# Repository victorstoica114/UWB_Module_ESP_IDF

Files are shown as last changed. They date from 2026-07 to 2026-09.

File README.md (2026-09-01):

# UWB ESP-IDF

ESP-IDF 6.0.2 firmware for the custom UWB Module V1.0 Rev.B, based on an
ESP32-S3-WROOM-1-N16R8. The same application image runs on every module;
persistent identity and runtime configuration select the role and active
workflow on each board.

The current firmware combines DW3000 positioning, PX1105R GNSS/RTK, BNO085
IMU telemetry, BQ25792 charging, MAX77958 USB-C Power Delivery, authenticated
HTTP OTA/configuration, a browser dashboard, and boot-loop/OTA recovery. The
UWB radio runtimes include Native DS-TWR, FlexTDOA, Passive DS-TWR, calibration,
survey, distance-test, and beacon diagnostics.

Current firmware defaults, before an NVS override is loaded:

| Setting | Default |
| --- | --- |
| Runtime | `uwb_ranging` (Native DS-TWR) |
| UWB | enabled |
| BNO085 | disabled; `2 ms` / 500 Hz requested when enabled |
| PX1105R GNSS | disabled |
| BQ25792 monitor | enabled, nominal 1 Hz refresh |
| MAX77958 monitor | enabled, nominal 1 Hz refresh |
| Wi-Fi logs / binary telemetry | enabled |
| Storage | 16 MB flash, dual 4 MB OTA slots, 8 MB octal PSRAM |

Wi-Fi credentials, the OTA token, and optional NTRIP credentials are read from
the Git-ignored `secrets.h`. Copy `secrets.example.h` as the starting template.
Non-secret defaults live in `components/config`; authenticated runtime
overrides are stored in ESP32 NVS.

## Documentation Map

- Hardware, firmware ownership, boot order, and tasks are documented below in
  [Hardware](#hardware) and [Firmware Architecture](#firmware-architecture).
- UWB modes and packet/timing details start at [App Modes](#app-modes) and
  [UWB Ranging Protocol](#uwb-ranging-protocol). Passive DS-TWR and the clean
  FlexTDOA implementation also have dedicated notes in
  [`docs/PASSIVE_DS_TWR.md`](docs/PASSIVE_DS_TWR.md) and
  [`docs/FLEXTDOA_CLEAN_REIMPLEMENTATION.md`](docs/FLEXTDOA_CLEAN_REIMPLEMENTATION.md).
- Operator controls are grouped under [HTTP Control Surface](#http-control-surface),
  [BNO085 IMU](#bno085-imu), [BQ25792 Battery Charger](#bq25792-battery-charger),
  and [MAX77958 USB-C PD Controller](#max77958-usb-c-pd-controller).
- Build, serial flash, OTA, dashboard, and host-test commands are under
  [Local Workflow, Flashing, and VS Code Tasks](#local-workflow-flashing-and-vs-code-tasks).
- Released ESP32 images are on the
  [GitHub Releases page](https://github.com/victorstoica114/UWB_Module_ESP_IDF/releases),
  while the separately versioned GNSS image is indexed in
  [`PX1105R-firmware/README.md`](PX1105R-firmware/README.md).
- Final reports and their retained evidence bundles are indexed in
  [`reports/README.md`](reports/README.md).
- The parametric enclosure sources, print-ready STL files, STEP exports, and
  assembly notes are under
  [`mechanical/uwb-gps-enclosure/`](mechanical/uwb-gps-enclosure/README.md).

## Hardware

This firmware targets the custom UWB Module V1.0 Rev.B hardware.

| Area | Details |
| --- | --- |
| MCU | ESP32-S3-WROOM-1-N16R8 |
| Flash / PSRAM | 16 MB flash, 8 MB PSRAM |
| USB | Native USB CDC on boot |
| UWB | DW3000/DWM3000 radio path |
| IMU | BNO085 over shared I2C |
| GPS | PX1105R/PX1125R-class GPS path |
| USB-C / PD | MAX77958 |
| Charger | BQ25792 |
| Status LED | GPIO42, active-high |

Active pin mapping lives in `components/config/include/board_config.h`.

| Function | GPIO |
| --- | --- |
| Status LED | `42` |
| Shared I2C SDA / SCL | `9` / `10` |
| BNO085 reset / interrupt | `40` / `15` |
| BQ25792 interrupt / QON command / board PG | `4` / `38` / `5` |
| UWB reset / IRQ / CS / wakeup | `8` / `6` / `48` / `7` |
| SPI MOSI / SCK / MISO | `11` / `12` / `13` |
| GPS enable / RX / TX | `47` / `18` / `17` |
| GNSS correction UART TX | `1` |

### DW3000 SPI Clock

The DWM3000 data sheet specifies a maximum SPI clock of `38 MHz` in mode 0
after OTP boot has completed. ESP32-S3 SPI2 is sourced from the `80 MHz` APB
clock and can generate `40 MHz` exactly. This project deliberately selects
that divider after field validation on all five modules. It is a documented
2 MHz overclock, guarded by an explicit compile-time opt-in and a separate
`38 MHz` data-sheet-limit constant so the exception cannot be accidental.

The driver therefore uses two phases:

1. reset, `DEV_ID` probe, soft reset, OTP reads, and radio configuration at
   `4 MHz`;
2. operational RX/TX traffic requested and realized at `40 MHz`, after eight
   consecutive `DEV_ID` read-backs succeed.

If the operational verification fails, the driver automatically restores the
`4 MHz` device configuration so the module remains reachable. `/status`
exposes the effective value as `uwb_spi_clock_hz`; this is the frequency
reported by the ESP-IDF SPI driver, not only the requested value.

Hardware validation on all five modules, updated 2026-08-05:

| Metric | Result |
| --- | ---: |
| Effective SPI clock, every module | `40 MHz` |
| Pure CI-CR validation window | `35 s` |
| Selected slot / four-anchor frame | `4.80 ms / 19.20 ms` |
| Passive observations | `443-450/s` |
| Telemetry drops | `0` |
| Responder-index balance per anchor | typically `37-39 / 37-39 / 37-39` per second |
| Rejected tag observations | typically `0-1/s` |
| Incoherent anchor timestamps in stable windows | `0` |

The radio test exercises TX-buffer writes, delayed-TX programming, timestamp
and status reads, and RX-buffer reads. It is therefore a stronger link check
than probing `DEV_ID` alone.

## Firmware Architecture

`main/app_main.c` only calls `app_manager_start()`. The application manager
initializes identity and runtime configuration, brings up the recovery/control
plane first, and then starts hardware services and exactly one UWB runtime.

| Component | Responsibility |
| --- | --- |
| `app_manager` | Boot sequencing, status LED, recovery cutoff, and active-runtime selection. |
| `config` | Board pins, compile-time defaults, persistent module identity/antenna delay, and NVS runtime configuration. |
| `boot_guard` | ESP-IDF OTA validation plus RTC-memory crash-loop detection and recovery mode. |
| `wifi_service` | STA scan, connection, reconnect, BSSID/channel diagnostics, and network status. |
| `ota_service` | HTTP server, `/status`, OTA, GNSS update staging, and authenticated configuration endpoints. |
| `wireless_log_service` | TCP mirror of ESP-IDF text logs. |
| `wireless_telemetry_service` | Batched `UWT1` binary sensor, geometry, range, and position streams. |
| `resource_monitor_service` | Bounded RAM, PSRAM, flash, temperature, and per-core CPU diagnostics. |
| `i2c_bus_service` | Shared BNO085 realtime/BQ25792/MAX77958 background arbitration and optional SCL measurement. |
| `bno085_service` | Interrupt-driven accelerometer and GyroRV acquisition, timestamp reconstruction, recovery, rings, and telemetry. |
| `charger_service` | BQ25792 monitoring, decoded status/ADC data, controlled writes, and NVS-backed charger policy. |
| `max77958_service` | MAX77958 status, AP commands, optional direct-HS I2C, PDO/PPS control, and NVS-backed PD policy. |
| `gps_service` | PX1105R power/UART control, NMEA/SkyTraq parsing, 8 Hz setup, moving-base transport, and NTRIP. |
| `gnss_firmware_updater` | Fixed PX1105R loader/image update sequence using ESP32 PSRAM staging. |
| `uwb_dw3000` | DW3000 GPIO/SPI/IRQ ownership and all timing-critical UWB runtime loops. |
| `uwb_ranging_service` | Native DS-TWR positioning entry point. |
| `uwb_distance_test_service` | Two-module five-frame diagnostic DS-TWR entry point. |
| `uwb_calibration_service` | Two- and three-module antenna-delay calibration entry point. |
| `uwb_anchor_survey_service` | Anchor-to-anchor survey entry point. |
| `flextdoa_protocol` | FlexTDOA packet codec, collector, and CFO estimator. |
| `flextdoa_algmin` | FlexTDOA frame aggregation and 2D minimization. |
| `flextdoa_solver_service` | Asynchronous embedded FlexTDOA solver and position publication. |
| `passive_ds_solver_service` | Passive DS batching, dynamic geometry, correlated solve, and position publication. |
| `uwb_mobile_geometry` | Converts GNSS anchor positions into a shared local UWB coordinate frame. |
| `uwb_localization_solver` | Generic tested range/range-difference solver library; it is not the owner of a current runtime loop. |

Repository-level supporting material:

| Path | Contents |
| --- | --- |
| `tools/` | Build/OTA helpers, dashboard, listeners, capture, replay, calibration, and analysis tools. |
| `tests/` | Python host tests and standalone C algorithm/protocol tests. |
| `docs/` | Focused protocol and implementation notes. |
| `firmware_images/` | Retained ESP32 release inputs, stored through Git LFS where configured. |
| `PX1105R-firmware/` | Permanent GNSS firmware index and validated ESP32-assisted update artifacts. |
| `reports/` | Final PDFs plus one self-contained evidence bundle for each report. |
| `mechanical/uwb-gps-enclosure/` | Parametric V4 enclosure source, reference geometry, print-ready STL files, STEP exports, and previews. |
| `PCB/V1.REV.B/` | KiCad source, fabrication, BOM, and placement package. |
| `Schematic/` / `datasheets/` | Exported board schematic and local silicon/reference documents. |
| `reference/` | Migration notes and the intentionally retained legacy GPIO header. |

`components/config/include/board_config.h` is the active board pin map.
Old GPIO naming is kept only under `reference/legacy_headers`.
Old legacy project files and cloned third-party repositories are kept local for
inspiration/debugging and are intentionally ignored by Git.

`components/config/include/app_config.h` holds versioned non-secret application
settings: the default runtime mode, persistent identity provisioning, Wi-Fi
diagnostics/reconnect behavior, wireless-log defaults, OTA-adjacent
service defaults, and optional sensor-test parameters. `components/config/include/uwb_config.h`
holds UWB-only settings: role, source ID override, antenna delay, beacon
smoke-test parameters, and runtime defaults. Runtime overrides are stored in
NVS through `/config/runtime`. Keep Wi-Fi credentials and OTA tokens in
`secrets.h`.

Runtime ownership is intentionally narrow:

- `main/app_main.c` only boots the firmware and calls `app_manager_start()`.
- `components/app_manager/app_manager.c` owns what runs on the board and in
  what order.
- Long-lived workflows live in separate services/components, then are selected
  or sequenced by `app_manager`.

The current boot sequence is also explicit. `app_manager` starts the status LED
and boot guard, loads identity/runtime configuration, then brings up Wi-Fi,
wireless logs, binary telemetry, and the HTTP/OTA server. It schedules stable
boot confirmation only after that recovery/control plane is reachable. A normal
boot then starts the resource monitor, optional GNSS, the selected UWB runtime,
BQ25792, MAX77958, and finally the optional BNO085 service. Recovery mode stops
before that second group and holds the DW3000 in reset.

The application task/core split is kept simple so the UWB loop is isolated from
most Wi-Fi and TCP work:

| Task / service | Core | Notes |
| --- | --- | --- |
| `uwb_dw3000` | 1 | Owns DW3000 init, SPI access, RX/TX, ranging, survey, and calibration loops. |
| `status_led` | 1 | Lightweight GPIO blink task. |
| `boot_guard` | unpinned | Confirms stable boots after Wi-Fi/OTA are online and holds recovery state across resets. |
| `wifi_service` | 0 | Owns Wi-Fi STA connect/reconnect management. |
| `ota_service` / `httpd` | 0 | Starts authenticated OTA, `/status`, and runtime-config HTTP handling. |
| `bno085` | 0 | Interrupt-driven BNO085 accelerometer/GyroRV service; owns realtime priority on the shared I2C bus. |
| `bq25792` | 0 | Low-rate charger monitor; uses background I2C access so BNO085 can win bus arbitration. |
| `max77958` | 0 | Low-rate USB-C PD monitor/config service; also uses background I2C access. |
| `gps` | 0 | PX1105R power, UART parsing, and moving-base integration when runtime-enabled. |
| `gps_ntrip` | unpinned | Optional single NTRIP caster connection owned by the configured module. |
| `flex_algmin` | 0 | FlexTDOA solver worker, created only by that runtime. |
| `passive_ds_solver` | 0 | Passive DS solver worker with its large stack allocated from PSRAM. |
| `resource_monitor` | 0 | Low-priority bounded resource sampling. |
| `wireless_log` | unpinned | Drains the log queue and mirrors logs over TCP; FreeRTOS may run it on either core. |
| `wireless_tel` | 1 | Drains high-rate telemetry into batched TCP writes. |
| short-lived reboot tasks | unpinned | Temporary restart helpers after OTA or runtime-config changes that explicitly require a reboot. |

ESP-IDF also creates internal Wi-Fi, TCP/IP, and event-loop tasks. The HTTP
server task is pinned to core 0 so `/status` and runtime config do not share the
UWB core. The timing-critical UWB transmit instants are still programmed into
the DW3000 with delayed TX, so the radio owns the sub-microsecond timing rather
than the FreeRTOS scheduler.

UWB waits are deliberately yielding. RX/TX waits use the DW3000 IRQ line and
FreeRTOS task notifications when IRQ is enabled, with `vTaskDelay` as the
fallback path. Calibration slot alignment uses the dedicated 1 MHz ESP GPTimer
alarm plus a task notification, so the firmware does not busy-loop while waiting
for the guard window or slot end.

## Boot Recovery

The firmware has two recovery layers so a bad OTA or a crash loop should not
make a module disappear from Wi-Fi permanently.

| Layer | What it handles | Mechanism |
| --- | --- | --- |
| ESP-IDF OTA rollback | A new OTA image crashes or resets before it proves it can boot. | `CONFIG_BOOTLOADER_APP_ROLLBACK_ENABLE` marks a fresh OTA image as `pending_verify`. The app calls `esp_ota_mark_app_valid_cancel_rollback()` only after Wi-Fi and OTA HTTP are online for `APP_BOOT_GUARD_STABLE_DELAY_MS`. If a reset happens first, the bootloader rolls back to the previous valid OTA slot. |
| Local recovery mode | A valid app, serial-flashed app, or bad runtime config keeps rebooting. | `components/boot_guard` stores a small state record in RTC no-init memory. After `APP_BOOT_GUARD_FAILURE_THRESHOLD` unstable resets, the next boot starts only identity/runtime config, Wi-Fi, wireless log, telemetry, and OTA. UWB, GPS, charger, USB-C PD, resource monitor, and BNO085 are skipped. |

Normal boot order is intentionally conservative: Wi-Fi, wireless log, telemetry,
and OTA start before UWB or I2C peripherals. Recovery mode uses the same path but
stops before the risky services and holds the DW3000 in reset.

Task watchdog panic is enabled on purpose. A task watchdog, interrupt watchdog,
panic, generic watchdog, or CPU lockup reset is counted as a recovery failure
even if the previous boot had already been marked stable. This catches runtime
configuration lockups that happen minutes or hours after boot instead of only
early boot loops.

`/status` exposes the recovery state:

| Field | Meaning |
| --- | --- |
| `boot_recovery_mode` | `true` when only the minimal recovery services are running. |
| `boot_guard_failure_count` | Consecutive unstable resets counted in RTC memory. |
| `boot_guard_recovery_threshold` | Failure count that latches recovery mode. |
| `boot_guard_ota_state` | Current OTA state, such as `valid` or `pending_verify`. |
| `boot_guard_pending_verify` | The running app still needs to be marked valid. |
| `boot_guard_last_reset_reason_name` | Last reset reason reported by ESP-IDF. |

Recovery can be cleared after uploading a known-good firmware or runtime config:

```sh
curl -X POST -H "X-OTA-Token: <APP_OTA_PASSWORD>" \
  "http://<module-ip>/config/recovery?clear=1&reboot=1"
```

Important: rollback lives in the bootloader. OTA updates replace only the app
partition, so each module needs one full serial flash after enabling rollback.
After that, future OTA images are protected by the rollback flow.

## HTTP Control Surface

The ESP32 exposes one HTTP control plane after Wi-Fi starts. `GET /` and
`GET /status` are intentionally readable without authentication. Every `POST`
endpoint requires the same header used by OTA:

```text
X-OTA-Token: <APP_OTA_PASSWORD>
```

The password comes from the Git-ignored `secrets.h`. Configuration values are
passed as URL query parameters even though the method is `POST`; an empty body
is valid. For example:

```sh
curl -X POST -H "X-OTA-Token: <APP_OTA_PASSWORD>" \
  "http://<module-ip>/config/runtime?bno085=1&bno085_sample_hz=500"
```

| Method and path | Purpose | Persistence / restart behavior |
| --- | --- | --- |
| `GET /` | Short endpoint and usage summary. | Read-only. |
| `GET /status` | JSON snapshot of identity, boot, UWB, GNSS, IMU, charger, PD, resources, logs, and telemetry. | Read-only. |
| `POST /ota` | Upload an ESP-IDF application image to the inactive OTA slot. | Reboots into the new image; NVS is preserved. |
| `POST /gnss/loader` | Stage the validated PX1105R loader artifact in PSRAM. | Volatile staging step. |
| `POST /gnss/firmware` | Stage the validated PX1105R firmware artifact in PSRAM. | Volatile staging step. |
| `POST /gnss/firmware/run` | Run the fixed GNSS loader/update sequence using the staged artifacts. | Reprograms the GNSS receiver, not the ESP32. |
| `POST /config/antenna-delay` | Stage a calibrated DW3000 antenna delay. | Stored in NVS; applied at radio initialization. |
| `POST /config/runtime` | Change runtime, topology, timing, diagnostics, GNSS, UWB, or BNO085 configuration. | Stored in NVS; some fields apply live or by UWB hot switch, others require `reboot=1`. |
| `POST /config/recovery` | Clear the local boot-guard latch and optionally reboot. | Updates boot-guard state. |
| `POST /config/charger` | Refresh or configure the BQ25792. | High-level policy is stored in NVS; raw writes are not. |
| `POST /config/max77958` | Refresh, inspect, or configure MAX77958 USB-C/PD behavior. | Selected high-level policy is stored in NVS; diagnostic operations and raw writes are not. |

Boolean charger/PD parameters accept `1/0`, `true/false`, `on/off`, and
`yes/no`. Runtime booleans accept `1/0`, `true/false`, and `on/off`. Invalid,
out-of-range, incomplete, or unauthenticated requests are rejected; callers
should check both the HTTP status and the JSON response instead of assuming a
write succeeded. The exact BNO085, charger, and PD command tables are in their
respective sections below.

## 3D-Printed Enclosure

The complete modular V4 enclosure is versioned under
[`mechanical/uwb-gps-enclosure/`](mechanical/uwb-gps-enclosure/README.md). It
includes the CadQuery generator, input reference geometry, validation manifest,
assembly STEP model, rendered previews, and eight print-oriented STL parts.

For printing, use the files ending in `_PRINT.stl` from
[`mechanical/uwb-gps-enclosure/exports/`](mechanical/uwb-gps-enclosure/exports/).
The enclosure README documents the required inserts, magnets, screws, print
orientation, and assembly order.

UWB GPS enclosure preview

The binary CAD, mesh, reference-image, and preview assets are stored through
Git LFS. The source was imported from the validated V4 enclosure revision
`7e0be77` of
[`AlexandruPalacean/uwb-gps-enclosure`](https://github.com/AlexandruPalacean/uwb-gps-enclosure).

## PCB Package

The hardware package is versioned with the firmware so the board definition and
software assumptions stay together.

| Path | Purpose |
| --- | --- |
| `PCB/V1.REV.B/Kicad project/` | Editable KiCad project and local symbols/footprints |
| `PCB/V1.REV.B/Gerber/Gerber.zip` | Fabrication archive |
| `PCB/V1.REV.B/BOM/` | BOM exports |
| `PCB/V1.REV.B/PickAndPlace/` | Assembly placement files |
| `Schematic/UWB_V1.0_Rev.B.pdf` | Exported schematic PDF |

PCB preview:

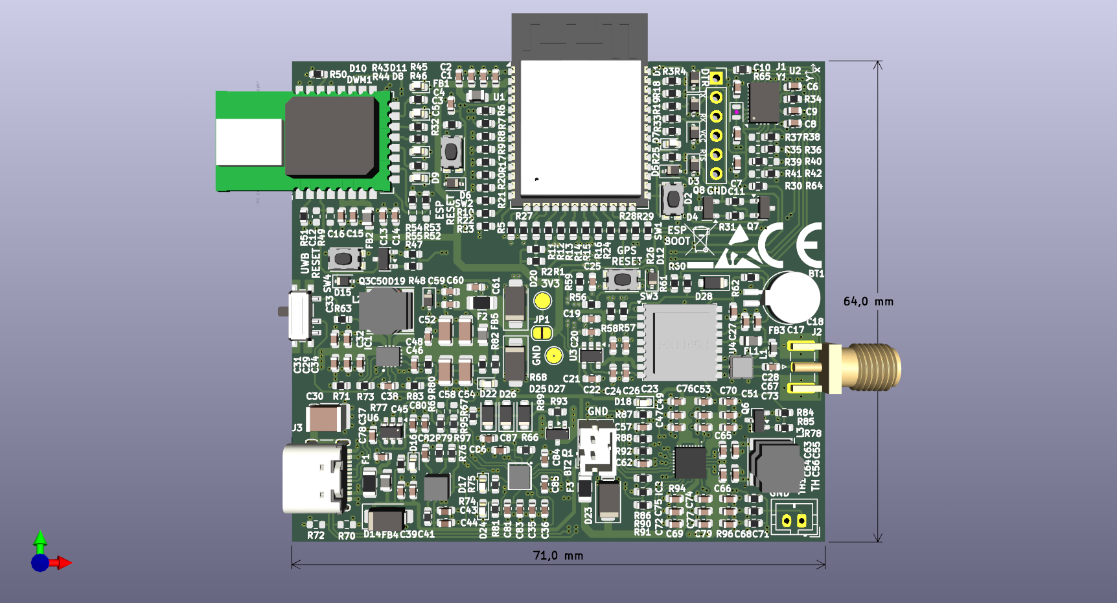
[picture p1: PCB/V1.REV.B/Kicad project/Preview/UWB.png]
UWB PCB Preview


## Released Firmware Images

ESP32 images are published as one GitHub Release per firmware version, ordered
from the oldest retained version to the newest. Each release keeps only the
artifacts needed to install that version; intermediate ESP-IDF build trees are
not release artifacts. The retained source images under `firmware_images/` are
tracked with Git LFS.

The release asset names have distinct purposes:

| Asset | Use |
| --- | --- |
| `uwb_ota.bin` | OTA through `POST /ota` or `tools/ota_upload.py`; preserves NVS. |
| `uwb_full_flash.bin` | Complete serial recovery/provisioning image written at offset `0x0`; may replace NVS and therefore require identity, runtime, and antenna-delay provisioning again. |
| Per-partition `.bin` files, when present | Low-level ESP-IDF/esptool recovery and diagnosis. Use the offsets documented with that release. |

The current retained ESP32 sequence starts at
`firmware-20260804-222730-flextdoa-accuracy` and ends at
`firmware-20260813-190254-native-uwb-only`. Use the
[GitHub Releases page](https://github.com/victorstoica114/UWB_Module_ESP_IDF/releases)
as the canonical download location rather than copying binaries from an old
build directory.

PX1105R firmware is versioned independently so the same GNSS payload is not
duplicated in every ESP32 release. The permanent entry point is
[`PX1105R-firmware/README.md`](PX1105R-firmware/README.md), which links the
dedicated `gps-px1105r-01.07.33` release and records the validated artifacts and
ESP32-assisted update command.

## App Modes

The expected UWB workflow split is:

1. `APP_RUNTIME_MODE_UWB_BEACON_SMOKE`: current random beacon TX/RX smoke test
   in `components/uwb_dw3000`.
2. `APP_RUNTIME_MODE_UWB_ANTENNA_DELAY_CALIBRATION`: antenna delay
   calibration entry point in `components/uwb_calibration_service`.
3. `APP_RUNTIME_MODE_UWB_DISTANCE_TEST`: current two-module DS-TWR ruler check
   entry point in `components/uwb_distance_test_service`.
4. `APP_RUNTIME_MODE_UWB_RANGING`: current 4-anchor plus 1-tag DS-TWR
   ranging runtime in `components/uwb_ranging_service`. The first configured
   anchor coordinates the slots, anchors initiate, and the tag responds/logs
   tag-anchor distances for the dashboard.
5. `APP_RUNTIME_MODE_UWB_ANCHOR_SURVEY`: anchor-to-anchor survey/runtime
   diagnostics in `components/uwb_anchor_survey_service`.
6. `APP_RUNTIME_MODE_UWB_FLEX_TDOA`: experimental FlexTDOA runtime. Anchors
   rotate as short-slot initiators, continuously refresh live anchor geometry,
   and the tag only listens on UWB while sending range-difference observations
   to the dashboard over Wi-Fi logs.
7. `APP_RUNTIME_MODE_UWB_PASSIVE_DS_TWR`: project-specific three-frame
   anchor-to-anchor DS-TWR with receive-only tags. It provides independent
   Fast Star and Robust Rotating schedules; see
   [`docs/PASSIVE_DS_TWR.md`](docs/PASSIVE_DS_TWR.md). The surveyed-square
   calibration data and 1.89 cm offline RMSE result are preserved in
   [`reports/bundles/passive_ds_known_geometry_20260727`](reports/bundles/passive_ds_known_geometry_20260727/README.md).

The beacon smoke mode, distance-test mode, antenna-delay calibration workflows,
anchor survey, multi-anchor ranging, and experimental FlexTDOA runtimes are
implemented for the current lab workflow.

`APP_RUNTIME_MODE` remains the firmware default. The effective runtime mode and
common test parameters can be overridden at runtime through NVS using the
authenticated `/config/runtime` HTTP endpoint.

### Hot Protocol Switching

The Position tab switches directly between Native DS-TWR, FlexTDOA, and Passive
DS-TWR through `/config/runtime?...&hot_switch=1`. A successful hot switch:

- persists the selected mode in NVS;
- lets the active UWB loop leave at a safe protocol boundary;
- stops the active UWB timers and resets the solver state;
- resets and reconfigures only the DW3000; and
- keeps Wi-Fi, HTTP, wireless logs, and binary telemetry running.

The supervisor restores the 4 MHz DW3000 boot SPI rate for the radio reset and
returns to the verified datasheet-compliant operational rate after
initialization. If radio
initialization fails, the firmware falls back to a full ESP32 restart.

Hot switching is deliberately limited to a mode-only transition among these
three positioning runtimes. Changes to module topology, tag/anchor IDs, channel,
radio settings, timing parameters, diagnostics, calibration, or survey modes
still follow the normal reboot path. The `/status` response exposes
`uwb_runtime_switching`, `uwb_runtime_switch_count`, and
`uwb_last_runtime_switch_ms` so the dashboard can distinguish a short radio
transition from an offline module.

The five-module live test on 2026-07-27 produced:

| Transition | HTTP acknowledgement | All modules UWB-ready | First complete live data |
| --- | ---: | ---: | ---: |
| Native DS-TWR -> FlexTDOA | 0.101 s | 0.773 s | 0.784 s |
| FlexTDOA -> Passive DS-TWR | 0.105 s | 0.623 s | 0.932 s |
| Passive DS-TWR -> Native DS-TWR | 0.083 s | 0.764 s | 0.814 s tag ranges; 2.115 s all six anchor pairs |

The measured DW3000 reinitialization time was 449-481 ms. ESP32 boot counters
did not change during any transition.

## UWB Ranging Protocol

The active ranging implementation is based on Double-Sided Two-Way Ranging
(DS-TWR). Position ranging uses exactly the three native UWB frames: `POLL`,
`RESP`, and `FINAL`.

| Frame | Direction | Purpose |
| --- | --- | --- |
| `POLL` | tag -> anchor | 10-byte protocol header that starts one ranging exchange. |
| `RESP` | anchor -> tag | 10-byte protocol header that provides the responder turnaround. |
| `FINAL` | tag -> anchor | 35 bytes: header plus the tag's `POLL TX`, `RESP RX`, and scheduled `FINAL TX` timestamps. |

The anchor combines the timestamps carried in `FINAL` with its own `POLL RX`,
`RESP TX`, and `FINAL RX` hardware timestamps and calculates the distance
locally. It reports the result through Wi-Fi, not through an additional UWB
frame. The separate distance-test and calibration runtimes retain their
five-frame diagnostic exchange for bidirectional verification.

### Runtime Shape

The same firmware image runs on every module. At boot, each board reads its
persistent module ID and runtime config from NVS.

| Module ID | Normal ranging behavior |
| --- | --- |
| `1` | Tag / initiator; ranges each configured anchor in order |
| `2` | Anchor / responder |
| `3` | Anchor / responder |
| `4` | Anchor / responder |
| `5` | Anchor / responder |

`APP_RUNTIME_MODE_UWB_RANGING` is tag-initiated. The tag owns the complete
frame schedule and starts one native DS-TWR exchange in every anchor slot.
There is no coordinator, `RANGING_CMD`, `REPORT`, or `REPORT2`. Each responding
anchor calculates the range after `FINAL` and returns it in a one-shot UWB
`RESULT` packet. The ESP32 tag solves every coherent four-anchor frame and
publishes the range and raw independent-frame position over Wi-Fi. The
dashboard displays that result and the host tools can independently replay it
for RTK comparison; no temporal position filter is applied.

Native DS protocol version 2 protects every packet with CRC-16/CCITT-FALSE.
This application-level CRC also detects payload corruption on the DW3000-to-ESP
SPI path after the radio has already accepted the over-the-air frame check.

The tag schedules anchors sequentially:

```text
round N

tag 1 -> anchor 2
tag 1 -> anchor 3
tag 1 -> anchor 4
tag 1 -> anchor 5

wait ranging_round_gap_ms
round N + 1
...
```

The important timing parameters are exposed by `/status`, can be changed with
`/config/runtime`, and are also available in the dashboard:

| Name | Default / lab value | Meaning |
| --- | ---: | --- |
| `ranging_slot_ms` | `10 ms` | Time budget for one native four-packet exchange. |
| `ranging_round_gap_ms` | `4 ms` | Gap after all anchor slots in one frame. |
| `ranging_rx_slice_ms` | `100 ms` | RX window used by idle anchor responders. |
| `ranging_rx_timeout_ms` | `5 ms` | Maximum wait for the expected `RESP`, `FINAL`, or `RESULT`. |
| `ranging_resp_delay_ms` | `2 ms` | Delayed TX offset from `POLL RX` to `RESP TX`; also used from `FINAL RX` to `RESULT TX`. |
| `ranging_final_delay_ms` | `2 ms` | Delayed TX offset from `RESP RX` to `FINAL TX`. |
| `ranging_auto_rx_delay_uus` | `500 UUS` | DW3000 hardware delay before auto-RX opens after TX. |

These values have their own NVS keys and dashboard profiles. Changing them does
not modify FlexTDOA, distance-test, calibration, or anchor-survey timing. The
tag uses a high-resolution host timer for slot and frame-gap boundaries, so
profiles are not rounded to the 10 ms FreeRTOS tick. Native DS-TWR timing is
copied when its UWB task starts. Timing-only changes can request an in-place
UWB hot switch, which cleanly restarts the radio runtime while Wi-Fi, GPS and
the ESP32 stay online. For four anchors, the default frame is
`4 * 10 + 4 = 44 ms`.

The selected field profile is a 10 ms slot, 4 ms frame gap, 100 ms idle-anchor
RX slice, 5 ms expected-frame timeout, and 2 ms for each delayed transmission.
In a 180-second channel-9 run it completed 15,138 of 15,183 exchanges
(`99.704%`), produced 20.82 raw positions/s, and measured 1.80 cm RMSE and
3.07 cm P95 against stabilized RTK, without position filtering. A 42 ms frame
raised throughput to 21.45 positions/s but reduced completion to 99.357%; a
43 ms frame reached 21.12 positions/s at 99.491%. The 44 ms profile is the
recommended robustness/throughput tradeoff. The 64 ms and 100 ms profiles
remain available as intermediate and conservative fallbacks.

### FlexTDOA Runtime

`APP_RUNTIME_MODE_UWB_FLEX_TDOA` is the active pure CI-CR radio protocol with a
radio-passive tag.
The tag does not call any UWB TX function in this mode. It only receives anchor
frames, records its own RX timestamps, feeds the local AlgMin solver, and sends
compact binary range-difference and position telemetry to the dashboard.

FlexTDOA roles are derived from the configured anchor list. Every module in
that list is an anchor; every participating module outside it is a passive tag
and labels telemetry with its own module ID. This permits multiple passive tags
without adding radio slots. An ID must never appear in both `Anchor IDs` and
`Tag IDs`; the dashboard rejects that configuration. For example, with five
modules, anchors `2,3,4` can be combined with tags `1,5`.

The current firmware is aligned with the FlexTDOA paper at the radio slot level:
one anchor is the initiator in a slot, it broadcasts one request, and `K`
responders answer in ordered response subslots. With four configured anchors,
`K = 3` and a full frame has four initiator slots. The tag remains passive and
derives range-difference observations only from the packets it hears.

With anchors `2,3,4,5`, the changing-initiator/changing-responder schedule is:

```text
round 0
  slot 0: A2 requests, responders A3,A4,A5
  slot 1: A3 requests, responders A4,A5,A2
  slot 2: A4 requests, responders A5,A2,A3
  slot 3: A5 requests, responders A2,A3,A4

round 1
  slot 0: A2 requests, responders A4,A5,A3
  slot 1: A3 requests, responders A5,A2,A4
  slot 2: A4 requests, responders A2,A3,A5
  slot 3: A5 requests, responders A3,A4,A2
```

The responder list rotates from the absolute 32-bit slot ID, `slot_id % K`.
Consequently both the initiator and the first responder change at every slot,
including between adjacent slots in the same frame. This implements the
paper's CI-CR scheme without holding one response order for an entire frame.

The active FlexTDOA frame set is:

| Frame | Direction | Purpose |
| --- | --- | --- |
| `FLEX_TDOA_REQ` | initiator -> broadcast | Paper request. Carries the 32-bit slot ID, responder count/order, zero processing delay, and one previous TWR result from this initiator. |
| `FLEX_TDOA_RESP` | responder -> broadcast | Paper response. Carries the same slot ID, measured reply delay, and one previous TWR result from this responder. Initiator and responder index are reconstructed from CI-CR plus the source ID. |

Both packet types use the common Figure 3 tail: processing time, previous TWR
responder ID, previous TWR distance, and previous measurement slot. The local
transport header already carries message type, source ID, and sequence, while
the destination list remains variable-length. Every anchor cycles through its
own directed TWR cache so a repeatedly refreshed pair cannot starve the other
pairs. The parser temporarily accepts the older local request/response layout
to keep a parallel OTA rollout operational.

There is no separate coordinator command in the active protocol. After two
seconds of radio silence, the first configured anchor bootstraps slot `0`.
Every anchor reconstructs the TDMA phase from valid request packets. Responses
carry the full 32-bit slot ID and can recover a follower that missed the
request; a directly received request remains the authoritative phase reference
for that slot. Each node schedules only its own next initiator slot, and later
requests continually correct local clock drift.

The topology is represented by the same `N/K/M` parameters used in the paper:

| Field | Meaning | Firmware range |
| --- | --- | --- |
| `N` | Ordered anchor ID list. | `3..10` anchors |
| `K` | Number of responders selected for each request. | `1..N-1` |
| `M` | Number of initiator slots in the repeating frame. | `1..10` slots |
| responder mask | Anchors allowed to respond in one slot; CI-CR rotates the selected `K` through this pool. | one `N`-bit mask per slot |

These values are editable under `UWB Settings > FlexTDOA Network`. Applying a
new topology increments a 32-bit configuration generation and stores it in NVS.
During the three-second startup configuration phase, anchors, the tag, and a
node removed from the new topology can all broadcast their versioned config.
Nodes accept only a newer generation, persist it, and restart their local UWB
state. While the network is running, reception of a newer config causes the
same controlled rebuild. This is the distributed propagation and recovery
path; normal slot synchronization still comes from `REQ/RESP`, not from a
separate periodic synchronization packet.

The versioned fixed-geometry transport remains for backward compatibility with
older captures and deployments. The current positioning workflow clears that
legacy state and does not freeze coordinates: live anchor ranges continuously
drive the embedded and dashboard geometry solvers.

#### FlexTDOA Slot Timing

The CI-CR slot keeps the structure of equation (20) from the paper. Its timing
terms are runtime parameters persisted in NVS and propagated over UWB, so each
tested combination is kept as a named frame-length profile in the dashboard:

```text
t_slot = guard + request_subslot + request_process
       + K * response_subslot
       + K * response_process_per_responder
```

For four anchors, `K = 3`, the dashboard exposes the two field-validated
profiles plus the exact equation (20) paper reference:

| Profile | Guard | REQ | Process REQ | 3 x RESP | 3 x Process RESP | Slot | Frame | Frame rate |
| --- | ---: | ---: | ---: | ---: | ---: | ---: | ---: | ---: |
| `32.20 ms Field Fast` | `250 us` | `2000 us` | `250 us` | `2550 us` | `3000 us` | `8.050 ms` | `32.200 ms` | `31.06 Hz` |
| `34.00 ms Field Stable` | `250 us` | `2000 us` | `250 us` | `3000 us` | `3000 us` | `8.500 ms` | `34.000 ms` | `29.41 Hz` |
| `20.20 ms Paper Reference` | `250 us` | `2000 us` | `250 us` | `750 us` | `1800 us` | `5.050 ms` | `20.200 ms` | `49.50 Hz` |

`32.20 ms Field Fast` is the firmware default. A clean 120 s channel-9 run on
all five deployed modules produced `30.02` independent positions/s, `2.924%`
effective slot loss, zero new delayed-TX errors, `2.03 cm` RMSE and `3.58 cm`
P95 against the static RTK reference, with no position filter. The
`34.00 ms Field Stable` profile remains available as the conservative control.
The paper reference is kept exact for protocol comparison, but its `250 us`
response spacing does not provide enough margin for the complete ESP32-S3
field workload.

For the selected field profile, one slot is:

```text
250 + 2000 + 250 + 3*850 + 3*1000 = 8050 us
```

The selected responder transmits using DW3000 delayed TX from the request RX
timestamp. For the selected field profile:

```text
RESP[0] = REQ_RX + 2250 us
RESP[1] = REQ_RX + 3100 us
RESP[2] = REQ_RX + 3950 us

four-anchor frame = 4 * 8050 us = 32.20 ms
frame rate        = 31.06 frames/s theoretical
measured rate     = 30.02 complete positions/s
```

The responder does not read `SYS_TIME` to turn that relative delay into an
absolute radio timestamp. It combines the already-read request RX timestamp
with the relative delay, writes that target to `DX_TIME`, and issues the native
DW3000 `CMD_DTX` fast command. The reply interval
carried in `FLEX_TDOA_RESP` is derived from the same quantized delayed-TX target,
including TX antenna delay, so the tag subtracts the interval that the radio
actually used rather than an ideal host-side delay.

FlexTDOA RX timestamps also avoid a per-frame `SYS_TIME` reference. The DW3000
double-buffer diagnostic set exposes the low 32 bits of `RX_TIME` reliably, and
adjacent FlexTDOA packets are much closer than the approximately `67 ms` wrap
period of those 32 bits. Firmware therefore extends each low word from the
previous RX timestamp by signed continuity. A hardware diagnostic run found
that the nominal fifth timestamp byte in the buffered metadata was occasionally
incoherent (`21` mismatches in about `18,975` comparisons on M1), so trusting
that byte directly would be less robust than continuity.

One `SYS_TIME` read seeds the 40-bit epoch when the first FlexTDOA packet is
received. A new seed is used only as a recovery action after more than `30 ms`
without a received packet, where low-word continuity would become ambiguous.
There is no periodic or per-frame `SYS_TIME` read in the continuous FlexTDOA
path. Full `SYS_TIME` reads remain in generic DS-TWR timestamp reconstruction
and delayed-TX failure diagnostics; they are not part of the normal FlexTDOA
slot.

The request RX timestamp marks the radio timing reference near the beginning of
the received frame. The field profile reserves a `2000 us` request subslot and
a `250 us` request-processing term before the first response. Together they
cover packet airtime, SPI decode, RX double-buffer release, and delayed-TX
arming. `K * response_process` is the paper's
aggregate response-processing budget, not extra spacing between responses.
The configured quiet guard ends the slot before the next request.

For a slot where `A3` is the initiator:

```text
A3 initiator                  A4/A5/A2 responders             passive tag
 t=0.00 ms  REQ ------------------------>|------------------------> RX REQ
 t=2.25 ms  <---------------- RESP[0] A4 |------------------------> RX RESP
 t=3.10 ms  <---------------- RESP[1] A5 |------------------------> RX RESP
 t=3.95 ms  <---------------- RESP[2] A2 |------------------------> RX RESP
 t=8.05 ms  next initiator request ------|------------------------> next slot
```

The ESP task wakes before its own next request and programs delayed TX. This
preparation lead is local only and adds no airtime. A longer `5000 us` lead was
rejected in hardware tests because it stopped reception before the preceding
slot completed. Delayed responses use the processing budget selected by the
active profile; a rejected or late command is reported explicitly instead of
leaking into the next slot.

The passive tag computes the paper TDOA observation:

```text
diff_dtu = (RESP_RX_tag - REQ_RX_tag)
         - responder_reply_dtu_corrected
         - anchor_anchor_tof_dtu
```

`responder_reply_dtu_corrected` uses the instantaneous DW3000
carrier-integrator clock ratio from that response. `anchor_anchor_tof_dtu`
comes from the cached
anchor-anchor distance learned from the Figure 3 piggyback stream. The latest
directed measurement of either orientation is used until the pair has a newer
value.

No median, moving average, or position filter is applied to the passive tag's
FlexTDOA observations in firmware. Firmware only rejects structurally invalid
observations: mismatched `slot_id`/responder index, missing CIA clock data, or
an RX timestamp outside the current slot. Position solving and any future
estimator are deliberately kept outside this radio validation.

#### FlexTDOA Alignment Audit

| Paper requirement | Firmware state |
| --- | --- |
| Passive DL-TDOA tag | Implemented. The tag only receives `FLEX_TDOA_REQ/RESP`. |
| One request and `K` responses per slot | Implemented. The exact paper profile uses `250 us` response spacing; the field default uses the validated `850 us` response spacing with `2000 us` REQ, `250 us` request processing, `1000 us` response processing, and `250 us` guard terms. |
| Request carries responder count/list/order | Implemented in `FLEX_TDOA_REQ`. |
| Every localization packet carries 32-bit slot ID | Implemented in every request and response. This avoids the 256-slot wrap ambiguity of an 8-bit counter. |
| CI-CR schedule | Implemented by rotating initiator and responder order every slot/round. |
| CFO-based reply delay correction | Implemented from buffered `CIA_DIAG_0`, with the Qorvo sign convention and no clock Kalman filter. |
| Anchor self-localization payload | Implemented. Each request and response carries one previous directed SS-TWR+CFO result using the Figure 3 fields. |
| Fully distributed slot synchronization | Implemented from request RX timestamps. A response can recover a node that missed the request, but a directly received request is authoritative for that slot. |
| General `N/K/M` topology | Implemented for `3..10` anchors, configurable responder count, initiator slots, and per-slot responder masks. |
| Configuration propagation | Implemented as versioned UWB frames. Topology is persisted and rebroadcast during startup; the legacy fixed-geometry generation is cleared for live positioning. |
| Local solver | Implemented on the tag ESP32-S3. It continuously reconstructs relative geometry from fresh anchor TWR ranges. Raw TDOA observations feed a damped 2D least-squares AlgMin service on core 0; UWB remains on core 1. |
| Radio setup | The field deployment uses CH9 and the validated PHY2 profile. CH5, 6.8 Mb/s, PRF 64 MHz, preamble 128 remains the paper-reference setup. |
| Firmware-side measurement filters | None. The radio path emits every structurally valid raw anchor range and tag range difference. |

The local solver is the planar specialization needed by the present hardware
layout. The paper evaluates 3D AlgMin and AlgEKF as well. Therefore the radio
protocol and AlgMin objective are aligned, but the current embedded solver is
not a general 3D replacement for every solver variant in the paper.

The paper's node uses an STM32F429ZIT6: Cortex-M4 with FPU at `168 MHz`, `2 MB`
Flash, and `256 KB` SRAM. That MCU has excellent deterministic interrupt
latency, but it is not more powerful overall than this dual-core ESP32-S3 at
`240 MHz` with external PSRAM. The practical difference is workload isolation:
Wi-Fi and HTTP share the ESP32-S3, so the timing-critical UWB path is pinned to
core 1 and the local solver runs on core 0.

The local solver removes the PC/network round trip from the positioning path;
it does not shorten radio airtime. With `M=4`, one solution can be published
after every `32.20 ms` complete field frame. The validated deployment produced
`30.02` independent solutions/s.
The dashboard prefers this `ESP32 AlgMin` result while it is fresh and falls
back to its PC solver only when local position telemetry is unavailable.

#### FlexTDOA Embedded Solver Optimization

The iterative position solve follows the first-order Taylor linearization and
least-squares refinement described in the local
`datasheets/GPS-Compendium_Book_(GPS-X-02007).pdf`, sections 6.2.2-6.2.4.
The previous valid position is the normal warm start; the anchor centroid is
retained as a recovery candidate. The GPS compendium notes that a good initial
estimate normally converges in roughly three to five iterations. On the live
FlexTDOA stream, the embedded solver needed only `2.09` iterations on average,
while retaining the six-iteration ceiling for recovery from a poor initial
estimate.

The ESP32-S3 position hot path now builds one compact set of fresh TDOA
observations per solution and uses hardware-accelerated single-precision math.
It no longer scans the complete observation matrix for every cost evaluation.
The least-squares objective, centroid comparison, Levenberg-style damping,
step bound, line search, convergence threshold, and reported uncertainty are
unchanged. Anchor self-localization remains double precision and is measured
separately.

Static hardware measurements on M1, with four live anchors and the same raw
FlexTDOA stream, gave:

| Metric | Original solver | Optimized solver |
| --- | ---: | ---: |
| Solutions per second | `68.0` | `67.9` |
| Average position solve | `5.88 ms` | `0.89 ms` |
| Average AlgMin iterations | not instrumented | `2.09` |
| Average cost evaluations | not instrumented | `9.66` |
| Solver queue depth, sampled each second | `16.4` average | `5.9` average |
| Solver queue maximum in the test | `94` | `53` |
| Queue drops in the final `90 s` run | present | `0` |
| M1 core 0 load | approximately `67%` | approximately `41.5%` |

The optimized and original 15-second stationary captures remained comparable:
position standard deviation changed from `4.47/3.18 cm` on X/Y to
`4.23/3.18 cm`, and RMS residual changed from `9.65 cm` to `10.16 cm`.
Those differences are within the changing live radio observations and do not
indicate added filtering; every structurally valid raw observation still feeds
the solver. Measured wall-time maxima include preemption by Wi-Fi and other
core-0 work, so they are diagnostic scheduling latency rather than the normal
AlgMin compute time.

#### Live Position Dashboard Throughput

Local position telemetry has a dedicated Server-Sent Events endpoint. The
dashboard records every received position immediately and schedules the newest
one for the next browser animation frame. The heavier status, geometry, and
diagnostic tables remain on the `250 ms` snapshot poll. This separates radio
and solver throughput from browser repaint rate: an `83.33 Hz` position stream
can be received completely on a display that can draw only about `60 fps`.

A two-minute hardware run with all five modules and the `12.00 ms Frame`
profile measured:

| Metric | Result |
| --- | ---: |
| Nominal local solution rate | `83.33/s` |
| Positions received by the SSE server | `9,971` |
| Measured SSE rate | `83.333/s` |
| Unique position event IDs | `9,971` |
| Browser rate, headless 60 Hz display | `83 rx/s`, approximately `55 fps` |
| Median server delivery age | `1.67 ms` |
| Telemetry drops | `0` on all five modules |
| Anchor transmissions | `160,170` |
| Anchor TX errors | `9` (`0.0056%`) |
| M1 telemetry queue high-water mark | `1,024/1,024`, without drops |
| M1 peak core load during the run | core 0 `63.2%`, core 1 `85.2%` |

The exact average output rate proves that the optimized solver and dashboard
can sustain the `83.33 Hz` experiment. Rare delayed-TX rejects, one long
delivery interval, and the full M1 telemetry queue also confirm that this is a
limit test with little scheduling reserve. The `14.80 ms Frame` profile remains
the robust default until the shorter timing receives a longer clean run.

HTTP status polling is performed concurrently for all modules. A single failed
poll marks the last status as degraded but does not immediately hide a live
position; the module becomes offline only after its last successful status has
aged out. High-rate accelerometer samples are fetched and decoded by the
browser only while the `Graphs` tab is visible, while the server continues to
receive and buffer them.

A coexistence check with the `14.80 ms Frame` profile and all five BNO085
sensors at `500 Hz` saturated M1's telemetry queue and added `1,522` drops in
one minute. After disabling the accelerometers without rebooting, the queue
drained and the drop counter remained unchanged for the following `30 s`.
Maximum-rate FlexTDOA measurements should therefore keep BNO085 disabled;
running both at maximum rate remains a separate telemetry coexistence stress
case.

#### FlexTDOA 5.05 ms Baseline Hardware Validation

Before compacting the request and guard budgets, the complete implementation
was exercised on five physical modules: four
anchors and one radio-passive tag. The final image ran for more than three
minutes with all nodes HTTP-online, no watchdog reset, no panic, and no queue
drop. One isolated late slot was reported and the affected anchor recovered
from subsequent radio traffic without restarting the network.

| Metric | Measured | Theoretical / interpretation |
| --- | ---: | --- |
| Slot duration | `5.05 ms` | Equation (20) timing used by this baseline test. |
| Frame duration | `20.20 ms` | Four initiator slots. |
| Anchor results | usually `141-148/s` per anchor | Maximum `148.5/s` from three responses in each own slot. |
| Passive-tag observations | usually `470-525/s` | Maximum `594.1/s`; the remaining loss is in the very tight `250 us` receive train. |
| RX double-buffer release | usually `198-216 us` maximum per one-second summary | Fits inside one response subslot, with limited margin. |
| Local position | one result per complete frame | Approximately `49.5` AlgMin solutions/s. |
| Tag CPU load | about `48%` on core 0 and `48%` on core 1 | Solver on core 0, UWB receive path on core 1. |
| Anchor CPU load | about `5-8%` on core 0 and `23-24%` on core 1 | No local tag-position solve. |

The DW3000 does not support `RXAUTR` together with receive double buffering.
The fast path therefore issues `CMD_RX` immediately after a good frame, before
copying the occupied buffer. It releases that buffer by clearing only its RDB
status and RX-good `SYS_STATUS` events, then issuing `CMD_DB_TOGGLE`. It does
not use global `CMD_CLR_IRQS`, which can erase unrelated TX state. Expected PHY
errors are accumulated into the one-second summary instead of synchronously
formatting UART warnings from the timing-critical UWB task.

Recovery was also tested by rebooting only M4. Its boot counter advanced once,
it restored generation `3` (`N=4`, `K=3`, `M=4`) from NVS, learned the current
TDMA phase from live FlexTDOA traffic, and resumed increasing TX/RX counters.
The other four nodes were not restarted.

#### FlexTDOA 14.80 ms Compact Profile Trial

On 2026-07-22, the compact profile was applied to all five physical modules and
persisted as runtime configuration generation `6`. Every module restored the
same five timing values after the requested reboot:

```text
guard=250 us, REQ=250 us, process REQ=1250 us,
RESP=250 us, process RESP=400 us per responder
```

For `N=4`, `K=3`, and `M=4`, this produces a `3.700 ms` slot, a `14.800 ms`
frame, `67.57` frames/s, and `810.8` scheduled responses/s. A monotonic-counter
window taken after boot stabilization produced:

| Metric | 60 s result |
| --- | ---: |
| Anchor TX count | `16,343-16,352` per module |
| TX errors | `0` on all five modules |
| RX error ratio | `0.13-0.26%` |
| Protocol queue drops | `0` |
| Incoherent anchor observations | `0` |
| Measured REQ processing path maximum | below `460 us` |

This is a successful compact-profile trial, not yet a replacement for the
longer `150 s` validation of the conservative profile. Longer runs and dynamic
tag tests should be added under the same frame-length profile name so timing
results remain directly comparable.

#### FlexTDOA Timing-Limit Search

The profiles below were exercised consecutively on all five physical modules
on 2026-07-22. Each short profile was observed for `30 s`; the restored
`14.80 ms` profile received a separate clean `60 s` steady-state window after
the simultaneous reboot and network resynchronization had settled.

| Frame | Slot | Frame rate | Response rate | Hardware result |
| ---: | ---: | ---: | ---: | --- |
| `14.80 ms` | `3.70 ms` | `67.57 Hz` | `810.8/s` | Recommended: `0` TX errors in the clean `60 s` window. |
| `14.20 ms` | `3.55 ms` | `70.42 Hz` | `845.1/s` | Borderline: `1` delayed-TX reject and resynchronization in `30 s`. |
| `13.60 ms` | `3.40 ms` | `73.53 Hz` | `882.4/s` | Borderline: `1` delayed-TX reject and resynchronization in `30 s`. |
| `12.60 ms` | `3.15 ms` | `79.37 Hz` | `952.4/s` | Failed: `2` delayed-TX rejects and resynchronizations in `30 s`. |
| `12.00 ms` | `3.00 ms` | `83.33 Hz` | `1000.0/s` | Failed: `3` TX failures in `30 s`. |

The instrumentation separates delayed-TX register programming from the full
radio path. Request arming normally peaked at approximately `90-153 us`, while
the observed response hot path remained below approximately `480 us`. Those
averages and ordinary maxima do not define the safe timing margin: the failed
profiles expose rare millisecond-scale task and radio-state stalls.

An ESP timer ISR dispatch experiment reduced some late request scheduling, but
it could wake the same UWB task while that task was waiting for a response TX
event and introduced occasional response-path failures. It was rejected. The
firmware was restored to the original task-dispatched timer and fixed
`1750 us` request preparation lead before the final clean `14.80 ms` run.

#### FlexTDOA Speed Notes

The runtime is limited by worst-case host/radio turnaround rather than the
`6.8 Mbps` UWB PHY. DW3000 SPI requests and runs at the field-validated
`40 MHz` ESP32-S3 divider. This intentionally exceeds the data-sheet limit of
`38 MHz`, as documented in the hardware section above. The hot
path uses polling SPI, compact payload/metadata reads, targeted RX status
clears plus `DB_TOGGLE`, cached `TX_FCTRL`, early request-buffer release, and
DW3000 delayed TX.

```text
validated ESP32-S3 slot, K=3 = 4.80 ms
four-anchor frame            = 19.20 ms
theoretical frame rate       = 52.08/s
theoretical response rate    = 625.00/s
```

The measured REQ-to-`CMD_DTX` software path is normally about `230-250 us`
and stayed below `500 us` in the final run. That is not itself a safe protocol
budget: the DW3000 also needs a valid radio state and enough future lead when
the delayed command is accepted. Hardware tests established the following
margin boundary:

| REQ processing budget | RX release / delayed-TX order | Hardware result |
| ---: | --- | --- |
| `500 us` | release before `CMD_DTX` | Repeated delayed-TX rejects and timeouts. |
| `500 us` | `CMD_DTX` before release | Faster measured host path, but `DB_TOGGLE` could cancel the pending delayed TX and responder counts became unbalanced. Rejected. |
| `600-650 us` | release before `CMD_DTX` | Intermittent failures remained. |
| `750 us` | release before `CMD_DTX` | Rare missed TX/state errors remained during longer runs. |
| `1500 us` | release before `CMD_DTX` | Validated: `150 s` steady operation with no delayed-TX timeout/reject/state error, no missed slot, no response failure, and balanced `52/52/52` responder counts per anchor summary. |

The safe order is therefore fixed: release the processed RX double buffer
before arming delayed TX. A one-time cluster can still appear about `31 s`
after a newly installed image boots, when the boot guard validates the OTA
image and writes flash. The subsequent steady-state radio test was clean; that
flash-write disturbance is separate from the FlexTDOA timing margin.

The following table is a historical optimization record from 2026-07-18. Its
rows precede the final exact-paper timing and used the moved module layout. It
must not be read as the current configuration or as a geometry/accuracy test.

| request process | response subslot | tag valid/s | anchor results/s/module | responder-index balance | result |
| ---: | ---: | ---: | ---: | --- | --- |
| `1000 us` | `250 us` | `407-446` | `128-131` | nearly balanced | About `70-105/s` tag timestamps were outside the slot. |
| `1000 us` | `300 us` | `491-497` | `111-117` | middle index low | Tag improved, but initiators still lost middle-buffer timestamps. |
| `1500 us` | `300 us` | `452-458` | `106-112` | middle index low | More TX margin did not repair the double-buffer boundary. |
| `1500 us` | `350 us` | `443-450` | `113-114` | typically `37-39` per index | Initial selected run before removing synchronous UART work from the radio task. |
| `1500 us` | `350 us` | `451-456`, avg `454.1` | avg `113.8-114.0` | normally `38,38,38` | Final relative-radio path over `41 s`: zero drops, delayed-TX misses, response failures, and TX-interval mismatches. |

The selected historical `1500/350 us` rate was within `0.1%` of its
`454.55/s` theoretical tag rate. Across that `41 s` window, the tag rejected `14` of roughly `18,600`
observations (`0.08%`) and anchors marked `5` of roughly `18,700` results
incoherent (`0.03%`); all telemetry drop counters remained zero. The one-second
diagnostic summaries are submitted directly to the wireless log queue. They do
not pass through synchronous UART formatting in the timing-critical UWB task,
which previously created a delayed-TX miss approximately once per second.

Historical slot-order scenarios:

| Scenario | Directed slot order | Pair reverse separation | Full directed cycle | Read |
| --- | --- | ---: | ---: | --- |
| Previous round-reverse | `2->3, 2->4, 2->5, 3->4, 3->5, 4->5`, then all reversed next round | `6 * slot + gap` | `12 * slot + 2 * gap` | Good for sweeping all pairs, but each paired TDOA observation mixes directions separated by most of a round. |
| DS-TWR adjacent pair round-trip | `2->3, 3->2, 2->4, 4->2, ...` | `1 * slot` | `12 * slot + gap` | Previous practical hybrid: stable anchor geometry, slower tag updates. |
| Paper-style FlexTDOA | one request, `K` responders in subslots | within one frame | `N * slot + gap` | Current FlexTDOA runtime. Faster and matches the paper's CI-CR slot model. |

Legacy hybrid static speed test, 2026-07-16:

The modules were in the temporary charging-room geometry, so this test should be
read as a timing/robustness run, not as an absolute-location accuracy run. The
tag was left static and the dashboard log stream was sampled after each profile
change. This table belongs to the previous DS-TWR-based hybrid, not to the
paper-aligned FlexTDOA runtime above. `obs Hz` counts passive tag observations,
`observed cycle` is inferred from those observations for a 12-directed-slot
four-anchor cycle, `fresh pairs` is the number of paired TDOA observations
available to the solver at the end of the run, and `rev p90` is the 90th
percentile of `abs(Ai->Aj + Aj->Ai)`.

| Profile | slot | command | RESP | FINAL | REPORT | timeout | run | fail | fresh pairs | obs Hz | observed cycle | rev p90 | anchor std med | Read |
| --- | ---: | ---: | ---: | ---: | ---: | ---: | ---: | ---: | ---: | ---: | ---: | ---: | ---: | --- |
| Stable baseline | `100 ms` | `10 ms` | `20 ms` | `20 ms` | `10 ms` | `90 ms` | `30 s` | `0` | `5/6` | `8.06` | `1.49 s` | `96.0 cm` | `0.55 cm` | Robust, but slower and missed one fresh pair in this geometry. |
| Safe Fast preset | `60 ms` | `5 ms` | `15 ms` | `15 ms` | `5 ms` | `35 ms` | `30 s` | `36` | `1/6` | `8.36` | `1.44 s` | `32.2 cm` | `0.46 cm` | Too short; mostly `RESP wait failed`. |
| Balanced preset | `50 ms` | `5 ms` | `10 ms` | `10 ms` | `5 ms` | `25 ms` | `30 s` | `63` | `1/6` | `9.79` | `1.23 s` | `35.2 cm` | `0.83 cm` | Faster observations, but not robust. |
| Aggressive preset | `40 ms` | `3 ms` | `7 ms` | `7 ms` | `3 ms` | `18 ms` | `30 s` | `142` | `2/6` | `10.89` | `1.10 s` | `45.2 cm` | `0.54 cm` | Beyond the current reliable DS-TWR limit. |
| Reduced-delay 90 | `90 ms` | `5 ms` | `15 ms` | `15 ms` | `5 ms` | `80 ms` | `60 s` | `0` | `6/6` | `9.10` | `1.32 s` | `64.9 cm` | `0.68 cm` | Best fast candidate in this run. |
| Reduced-delay 100 | `100 ms` | `5 ms` | `15 ms` | `15 ms` | `5 ms` | `90 ms` | `60 s` | `0` | `6/6` | `8.87` | `1.35 s` | `102.3 cm` | `0.71 cm` | Safest current operational profile; similar speed to 90 ms with more slot margin. |

The main conclusion from that older branch was that full DS-TWR slots were
robust but expensive. That pushed the current branch toward the paper-style
FlexTDOA slot above: one request, ordered response subslots, and a passive tag
that does not need the full `POLL/RESP/FINAL/REPORT/REPORT2` exchange.

#### FlexTDOA Robustness Improvements

Every localization packet carries the full 32-bit slot counter. The counter is
part of the deterministic initiator/responder ordering used by every anchor.
An earlier experiment carried only the low byte; after 256 slots that could
make a recovering follower infer a different response order. Keeping all 32
bits is cheap and removes that long-run ambiguity.

The dashboard consumes tag observations coherently by slot ID instead of mixing
fresh-looking rows from unrelated slots. Anchor ranges also carry the full
32-bit slot ID. The dashboard groups all pair ranges from one complete TDMA
frame and performs one multi-range EKF update, matching the paper's anchor
self-localization procedure.

The anchor EKF uses the paper's published covariance values:

```text
anchor model variance      sigma_Q^2 = 1 cm^2
TWR measurement variance  sigma_R^2 = 10 cm^2
```

The dashboard treats the resulting covariance and the geometric fit as two
different quantities. A small EKF covariance does not prove that the nonlinear
solver selected the correct geometric minimum. The RMS error between the EKF
coordinates and the current complete TWR frame is compared with three
measurement standard deviations:

```text
fit reference = 3 * sqrt(10 cm^2) = 9.49 cm RMS
```

This is a solver diagnostic, not a filter applied to the raw FlexTDOA or TWR
observations. Positioning no longer waits for an operator to freeze geometry.
The EKF keeps updating while the protocol runs. Three newly updated geometry
batches above `25 cm` RMS trigger an automatic geometric reinitialization, so a
physically relocated anchor is acquired instead of being treated as a
permanent residual. `Reset Live Geometry Estimate` remains available for a
manual recovery and also clears any legacy fixed generation from the modules.

For the current planar setup, the paper's coordinate convention is adapted to
2D: the first selected anchor is fixed at `(0,0)`, the second is on the positive
Y axis, and the third has positive X. This removes the unobservable global
translation, rotation, and mirror ambiguity while allowing every relative
anchor coordinate to change continuously. Geometry sessions are kept separate
per radio protocol so protocol-specific range bias is not mixed when the
operator switches solvers. There is no median window or automatic freeze in
this path.

Each new least-squares tag solve is seeded from the previous valid tag position,
as described for AlgMin in the paper. This selects the same physical solution
branch but does not average or smooth tag measurements.

The initiator also refreshes live anchor geometry from the request/response
exchange in the same slot. This is the short TWR measurement described by the
paper as anchor self-localization payload, not the older full DS-TWR
`POLL/RESP/FINAL/REPORT/REPORT2` sequence:

```text
round = RESP_RX_initiator - REQ_TX_initiator
reply = RESP_TX_responder - REQ_RX_responder

tof = (round - reply_corrected) / 2

anchor_distance = c * tof
```

That distance is cached as an unordered anchor pair and emitted to the dashboard
with its 32-bit slot ID. No rolling median is applied. The anchor EKF only
updates when a complete coherent frame contains every selected pair.

Lab stability comparison, 2026-07-15:

This test compares anchor-anchor range stability only, not absolute placement
accuracy. The modules were left in the current room/charging layout, so the
important number is short-term spread, not whether the measured edge length is a
known physical value. The FlexTDOA run used the short `REQ/RESP` anchor
measurement used by the earlier clean FlexTDOA prototype. `sample` is the
unfiltered corrected single-shot value from that short-anchor prototype. The
`median9` rows are historical offline/firmware comparisons only; the current
FlexTDOA runtime no longer applies them. The DS-TWR run used
`APP_RUNTIME_MODE_UWB_ANCHOR_SURVEY`, which performs the full
`POLL/RESP/FINAL/REPORT/REPORT2` exchange. This result explains why the legacy
hybrid geometry looked so stable, while the current FlexTDOA runtime
intentionally keeps the shorter paper-style request/response geometry path and
shows raw behavior.

| Protocol/value | Pair | n | avg cm | median cm | min cm | max cm | std cm | span cm |
| --- | --- | ---: | ---: | ---: | ---: | ---: | ---: | ---: |
| FlexTDOA `sample` raw | 2-3 | 221 | 547.3 | 548.5 | 486.1 | 593.5 | 14.9 | 107.4 |
| FlexTDOA `sample` raw | 2-4 | 236 | 563.9 | 563.9 | 503.4 | 668.7 | 17.1 | 165.3 |
| FlexTDOA `sample` raw | 2-5 | 243 | 862.6 | 864.9 | 747.2 | 957.1 | 18.2 | 209.9 |
| FlexTDOA `sample` raw | 3-4 | 257 | 827.9 | 829.2 | 763.0 | 881.0 | 14.5 | 118.0 |
| FlexTDOA `sample` raw | 3-5 | 274 | 733.4 | 735.7 | 650.0 | 834.5 | 21.1 | 184.5 |
| FlexTDOA `sample` raw | 4-5 | 275 | 552.1 | 552.5 | 477.0 | 664.6 | 21.1 | 187.6 |
| FlexTDOA `median9` | 2-3 | 221 | 548.3 | 548.5 | 546.3 | 552.2 | 0.8 | 5.9 |
| FlexTDOA `median9` | 2-4 | 236 | 566.0 | 566.0 | 562.2 | 568.3 | 0.4 | 6.1 |
| FlexTDOA `median9` | 2-5 | 243 | 865.5 | 865.5 | 853.5 | 873.4 | 1.0 | 19.9 |
| FlexTDOA `median9` | 3-4 | 257 | 829.4 | 829.4 | 827.8 | 832.5 | 0.3 | 4.7 |
| FlexTDOA `median9` | 3-5 | 274 | 732.5 | 732.5 | 713.0 | 745.1 | 2.7 | 32.1 |
| FlexTDOA `median9` | 4-5 | 275 | 551.2 | 551.1 | 528.5 | 559.5 | 2.2 | 31.0 |
| DS-TWR survey raw | 2-3 | 98 | 549.4 | 549.4 | 547.5 | 551.1 | 0.8 | 3.6 |
| DS-TWR survey raw | 2-4 | 98 | 564.2 | 564.2 | 560.3 | 567.1 | 1.5 | 6.8 |
| DS-TWR survey raw | 2-5 | 99 | 867.5 | 867.2 | 862.9 | 872.3 | 2.1 | 9.4 |
| DS-TWR survey raw | 3-4 | 98 | 830.7 | 830.8 | 829.1 | 832.7 | 0.7 | 3.6 |
| DS-TWR survey raw | 3-5 | 99 | 737.1 | 737.3 | 732.8 | 740.1 | 1.5 | 7.3 |
| DS-TWR survey raw | 4-5 | 78 | 551.6 | 551.7 | 548.1 | 554.6 | 1.5 | 6.5 |
| DS-TWR `median9` | 2-3 | 98 | 549.4 | 549.4 | 548.3 | 550.4 | 0.4 | 2.1 |
| DS-TWR `median9` | 2-4 | 98 | 564.2 | 564.1 | 562.3 | 565.8 | 0.7 | 3.5 |
| DS-TWR `median9` | 2-5 | 99 | 867.3 | 867.4 | 864.8 | 868.8 | 0.9 | 4.0 |
| DS-TWR `median9` | 3-4 | 98 | 830.7 | 830.8 | 830.0 | 831.2 | 0.3 | 1.2 |
| DS-TWR `median9` | 3-5 | 99 | 737.3 | 737.4 | 735.3 | 738.7 | 0.5 | 3.4 |
| DS-TWR `median9` | 4-5 | 78 | 551.7 | 551.7 | 550.4 | 552.8 | 0.5 | 2.4 |

The conclusion is useful: the full DS-TWR anchor-anchor exchange is already
stable raw, roughly `0.7-2.1 cm` standard deviation in this run. The short
FlexTDOA anchor measurement is much noisier raw, roughly `14.5-21.1 cm`
standard deviation. The current paper-aligned runtime uses the short FlexTDOA
measurement because it matches the article and is much faster. The full DS-TWR
geometry path remains a documented fallback if the lab later decides to trade
paper purity for extra geometry stability. The uncorrected FlexTDOA `raw` field
was much wider than `sample` in this run, so the per-frame clock-ratio
correction is still required.

#### Legacy Hybrid Experiments

Before the paper-aligned FlexTDOA runtime, the firmware used a DS-TWR-based
hybrid. The tag was still radio-passive, but each anchor pair ran a full DS-TWR
slot and the tag derived two passive range-difference estimates from the frames
it heard. This section is kept as lab history and comparison data; it is not the
current FlexTDOA slot implementation.

The tag hears:

```text
Ai POLL      ---- unicast/broadcast on air ----> tag RX timestamp R_poll
Aj RESP      ---- unicast/broadcast on air ----> tag RX timestamp R_resp
Ai FINAL     ---- unicast/broadcast on air ----> tag RX timestamp R_final
Aj REPORT2   ---- unicast/broadcast on air ----> tag receives anchor timestamps
```

`REPORT2` carries the responder-side timestamps, the initiator timestamps
received earlier in `REPORT`, and the current DS-TWR anchor-anchor distance.
The tag combines those values with its own receive timestamps.

Primary estimate, from `POLL -> RESP`:

```text
reply_aj     = RESP_TX_Aj - POLL_RX_Aj         // Aj clock
tof_ij       = distance(Ai, Aj) / c
rx_delta_tag = R_resp - R_poll                 // tag clock

range_diff_ij_primary = c * (rx_delta_tag - reply_aj_corrected - tof_ij)
                      = distance(tag, Aj) - distance(tag, Ai)
```

Alternate estimate, from `RESP -> FINAL`:

```text
reply_ai      = FINAL_TX_Ai - RESP_RX_Ai        // Ai clock
rx_delta_tag  = R_final - R_resp                // tag clock

range_diff_ij_alt = c * (tof_ij + reply_ai_corrected - rx_delta_tag)
                  = distance(tag, Aj) - distance(tag, Ai)
```

If both estimates were present and agreed within the legacy `0.75 m` guard, the
firmware used a guarded dual-leg average:

```text
blend = 0.5
diff  = primary + blend * (alt - primary)
```

So the normal fused result was the 50/50 average of the `POLL -> RESP` and
`RESP -> FINAL` estimates. If the two estimates disagreed beyond the reject
limit, the firmware fell back to the classic `POLL -> RESP` estimate and marked
the row with `suspect=1`; the dashboard kept it visible while excluding it from
the live least-squares fit when enough other observations were available.

The legacy firmware log line included both estimates:

```text
UWB_FLEX_TDOA obs tag=<tag> initiator=<Ai> responder=<Aj> seq=<seq>
  diff=<m> m raw=<m> m anchor=<m> m primary=<m> m alt=<m> m
  agree=<m> m blend=<0..0.5> fused=<0|1> suspect=<0|1> ...
```

Initial dual-leg passive sanity test, 2026-07-15:

The test below used the same room setup that was active during development. It
does not claim absolute tag accuracy, because the tag position was not measured
with a tape. It only checks whether the passive solver is internally stable when
the tag is left fixed.

| Metric | Result |
| --- | ---: |
| Duration | `75 s` |
| Passive observations | `673` |
| Fused observations | `670 / 673` (`99.6%`) |
| Suspect observations | `3 / 673` (`0.4%`) |
| `primary` vs `alt` agreement, median | `13.0 cm` |
| Paired reverse sum, median | `0.9 cm` |
| Paired reverse sum, std | `3.9 cm` |
| Reconstructed anchor edge std, median | `1.05 cm` |
| Solved tag X std / span | `1.35 cm` / `6.17 cm` |
| Solved tag Y std / span | `0.97 cm` / `5.49 cm` |
| Solver residual RMS, median | `7.59 cm` |

This was a useful improvement over the earlier visibly wandering passive view:
the DS-TWR anchor geometry remains stable, the reverse directed observations are
near antisymmetric, and the extra `RESP -> FINAL` estimate gives a cheap
multipath/consistency check without making the tag transmit. One outlier class
still exists: individual `primary` vs `alt` agreement can spike hard, so the
dashboard keeps `suspect` rows visible and excludes them from the live fit when
there are enough healthy pairs.

Back-to-back classic vs dual-leg comparison, 2026-07-15:

This run was made to compare the old passive FlexTDOA observation against the
dual-leg version as fairly as possible. The same anchor/tag layout was kept, the
same dashboard parser/solver was used, and each firmware ran for `75 s`:

| Metric | Classic FlexTDOA `78967ac` | Dual-leg FlexTDOA `56d0033` | Read |
| --- | ---: | ---: | --- |
| Passive observations | `617` | `670` | Similar throughput |
| Fused observations | n/a | `665 / 670` (`99.3%`) | Dual leg usually has both estimates |
| Suspect observations | n/a | `5 / 670` (`0.7%`) | Few hard disagreements |
| `primary` vs `alt` agreement, median | n/a | `31.2 cm` | Useful as a quality signal |
| Paired reverse sum, median | `-30.75 cm` | `0.8 cm` | Dual-leg removes a strong directional bias |
| Paired reverse sum, std | `11.63 cm` | `3.68 cm` | Dual-leg is much more antisymmetric |
| Anchor edge std, median | `1.03 cm` | `1.18 cm` | Same DS-TWR geometry path; effectively similar |
| Solved tag X std / span | `1.36 cm` / `6.16 cm` | `1.25 cm` / `7.10 cm` | Similar |
| Solved tag Y std / span | `1.03 cm` / `5.31 cm` | `0.99 cm` / `4.94 cm` | Similar |
| Solver residual RMS, median | `5.35 cm` | `6.64 cm` | Classic was lower in this run |

The practical verdict is not "dual-leg is better at every metric". It is more
specific: dual-leg greatly improves pair symmetry (`reverse_sum`) and gives a
new internal consistency check (`agree`, `suspect`) while preserving roughly the
same fixed-tag position stability. The cost in this run was a slightly higher
least-squares residual. For now the dual-leg path is worth keeping because it
exposes bad/multipath-like observations directly instead of letting a
directional bias hide inside the solver.

Guarded dual-leg validation, 2026-07-15:

After the comparison above, the firmware was changed to use a guarded 50/50
dual-leg average when `primary` and `alt` agree within `0.75 m`, and to fall
back to the classic `primary` estimate when they do not. The table below uses
the same `715fee2` log capture and recomputes both variants offline, so the
numbers compare math only, not different room layouts.

| Metric | `primary_classic` from same logs | `guarded_dual_50` `715fee2` | Read |
| --- | ---: | ---: | --- |
| Passive observations | `681` | `681` | Same capture |
| Fused observations | n/a | `678 / 681` (`99.6%`) | Almost all slots had both legs |
| Suspect observations | n/a | `3 / 681` (`0.4%`) | Hard disagreements are rare |
| `primary` vs `alt` agreement, median | n/a | `21.8 cm` | Quality signal remains useful |
| Paired reverse sum, median | `-23.0 cm` | `0.45 cm` | Dual-leg removes the directional bias |
| Paired reverse sum, p90 abs | `35.9 cm` | `9.21 cm` | Worst normal rows are much tighter |
| Solved tag X std / span | `1.72 cm` / `9.98 cm` | `1.60 cm` / `9.57 cm` | Slightly better |
| Solved tag Y std / span | `1.21 cm` / `8.52 cm` | `1.04 cm` / `5.98 cm` | Better |
| Solver residual RMS, median | `14.91 cm` | `7.77 cm` | Roughly half in this geometry |

This was the practical hybrid before the paper-aligned rewrite: full DS-TWR was
kept for anchor-anchor geometry, while the radio-passive tag used both DS-TWR
legs as a consistency check and as a fused range-difference measurement.

The passive tag uses the instantaneous DW3000 carrier-integrator clock ratio
from the received response frame to convert `reply_aj` from the responder clock
domain into the tag clock domain. There is no running clock-ratio filter in the
current FlexTDOA runtime. The log still includes both uncorrected `raw` and
clock-corrected `diff` so the correction can be audited.

The dashboard `Position` tab reconstructs relative anchor geometry through the
paper-style TWR-EKF phase. Raw pair ranges are grouped by TDMA frame and all
available edges update the anchor state simultaneously. Tag positioning starts
automatically once a complete live geometry exists and keeps following physical
anchor movement.

The browser-side geometry estimator has a temporal range gate in front of the
EKF. A one-shot pair jump is rejected and the last accepted edge is held for up
to 15 seconds, so a missed maintenance range or a brief radio outlier cannot
reshape the canvas or hide the live position. A physical relocation is accepted
automatically only after at least three persistent samples on two or more
changed edges that share the same anchor, and only when the proposed complete
geometry passes a 12 cm RMS consistency check. Published coordinates are
slew-limited to 5 cm per update. The geometry panel preserves a cumulative
rejected-spike counter and the last rejected pair/delta, making sub-second
failures inspectable after they disappear from the raw stream. It reports the
raw and accepted distances side by side and uses median-absolute-deviation
robust sigma rather than the outlier-sensitive standard deviation.

Native DS-TWR tag positioning additionally uses a robust 3-of-4 fit. A single
bad tag-anchor range is omitted from the position and circle drawing, recorded
in a persistent session counter, and shown as a skipped range in the
measurement table. FlexTDOA and Passive DS-TWR tag observations remain raw for
protocol analysis; the guard described above applies to their shared
anchor-geometry stage.

Native DS-TWR now inserts one rotating anchor-pair maintenance exchange every
four tag-position frames. With four anchors, all six geometry edges are
refreshed over 24 position frames; this costs about one quarter of one slot per
frame on average. Passive DS-TWR Fast Star keeps its reference for three frames
and rotates the fourth frame through the remaining anchors, so it obtains a
complete geometry without extra slots. Robust Rotating and FlexTDOA already
observe the required anchor pairs in their normal schedules.

The `Position Setup` solver selector is intentionally protocol-level, so field
tests can compare the same geometry and tag path without changing dashboard
code:

| Solver | Firmware runtime | Tag radio behavior | Range value used by dashboard | Best use |
| --- | --- | --- | --- | --- |
| `DS-TWR ranges` | `uwb_ranging` | tag actively responds to each anchor | absolute tag-anchor DS-TWR distance | Baseline comparison with direct ranges. |
| `FlexTDOA` | `uwb_flex_tdoa` | tag only listens | paper-style request/response passive range difference | Current default. Matches the FlexTDOA paper slot model. |
| `Passive DS-TWR` | `uwb_passive_ds_twr` | tag only listens | passive difference from native anchor DS-TWR | Scalable passive tags with native three-packet anchor ranging. |
| `Legacy hybrid logs` | `uwb_flex_tdoa` legacy captures | tag only listens | guarded dual-leg `diff`, fused from `primary` and `alt` when they agree | Historical comparison only. Useful for replaying older captures. |

The passive FlexTDOA path now has two consumers of the same raw measurements.
The dashboard keeps its PC least-squares range-difference fit for inspection,
while the tag ESP32-S3 also runs the planar AlgMin solver locally and publishes
the resulting position through binary telemetry. Both use the latest fresh
directed observations directly. Neither applies reverse-sum gates, residual
outlier pruning, medians, dynamic weights, or Kalman prediction. This exposes
the raw protocol behavior so radio changes can be evaluated without smoothing
hiding the result. `DS-TWR ranges` can use the same measured anchor geometry for
absolute tag-anchor ranges, but the blue distance circles only make sense for
absolute ranges, not TDOA range differences.

Historical solver replay, 2026-07-15:

Earlier dashboard experiments compared static/dynamic median windows and an
Auto-Kalman display mode. Those filters were useful for exploratory walking
tests, but they were removed on 2026-07-17. Current FlexTDOA development uses
raw observations only.

Walking-test note, 2026-07-16:

During a handheld walk with the tag, the fixed-point tail after the walk settled
near `x ~= 3.43 m`, `y ~= 3.11 m`. The last stationary segment had all `6/6`
paired observations fresh, `reverse_sum` usually below `11 cm`, residual RMS
around `4-10 cm`, and a short-window position span around `6.5-7.6 cm`.
During motion, the raw least-squares solution still produced large jumps when
only `3/6` or `4/6` usable observations remained, or when `reverse_sum` climbed
above roughly `1 m`. This supports two follow-up changes: stricter observation
gating before the solver, and adjacent pair round-trip scheduling so paired
directions are observed while the tag is closer to the same physical position.

### Time Units

The DW3000 uses several time units:

| Unit | Meaning |
| --- | --- |
| `ms` | Normal milliseconds used by FreeRTOS and runtime config. |
| `UUS` | UWB microseconds; `1 UUS = 512 / 499.2 MHz = 1.025641 us`. |
| `DTU` | DW3000 device time unit; about `15.650040064 ps`. |

Useful conversions:

| Value | Approximate real time |
| --- | ---: |
| `500 UUS` | `512.82 us`, or `0.513 ms` |
| `20 ms` | `1,277,952,000 DTU` |
| `10 ms` | `638,976,000 DTU` |

`UUS` is used for DW3000 automatic TX-to-RX wait. Native ranging turnaround
delays (for example `5 ms`) are converted to DTU and programmed as delayed TX
timestamps.

### Message Sequence

One ranging attempt between tag `1` and one anchor looks like this:

```text
Tag / initiator, module 1                         Anchor / responder, module N

T1: POLL TX  ------------------------------------>
                                                   T2: POLL RX

                                                   schedule RESP at:
                                                   T3 = T2 + ranging_resp_delay_ms

                                                   T3: RESP TX
     auto RX opens after 500 UUS  <---------------
T4: RESP RX

schedule FINAL at:
T5 = T4 + ranging_final_delay_ms

T5: FINAL TX  ----------------------------------->
                                                   T6: FINAL RX
     FINAL carries T1, T4, T5
                                                   calculate distance
                                                   log UWB_RANGING result
```

The critical `RESP` and `FINAL` instants are owned by the DW3000 radio through
delayed TX. The firmware computes the target timestamp, writes `DX_TIME`, and
issues `DTX` or `DTX_W4R`. That keeps the timing stable even if FreeRTOS has
scheduler jitter.

### Calibration Slot Timing

The three-module antenna-delay calibration uses deterministic slots so only one
ordered pair is expected to talk at a time. For `1,2,3`, one complete round is:

```text
slot 0: 1 -> 2
slot 1: 1 -> 3
slot 2: 2 -> 1
slot 3: 2 -> 3
slot 4: 3 -> 1
slot 5: 3 -> 2
then wait calibration_round_gap_ms
round N + 1
```

The slot length is `calibration_min_interval_ms`. In the lab dashboard this is
normally `100 ms`. The round gap is `calibration_max_interval_ms`; the dashboard
labels it `Round gap ms` and defaults it to `10 ms`.

If the coordinator is also the initiator for the current pair, for example
`1 -> 2`, the slot looks like this:

```text
t = 0 us
M1 coordinator/init     M2 responder          M3 listener
     CAL_SYNC  ------->      receive               receive
     start timer             start timer           start timer
          |                       |                     |
          |<------ guard 500 us ------>|                |

t = 500 us
     POLL  ------------>      RX POLL
                              schedule RESP delayed TX
                              RESP at +20 ms
     <------------- RESP

     schedule FINAL delayed TX
     FINAL at +20 ms
     FINAL ------------>
                              RX FINAL

     wait 10 ms
     REPORT ----------->
                              RX REPORT
                              calculate distance
     <------------ REPORT2
     verify anchor result

t = slot end, normally 100 ms
all modules exit the slot and reset the calibration timer
```

If the initiator is a follower, for example `2 -> 3`, the coordinator assigns
the slot with `CAL_CMD`:

```text
t = 0 us
M1 coordinator          M2 initiator          M3 responder
     CAL_SYNC  ------->      receive               receive
     start timer             start timer           start timer

t = 500 us
     CAL_CMD ---------> M2
     "this slot is 2 -> 3"

M2 waits APP_UWB_CALIBRATION_COMMAND_DELAY_MS
currently 20 ms

     POLL -------------------------------> M3
                                            RESP delayed +20 ms
     <------------------------------- RESP

     FINAL delayed +20 ms ---------------->
     REPORT after 10 ms ------------------>
                                            calculate distance
     <------------------------------ REPORT2

t = slot end, normally 100 ms
all modules exit the slot and reset the calibration timer
```

`CAL_SYNC` is sent before every slot. The coordinator starts a dedicated 1 MHz
ESP GPTimer when the SYNC transmission completes. Followers arm the same timer
before RX and start it from the DW3000 IRQ when the SYNC frame arrives. The
first `cal_guard_us` microseconds of the slot are a guard window. The firmware
default is `APP_UWB_CALIBRATION_SLOT_GUARD_US = 500 us`, and the dashboard can
change it at runtime without OTA.

The guard and slot-end waits are implemented with a GPTimer alarm and task
notification. This preserves microsecond-level slot alignment without spinning
the UWB task in a CPU busy-wait.

This ESP-side timer does not enter the distance formula. It only aligns the
slot windows so the lab workflow is deterministic. Distance is still calculated
from DW3000 hardware timestamps with DTU resolution.

SYNC is intentionally not retried inside the same slot. If a follower misses
SYNC, if the SYNC sequence number jumps, or if the coordinator cannot transmit
SYNC, firmware logs:

```text
UWB CAL slot skipped due to sync fail
```

Dashboard-driven auto calibration treats any sync miss during the collection
window as invalid and blocks antenna-delay writes.

### Timestamp Ownership

The easiest way to reason about DS-TWR is to track who knows each timestamp.
Every timestamp below is a hardware timestamp captured or scheduled by DW3000.

After `POLL`:

| Side | What it knows |
| --- | --- |
| Initiator/tag | `T1`, timestamp when it transmitted `POLL`. |
| Responder/anchor | `T2`, timestamp when it received `POLL`. |

`T1` is in the tag clock domain. `T2` is in the anchor clock domain. The two
absolute values cannot be compared directly.

After `RESP`:

```text
T3 = T2 + dt_resp_delay_ms
```

| Side | What it knows |
| --- | --- |
| Initiator/tag | `T1`, `T4` |
| Responder/anchor | `T2`, `T3` |

The tag can compute:

```text
round_a = T4 - T1
```

The anchor can compute:

```text
reply_b = T3 - T2
```

The tag still cannot calculate a correct distance from only those two values,
because `reply_b` was measured in the anchor clock domain.

After `FINAL`:

```text
T5 = T4 + dt_final_delay_ms
```

| Side | What it knows |
| --- | --- |
| Initiator/tag | `T1`, `T4`, `T5` |
| Responder/anchor | `T2`, `T3`, `T6` |

The tag-side intervals are:

```text
round_a = T4 - T1
reply_a = T5 - T4
```

The anchor-side intervals are:

```text
reply_b = T3 - T2
round_b = T6 - T3
```

At this point all pieces needed for DS-TWR exist, but they are split between
the two modules. Native ranging places `T1`, `T4`, and the precomputed delayed
TX timestamp `T5` directly in `FINAL`. The anchor already owns `T2`, `T3`, and
`T6`, so it can calculate distance immediately after receiving the third
frame. No fourth UWB message is required.

### Distance Formula

The uncorrected DS-TWR calculation uses these intervals:

```text
round_a = T4 - T1   tag sees POLL TX -> RESP RX
reply_a = T5 - T4   tag waits RESP RX -> FINAL TX

reply_b = T3 - T2   anchor waits POLL RX -> RESP TX
round_b = T6 - T3   anchor sees RESP TX -> FINAL RX
```

Then:

```text
tof_dtu = (round_a * round_b - reply_a * reply_b)
          / (round_a + round_b + reply_a + reply_b)

distance_m = tof_dtu * 15.650040064 ps * 299702547 m/s
```

In the ideal model, `tof` is the real one-way flight time. If both sides shared
one perfect clock:

```text
round_a = 2 * tof + reply_b
round_b = 2 * tof + reply_a
```

The DS-TWR expression is chosen so the internal reply delays cancel out:

```text
round_a * round_b - reply_a * reply_b
```

Substitute the ideal expressions:

```text
(2 * tof + reply_b) * (2 * tof + reply_a) - reply_a * reply_b
```

Expand and cancel the `reply_a * reply_b` terms:

```text
4 * tof^2 + 2 * tof * reply_a + 2 * tof * reply_b
```

Factor:

```text
2 * tof * (2 * tof + reply_a + reply_b)
```

The denominator is:

```text
round_a + round_b + reply_a + reply_b
```

Substitute again:

```text
(2 * tof + reply_b) + (2 * tof + reply_a) + reply_a + reply_b
```

which factors to:

```text
2 * (2 * tof + reply_a + reply_b)
```

The full fraction therefore simplifies to `tof`:

```text
2 * tof * (2 * tof + reply_a + reply_b)
----------------------------------------
2       * (2 * tof + reply_a + reply_b)
```

This is why the formula has this shape:

```text
tof = (round_a * round_b - reply_a * reply_b)
      / (round_a + round_b + reply_a + reply_b)
```

A simpler expression such as this is tempting:

```text
tof = (round_a - reply_b) / 2
```

but `round_a` is measured by the tag clock while `reply_b` is measured by the
anchor clock. Those clocks are close, but not identical. The DS-TWR formula
uses both perspectives symmetrically and reduces clock mismatch error. With
`APP_UWB_DISTANCE_TEST_CLOCK_OFFSET_CORRECTION = 1`, the firmware also uses the
DW3000 clock-offset measurement from the received frame before converting time
of flight to meters.

### TX-to-RX and RX-to-TX Timing

The two most common timing questions are:

| Question | Current answer |
| --- | --- |
| How long after TX until RX opens? | `500 UUS`, about `0.513 ms` |
| How long after RX until the next native ranging TX? | `5 ms` for `RESP`, `5 ms` for `FINAL` by default |

The TX-to-RX delay is a DW3000 auto-receive setting. It applies after:

```text
POLL TX  -> tag opens RX for RESP
RESP TX  -> anchor opens RX for FINAL
```

The five-frame distance-test and calibration workflows also open RX after
`REPORT` while waiting for their diagnostic `REPORT2`.

The RX-to-TX delays are delayed-TX timestamps. They apply after:

```text
POLL RX  -> anchor schedules RESP TX at +5 ms
RESP RX  -> tag schedules FINAL TX at +5 ms
```

So the system is not trying to turn around instantly. The radio has about half
a millisecond before RX opens after a TX, and the default native profile leaves
about `5 ms` between receiving one DS-TWR frame and transmitting the next
scheduled frame. Distance-test and calibration retain their independent,
longer timing defaults.

### Antenna Delay

Antenna delay is separate from protocol delays. It is not a sleep, slot, or
turnaround time. It is a calibration value written to the DW3000 RX and TX
antenna-delay registers during radio init.

The firmware reads the active antenna delay from persistent identity NVS. If no
calibrated value exists, it falls back to `APP_UWB_ANTENNA_DELAY_DEFAULT`.

Wrong antenna delay shifts absolute distance even if packet success is perfect.
Use `/status` to inspect the live values:

```text
uwb_active_antenna_delay
uwb_active_antenna_delay_hex
uwb_antenna_delay_from_nvs
```

### Common Log Patterns

| Log pattern | Meaning |
| --- | --- |
| `DS-TWR RESP wait failed` | Initiator sent `POLL` but did not receive matching `RESP` before timeout. |
| `DS-TWR FINAL wait failed` | Responder sent `RESP` but did not receive `FINAL` before timeout. |
| `DS-TWR REPORT wait failed` | Responder received `FINAL` but did not receive the timestamp report. |
| `DS-TWR REPORT2 wait failed` | Responder calculated distance, but initiator did not receive verification report. |
| `UWB distance RX error` | DW3000 reported PHY/RX error instead of a valid frame. |
| `UWB_RANGING result` | Native four-packet exchange completed; the tag received the anchor's one-shot `RESULT` distance. |
| `DS-TWR tag verify` | Initiator recalculated the same exchange and compared against anchor result. |
| `UWB CAL slot skipped due to sync fail` | Calibration slot synchronization failed; dashboard marks the run invalid. |

Useful code entry points:

| Area | File / function |
| --- | --- |
| Runtime mode selection | `components/app_manager/app_manager.c` |
| Runtime config defaults/NVS | `components/config/app_runtime_config.c` |
| Ranging service entry point | `components/uwb_ranging_service/uwb_ranging_service.c` |
| Tag/anchor loops | `components/uwb_dw3000/uwb_dw3000.c` |
| Native ranging initiator | `uwb_ranging_native_initiate_once()` |
| Native ranging responder | `uwb_ranging_native_respond_to_poll()` |
| Five-frame diagnostic initiator | `uwb_distance_initiate_once()` |
| Five-frame diagnostic responder | `uwb_distance_respond_to_poll()` |
| Delayed TX helpers | `uwb_dw3000_send_payload_delayed*()` |
| Antenna-delay calibration | `components/uwb_dw3000/uwb_dw3000_calibration.inc` |

## Identity and Wi-Fi

### Persistent Module Identity

The board identity is stored in NVS, which plays the role of persistent EEPROM
storage on ESP32. Normal firmware reads `module_id` from NVS and builds the
hostname from `APP_IDENTITY_HOSTNAME_PREFIX`, for example `uwb-module-2`. To
change a board identity or UWB role, set these values in
`components/config/include/app_config.h` for one provisioning boot:

```c
#define APP_IDENTITY_PROVISION_ENABLED 1
#define APP_IDENTITY_PROVISION_MODULE_ID 2
#define APP_IDENTITY_PROVISION_UWB_ROLE_ENABLED 1
#define APP_IDENTITY_PROVISION_UWB_ROLE APP_UWB_ROLE_ANCHOR
```

For a mobile tag, use `APP_UWB_ROLE_TAG`; for fixed points, use
`APP_UWB_ROLE_ANCHOR`. After that boot, set the provisioning flags back to `0`
and flash the common firmware again. `/status` exposes `hostname`, `module_id`,
`module_id_from_nvs`, `module_id_provisioned_this_boot`, `uwb_role_name`,
`uwb_role_from_nvs`, and `uwb_role_provisioned_this_boot`.

### Wi-Fi Selection and Reconnect

The Wi-Fi service scans before connecting and logs each matching AP with BSSID,
channel, RSSI, auth mode, and cipher. If a network broadcasts the same SSID
from multiple radios and one behaves better, lock the board to that AP in
`components/config/include/app_config.h`:

```c
#define APP_WIFI_LOCK_BSSID 1
#define APP_WIFI_BSSID "aa:bb:cc:dd:ee:ff"
#define APP_WIFI_LOCK_CHANNEL 6
```

The firmware also keeps reconnecting after disconnects and exposes the last
disconnect reason plus scan/connected AP details in `/status`.

## UWB Bring-up and Calibration

UWB bring-up follows the same first-step pattern used by the Zephyr DW3000
decadriver reference: initialize hardware, reset the chip, then read `DEV_ID`.
The valid IDs currently accepted are `0xDECA0302` and `0xDECA0312`.

After bring-up, the firmware runs a simple same-image UWB smoke test. Each
board sends a `UWBT` beacon at a random interval and spends the rest of the
time in RX. With the same firmware on two boards, wireless logs should show
`UWB TX beacon ...` and `UWB RX beacon ...` lines. The HTTP `/status` response
also exposes `uwb_tx_count`, `uwb_rx_count`, and the last received source/seq.

In `APP_RUNTIME_MODE_UWB_DISTANCE_TEST`, the same firmware assigns roles from
the source ID: source `1` is the initiator and source `2` is the responder by
default. The UWB source ID is derived from the persistent module ID unless
`APP_UWB_SOURCE_ID` is explicitly overridden. The initiator sends `POLL`,
receives `RESP`, schedules `FINAL`, then sends a `REPORT` with its hardware
timestamps. The responder schedules `RESP`, receives `FINAL` and `REPORT`,
calculates DS-TWR distance, and logs lines like
`DS-TWR distance seq=... distance=...`.

`RESP` and `FINAL` use DW3000 delayed TX by default
(`APP_UWB_DISTANCE_TEST_USE_DELAYED_TX`). The delay windows are configured with
`APP_UWB_DISTANCE_TEST_RESP_DELAY_MS` and
`APP_UWB_DISTANCE_TEST_FINAL_DELAY_MS`; the firmware converts them to DW3000
device time units and programs `DX_TIME`, so the critical transmit instant is
owned by the radio instead of the FreeRTOS scheduler.

`APP_RUNTIME_MODE_UWB_ANTENNA_DELAY_CALIBRATION` reuses the same DS-TWR
exchange and supports two workflows selected in `components/config/include/uwb_config.h`:

```c
#define APP_UWB_CALIBRATION_METHOD APP_UWB_CALIBRATION_METHOD_TWO_MODULE
#define APP_UWB_CALIBRATION_KNOWN_DISTANCE_MM 2000
#define APP_UWB_CALIBRATION_REFERENCE_ID 1
#define APP_UWB_CALIBRATION_DUT_ID 2
```

For the two-module method, the reference module initiates and the DUT responds.
Each measurement slot starts with a short UWB `CAL_SYNC` frame from the
reference. The reference starts a dedicated 1 MHz ESP GPTimer when that SYNC
transmission completes; the DUT arms the same timer before RX and starts it from
the DW3000 IRQ when the SYNC frame arrives. Both sides then wait the fixed
`cal_guard_us` guard window before POLL/RESP/FINAL begins. The firmware default
comes from `APP_UWB_CALIBRATION_SLOT_GUARD_US`, currently `500 us`.
The DUT logs sample distance, mean, standard deviation, error against the known
distance, and a first-pass suggested antenna delay. Swap `REFERENCE_ID` and
`DUT_ID` to calibrate the other board.

```c
#define APP_UWB_CALIBRATION_METHOD APP_UWB_CALIBRATION_METHOD_THREE_MODULE
#define APP_UWB_CALIBRATION_THREE_ID_0 1
#define APP_UWB_CALIBRATION_THREE_ID_1 2
#define APP_UWB_CALIBRATION_THREE_ID_2 3
#define APP_UWB_CALIBRATION_THREE_DISTANCE_0_1_MM 2000
#define APP_UWB_CALIBRATION_THREE_DISTANCE_0_2_MM 2000
#define APP_UWB_CALIBRATION_THREE_DISTANCE_1_2_MM 2000
```

For the three-module method, the first ID in the configured set is the
calibration coordinator. It walks a deterministic six-slot schedule:
`id0->id1`, `id0->id2`, `id1->id0`, `id1->id2`, `id2->id0`, and `id2->id1`.
Each slot is `APP_UWB_CALIBRATION_MIN_INTERVAL_MS` long; in the lab this is
`100 ms`, which should fit the complete DS-TWR exchange when
`dt_rx_timeout_ms` is kept short enough for the experiment.
Before every slot, the coordinator broadcasts a short `CAL_SYNC` frame and all
participants restart the dedicated 1 MHz calibration timer. The first
`cal_guard_us` microseconds of the slot are a guard window (`500 us` by
default), then the assigned ordered pair performs DS-TWR. Because SYNC is
repeated before every slot, ESP timer drift can only accumulate inside one
slot. The firmware still attempts the full `POLL`, `RESP`, `FINAL`, `REPORT`,
and `REPORT2` sequence, so the logs show if the exchange does not fit.

The coordinator waits `APP_UWB_CALIBRATION_SYNC_PREPARE_MS` before each SYNC
frame (`20 ms` by default). This is not part of the measured slot; it simply
gives the followers time to finish the previous slot, clear DW3000 state, and
re-arm RX before the next SYNC is transmitted.

SYNC is intentionally not retried inside the same slot. Followers wait long
enough to cover the normal round gap, then use the `CAL_SYNC` sequence number to
detect skipped slots. If a sequence gap is detected, if the long SYNC wait
expires, or if the coordinator/reference cannot transmit SYNC, firmware logs
`UWB CAL slot skipped due to sync fail` and discards that slot. The same log line
includes aggregate sync health counters (`sync_ok`, `sync_timeout`,
`sync_invalid`, `sync_rx_error`, `sync_tx_fail`, `sync_sequence_gap`, and
`slot_skipped`). During dashboard-driven auto calibration, any such sync miss in
the collection window marks the run invalid and blocks antenna-delay writes, even
if enough diagnostic samples are later collected.

After all six directed pairs are measured, the firmware waits
`APP_UWB_CALIBRATION_MAX_INTERVAL_MS` before the next round. The firmware
default is `10 ms`; increase it only if short-gap testing shows sync misses or
radio cleanup problems between rounds. The dashboard labels these as `Slot ms`
and `Round gap ms`.

Calibration timing controls in the dashboard:

| Control | Meaning |
| --- | --- |
| `Summary every` | Log diagnostic calibration statistics every N accepted samples. It does not change the measurement sequence. |
| `Slot ms` | Fixed time budget for one directed pair, for example `M4 -> M2`. |
| `Guard us` | Quiet time at the beginning of each synchronized slot before the assigned pair starts talking. |
| `DS-TWR timeout ms` | Maximum wait for expected ranging frames inside the DS-TWR exchange. For the current short-slot test it is intentionally `100 ms`, the same as the slot width. |
| `Round gap ms` | Delay after all six directed pairs finish, before the next calibration round starts. |
| `RX slice ms` | Short listen window used by passive calibration nodes while they monitor the rest of the slot. Smaller slices wake more often; larger slices reduce loop churn. |

The logs contain directed pair statistics such as `1->2`, `2->1`, `1->3`,
etc. The dashboard keeps these directions separate and solves the antenna-delay
corrections by minimizing the full directed EDM residual, matching the spirit of
Qorvo APS014: collect all `nChips * (nChips - 1)` TWR measurements, compare them
against the measured physical EDM, and choose the delays that minimize the
matrix error. The three distance macros can all be equal for an equilateral
setup or can hold the measured distance of each triangle edge. Use the final
radio configuration and a known distance such as 2-5 m; 20 cm is useful for
smoke testing, not for calibration.

The dashboard uses a median center for calibration samples. The default
collection count is `39` samples per directed pair, so the center sample is
unambiguous after sorting. Mean, standard deviation, min, and max are still
reported as diagnostics, but antenna-delay corrections are based on medians to
make an occasional outlier less likely to move the result.
The dashboard uses exactly that many samples per directed pair for the solve:
once a direction reaches the requested count, later samples for that direction
are ignored so all six directed edges have equal weight.

For `39` samples over all six directed pairs, use at least a `240 s` dashboard
auto-calibration timeout. A `180 s` timeout is close enough to the real run time
that a clean calibration can finish one or two directed samples short.

When dashboard auto calibration finishes, it stops UWB on the calibration
participants by writing `uwb=0` and rebooting them. Antenna-delay writes made by
the same job are staged in NVS first, so this final reboot also applies the new
delay while leaving the DW3000 held in reset. If setup fails before collection
starts, the dashboard sends the same UWB stop command to all configured modules
so a partial calibration start cannot leave a transmitter running.
The dashboard Cancel Calibration button is an emergency stop: it marks the
running job as cancelled when one exists and always sends `uwb=0` plus reboot to
all configured modules.
The Settings tab keeps the last auto-calibration result in a table next to the
calibration controls, including summary, antenna-delay writes, pair errors,
directed samples, fit residuals, and UWB stop/cleanup status.

Lab calibration note, 2026-07-11:

- Modules `1`, `2`, and `3` were placed in printed alignment fixtures as a
  2.00 m equilateral triangle.
- Starting delays were `M1=0x3fd6`, `M2=0x4019`, `M3=0x3fdc`.
- The first pass showed symmetric pair errors of about `1-2=-0.05 dtu`,
  `1-3=+44.65 dtu`, and `2-3=-23.90 dtu`.
- Solving the three pair equations produced corrections of `M1=+34 dtu`,
  `M2=-34 dtu`, and `M3=+10 dtu`.
- The delays stored in NVS are now `M1=0x3ff8`, `M2=0x3ff7`,
  `M3=0x3fe6`.
- Verification after reboot measured `1-2=2.001 m`, `1-3=1.996 m`, and
  `2-3=2.000 m`, with per-link standard deviation around `1.0-1.4 cm`.

For additional modules, keep two already calibrated modules fixed as references
and place the uncalibrated module in the third fixture position. Run the
three-module calibration with all three sides set to the measured triangle
edges, but apply only the correction for the new module. If `K1` and `K2` are
known-good references and `U` is the new module, the dashboard fits the
new-module correction from all directed errors that include `U`, while using the
reference-only directions as a guard. Intuitively this is close to:

```text
err_K1_U = center(err_dtu K1->U, err_dtu U->K1)
err_K2_U = center(err_dtu K2->U, err_dtu U->K2)
correction_U = round(center(err_K1_U, err_K2_U))
new_delay_U = old_delay_U + correction_U
```

The reference-reference pair should remain close to zero. If it does not, check
the physical placement or RF stability before writing a new delay.

The local dashboard can automate this workflow from `Settings` ->
`Antenna Delay Calibration` with `Auto Calibrate + Apply`. The button:

1. writes the runtime calibration setup and reboots the selected modules,
2. collects the requested number of `UWB CAL sample` log entries for each
   required directed pair,
3. takes the median distance for each directed pair, computes the directed EDM
   fit and least-squares antenna-delay corrections, including residuals that
   show how well one delay per module explains the measurements, and
4. writes the corrected antenna delay values to NVS for the selected target
   modules.

For a new module, keep two calibrated references in the fixtures, select only
the new module in `Targets`, and use the three-module set that includes both
references. For example, select `module 4` and run `1,2,4` to adjust only M4.
The dashboard configures all three calibration participants automatically and
holds excluded live UWB modules in reset while the calibration runs.
`Min apply DTU` prevents rewriting NVS for tiny noise-level corrections; the lab
default is `2`.
`Reference guard cm` protects the calibrated references: when a reference-only
edge, such as M1-M2 while calibrating M4, exceeds this error threshold, the
dashboard refuses NVS writes even when `Auto apply` is enabled. The lab default
is `2.00 cm`.

`APP_RUNTIME_MODE_UWB_RANGING` is the current absolute-range 1-tag/4-anchor
runtime. `APP_RUNTIME_MODE_UWB_FLEX_TDOA` is the experimental radio-passive
tag runtime that uses FlexTDOA request/response slots and solves from
range-difference observations in the dashboard. The same firmware image runs on
all modules; the runtime config selects tag ID and anchor IDs, the first anchor
ID acts as slot coordinator, and persistent NVS identity keeps each module's
hostname, module ID, UWB role, and calibrated antenna delay.

If `APP_UWB_DW_LEDS_ENABLED` is set, the DW3000 configures GPIO0 as RXOKLED,
GPIO1 as SFDLED, GPIO2 as RXLED, and GPIO3 as TXLED once during radio init.
The chip then drives these LED indications in hardware, so the firmware does
not add SPI traffic for LED toggling. Each function can be disabled separately
with `APP_UWB_DW_RXOK_LED_ENABLED`, `APP_UWB_DW_SFD_LED_ENABLED`,
`APP_UWB_DW_RX_LED_ENABLED`, or `APP_UWB_DW_TX_LED_ENABLED`.

The configured antenna delay is applied to both DW3000 RX and TX antenna delay
registers during radio init.

## BNO085 IMU

The BNO085 is a live runtime service, not only a factory test. It uses address
`0x4A` at `400 kHz` on the shared I2C bus, GPIO40 for reset, and the active-low
level interrupt on GPIO15. Firmware enables calibrated acceleration report
`0x01` at the selected interval and GyroRV report `0x2A` at a fixed 50 Hz.
The compile-time defaults in `components/config/include/app_config.h` are:

```c
#define APP_BNO085_ACCEL_TEST_ENABLED 0
#define APP_BNO085_I2C_ADDRESS 0x4A
#define APP_BNO085_I2C_CLOCK_HZ 400000
#define APP_BNO085_ACCEL_INTERVAL_MS 2
#define APP_BNO085_LOG_INTERVAL_MS 1000
#define APP_BNO085_INT_WAIT_TIMEOUT_MS 250
```

`APP_BNO085_ACCEL_TEST_ENABLED` supplies the default runtime-enabled state and
remains `0`, so normal images boot with the IMU held in reset. It can be enabled
live and persisted through the authenticated runtime endpoint. When enabled,
the task runs on core 0, resets the sensor, initializes SHTP/SH2, then drains
pending packets from the GPIO interrupt. The GPIO is deliberately configured as
active-level, not edge-only: on I2C the BNO08X deasserts `H_INTN` when its I2C
address is recognized, so the ISR masks the GPIO interrupt and the task rearms
it after draining the packet. The timeout is a missed-interrupt fallback.

The service has bounded startup retries, soft/hard recovery, and a stall reset
when reports stop for five seconds. Samples are kept in bounded local rings
(using PSRAM where configured) before they are exported; `/status` exposes
report, packet, IRQ, timeout, read/parse error, ring-overwrite, telemetry,
recovery, and current-value counters.

### BNO085 Runtime Commands

All BNO085 controls use `POST /config/runtime` and require `X-OTA-Token`.
Changes are saved in NVS and applied immediately by starting, stopping, or
reconfiguring the service; no ESP32 reboot is required.

| Parameter | Accepted value | Effect |
| --- | --- | --- |
| `bno085` | Runtime boolean | Enables or disables the service. `bno085_accel` is an alias. |
| `bno085_sample_hz` | Integer `1..500` Hz | Converts the requested frequency to the nearest whole-millisecond interval, clamped to at least `2 ms`. This is the dashboard control. |
| `bno085_sample_ms` | Integer `2..60000` ms | Sets the accelerometer interval directly. Alias for the interval field. |
| `bno085_accel_interval_ms` | Integer `2..60000` ms | Sets the accelerometer interval directly. |
| `bno085_log_interval_ms` | Integer `2..60000` ms | Sets the human-readable summary-log interval; it does not change the binary sample rate. |

Send only one of the three sample-rate forms in a request. If both
`bno085_sample_hz` and `bno085_sample_ms` are present, handler order makes the
millisecond value win, which is valid but unnecessarily ambiguous.

```sh
# Enable the validated maximum-rate profile.
curl -X POST -H "X-OTA-Token: <APP_OTA_PASSWORD>" \
  "http://<module-ip>/config/runtime?bno085=1&bno085_sample_hz=500"

# Reduce acceleration to 100 Hz while keeping 1 Hz summary logs.
curl -X POST -H "X-OTA-Token: <APP_OTA_PASSWORD>" \
  "http://<module-ip>/config/runtime?bno085=1&bno085_sample_ms=10&bno085_log_interval_ms=1000"

# Stop the service and hold the sensor in reset.
curl -X POST -H "X-OTA-Token: <APP_OTA_PASSWORD>" \
  "http://<module-ip>/config/runtime?bno085=0"
```

Runtime enable/disable is applied live through `/config/runtime` and the
dashboard Settings tab. If BNO085 is disabled, firmware does not keep an
accelerometer task polling a variable; it holds GPIO40 reset active. When BNO085
is enabled, the runtime endpoint starts the task directly. While the task is
running, GPIO15 interrupts, rate changes, and stop requests all wake it with
FreeRTOS task notifications (`INT`, `CONFIG`, `STOP`).

The dashboard Graphs tab plots accelerometer samples as soon as their wireless
telemetry arrives. Its `Timebase` control only changes the visible time window,
oscilloscope-style. `Samples/s` is the actual BNO085/report export rate; the
dashboard applies it as `bno085_sample_hz`, which updates the runtime
accelerometer interval. The running
BNO085 task picks up rate changes live by sending a new `Set Feature` command,
so no reboot is needed. The BNO08X datasheet lists
`Accelerometer` at a maximum configurable rate of 500 Hz, although I2C bandwidth
and wireless throughput still need to be considered in practice.
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

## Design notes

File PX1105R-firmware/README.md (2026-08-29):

# PX1105R GNSS firmware

This directory is the permanent index for PX1105R firmware used by the UWB
modules. GNSS firmware is released separately from ESP32/UWB firmware so that
the same receiver image is not duplicated in every UWB release.

## Recommended release

- Version: `01.07.33`
- Release: [PX1105R GNSS firmware 01.07.33](https://github.com/victorstoica114/UWB_Module_ESP_IDF/releases/tag/gps-px1105r-01.07.33)
- Release asset: `px1105r-firmware-01.07.33.zip`

The release archive contains the original PX1105R images, the validated loader
and packed image used by the ESP32-assisted update path, documentation, and
`SHA256SUMS`.

## ESP32-assisted update

The ESP32 firmware must include `components/gnss_firmware_updater`. From the
repository root, run:

```bash
python tools/gnss_firmware_update.py <ESP32-IP>
```

Only the ESP32 address changes. For the validated artifacts, expected receiver
version, and detailed update procedure, see [validated/README.md](validated/README.md).

## Release policy

- Each PX1105R firmware version receives its own `gps-px1105r-*` release.
- UWB firmware releases link to this index instead of duplicating GPS assets.
- When a newer GPS version is validated, update the recommended release above
  and retain older GPS releases for recovery and traceability.

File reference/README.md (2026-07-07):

# Reference Material

This folder is for legacy files and migration notes that are useful to keep,
but are not part of the active ESP-IDF build.

Active firmware code should live in `main/` or `components/`.

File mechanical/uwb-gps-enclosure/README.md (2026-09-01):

# Carcasă modulară UWB DWM3000 + GPS — prototip V4

V4 păstrează geometria radio/GPS validată în V3 și montează mufa USB-C mamă și
întrerupătorul DPDT într-o nișă retrasă, integrată în laterala carcasei.

Proiectul este construit parametric în CadQuery în jurul modelelor reale:

- `reference_models/modul_radio/UWB.step`;
- `reference_models/antena_gps/YN-91A_refined_v04_assembly.step`;
- `reference_models/acumulator.jpg`.

Fișierele gata de print sunt în `exports`. Pentru imprimare se recomandă
fișierele cu sufixul `_PRINT.stl`; fișierele STEP păstrează geometria CAD.

## Modificările V4

- comenzile nu mai sunt sub carcasă;
- baza cu țintă este un singur disc uniform Ø122 × 5 mm, fără pilotul central
  suprapus;
- o bază alternativă pentru trepied păstrează diametrul de 122 mm și pozițiile
  celor patru magneți, este îngroșată uniform la 8 mm, are chamfer 1 mm pe
  ambele muchii exterioare și filet real 3/8"-16 UNC;
- ținta are patru decupaje străpunse într-o fereastră Ø38 mm, separate de o
  cruce de calibrare de 1 mm pentru poziționare precisă;
- cele patru perechi de magneți au fost mutate de pe raza 19 mm pe raza 44 mm
  și rotite cu 45° pentru stabilitate și degajarea prinderilor interioare;
- USB-C și întrerupătorul sunt stivuite vertical într-o nișă laterală;
- panoul comenzilor este retras cu 12 mm față de marginea nișei;
- în exterior rămâne o proeminență de 3 mm în centru și maximum 7,5 mm la
  marginile ramei;
- plafonul nișei este arcuit pentru imprimare progresivă, fără o consolă
  orizontală mare;
- rama pornește de pe patul de printare și are drenaj inferior;
- mufa USB-C este ghidată și oprită din interiorul corpului;
- toate prinderile care foloseau șuruburi autofiletante au fost convertite la
  M3 cu inserții termice;
- cele două tălpi M3 laterale sunt retrase spre spate și au blocuri de sprijin
  până la podea, flanșe late și nervuri triunghiulare înalte, în stilul
  modificării manuale furnizate;
- o a treia talpă M3, cu două nervuri, leagă centrul peretelui posterior al
  tăvii de un al treilea bosaj din podeaua corpului;
- pragul interior al gulerului și suportul circular al tăvii GPS au tranziții
  autoportante la 45°, pentru a evita suportul continuu pe circumferință;
- suportul GPS are patru brațe și patru distanțiere coaxiale cu găurile reale
  măsurate din STEP: rază 42,5 mm și găuri Ø2,6 mm; fiecare distanțier primește
  o inserție termică M2,5;
- trei degajări radiale rotunjite, cu joc de 0,8 mm, permit suportului GPS să
  coboare drept printre bosajele inserțiilor capacului;
- în jurul celor trei degajări, lobi Ø28 mm reproduc exact ranforsările din
  modelul manual al lui Alex și măresc secțiunea de material a zonelor înguste.

Corpurile rigide ale USB-C și întrerupătorului sunt în interiorul cilindrului.
Numai fețele de acces sunt vizibile în nișă, iar maneta modelată rămâne cu 3 mm
în spatele marginii exterioare.

## Reperul UWB și orientarea componentelor

- placa este verticală, cu DWM3000 sus și mufa SMA jos;
- ESP32 nu este folosit ca reper de poziționare;
- centrul blocului ceramic al antenei DWM3000 este pe X=0, Y=0 față de țintă;
- marginea inferioară a PCB-ului este la 40 mm de podeaua interioară;
- între partea superioară a ansamblului radio și placa „floare” a antenei GPS
  sunt 50 mm;
- antena GPS este orizontală și întoarsă cu fața cerută în sus;
- acumulatorul de 48,5 × 25 × 73 mm este vertical, în spatele plăcii, între
  Z=6,5 și Z=79,5 mm;
- zona mufei SMA are o degajare de 18 × 50 mm, verificată cu un volum de gardă
  Ø15 mm.

## Piese printabile

1. `01_baza_tinta_PRINT.stl` — disc magnetic monolitic Ø122 × 5 mm, cu țintă
   decupată pentru vizualizarea podelei.
2. `02_corp_inferior_PRINT.stl` — corpul cilindric, nișa laterală arcuită,
   ghidajul USB-C, drenajul și locașurile pentru inserții.
3. `03_sasiu_pcb_acumulator_PRINT.stl` — suportul PCB și tava acumulatorului.
4. `04_retainer_acumulator_PRINT.stl` — retainerul acumulatorului.
5. `05_guler_superior_PRINT.stl` — gulerul superior și suportul tăvii GPS.
6. `06_suport_antena_gps_PRINT.stl` — tava antenei GPS cu patru locașuri pentru
   inserții M2,5, patru brațe, distanțiere de 5,07 mm și trei degajări
   ranforsate.
7. `07_capac_palarie_PRINT.stl` — capacul de ploaie.
8. `08_baza_trepied_PRINT.stl` — disc magnetic alternativ Ø122 × 8 mm, cu filet
   elicoidal real 3/8"-16 UNC și locaș pentru flanșă.

Ansamblul complet este:
`exports/UWB_carcasa_modulara_ansamblu_verificare.step`.

## Elemente de asamblare

- 8 magneți disc Ø10 × 2 mm;
- încă 4 magneți disc Ø10 × 2 mm dacă ambele baze interschimbabile sunt
  echipate simultan;
- un șurub sau o inserție metalică pentru trepied cu filet 3/8"-16 UNC,
  lungime de maximum 7 mm și flanșă Ø9,5 × 1,2 mm;
- 9 inserții termice filetate M3, măsurate Ø3,0 mm pe corp, Ø4,0 mm peste
  striații și 5,0 mm lungime;
- 4 inserții termice filetate M2,5, măsurate Ø3,0 mm pe corp, Ø3,5 mm peste
  striații și 5,0 mm lungime;
- 3 șuruburi M3 × 8 mm pentru șasiu;
- 3 șuruburi M3 × 8 mm pentru gulerul superior;
- 3 șuruburi M3 × 8 mm pentru capac;
- 4 șuruburi M2,5 × 6–8 mm pentru antena GPS;
- bandă dublu-adezivă de aproximativ 1 mm pentru placa radio;
- bandă dublu-adezivă pentru baza cu țintă;
- adeziv pentru magneți compatibil cu materialul printat.

Parametrii impliciți pentru prinderi sunt:

- gaură de trecere M3: Ø3,4 mm;
- locaș inserție M3: Ø3,7 × 5,8 mm;
- intrare de centrare M3: Ø4,1 × 0,8 mm;
- locaș inserție M2,5: Ø3,2 × 5,3 mm;
- intrare de centrare M2,5: Ø3,6 × 0,6 mm;
- canal pentru vârful șurubului M2,5: Ø2,8 mm;
- bosaj standard: Ø9 mm;
- locaș cap șurub: Ø6,5 mm.

Pentru baza de trepied, piesa filetată se montează dinspre fața opusă
magneților. Flanșa intră într-un locaș Ø9,8 × 1,35 mm și rămâne la nivelul
feței discului. Filetul din plastic este modelat elicoidal 3/8"-16 UNC, cu pas
1,5875 mm, unghi de 60°, diametru major de degajare Ø9,78 mm și diametru minor
Ø8,08 mm. Lungimea filetată utilă este de 5,80 mm, aproximativ 3,65 spire.
Inserția de 7 mm se oprește cu 1 mm înaintea feței cu magneții.

Dimensiunile inserțiilor diferă între producători. Valorile curente sunt
adaptate măsurătorilor lui Alex; înaintea unui nou lot de inserții se recomandă
o probă și ajustarea parametrilor `m3_insert_*` și `m25_insert_*`.

Găurile antenei GPS sunt Ø2,6 mm în modelul furnizat. M3 nu poate trece prin ele
fără găurirea antenei, de aceea această singură prindere folosește M2,5.
Inserțiile M2,5 se montează de sus în cele patru distanțiere, iar sub fiecare
locaș rămâne un canal Ø2,8 mm pentru vârful șurubului. Centrele suportului coincid
cu centrele STEP cu abatere calculată 0,000 mm.

## Poziția inserțiilor termice

- 3 inserții verticale în bosajele din podeaua corpului, pentru șasiu;
- 3 inserții radiale în corp, pentru guler;
- 3 inserții radiale în guler, pentru capac;
- 4 inserții verticale M2,5 în distanțierele suportului GPS.

Inserțiile trebuie montate înainte de introducerea electronicii. Pentru cele
radiale se recomandă folosirea unui vârf de letcon dedicat, menținut coaxial cu
locașul.

## Ordinea recomandată de montaj

1. Printează o probă pentru magnet, inserție, USB-C și axul întrerupătorului.
2. Montează cele 9 inserții M3 și cele 4 inserții M2,5.
3. Introdu USB-C din interior în ghidajul nișei și fixează întrerupătorul prin
   panoul retras.
4. Lipește placa pe șasiu cu bandă de 1 mm, cu DWM3000 sus și SMA jos.
5. Montează acumulatorul și retainerul, apoi fixează șasiul cu trei M3 × 8 mm.
6. Conectează cablurile, păstrând o rază mare de curbură pentru coaxialul GPS.
7. Coboară suportul GPS drept prin guler, cu cele trei degajări aliniate la
   bosajele capacului, până când se așază pe pragul circular.
8. Fixează antena GPS prin cele patru găuri coaxiale cu șuruburi M2,5.
9. Montează gulerul și capacul cu câte trei șuruburi M3 × 8 mm.
10. Pentru montarea pe trepied, înșurubează piesa 3/8"-16 UNC în baza
    `08_baza_trepied`, dinspre fața opusă magneților, până când flanșa este la
    nivel.
11. Lipește baza cu țintă pe podea sau montează baza pe trepied și cuplează
    magnetic ansamblul.

## Recomandări de printare

- ASA pentru utilizare la exterior; PETG este o alternativă bună;
- duză 0,4 mm, strat 0,20 mm;
- minimum 3 pereți și 4 straturi sus/jos;
- infill 20–30% în zonele cu inserții;
- corpul și gulerul se imprimă vertical;
- nișa arcuită și rama care pornește de la bază reduc necesarul de suport;
- capacul și retainerul sunt deja întoarse în fișierele `_PRINT.stl`;
- gulerul superior se așază cu manșonul lat pe pat; cele două praguri interioare
  au racordări la 45° și păstrează diametrele funcționale;
- șasiul poate necesita brim și suport local.
- baza de trepied se imprimă cu fața locașului flanșei pe pat și locașurile
  magneților în sus; pentru zona centrală se recomandă minimum 5 pereți și
  40% infill;
- filetul 3/8"-16 se imprimă mai curat la strat de 0,16–0,20 mm și viteză mică
  pe pereții interiori; dacă este prea strâns, mărește parametrul
  `tripod_thread_major_d` în pași de 0,10 mm.

## Verificări incluse

`exports/verification.txt` și `exports/manifest.json` confirmă:

- toate cele 8 piese au câte un singur solid BREP valid;
- lipsa interferențelor între PCB, acumulator, GPS și carcasă;
- lipsa interferențelor USB-C/întrerupător cu corpul;
- axa antenei DWM3000 este centrată pe țintă;
- distanțele de 40 mm și 50 mm sunt păstrate;
- antena GPS rămâne rotită cu 180°;
- cele patru găuri GPS sunt pe raza 42,5 mm, cu eroare maximă de centrare
  0,000 mm;
- distanțierele GPS se opresc la 0,10 mm sub placa antenei;
- sunt prevăzute 9 inserții termice M3 și 4 inserții termice M2,5;
- șasiul are trei puncte de prindere: două urechi laterale retrase și
  ranforsate până la podea, plus o ureche posterioară cu două nervuri;
- cele două praguri circulare descendente ale gulerului au tranziții
  autoportante la 45°, cu diametrele de centrare neschimbate;
- suportul GPS rămâne un singur solid, iar coborârea sa axială prin guler,
  verificată din 0,5 în 0,5 mm, are intersecție maximă 0,000 mm³;
- geometria ranforsărilor suportului GPS coincide boolean cu STEP-ul modificat
  manual: diferență 0,000 mm³ în ambele sensuri;
- panoul este retras 12 mm, iar proeminența exterioară maximă este 7,5 mm.
- baza este un disc uniform cu un singur solid, ținta este străpunsă, iar
  buzunarele magneților sunt pe raza 44 mm cu minimum 11,875 mm material până
  la marginea exterioară.
- baza de trepied este un disc uniform Ø122 × 8 mm, folosește aceleași patru
  poziții pentru magneți și păstrează inserția de 7 mm complet între fețe;
- ambele muchii exterioare ale bazei de trepied au chamfer 1 × 1 mm;
- flanșa are 0,30 mm joc diametral și 0,15 mm joc pe adâncime;
- filetul 3/8"-16 este elicoidal, are pas 1,5875 mm, 5,80 mm lungime utilă și
  0,255 mm joc diametral la diametrul major nominal.

## Previzualizări

- `previews/01_ansamblu_exterior.png`;
- `previews/02_ansamblu_transparent.png`;
- `previews/03_piese_explodate.png`;
- `previews/04_aliniere_axa_uwb.png`;
- `previews/05_detaliu_sma_acumulator_coborat.png`;
- `previews/06_baza_tinta_diametru_complet.png`;
- `previews/07_nisa_laterala_comenzi.png`;
- `previews/08_aliniere_gauri_antena_gps.png`;
- `previews/09_talpi_sasiu_ranforsate.png`;
- `previews/10_talpa_dreapta_sasiu_ranforsata.png`;
- `previews/11_baza_tinta_decupata_vedere_sus.png`;
- `previews/12_prinderi_sasiu_trei_puncte.png`;
- `previews/13_racordari_interioare_fdm_45deg.png`;
- `previews/14_trecere_suport_gps_printre_bosaje.png`;
- `previews/15_ranforsari_decupaje_suport_gps.png`;
- `previews/16_baza_trepied_filet_3_8.png`;
- `previews/17_baza_trepied_fata_magneti.png`;
- `previews/18_filet_trepied_sectionat.png`.

Carcasa folosește suprapuneri și protecții geometrice împotriva ploii, dar nu
este etanșă la imersie și nu are un grad IP certificat.

## Regenerare

```powershell
python -m venv .venv
.\.venv\Scripts\python.exe -m pip install -r requirements.txt
.\.venv\Scripts\python.exe .\generate_enclosure.py
.\.venv\Scripts\python.exe .\render_previews.py
```

Toate cotele importante sunt centralizate în clasa `P` din
`generate_enclosure.py`.

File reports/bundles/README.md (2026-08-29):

# Report bundles

Each directory here corresponds one-to-one with a final PDF in `../`. A bundle
contains the remaining sources, derived analysis, retained figures and RAW
evidence for that report. The final PDF is not duplicated inside the bundle.

| Bundle | Final PDF |
|---|---|
| `ds_twr_speed_limit_20260726` | [`../ds_twr_speed_limit_20260726.pdf`](../ds_twr_speed_limit_20260726.pdf) |
| `imu_fusion_ablation_20260811` | [`../imu_fusion_ablation_20260811.pdf`](../imu_fusion_ablation_20260811.pdf) |
| `imu_fusion_validation_20260811` | [`../imu_fusion_validation_20260811.pdf`](../imu_fusion_validation_20260811.pdf) |
| `native_ds_round_boundary_20260731` | [`../native_ds_round_boundary_20260731.pdf`](../native_ds_round_boundary_20260731.pdf) |
| `native_ds_speed_revalidation_20260731` | [`../native_ds_speed_revalidation_20260731.pdf`](../native_ds_speed_revalidation_20260731.pdf) |
| `passive_ds_known_geometry_20260727` | [`../passive_ds_known_geometry_20260727.pdf`](../passive_ds_known_geometry_20260727.pdf) |
| `passive_ds_pipeline_20260728` | [`../passive_ds_pipeline_20260728.pdf`](../passive_ds_pipeline_20260728.pdf) |
| `passive_ds_speed_limit_20260727` | [`../passive_ds_speed_limit_20260727.pdf`](../passive_ds_speed_limit_20260727.pdf) |
| `uwb_dynamic_static_comparison_20260806` | [`../uwb_dynamic_static_comparison_20260806.pdf`](../uwb_dynamic_static_comparison_20260806.pdf) |
| `uwb_dynamic_static_comparison_20260812` | [`../uwb_dynamic_static_comparison_20260812.pdf`](../uwb_dynamic_static_comparison_20260812.pdf) |
| `uwb_dynamic_static_comparison_20260813` | [`../uwb_dynamic_static_comparison_20260813.pdf`](../uwb_dynamic_static_comparison_20260813.pdf) |
| `uwb_gps_rtk_comparison_20260803` | [`../uwb_gps_rtk_comparison_20260803.pdf`](../uwb_gps_rtk_comparison_20260803.pdf) |
| `uwb_protocol_comparison_20260726` | [`../uwb_protocol_comparison_20260726.pdf`](../uwb_protocol_comparison_20260726.pdf) |

`RAW_SHA256SUMS` verifies every retained file below the bundle `raw/`
directories.

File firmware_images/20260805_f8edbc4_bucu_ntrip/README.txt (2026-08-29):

UWB ESP32-S3 firmware image

Source commit: f8edbc419398b75f9ff4a0e5a12b0a2230a21153
Source state:  f8edbc4
ESP-IDF:       v6.0.2
Built at:      2026-08-05T08:03:21+03:00

This image contains the validated BUCU00ROU0 NTRIP transport fix, including
incremental HTTP chunk decoding. The compiled binaries contain device and NTRIP
configuration and must be treated as sensitive. This directory is ignored by
Git.

Clean full restore over USB:
  python -m esptool --chip esp32s3 write-flash 0x0 uwb_full_flash.bin

Normal network update:
  python tools/ota_upload.py --firmware uwb_ota.bin --target-list tools/ota_targets.local.txt --parallel 5

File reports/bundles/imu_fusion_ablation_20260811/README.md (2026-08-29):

# `imu_fusion_ablation_20260811` bundle

Final report: [`../../imu_fusion_ablation_20260811.pdf`](../../imu_fusion_ablation_20260811.pdf)

- `source/`: report sources, notes and helper scripts;
- `analysis/`: generated metrics and manifests;
- `figures/`: retained PNG/SVG figures;
- `raw/`: retained captures and metadata.

RAW integrity is covered by [`../RAW_SHA256SUMS`](../RAW_SHA256SUMS).

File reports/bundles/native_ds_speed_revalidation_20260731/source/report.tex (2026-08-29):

\documentclass[11pt,a4paper]{article}

\usepackage[T1]{fontenc}
\usepackage[utf8]{inputenc}
\usepackage[english]{babel}
\usepackage{lmodern}
\usepackage{microtype}
\usepackage[a4paper,margin=20mm,headheight=15pt]{geometry}
\usepackage{graphicx}
\usepackage{booktabs}
\usepackage{tabularx}
\usepackage{longtable}
\usepackage{array}
\usepackage{xcolor}
\usepackage{amsmath}
\usepackage{caption}
\usepackage{float}
\usepackage{enumitem}
\usepackage{fancyhdr}
\usepackage[hidelinks]{hyperref}
\usepackage{xurl}

\graphicspath{{figures/}}
\definecolor{controlblue}{HTML}{2563EB}
\definecolor{acceptedgreen}{HTML}{16A34A}
\definecolor{rejectedred}{HTML}{DC2626}
\definecolor{amber}{HTML}{D97706}
\definecolor{slate}{HTML}{334155}
\definecolor{lightgray}{HTML}{F1F5F9}

\newcommand{\dstwr}{DS-TWR}
\newcommand{\code}[1]{\texttt{\detokenize{#1}}}
\newcolumntype{Y}{>{\raggedright\arraybackslash}X}

\pagestyle{fancy}
\fancyhf{}
\lhead{\small Native DS-TWR speed-limit revalidation}
\rhead{\small July 31, 2026}
\cfoot{\thepage}

\hypersetup{
  pdftitle={Native DS-TWR speed-limit revalidation},
  pdfauthor={UWB ESP-IDF technical report},
  pdfsubject={Fresh static precision, raw-range integrity, and speed-boundary study},
  pdfkeywords={UWB, DS-TWR, DW3000, ESP32-S3, ranging, precision, integrity}
}

\begin{document}
\pagenumbering{gobble}

\begin{titlepage}
  \centering
  \vspace*{15mm}
  {\Huge\bfseries Native \dstwr{} speed-limit revalidation\par}
  \vspace{4mm}
  {\Large Fresh throughput, precision, and raw-range integrity study\par}
  \vspace{15mm}

  \begin{tabular}{rl}
    Test date: & July 31, 2026, EEST\\
    Platform: & 5 ESP32-S3 + DW3000 modules, Raspberry Pi 5\\
    Branch: & \texttt{experiment/passive-ds-twr-pipeline}\\
    Dashboard source: & \texttt{8244a3432f68}\\
    Active firmware identity: & \texttt{54a586c-dirty}\\
    Configuration: & M1 tag; M2, M3, M4, M5 anchors\\
    Radio: & UWB channel 5\\
    Environment: & unchanged static indoor setup\\
  \end{tabular}

  \vfill
  \colorbox{lightgray}{%
    \begin{minipage}{0.88\textwidth}
      \vspace{3mm}
      \textbf{Key result.}
      The \textbf{60 ms} profile is the fastest setting that completed the
      decisive 180 s validation with \textbf{zero impossible raw ranges}.
      It delivered \textbf{11.63 coherent independent frames/s} and
      \textbf{61.96 rolling display updates/s}, with
      \textbf{1.38 cm precision RMS} and \textbf{2.39 cm CEP95}.
      Relative to the fresh 410 ms control, this is a
      \textbf{6.75$\times$ coherent-frame speedup} for only
      \textbf{+1.6\% RMS} and \textbf{+3.9\% CEP95}.
      The otherwise excellent-looking 59 ms profile was rejected because it
      produced a physically impossible $-5.301$ m raw range.
      \vspace{3mm}
    \end{minipage}}
  \vfill
  {\large Reproducible updated field report\par}
  \vspace{5mm}
\end{titlepage}

\pagenumbering{roman}
\tableofcontents
\clearpage
\pagenumbering{arabic}

\section{Executive summary}

This report revalidates the native three-message \dstwr{} speed limit after
restoring the low-noise ranging behavior and capturing a new slow control on
the same physical setup. The exchange remains strictly
\texttt{POLL--RESP--FINAL}. No temporal filter, moving average, position
smoothing, or additional radio message is used in the offline comparison.

The study contains 17 capture blocks, 1,860.8 s of data, and 156,935 raw
tag-to-anchor ranges. It first repeats the dashboard profiles from 410 ms down
to 13 ms, then narrows the transition using 49, 57, 58, 59, 60, 61, and
64 ms candidates. Decisive profiles use 180 s blocks; short 60 s screens are
used only to reject obviously unsafe settings or select the next candidate.

\begin{table}[H]
  \centering
  \caption{Main fresh results. Precision is measured around each unfiltered
  coherent-position series' own mean.}
  \small
  \begin{tabular}{lrrrrrr}
    \toprule
    Profile & Coherent & Rolling & Delivery & RMS & CEP95 & Raw anomalies\\
    \midrule
    410 ms control & 1.72 Hz & 9.16 Hz & 94.11\% & 1.36 cm & 2.30 cm & 0\\
    64 ms reserve & 10.92 Hz & 58.14 Hz & 94.03\% & 1.38 cm & 2.41 cm & 0\\
    \textcolor{acceptedgreen}{\textbf{60 ms recommended}}
      & \textbf{11.63 Hz} & \textbf{61.96 Hz} & \textbf{93.97\%}
      & \textbf{1.38 cm} & \textbf{2.39 cm} & \textbf{0}\\
    \textcolor{rejectedred}{59 ms rejected}
      & 11.82 Hz & 62.78 Hz & 93.75\% & 1.31 cm & 2.20 cm & 1\\
    \textcolor{rejectedred}{58 ms rejected}
      & 12.00 Hz & 63.48 Hz & 93.32\% & 1.35 cm & 2.30 cm & 2\\
    \bottomrule
  \end{tabular}
\end{table}

\paragraph{Decision.}
Use 60 ms as the fastest currently validated precision profile. Use 64 ms
when an additional millisecond of reserve per anchor slot is preferred.
Retain 410 ms only as a slow control. Treat every profile below 60 ms as an
experimental stress test: their central position distributions can remain
tight while rare timestamp failures generate impossible raw distances.

\section{Why the recommendation changed}

The July 26 report recommended 17 ms and treated 13 ms as the measured
maximum. That report faithfully described the complete-position and timing
statistics available in its original capture. The present result does not
erase that historical data; it changes the operating recommendation for the
current firmware and validation criterion.

Three differences matter:

\begin{enumerate}[leftmargin=8mm]
  \item the low-noise native \dstwr{} implementation was recovered and a fresh
  410 ms control was captured on the unchanged current setup;
  \item the current dashboard maintains live anchor geometry and distinguishes
  rolling estimates from strict coherent four-anchor frames;
  \item most importantly, every raw range is now audited before solver or
  frame-assembly rejection. Negative ranges and deviations greater than
  10 cm from the per-anchor median are counted even when they do not visibly
  disturb the position trail.
\end{enumerate}

The new audit found impossible raw measurements at 33, 29, 25, 21, 17, and
13 ms. Their coherent RMS and CEP95 still look comparable to the control.
Position precision alone is therefore insufficient to qualify the radio
timing. The updated recommendation requires both tight central precision and
clean raw timestamp integrity.

\section{System and protocol}

\subsection{Native three-frame DS-TWR}

For each anchor, the tag sends \texttt{POLL}, the anchor returns
\texttt{RESP}, and the tag sends \texttt{FINAL}. The anchor combines its
hardware receive/transmit timestamps with the tag timestamps embedded in the
final message and estimates propagation time as

\begin{equation}
  \widehat{T}_{\mathrm{prop}} =
  \frac{R_aR_b-D_aD_b}{R_a+D_a+R_b+D_b},
\end{equation}

where $R_a,R_b$ are round-trip intervals and $D_a,D_b$ are reply delays.
Antenna-delay calibration and the instantaneous carrier-integrator correction
remain enabled. They correct physical timestamp behavior and are not temporal
position filters.

\subsection{Frame and geometry scheduler}

The tag visits anchors A2, A3, A4, and A5 sequentially. The base tag-ranging
frame is

\begin{equation}
  T_{\mathrm{base}} = 4T_{\mathrm{slot}} + T_{\mathrm{gap}}.
\end{equation}

The current implementation also inserts one rotating anchor-to-anchor
geometry-maintenance slot every four base frames. With a 1 ms command delay,
the average scheduler period is approximately

\begin{equation}
  T_{\mathrm{avg}} =
  T_{\mathrm{base}} +
  \frac{T_{\mathrm{slot}}+1\ \mathrm{ms}}{4}.
\end{equation}

This maintenance exchange keeps the displayed physical geometry live and is
included in measured throughput. It is one reason the measured strict
coherent-frame rate is lower than $1/T_{\mathrm{base}}$.

\subsection{Coherent frames and rolling updates}

A coherent independent position uses four ranges assigned to one complete
anchor round. A rolling position is recomputed whenever a new range arrives,
using the latest still-fresh ranges from the other anchors. Rolling updates
provide low display latency, but adjacent estimates share measurements and
must not be interpreted as statistically independent frames.

At 60 ms, the dashboard can produce 61.96 rolling updates/s while the strict
offline assembler identifies 11.63 complete independent frames/s. Both rates
are reported so display responsiveness is not confused with independent
measurement throughput.

\section{Experimental method}

\subsection{Geometry and unchanged setup}

All captures use the same cached measured geometry:

\begin{center}
\begin{tabular}{lrr}
  \toprule
  Anchor & $x$ [m] & $y$ [m]\\
  \midrule
  A2 & 0.000 & 0.000\\
  A3 & 0.000 & 3.067\\
  A4 & 2.971 & $-0.071$\\
  A5 & 3.196 & 2.974\\
  \bottomrule
\end{tabular}
\end{center}

The stored tag reference is the anchor centroid,
$(1.54175,1.49250)$ m. Because this coordinate is derived from cached
geometry rather than an independent survey of the tag location, the report
uses dispersion around each capture mean as its primary precision metric.
Absolute bias fields are retained in \path{summary.json} but are not presented
as independently verified absolute accuracy.

Active antenna delays remained M1=16363, M2=16368, M3=16362, M4=16371, and
M5=16371. No module was physically moved during the sweep. Runtime profile
changes were applied to all five modules in parallel, followed by reboot and
warm-up.

\subsection{Fresh control and boundary search}

The sequence was:

\begin{enumerate}[leftmargin=8mm]
  \item capture a new 180 s 410 ms precision control;
  \item validate the existing 64, 33, and 29 ms profiles for 180 s and screen
  25, 21, 17, and the true 13 ms profile for 60 s;
  \item test intermediate 49, 57, 58, 60, and 61 ms candidates for 60 s;
  \item perform decisive 180 s validations at 58, 59, and 60 ms.
\end{enumerate}

The short 58 ms screen was clean, but its 180 s validation produced two
impossible ranges. Likewise, the 29 ms screen was clean and its long
validation failed. These two cases demonstrate why short visual screening
cannot establish reliability.

\subsection{Acceptance criteria}

A candidate is accepted only if:

\begin{itemize}[leftmargin=7mm]
  \item the decisive 180 s block contains no negative raw distance;
  \item no raw distance differs by more than 10 cm from that anchor's capture
  median;
  \item coherent RMS and CEP95 remain within 20\% of the 410 ms control;
  \item all five modules remain online with stable sequence delivery.
\end{itemize}

The 10 cm threshold is an integrity alarm, not the claimed localization
accuracy. Every rejected boundary event was several metres beyond that limit.
No range is made acceptable merely because a later solver ignores it.

\subsection{Metrics}

The offline reconstruction uses unweighted all-anchor linear trilateration and
no temporal filtering. Precision RMS is

\begin{equation}
  \mathrm{RMS}_{\mathrm{precision}} =
  \sqrt{\frac{1}{N}\sum_{i=1}^{N}
  \left\lVert \mathbf{p}_i-\overline{\mathbf{p}}\right\rVert^2}.
\end{equation}

CEP50 and CEP95 are the corresponding 50th and 95th percentiles of radial
deviation from the capture mean. Sequence delivery is the fraction of observed
16-bit range sequences within the capture span. Raw integrity is calculated
directly from every \texttt{UWB\_RANGING result} record.

\section{Results}

\subsection{Update rate and scheduler yield}

\begin{figure}[H]
  \centering
  
  \caption{Measured coherent and rolling update rates, plus the yield of each
  stream relative to its ideal average scheduler rate. An asterisk marks a
  profile that failed raw-integrity validation. Colors retain the metric
  meanings shown in the legend.}
\end{figure}

The 60 ms profile yields a 6.75$\times$ coherent-frame speedup and a
6.77$\times$ rolling-update speedup over the 410 ms control. Sequence delivery
changes by only $-0.14$ percentage points. The lower timing profiles raise
apparent update rate, but raw integrity fails. In the lower panel, coherent
yield is the observed independent-frame rate divided by the ideal
geometry-adjusted frame rate. Rolling yield uses four ideal display updates
per complete tag-ranging frame. The difference quantifies how shared
fresh-range updates remain responsive even when strict four-range frames are
incomplete.

\subsection{Central precision}

\begin{figure}[H]
  \centering
  
  \caption{Unfiltered coherent-position dispersion. The rejected profiles
  are marked with an asterisk but still have deceptively good RMS and CEP95.
  Colors retain the RMS/CEP95 meanings shown in the legend.}
\end{figure}

The 60 ms coherent RMS is 1.3766 cm, compared with 1.3555 cm at 410 ms:
+0.0211 cm or +1.56\%. CEP95 changes from 2.2987 to 2.3892 cm:
+0.0905 cm or +3.94\%. These are small differences relative to ordinary
between-capture variation.

\begin{figure}[H]
  \centering
  
  \caption{Empirical CDF of radial coherent-position deviation from each
  capture mean. The accepted 410, 64, and 60 ms distributions nearly overlap.}
\end{figure}

The CDF confirms that the recommended 60 ms setting preserves the complete
shape of the static precision distribution rather than only its RMS summary.

\subsection{Raw-range integrity}

\begin{figure}[H]
  \centering
  
  \caption{Impossible measurements per 10,000 raw ranges, counted before any
  frame or solver rejection.}
\end{figure}

The accepted 410, 64, and 60 ms captures contain no raw anomaly. Every
existing dashboard profile below 60 ms produces at least one impossible
measurement in its fresh capture. At 17 ms, 13 negative ranges and 15 total
spikes appear in 11,467 observations; at 13 ms, the counts rise to 20 and 22
in 14,303 observations.

\begin{figure}[H]
  \centering
  
  \caption{All A2 raw deviations during the decisive 58, 59, and 60 ms
  validations. The symlog axis preserves centimetre-scale noise and
  metre-scale failures in the same figure.}
\end{figure}

The boundary result is unusually sharp. The 58 ms profile produced two
negative A2 ranges, the 59 ms profile produced one, and the otherwise
identical 60 ms profile produced none. All three use 14 ms anchor slots,
8 ms RX timeout, and 2+2 ms response/final delays. Only the frame gap changes:
2, 3, and 4 ms respectively.

\subsection{Accepted per-anchor stability}

\begin{figure}[H]
  \centering
  
  \caption{Raw range standard deviation for the three accepted profiles.}
\end{figure}

The accepted profiles retain approximately 1--2 cm raw standard deviation per
anchor. The 60 ms values are 1.19 cm (A2), 1.12 cm (A3), 1.23 cm (A4), and
1.79 cm (A5). There is no broad noise inflation as the frame period falls
from 410 to 60 ms.

\section{Interpretation and recommendation}

\subsection{Observed limiting mechanism}

The data do not show a gradual accuracy-versus-speed tradeoff near the
boundary. Central RMS is actually slightly lower at 59 ms than at 60 ms.
Instead, rare metre-scale failures appear while the ordinary range population
remains centimetre-stable.

Because 58, 59, and 60 ms use the same 14 ms slot and exchange delays, while
only the inter-frame gap changes, the evidence strongly implicates insufficient
recovery margin between rounds. Every decisive boundary failure is emitted by
A2, the first anchor in the configured list. This pattern is consistent with a
round-boundary timestamp or radio-state race, but the present field data do
not prove the exact firmware instruction or DW3000 state responsible.

The correct engineering response is therefore to retain a clean timing margin,
not to add a position filter that hides the symptom. Instrumenting the
round transition and validating an explicit timestamp sanity check remain
useful future firmware tasks.

\subsection{Recommended profiles}

\paragraph{Default: 60 ms precision-speed limit.}
Use 14 ms slots, 4 ms frame gap, 8 ms RX timeout, 2 ms response delay, 2 ms
final delay, 100 ms anchor RX slice, and 500 UUS auto-RX delay. This is the
fastest profile with a clean 180 s raw audit.

\paragraph{Reserve: 64 ms.}
Use 15 ms slots and the same 4/8/2/2 ms gap/timeout/response/final values.
It loses about 6\% coherent throughput relative to 60 ms but also passed its
180 s capture with zero raw anomalies.

\paragraph{Control: 410 ms.}
Use 100 ms slots, 10 ms gap, 90 ms timeout, and 20+20 ms delayed
transmissions only when reproducing the slow precision baseline. It is no
longer justified as the normal operating profile.

\paragraph{Experimental profiles below 60 ms.}
They remain available in the dashboard for controlled investigation, but are
now marked rejected or experimental. Their high rolling-update numbers must
not be presented as validated reliable positioning throughput.

\section{Limits of inference and next tests}

This is a strict static revalidation at one favorable point, not a complete
localization qualification. The 60 ms decision applies to the tested modules,
firmware state, channel, anchor order, geometry, and host load. It does not yet
establish:

\begin{itemize}[leftmargin=7mm]
  \item multi-hour probability of a rare boundary failure;
  \item performance while the tag translates or rotates;
  \item behavior near or outside the anchor perimeter;
  \item NLOS, human blockage, or severe multipath performance;
  \item sensitivity to Wi-Fi/dashboard load, temperature, or supply voltage;
  \item behavior with a different first anchor or additional modules.
\end{itemize}

The next validation should run 60 and 64 ms for at least one hour, alternate
their order, and repeat with A2 moved away from the first slot. A controlled
dynamic trajectory should then compare coherent latency and precision. If
sub-60 ms operation remains important, add per-stage round-transition
timestamps and an explicit hardware-timestamp validity guard before changing
the estimator or adding filters.

\clearpage
\appendix

\section{Complete profile table}

\begin{longtable}{rrrrrrrrr}
  \caption{Fresh aggregate results. Durations are 180 s unless marked
  60 s screen.}\\
  \toprule
  Frame & Duration & Coherent & Rolling & Delivery & RMS & CEP95 & Neg. & Spikes\\
  \midrule
  \endfirsthead
  \toprule
  Frame & Duration & Coherent & Rolling & Delivery & RMS & CEP95 & Neg. & Spikes\\
  \midrule
  \endhead
  410 & 180 s & 1.72 & 9.16 & 94.11\% & 1.36 & 2.30 & 0 & 0\\
  64 & 180 s & 10.92 & 58.14 & 94.03\% & 1.38 & 2.41 & 0 & 0\\
  60 & 180 s & 11.63 & 61.96 & 93.97\% & 1.38 & 2.39 & 0 & 0\\
  59 & 180 s & 11.82 & 62.78 & 93.75\% & 1.31 & 2.20 & 1 & 1\\
  58 & 180 s & 12.00 & 63.48 & 93.32\% & 1.35 & 2.30 & 2 & 2\\
  57 & 60 s & 12.21 & 64.37 & 93.02\% & 1.38 & 2.42 & 1 & 1\\
  49 & 60 s & 17.61 & 74.26 & 92.46\% & 1.30 & 2.25 & 1 & 1\\
  33 & 180 s & 20.42 & 107.21 & 90.61\% & 1.33 & 2.33 & 7 & 9\\
  29 & 180 s & 23.37 & 119.09 & 88.92\% & 1.43 & 2.46 & 13 & 19\\
  25 & 60 s & 27.09 & 137.28 & 89.28\% & 1.43 & 2.47 & 2 & 2\\
  21 & 60 s & 33.34 & 157.85 & 87.90\% & 1.43 & 2.53 & 4 & 4\\
  17 & 60 s & 39.77 & 191.04 & 87.14\% & 1.34 & 2.35 & 13 & 15\\
  13 & 60 s & 44.99 & 238.12 & 85.30\% & 1.38 & 2.36 & 20 & 22\\
  \bottomrule
\end{longtable}

Coherent and rolling columns are updates/s. RMS and CEP95 are centimetres.
Spikes count all raw distances more than 10 cm from the corresponding
per-anchor median and include the negative observations.

\section{Timing profiles}

\begin{table}[H]
  \centering
  \small
  \begin{tabular}{rrrrrr}
    \toprule
    Frame & Slot & Gap & RX timeout & RESP delay & FINAL delay\\
    \midrule
    410 & 100 & 10 & 90 & 20 & 20\\
    64 & 15 & 4 & 8 & 2 & 2\\
    60 & 14 & 4 & 8 & 2 & 2\\
    59 & 14 & 3 & 8 & 2 & 2\\
    58 & 14 & 2 & 8 & 2 & 2\\
    57 & 14 & 1 & 8 & 2 & 2\\
    49 & 12 & 1 & 8 & 2 & 2\\
    33 & 8 & 1 & 5 & 2 & 2\\
    29 & 7 & 1 & 5 & 2 & 2\\
    25 & 6 & 1 & 5 & 2 & 2\\
    21 & 5 & 1 & 5 & 2 & 2\\
    17 & 4 & 1 & 4 & 1 & 1\\
    13 & 3 & 1 & 3 & 1 & 1\\
    \bottomrule
  \end{tabular}
  \caption{Runtime values in milliseconds. RX slice is 100 ms and automatic
  RX delay is 500 UUS for every row.}
\end{table}

\section{Files and reproduction}

\small
\begin{tabularx}{\textwidth}{p{62mm}Y}
  \toprule
  File/directory & Contents\\
  \midrule
  \path{README.md} & fresh 410 ms control identity and precision reference\\
  \path{PROFILE_REVALIDATION.md} & concise findings and boundary decision\\
  \path{profile_comparison.csv} & machine-readable aggregate table\\
  \path{candidate_*ms_validation/data/*.jsonl} & retained RAW event streams
  for the decisive 58/59/60 ms boundary\\
  \path{*/data/*.metadata.json} & full initial/final module status and runtime
  configuration\\
  \path{*/positions.csv} & unfiltered coherent and rolling reconstructions\\
  \path{*/summary.json} & complete per-capture metrics\\
  \path{*/raw_quality.json} & per-anchor raw integrity audit\\
  \path{*/SHA256SUMS} & historical hashes for the original capture files\\
  \path{figures/} & report plots in vector PDF and PNG\\
  \bottomrule
\end{tabularx}

\paragraph{Reproduction}
The repository uses an aggressive retention policy: the current figure
generator can rebuild the published plots from the three retained boundary
event streams and the derived per-profile artifacts. Re-auditing every
profile from its original RAW stream is no longer possible.
\begin{verbatim}
cd /home/pi/Documents/UWB
python3 tools/uwb_native_ds_speed_revalidation_report.py
cd reports/native_ds_speed_revalidation_20260731
latexmk -pdf -interaction=nonstopmode -halt-on-error report.tex
\end{verbatim}

\begin{thebibliography}{9}

\bibitem{qorvo-api}
Qorvo, \emph{DW3xxx Device Driver API Guide}, double-sided two-way-ranging
examples, 2025.
\url{https://forum.qorvo.com/uploads/short-url/xD3TlXKvkujjdUaJWXv2b4E7GQN.pdf}.

\bibitem{aps013}
Decawave, \emph{APS013: DW1000 and Two-Way Ranging}, rev. 2.3,
Poll--Response--Final and the asymmetric DS-TWR formula.
\url{https://forum.qorvo.com/uploads/short-url/x34DrF7EW5fQP9wY3aNESqPKz8z.pdf}.

\bibitem{firmware}
Local repository \emph{UWB Module ESP-IDF}, branch
\texttt{experiment/passive-ds-twr-pipeline}, dashboard source
\texttt{8244a3432f68caf23d604e475cbe718698c4ab2f}, active module firmware
identity \texttt{54a586c-dirty}, field state from July 31, 2026.

\end{thebibliography}

\end{document}

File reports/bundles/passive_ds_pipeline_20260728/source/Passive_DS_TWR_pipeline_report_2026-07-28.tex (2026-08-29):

\documentclass[11pt,a4paper]{article}
\usepackage[margin=21mm]{geometry}
\usepackage[T1]{fontenc}
\usepackage{lmodern}
\usepackage{microtype}
\usepackage{booktabs}
\usepackage{graphicx}
\usepackage{hyperref}
\usepackage{xcolor}
\usepackage{placeins}
\usepackage{enumitem}
\hypersetup{
  colorlinks=true,
  linkcolor=blue,
  urlcolor=blue,
  pdftitle={Passive DS-TWR Deadline Pipeline and Rolling Solver Field Validation}
}
\graphicspath{{figures/}}

\title{Passive DS-TWR Deadline Pipeline\\and Rolling Solver Field Validation}
\author{UWB Module ESP-IDF field test}
\date{28 July 2026}

\begin{document}
\maketitle

\begin{abstract}
This report validates the non-blocking DW3000 deadline pipeline and the
low-latency rolling position solver added to the custom receive-only Passive
DS-TWR protocol. In a static surveyed geometry, deadline scheduling increased
independent position throughput from approximately 63 to 84 updates/s without
an observed accuracy regression. Rolling solving preserved the independent
frame rate while increasing total display updates to 169/s. The deadline
pipeline also reduced combined RESP/FINAL timeout counts by approximately
73\% and removed the large anchor-range bursts present in the legacy
millisecond/blocking scheduler during this test.
\end{abstract}

\section{Objective}

The previous Passive DS-TWR speed-limit study identified the radio transaction
and millisecond receive-loop scheduling path as the principal bottleneck. It
recommended four changes:
\begin{enumerate}[itemsep=2pt,topsep=3pt]
\item instrument POLL TX, delayed RESP TX, FINAL TX/RX, CIA readout, and RX
re-arm;
\item replace millisecond receive-loop scheduling with DW3000 delayed-TX and
deadline-driven state transitions;
\item retain Robust Rotating at 1.0/1.0 ms as the accuracy control;
\item evaluate rolling solves as a distinct low-latency display mode while
reporting independent frames/s separately.
\end{enumerate}

Firmware \texttt{7226cca} implements those changes. The purpose of this field
test is to determine whether they improve speed without sacrificing static
accuracy or destabilising the radio schedule.

\section{Experimental method}

Five modules were flashed once in one simultaneous OTA operation. Four anchors
formed the known \(3\,\mathrm{m}\times3\,\mathrm{m}\) reference square:
A2 \(=(0,0)\), A3 \(=(0,3)\), A4 \(=(3,0)\), and A5 \(=(3,3)\) m. Tag 1
was stationary at the surveyed centre, \((1.5,1.5)\) m. Dynamic anchor
self-localisation remained active, matching the intended operational system
rather than forcing fixed dashboard coordinates.

Every test used Robust Rotating with 1.0 ms RESP and 1.0 ms FINAL timing.
Four 60 s blocks, each preceded by a 10 s warm-up, formed an A--B--C--A
sequence:
\begin{description}
\item[A1] Legacy receive loop, one solve per complete frame;
\item[B] deadline pipeline, one solve per complete frame;
\item[C] deadline pipeline, rolling solves capped at 100 Hz;
\item[A2] return to the Legacy control.
\end{description}

Positions were captured from the dashboard's lossless event stream. Raw solver
and constant-velocity EKF outputs were retained separately. Accuracy for the
rolling block is calculated only from its complete independent-frame
solutions; correlated intermediate rolling results are not counted as
additional independent accuracy samples.

\section{Throughput}

\begin{table}[htbp]
\centering
\small
\begin{tabular}{lrrrr}
\toprule
Mode & independent & rolling & total solver & independent\\
 & frames/s & updates/s & updates/s & samples\\
\midrule
Legacy + Frame A1 & 62.54 & -- & 62.54 & 3,753\\
Deadline + Frame & 84.12 & -- & 84.12 & 5,053\\
Deadline + Rolling & 84.38 & 84.76 & 169.14 & 5,066\\
Legacy + Frame A2 & 63.24 & -- & 63.24 & 3,799\\
\bottomrule
\end{tabular}
\caption{Measured position throughput over each 60 s capture.}
\end{table}

\begin{figure}[htbp]
\centering

\caption{Independent frame rate and additional correlated rolling updates.
The rolling solver approximately doubles display refresh while leaving radio
frame throughput unchanged.}
\end{figure}

Deadline scheduling increased independent frame throughput by 34.5\% over A1.
The A2 return control reproduced the Legacy rate, which supports attributing
the gain to the new scheduling pipeline rather than a transient change in
network or dashboard performance. Enabling the rolling solver changed the
independent rate from 84.12 to 84.38 frames/s; consequently, there is no
measured evidence that the added solver work slows the ranging path.

\FloatBarrier
\section{Static position accuracy}

\begin{table}[htbp]
\centering
\small
\begin{tabular}{lrrrrrr}
\toprule
Mode & \multicolumn{2}{c}{EKF error [cm]} &
\multicolumn{2}{c}{raw error [cm]} &
\multicolumn{2}{c}{EKF bias [cm]}\\
\cmidrule(lr){2-3}\cmidrule(lr){4-5}\cmidrule(lr){6-7}
 & RMSE & P95 & RMSE & P95 & \(x\) & \(y\)\\
\midrule
Legacy + Frame A1 & 3.59 & 5.51 & 3.87 & 6.17 & +0.30 & -3.12\\
Deadline + Frame & 3.23 & 5.09 & 3.59 & 5.92 & +1.04 & -2.47\\
Deadline + Rolling & 3.01 & 4.72 & 3.28 & 5.32 & -0.05 & -2.43\\
Legacy + Frame A2 & 5.12 & 7.29 & 5.35 & 8.04 & +1.62 & -4.50\\
\bottomrule
\end{tabular}
\caption{Position errors relative to the surveyed centre. Deadline + Rolling
uses only independent-frame solutions in this accuracy table.}
\end{table}

\begin{figure}[htbp]
\centering

\caption{Filtered and raw accuracy. The raw results confirm that the accepted
deadline result is not solely an EKF artefact.}
\end{figure}

\begin{figure}[htbp]
\centering

\caption{Empirical CDF of filtered 2-D position error.}
\end{figure}

\begin{figure}[htbp]
\centering

\caption{Filtered position clouds relative to the surveyed centre.}
\end{figure}

\FloatBarrier
\subsection{Confidence-band acceptance}

A moving-block bootstrap with 3,000 iterations was used to retain temporal
correlation. The acceptance rule requires both the candidate point RMSE and
P95 to remain no greater than the upper 95\% confidence bound of the
same-geometry control.

\begin{table}[htbp]
\centering
\small
\begin{tabular}{lrrrrl}
\toprule
Comparison & metric & control & control upper & candidate & result\\
 & & [cm] & 95\% bound [cm] & [cm] &\\
\midrule
Deadline Frame vs Legacy A1 & RMSE & 3.59 & 3.71 & 3.23 & accepted\\
 & P95 & 5.51 & 5.76 & 5.09 & accepted\\
Rolling frames vs Deadline Frame & RMSE & 3.23 & 3.36 & 3.01 & accepted\\
 & P95 & 5.09 & 5.30 & 4.72 & accepted\\
\bottomrule
\end{tabular}
\caption{Predefined accuracy gates.}
\end{table}

Both candidate configurations pass. These data demonstrate no observed
accuracy regression; they do not yet prove that deadline scheduling improves
accuracy in all conditions. The captures were sequential and the live geometry
estimator continued to evolve.

\section{Radio-pipeline diagnostics}

\begin{table}[htbp]
\centering
\small
\begin{tabular}{lrrrrrrr}
\toprule
Mode & complete & RESP TO & FINAL TO & collision & overrun &
invalid & re-arm fail\\
\midrule
Legacy + Frame A1 & 23,791 & 1,914 & 619 & 0 & 0 & 0 & 0\\
Deadline + Frame & 32,128 & 408 & 277 & 672 & 39 & 0 & 0\\
Deadline + Rolling & 32,585 & 305 & 275 & 620 & 41 & 0 & 0\\
\bottomrule
\end{tabular}
\caption{Counters accumulated across all modules during each 60 s interval.
TO denotes timeout.}
\end{table}

\begin{figure}[htbp]
\centering

\caption{Completed exchanges and timeout counts.}
\end{figure}

Compared with Legacy A1, Deadline + Frame completed approximately 35\% more
exchanges and reduced combined RESP/FINAL timeout counts from 2,533 to 685,
a reduction of approximately 73\%. No invalid frame or RX re-arm failure was
reported. CIA readout averaged approximately 25--42 \(\mu\)s across modules,
while RX re-arm averaged 38--46 \(\mu\)s.

The deadline schedule exposes state collisions and rare schedule overruns that
were not explicit counters in the Legacy path. They remain useful optimisation
targets, but did not prevent the measured throughput gain. Timer alarm counts
are normal deadline wake-ups and are not failure events.

\FloatBarrier
\section{Anchor-geometry stability}

\begin{figure}[htbp]
\centering

\caption{Standard deviation of raw anchor-pair DS-TWR ranges.}
\end{figure}

Deadline + Frame kept every anchor-pair standard deviation at or below
1.78 cm. Both Legacy captures contained intermittent bursts. In A2, standard
deviation reached 9.27 cm on A2--A3, 11.81 cm on A2--A5, and 7.62 cm on
A4--A5. These bursts explain the degraded A2 position cloud and match the
short-lived geometry deformations previously observed in the dashboard.

Mean anchor-pair biases of several centimetres remain. They are a separate
antenna/pair-calibration issue and should not be attributed to deadline
scheduling. The present experiment evaluates relative scheduling behaviour,
not a new absolute calibration.

\FloatBarrier
\section{Conclusions}

\begin{enumerate}[itemsep=2pt,topsep=3pt]
\item The DW3000 deadline pipeline reaches approximately
\textbf{84 independent positions/s}, essentially the previously observed
FlexTDOA target rate, while keeping the native 1.0/1.0 ms radio timing.
\item Both filtered and raw accuracy gates pass. No accuracy concession was
required to obtain the throughput gain.
\item Rolling solving delivers approximately \textbf{169 display updates/s}
without reducing independent frame throughput. Its additional results are
correlated and must continue to be reported separately.
\item Deadline scheduling materially reduces timeout counts and anchor-range
bursts. This should also improve the stability of live anchor self-localisation.
\item Remaining work should focus on the recorded state collisions, rare
schedule overruns, and static pair/antenna bias calibration. A longer
randomised or interleaved field campaign is required before claiming a general
accuracy improvement.
\end{enumerate}

\medskip
\noindent\textbf{Operational state and reproducibility.}
All modules were left online in Deadline + Rolling at 100 Hz with Robust
Rotating 1.0/1.0 ms; the dashboard remained active. The report directory
retains the four event streams and metadata consumed by the generator, plus
bootstrap outputs and metrics. Raw dashboard log streams were removed under
the 2026-08-29 aggressive retention policy.

\end{document}

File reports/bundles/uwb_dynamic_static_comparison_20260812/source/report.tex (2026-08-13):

\documentclass[10pt,a4paper]{article}
\usepackage{lmodern}
\usepackage[margin=19mm]{geometry}
\usepackage{booktabs}
\usepackage{graphicx}
\usepackage[table]{xcolor}
\usepackage[hidelinks]{hyperref}
\usepackage{parskip}
\usepackage{array}
\graphicspath{{figures/}}
\definecolor{warning}{HTML}{FFF3CD}
\definecolor{info}{HTML}{E0F2FE}
\hypersetup{pdftitle={Dynamic and static comparison of three UWB protocols},pdfauthor={UWB ESP-IDF technical report}}
\begin{document}
\begin{titlepage}
\centering
\vspace*{18mm}
{\Huge\bfseries Dynamic and static UWB comparison\par}
\vspace{4mm}
{\Large FlexTDOA, Native DS-TWR and Passive DS-TWR\par}
\vspace{14mm}
{\large Final field campaign of August 12, 2026\par}
\vspace{12mm}
\begin{tabular}{rl}
Platform: & 5 ESP32-S3 + DW3000 modules, Raspberry Pi collector\\
Topology: & M1 tag; M2, M3, M4 and M5 anchors\\
Radio: & UWB channel 9; configured 40 MHz SPI\\
Firmware branch: & \texttt{localization-raw-calibration}\\
UWB evidence: & six complete August 12 JSONL captures; raw and position-only EKF\\
RTK evidence: & GPS-only reference captures from August 6\\
\end{tabular}
\vfill
\colorbox{info}{\parbox{0.88\textwidth}{\vspace{2mm}
\textbf{Main result.} All three protocols produced complete raw dynamic and
static datasets. Independent dynamic rates are approximately 25.0 Hz Flex,
25.4 Hz Native and 22.6 Hz Passive. Raw static RMS is 2.3--2.4 cm. The
position-only adaptive EKF materially reduces static jitter and dynamic
sample-to-sample spikes, while raw UWB remains the permanent audit stream.\vspace{2mm}}}
\vfill
{\large Reproducible technical report\par}
\end{titlepage}
\pagenumbering{roman}
\tableofcontents
\clearpage
\pagenumbering{arabic}

\section{Executive summary}
\colorbox{warning}{\parbox{0.96\textwidth}{\textbf{Evidence boundary.}
Stream rates, uptime gaps, sample counts, fusion acceptance and reset counts are
direct August 12 diagnostics. GPS RTK quality and precision use only the August
6 reference captures. The two sessions are not time-paired, so this report does
not calculate or claim August 12 absolute UWB--RTK position error.}}

Passive DS overlapping raw windows remain visible in the telemetry rate, while
all comparative precision and trajectory metrics use independent frames.
Interleaved records marked \texttt{imu\_fused=true} are excluded from raw UWB
metrics. Outliers are retained.

The dynamic independent rates were \textbf{25.01 positions/s} for FlexTDOA, \textbf{25.35 positions/s} for Native DS-TWR, and \textbf{22.63 positions/s} for Passive DS-TWR. Passive DS emitted 70.11 dashboard events/s, but those include overlapping windows.

The static raw local RMS values were \textbf{2.41 cm} (FlexTDOA), \textbf{2.45 cm} (Native DS-TWR) and \textbf{2.26 cm} (Passive DS-TWR). These are precision around each capture median, not absolute accuracy.

The UWB and RTK evidence populations are intentionally separated: no August 6
UWB positions enter the protocol results, and no August 12 GPS samples enter
the RTK section. The new filter uses positions only: this campaign intentionally
does not claim acceleration-derived position improvement.

\section{Scope and questions}
The campaign asks how many independent positions each protocol delivers, where
stream gaps occur, how stable the unfiltered stationary position is, and whether
the position-only adaptive EKF reduces visible jitter without hiding raw UWB.

The RTK reference was acquired in a separate session. It establishes receiver
fix availability and short-term precision, but it cannot be paired sample by
sample with the August 12 UWB walks or used as an absolute-error ground truth.

\section{System and protocol background}
\subsection{FlexTDOA}
The tag is UWB receive-only. Anchor transmissions form directed time-difference
observations and the tag solves from a recent coherent observation set. Radio
airtime is largely independent of the number of passive tags.

\subsection{Native DS-TWR}
The active tag exchanges poll, response and final messages with every anchor,
obtains four absolute ranges and solves a coherent frame. Airtime grows with
active tag count, but frame semantics are direct.

\subsection{Passive DS-TWR}
The tag listens to anchor-to-anchor DS-TWR exchanges. Rolling windows may
produce several publications from shared measurements, so dashboard events and
independent frames are intentionally reported separately.

\section{Test configuration and captured evidence}
The three operator-marked dynamic walks lasted 85--114 s and the stationary
blocks approximately 30 s. The selector uses the final continuous-capture
segments and the final short static capture for each protocol.
\begin{center}\scriptsize\resizebox{\textwidth}{!}{%
\begin{tabular}{lrrrrrrrr}\toprule
\textbf{Protocol} & \textbf{Mode} & \textbf{Capture ID} & \textbf{duration s} & \textbf{events} & \textbf{independent} & \textbf{indep Hz} & \textbf{coverage pct} & \textbf{complete} \\
\midrule
FlexTDOA & dynamic & flextdoa\_final\_dynamic\_20260812 & 84.6 & 2117 & 2117 & 25.01 & 99.7 & yes \\
Native DS-TWR & dynamic & native\_ds\_final\_dynamic\_20260812 & 113.5 & 2876 & 2876 & 25.35 & 98.7 & yes \\
Passive DS-TWR & dynamic & passive\_ds\_final\_dynamic\_20260812 & 106.5 & 7463 & 2409 & 22.63 & 100.0 & yes \\
FlexTDOA & static & flextdoa\_static\_final\_01 & 30.3 & 798 & 798 & 26.30 & 98.8 & yes \\
Native DS-TWR & static & native\_ds\_static\_final\_02\_rtk\_fixed & 30.1 & 780 & 780 & 25.89 & 99.6 & yes \\
Passive DS-TWR & static & passive\_ds\_static\_final\_01 & 31.2 & 1906 & 607 & 19.45 & 96.2 & yes \\
\bottomrule\end{tabular}}\end{center}
Every selected block has a terminal \texttt{capture\_end}. All raw data are
archived losslessly and identified by SHA-256.

\section{Methodology}
\subsection{Population and continuity}
No error-based trimming or temporal smoothing is applied. Rates use full
capture wall time. Gaps are positive differences between unique ESP32 uptime
values; P50/P95/P99, maximum and counts above 100 ms are retained together.

\subsection{Static precision}
Radial displacement is computed around each block's component-wise position
median. CEP50, RMS, P95, P99, maximum, 2DRMS and first-to-last-decile drift use
all independent samples. They describe repeatability, not offset from truth.

\subsection{RTK reference}
Only quality-4 fixes from the August 6 reference captures enter the RTK section.
WGS84 is converted through ECEF to one local ENU frame for that session. No
cross-session timestamp association or UWB--RTK rigid fit is performed.

\section{Dynamic results}
\subsection{Raw trajectories}
The walks are separate physical trials, not synchronized repeats. The panels
therefore show continuity and gross geometry rather than point-by-point route
agreement.

\begin{figure}[htbp]
\centering

\caption{August 12 raw independent UWB trajectories in each local frame. Green markers are anchors; no August 6 UWB positions are used.}
\end{figure}
\subsection{Update rate and gaps}
\begin{center}\scriptsize\resizebox{\textwidth}{!}{%
\begin{tabular}{lrrrrrrrr}\toprule
\textbf{Protocol} & \textbf{duration s} & \textbf{events} & \textbf{independent} & \textbf{event Hz} & \textbf{indep Hz} & \textbf{gap P95 ms} & \textbf{gap max ms} & \textbf{step P95 m/s} \\
\midrule
FlexTDOA & 84.6 & 2117 & 2117 & 25.01 & 25.01 & 70 & 830 & 6.04 \\
Native DS-TWR & 113.5 & 2876 & 2876 & 25.35 & 25.35 & 50 & 130 & 7.15 \\
Passive DS-TWR & 106.5 & 7463 & 2409 & 70.11 & 22.63 & 30 & 250 & 4.66 \\
\bottomrule\end{tabular}}\end{center}
\begin{figure}[htbp]
\centering

\caption{Independent position rate in the selected dynamic and static blocks. Passive DS all-event publications are not substituted for independent frames.}
\end{figure}

\begin{figure}[htbp]
\centering

\caption{P95 positive gap between unique position uptimes. Maximum gaps and counts remain in the tables.}
\end{figure}

Native DS-TWR delivered the highest independent rate (25.35 Hz) and the best
worst-case continuity (130 ms). FlexTDOA was close in rate (25.01 Hz), but its
maximum gap was 830 ms. Passive DS delivered 22.63 independent Hz despite
overlapping dashboard publications, with a 250 ms maximum gap. Step speed is a
sample-to-sample trajectory diagnostic, not measured walking speed.

\subsection{Complete continuity audit}
\begin{center}\scriptsize\resizebox{\textwidth}{!}{%
\begin{tabular}{lrrrrrrrr}\toprule
\textbf{Protocol} & \textbf{Mode} & \textbf{event Hz} & \textbf{indep Hz} & \textbf{P50 ms} & \textbf{P95} & \textbf{P99} & \textbf{max} & \textbf{>100 ms} \\
\midrule
FlexTDOA & dynamic & 25.01 & 25.01 & 30 & 70 & 130 & 830 & 28 \\
Native DS-TWR & dynamic & 25.35 & 25.35 & 40 & 50 & 70 & 130 & 2 \\
Passive DS-TWR & dynamic & 70.11 & 22.63 & 10 & 30 & 80 & 250 & 28 \\
FlexTDOA & static & 26.30 & 26.30 & 30 & 70 & 100 & 120 & 7 \\
Native DS-TWR & static & 25.89 & 25.89 & 40 & 50 & 60 & 80 & 0 \\
Passive DS-TWR & static & 61.06 & 19.45 & 10 & 40 & 72 & 130 & 6 \\
\bottomrule\end{tabular}}\end{center}

\section{Position-only adaptive EKF}
The dashboard EKF uses only the raw UWB position stream. IMU acceleration is
disabled, raw measurements remain archived separately, and each EKF result in
this report comes from the same position event as its raw counterpart.
Sample-to-sample step-speed P95 is a jitter/continuity diagnostic; it is not
physical walking speed. Static RMS is repeatability about each stream's own
median. No cross-session RTK error is attached to the filter results.
\begin{center}\scriptsize\resizebox{\textwidth}{!}{%
\begin{tabular}{lrrrrrr}\toprule
\textbf{Protocol} & \textbf{Mode} & \textbf{coverage pct} & \textbf{raw step P95} & \textbf{EKF step P95} & \textbf{raw static RMS cm} & \textbf{EKF static RMS cm} \\
\midrule
FlexTDOA & dynamic & 100.0 & 6.04 & 4.31 & n/a & n/a \\
Native DS-TWR & dynamic & 100.0 & 7.15 & 3.44 & n/a & n/a \\
Passive DS-TWR & dynamic & 100.0 & 4.66 & 4.50 & n/a & n/a \\
FlexTDOA & static & 100.0 & 1.97 & 0.36 & 2.41 & 1.07 \\
Native DS-TWR & static & 100.0 & 1.61 & 0.23 & 2.45 & 0.89 \\
Passive DS-TWR & static & 100.0 & 1.62 & 0.00 & 2.26 & 0.00 \\
\bottomrule\end{tabular}}\end{center}
\begin{figure}[htbp]
\centering

\caption{Raw independent dynamic trajectory (blue) and the position-only adaptive EKF (green). The EKF reduces high-frequency corners without replacing archived raw data.}
\end{figure}

\begin{figure}[htbp]
\centering

\caption{Static raw and EKF clouds, each centered on its own median and plotted at one common scale. Passive DS may collapse to a held point while stationary by design.}
\end{figure}

\section{Static results}
\subsection{Raw local precision}
\begin{center}\scriptsize\resizebox{\textwidth}{!}{%
\begin{tabular}{lrrrrrrrr}\toprule
\textbf{Protocol} & \textbf{N} & \textbf{CEP50 cm} & \textbf{RMS cm} & \textbf{P95 cm} & \textbf{P99 cm} & \textbf{max cm} & \textbf{2DRMS cm} & \textbf{drift cm} \\
\midrule
FlexTDOA & 798 & 1.91 & 2.41 & 4.30 & 5.73 & 7.38 & 4.81 & 0.82 \\
Native DS-TWR & 780 & 1.72 & 2.45 & 3.95 & 8.81 & 12.30 & 4.84 & 0.67 \\
Passive DS-TWR & 607 & 1.88 & 2.26 & 3.94 & 4.93 & 5.52 & 4.53 & 0.38 \\
\bottomrule\end{tabular}}\end{center}
\begin{figure}[htbp]
\centering

\caption{Static precision around each block's own median. All independent raw samples are included.}
\end{figure}

\begin{figure}[htbp]
\centering

\caption{Static raw position clouds centered on their own medians and drawn at one common scale. The cross is the median.}
\end{figure}

All raw static RMS values lie in a narrow 2.26--2.45 cm range. Passive DS is
best on RMS, while Native and Passive share the best P95 near 3.94 cm. All
outliers are retained. One stationary point cannot characterize GDOP or
spatial bias across the anchor polygon.

\section{GPS RTK reference from August 6}
This section contains GPS data only. It characterizes RTK availability and
short-term scatter for the unchanged receiver path; it does not reuse the old
UWB trajectories and it is not synchronized with the August 12 walks.
\begin{center}\scriptsize\resizebox{\textwidth}{!}{%
\begin{tabular}{lrrrrrrrrr}\toprule
\textbf{Protocol} & \textbf{Mode} & \textbf{tag total} & \textbf{tag fixed} & \textbf{tag fixed pct} & \textbf{all modules fixed pct} & \textbf{fix-age P95 ms} & \textbf{fixed anchors} & \textbf{tag cloud RMS cm} & \textbf{tag cloud P95 cm} \\
\midrule
FlexTDOA & dynamic & 24 & 24 & 100.0 & 93.0 & 96 & 4 & 284.65 & 482.34 \\
Native DS-TWR & dynamic & 30 & 28 & 93.3 & 55.9 & 96 & 3 & 334.51 & 487.56 \\
Passive DS-TWR & dynamic & 26 & 25 & 96.2 & 72.2 & 106 & 4 & 367.91 & 625.14 \\
FlexTDOA & static & 119 & 119 & 100.0 & 91.4 & 100 & 4 & 0.52 & 0.85 \\
Native DS-TWR & static & 119 & 119 & 100.0 & 86.3 & 100 & 4 & 0.74 & 1.15 \\
Passive DS-TWR & static & 119 & 102 & 85.7 & 93.0 & 130 & 4 & 1.40 & 2.02 \\
\bottomrule\end{tabular}}\end{center}
\begin{figure}[htbp]
\centering

\caption{August 6 GPS RTK Fixed tag solutions only. Top: each reference block centered on its own median. Bottom: the same fixes in the August 6 common ENU frame.}
\end{figure}

The trajectory panels below are GPS-only and remain in the August 6 ENU frame.
They are shown as a qualitative RTK reference, not overlaid on the August 12
UWB paths.

\begin{figure}[htbp]
\centering

\caption{August 6 GPS RTK Fixed dynamic reference trajectories. No UWB positions from that session are plotted.}
\end{figure}

\section{Accelerometer scope}
Acceleration-assisted positioning was disabled for this final campaign because
the preceding experiment did not improve raw UWB accuracy. The adaptive EKF
assessed above is position-only. Orientation/IMU telemetry is outside the
protocol ranking, and raw UWB remains the permanent audit stream.

\section{Protocol interpretation and selection}
\subsection{FlexTDOA}
Near-25 Hz independent dynamic rate with a receive-only scalable tag. Static
raw RMS was 2.41 cm. The 830 ms maximum gap is the principal caveat.

\subsection{Native DS-TWR}
Clearest coherent-frame semantics, highest measured independent rate and best
maximum gap. Static raw RMS was 2.45 cm. It remains the preferred deterministic
baseline for a small number of active tags.

\subsection{Passive DS-TWR}
Successfully follows motion without tag transmissions. Independent-frame
accounting yields 22.63 Hz despite overlapping publications; static raw RMS was
the best at 2.26 cm and the maximum dynamic gap was 250 ms.

\begin{center}\small
\begin{tabular}{p{0.20\textwidth}p{0.23\textwidth}p{0.23\textwidth}p{0.23\textwidth}}
\toprule
Criterion & FlexTDOA & Native DS-TWR & Passive DS-TWR\\
\midrule
Tag radio role & receive-only & active exchanges & receive-only\\
Dynamic independent rate & 25.01 Hz & best: 25.35 Hz & 22.63 Hz\\
Dynamic worst gap & 830 ms & best: 130 ms & 250 ms\\
Static raw precision & 2.41 cm RMS & 2.45 cm RMS & best: 2.26 cm RMS\\
Scaling with tag count & strongest & airtime grows & strong\\
Recommendation & primary scalable mode & coherent baseline & passive scalable alternative\\
\bottomrule
\end{tabular}
\end{center}

\section{Limitations}
\begin{itemize}
\item RTK is a separate August 6 reference session, not synchronized August 12 truth.
\item Cross-session UWB--RTK RMSE/P95 is intentionally not computed.
\item GNSS and UWB antenna phase centers have unknown lever arms.
\item Dynamic routes are not repeated surveyed paths; static/dynamic blocks are single trials.
\item One static point does not cover edge geometry, NLOS, orientation or spatial bias.
\item Collector rate is end-to-end telemetry, not direct DW3000 PHY throughput.
\end{itemize}

\section{Recommended next tests}
\begin{enumerate}
\item Repeat every protocol on one marked route with identical orientation and synchronized markers.
\item Interleave static blocks at the center, edges and outside the polygon.
\item Repeat the final UWB campaign with one simultaneous continuous RTK session.
\item Add hardware-correlated timestamps for latency claims.
\item Keep acceleration disabled until body-to-map yaw is independently validated.
\item Capture focused FlexTDOA diagnostics around gaps above 250 ms.
\end{enumerate}

\section{Preliminary findings}
\begin{itemize}
\item FlexTDOA remains a strong receive-only scalable mode, with one long-gap caveat.
\item Native DS-TWR is the best coherent-frame rate and continuity baseline.
\item Passive DS-TWR is a viable receive-only alternative when independent frames are counted correctly.
\item The cross-session RTK reference cannot support an August 12 absolute-accuracy ranking; local UWB precision is ranked.
\item The position-only EKF improves display stability; acceleration-assisted accuracy is not claimed.
\end{itemize}

\section{Reproduction and audit files}
The directory contains \texttt{analysis\_summary.json}, capture/replay/alignment
CSV files, SVG/PDF plots and this TeX source. The machine-readable summary
records whether optional lossless RAW archive generation was enabled; when it
is skipped, immutable source JSONL paths remain recorded for reproduction.

\begin{verbatim}
python tools/uwb_dynamic_static_report.py `
  --input-dir reports/uwb_final_report_input_20260812 `
  --output-dir reports/uwb_dynamic_static_comparison_20260812 `
  --rtk-reference-report-dir reports/uwb_dynamic_static_comparison_20260806
\end{verbatim}

No raw capture is modified during report generation.
\end{document}

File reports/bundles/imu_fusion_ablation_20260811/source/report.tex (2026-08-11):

\documentclass[10pt,a4paper]{article}
\usepackage{lmodern}
\usepackage[margin=18mm]{geometry}
\usepackage{booktabs}
\usepackage{graphicx}
\usepackage[table]{xcolor}
\usepackage[hidelinks]{hyperref}
\usepackage{parskip}
\usepackage{array}
\usepackage{enumitem}
\graphicspath{{figures/}}
\definecolor{warning}{HTML}{FFF3CD}
\definecolor{info}{HTML}{E0F2FE}
\definecolor{good}{HTML}{DCFCE7}
\definecolor{bad}{HTML}{FEE2E2}
\hypersetup{
  pdftitle={Dynamic and static UWB/IMU validation -- 11 August 2026},
  pdfauthor={UWB ESP-IDF technical report}
}
\setlist{nosep}
\begin{document}

\begin{titlepage}
\centering
\vspace*{16mm}
{\Huge\bfseries Dynamic and static UWB/IMU validation\par}
\vspace{4mm}
{\Large FlexTDOA, Native DS-TWR and Passive DS-TWR\par}
\vspace{11mm}
{\large Field campaign and controlled replay ablation -- 11 August 2026\par}
\vspace{12mm}
\begin{tabular}{rl}
Platform: & 5 ESP32-S3 + DW3000 modules; Raspberry Pi collector\\
Topology: & M1 tag; M2, M3, M4 and M5 anchors\\
Radio: & UWB channel 9; configured 40 MHz SPI\\
Firmware: & deployed \texttt{bb23b07-dirty}; analysis branch \texttt{imu-fusion-smoothing}\\
Sensor path: & BNO085 acquisition near 500 Hz; GPTimer timestamps\\
Evidence: & 3 dynamic + 3 static protocol captures; replay and ablation artifacts\\
\end{tabular}
\vfill
\colorbox{warning}{\parbox{0.89\textwidth}{\vspace{2mm}
\textbf{Main result.} Raw UWB remains the authoritative positioning stream.
The current fusion output can suppress isolated extremes, but controlled
replays show that the measurable improvement comes from the common position
smoother, not from accelerometer integration. The accelerometer contribution
is therefore \textbf{not accepted} for production accuracy claims.
\vspace{2mm}}}
\vfill
{\large Reproducible technical report\par}
\end{titlepage}

\pagenumbering{roman}
\tableofcontents
\clearpage
\pagenumbering{arabic}

\section{Executive summary}

This report is the complete counterpart of the 6 August protocol report. It
uses the same six-cell matrix (three protocols in dynamic and static modes),
the same independent-frame policy, the same local static precision metrics,
and the same RTK registration audit. It additionally contains the controlled
IMU ablation that is necessary to distinguish inertial information from
ordinary trajectory smoothing.

\colorbox{info}{\parbox{0.96\textwidth}{\textbf{Evidence boundary.}
Counts, rates, positive gaps and local static clouds are direct diagnostics.
Dynamic UWB--RTK errors are useful in-system comparisons, but the UWB packet
does not yet carry the radio measurement timestamp. Static absolute ranking is
invalid for the original three 30 s captures because their RTK centers differ
by 2.03 m and two anchor registrations are poor. No outlier was removed.}}

The principal results are:
\begin{itemize}
\item Static raw local RMS is \textbf{2.13 cm} for FlexTDOA,
      \textbf{2.02 cm} for Native DS-TWR and \textbf{1.78 cm} for Passive
      DS-TWR. These values measure repeatability around each capture median.
\item Dynamic independent rates are \textbf{12.90}, \textbf{20.86} and
      \textbf{13.33 positions/s}, respectively. Flex and Passive contain
      multi-second maximum gaps; Native contains a 1.02 s maximum gap.
\item On the controlled Native replay, raw RMSE is 17.911 cm. Disabling
      acceleration gives 16.323 cm; the current acceleration path gives
      16.326 cm. The difference is \textbf{+0.0031 cm}: acceleration provides
      no measurable improvement.
\item Passive gives an even stronger null result: disabled, current and
      relaxed acceleration configurations all produce 14.867 cm RMSE and
      29.389 cm P95 to the displayed precision.
\item A new Passive stationary control with the full 500 Hz telemetry path
      yields \textbf{2.710 cm raw RMSE versus RTK} and \textbf{1.711 cm local
      raw RMS}. The radio/solver path has therefore not suffered a general
      stationary regression from enabling high-rate IMU acquisition.
\end{itemize}

\section{Questions and acceptance criteria}

The campaign evaluates four separate questions:
\begin{enumerate}
\item Does each protocol continue to deliver raw positions at a useful rate?
\item What is the unfiltered stationary repeatability of each protocol?
\item Does the current fused output improve dynamic RMSE and P95 without
      increasing overshoot or hiding raw data?
\item Is any observed improvement caused by acceleration, rather than by the
      position smoother shared by all replay variants?
\end{enumerate}

The causal acceptance criterion is intentionally strict: acceleration must
beat an otherwise identical replay with acceleration disabled on both RMSE and
P95, without a worse maximum or new dead zones. A raw-versus-fused comparison
alone cannot prove an IMU gain because the fused branch also includes endpoint
smoothing, constant-velocity propagation, reacquisition logic and ZUPT.

\section{System and protocol background}

\subsection{FlexTDOA}
The tag is UWB receive-only. Anchors exchange scheduled transmissions and the
tag solves from a coherent set of time-difference observations. Airtime scales
well with passive tag count. The current capture includes both independent
frames and repeated/publication events; only independent frames enter fair
rate and trajectory metrics.

\subsection{Native DS-TWR}
The active tag ranges to every anchor and solves one coherent four-range frame.
It offers the clearest measurement semantics but consumes tag airtime. A frame
can be incomplete when one or more anchor exchanges miss their deadline.

\subsection{Passive DS-TWR}
The tag listens to anchor-to-anchor DS-TWR exchanges. Rolling windows can
publish multiple positions from shared measurements. Therefore all-event rate
and independent-frame rate are reported separately.

\subsection{IMU path under test}
BNO085 samples carry 64-bit GPTimer time into replay. Orientation association,
reordering and interpolation are available, and raw UWB remains permanently
separate. The filter can use constant-velocity propagation, position endpoint
smoothing, stationary bias estimation, ZUPT and yaw-conditioned horizontal
acceleration. That mixture is the reason for the controlled ablation.

\section{Captured evidence}

The selected dynamic walks lasted 177--243 s; the static blocks lasted about
30 s. The Passive dynamic JSONL lacks its final \texttt{capture\_end} record,
but its 177 s data span and replay are readable. It is included and explicitly
marked incomplete rather than silently discarded.

\begin{center}\scriptsize\resizebox{\textwidth}{!}{%
\begin{tabular}{lllrrrrrl}\toprule
\textbf{Protocol} & \textbf{Mode} & \textbf{capture ID} & \textbf{duration s} &
\textbf{events} & \textbf{independent} & \textbf{indep Hz} & \textbf{coverage \%} & \textbf{container}\\
\midrule
FlexTDOA & dynamic & flextdoa\_dynamic\_final\_01 & 240.5 & 4023 & 3101 & 12.90 & 99.4 & complete\\
Native DS-TWR & dynamic & native\_ds\_dynamic\_quality\_gate\_02 & 243.0 & 5069 & 5069 & 20.86 & 99.7 & complete\\
Passive DS-TWR & dynamic & passive\_ds\_dynamic\_final\_01 & 176.9 & 7033 & 2358 & 13.33 & 100.0 & missing capture\_end\\
FlexTDOA & static & flextdoa\_static\_final & 30.3 & 929 & 929 & 30.67 & 99.4 & complete\\
Native DS-TWR & static & native\_ds\_static\_final & 30.5 & 686 & 686 & 22.47 & 99.4 & complete\\
Passive DS-TWR & static & passive\_ds\_static\_final & 31.1 & 2295 & 772 & 24.80 & 99.1 & complete\\
\bottomrule\end{tabular}}
\end{center}

\section{Methodology}

\subsection{Population and continuity}
Interleaved records marked as fused are excluded from raw UWB metrics. Passive
and Flex publications are reduced to independent frames where the protocol
marks them. Rates use the full capture wall duration. Positive gaps are
differences between unique ESP32 uptime values; P50, P95, P99, maximum and
counts above 100 ms are retained.

\subsection{Static precision}
Raw radial displacement is calculated about the component-wise median of each
capture. CEP50, RMS, P95, P99, maximum, 2DRMS and first-to-last-decile drift
retain every independent sample. These metrics describe local repeatability,
not absolute accuracy.

\subsection{RTK association and frame registration}
Only quality-4 RTK Fixed fixes enter comparisons. WGS84 is converted to ENU. A
proper 2-D rigid rotation and translation (no scale) is fitted from anchor
geometry, never from the tag trajectory. UWB and RTK samples are associated in
software within 100 ms.

The measurement-time estimate currently subtracts reported GNSS fix age from
collector receive time. A separate audit found this estimate about 108--112 ms
late relative to GNSS UTC; correcting it explains roughly 5--6 cm of dynamic
RMSE for Flex and Native, but not the complete 15--18 cm error. The radio
measurement timestamp must be transmitted end-to-end before sub-decimetre
dynamic claims are treated as final.

\subsection{Controlled IMU ablation}
Raw, acceleration-disabled, current-gate and relaxed-gate configurations are
replayed on the same captured population. The disabled replay preserves the
same position smoother and constant-velocity machinery. Consequently,
\emph{current minus disabled} isolates the acceleration contribution much more
cleanly than \emph{fused minus raw}.

\section{Dynamic raw results}

\subsection{Trajectories}
The walks are separate physical trials rather than synchronized repetitions.
The panels are therefore used for continuity, jumps and gross geometry, not
point-by-point route ranking.

\begin{figure}[p]
\centering

\caption{Raw independent dynamic trajectories in each local UWB frame. Green
markers are anchors. Outliers are retained.}
\end{figure}

\subsection{Update rate and gaps}

\begin{center}\scriptsize\resizebox{\textwidth}{!}{%
\begin{tabular}{lrrrrrrrr}\toprule
\textbf{Protocol} & \textbf{event Hz} & \textbf{indep Hz} & \textbf{P50 ms} &
\textbf{P95 ms} & \textbf{P99 ms} & \textbf{max ms} & \textbf{$>$100 ms} & \textbf{step P95 m/s}\\
\midrule
FlexTDOA & 16.73 & 12.90 & 30 & 160 & 280 & 2550 & 380 & 14.75\\
Native DS-TWR & 20.86 & 20.86 & 40 & 70 & 130 & 1020 & 71 & 5.22\\
Passive DS-TWR & 39.75 & 13.33 & 10 & 120 & 240 & 2680 & 385 & 4.29\\
\bottomrule\end{tabular}}
\end{center}

\begin{figure}[htbp]
\centering

\caption{Independent position rate. Passive all-event publication rate is not
substituted for independent frames.}
\end{figure}

\begin{figure}[htbp]
\centering

\caption{Positive-gap P95 for dynamic and static raw streams. Maximum gaps are
listed in the tables.}
\end{figure}

Native has the strongest dynamic cadence in this campaign. Flex and Passive
both contain multi-second interruptions. The very large Flex step-speed P95 is
a direct symptom of abrupt raw position variation, not measured walking speed.

\subsection{Native radio-loss diagnostic}
Across the Native capture, start/end counter deltas give 4254 complete and
1208 incomplete candidate frames: \textbf{22.12\% incomplete}. There were 658
slot overruns. All 485 PHY errors were reported as recovered, but the same
interval also contained 964 response timeouts, 517 result timeouts, 377 frame
sync losses, 90 PHR errors and 18 FCS errors.

\begin{center}\scriptsize
\begin{tabular}{lrrrrr}\toprule
\textbf{Anchor} & \textbf{attempts} & \textbf{completed ranges} &
\textbf{completion \%} & \textbf{response timeout} & \textbf{result timeout}\\
\midrule
A2 & 5462 & 5028 & 92.06 & 302 & 131\\
A3 & 5461 & 5042 & 92.33 & 289 & 130\\
A4 & 5461 & 5219 & 95.57 & 120 & 122\\
A5 & 5461 & 5074 & 92.91 & 253 & 134\\
\bottomrule\end{tabular}
\end{center}

Loss is not confined to one anchor, although A4 is visibly better. The data do
not support blaming geometry alone. Scheduling and RX recovery remain credible
contributors.

\section{Static raw results}

\subsection{Local precision}

\begin{center}\scriptsize\resizebox{\textwidth}{!}{%
\begin{tabular}{lrrrrrrrr}\toprule
\textbf{Protocol} & \textbf{N} & \textbf{CEP50 cm} & \textbf{RMS cm} &
\textbf{P95 cm} & \textbf{P99 cm} & \textbf{max cm} & \textbf{2DRMS cm} & \textbf{drift cm}\\
\midrule
FlexTDOA & 929 & 1.68 & 2.13 & 3.85 & 4.89 & 5.95 & 4.27 & 0.21\\
Native DS-TWR & 686 & 1.40 & 2.02 & 3.76 & 5.99 & 10.06 & 4.02 & 0.16\\
Passive DS-TWR & 772 & 1.50 & 1.78 & 3.11 & 3.72 & 6.44 & 3.57 & 0.45\\
\bottomrule\end{tabular}}
\end{center}

\begin{figure}[htbp]
\centering

\caption{Static raw precision around each capture median. All independent
samples are included.}
\end{figure}

\begin{figure}[p]
\centering

\caption{Static raw position clouds centered on each capture median and drawn
at one common scale. The cross is the median.}
\end{figure}

\begin{figure}[p]
\centering

\caption{Static GPS RTK Fixed tag solutions. Top: each cloud centered on its
own median at a shared centimetre scale. Bottom: the same fixes in a common ENU
frame, exposing the cross-capture reference displacement.}
\end{figure}

All three protocols remain close to the requested 2 cm local RMS target at the
tested central point. This does not establish 2 cm absolute accuracy across the
polygon or under NLOS.

\subsection{Static RTK consistency gate}
The maximum separation between the three stationary RTK centers is 2.032 m,
versus a 0.250 m consistency gate. Flex has no usable anchor transform in its
static block. Native and Passive anchor-fit RMS values are 1.073 m and 0.741 m,
respectively. Therefore the approximately 3.0 m Native and 1.9 m Passive
absolute offsets produced by these blocks are registration artifacts and
\textbf{must not be used to rank protocols}.

\subsection{Current stationary regression control}
A new 30 s Passive capture made after the high-rate IMU changes has valid RTK
registration and provides the relevant regression check.

\begin{center}\small
\begin{tabular}{lr}\toprule
\textbf{Metric} & \textbf{result}\\
\midrule
Independent raw positions & 832\\
Raw UWB RMSE versus RTK & 2.710 cm\\
Raw UWB P95 versus RTK & 4.080 cm\\
Raw UWB maximum versus RTK & 4.993 cm\\
Raw local-cloud RMS & 1.711 cm\\
Raw local-cloud P95 & 2.915 cm\\
Fused RMSE versus RTK & 2.568 cm\\
Anchor rigid-fit RMS & 0.422 cm\\
RTK rate & 8.08 Hz\\
Tag IMU rate used by replay & 458.9 Hz\\
\bottomrule\end{tabular}
\end{center}

This is close to the prior calibrated stationary baseline of 2.55 cm absolute
RMSE. High-rate sensor acquisition and telemetry have not generally degraded
stationary raw UWB accuracy.

\section{Dynamic UWB--RTK audit}

\begin{center}\scriptsize\resizebox{\textwidth}{!}{%
\begin{tabular}{lrrrrrrrr}\toprule
\textbf{Protocol} & \textbf{pairs} & \textbf{pair coverage \%} &
\textbf{time P95 ms} & \textbf{raw RMSE cm} & \textbf{raw P95 cm} &
\textbf{raw max cm} & \textbf{anchor fit P95 cm} & \textbf{debiased RMSE cm}\\
\midrule
FlexTDOA & 1100 & 62.6 & 65.6 & 18.28 & 30.57 & 80.19 & 1.41 & 17.16\\
Native DS-TWR & 1892 & 98.2 & 28.0 & 18.68 & 28.36 & 278.00 & 2.25 & 14.77\\
Passive DS-TWR & 1154 & 83.3 & 83.4 & 16.75 & 34.66 & 67.91 & 1.50 & 16.82\\
\bottomrule\end{tabular}}
\end{center}

These values use direct capture-time association and anchor-based rigid
registration. Replay tables later use their own identical-timestamp population;
small differences in sample selection are expected and are retained rather
than forced to agree.

\begin{figure}[htbp]
\centering

\caption{Dynamic raw UWB--RTK disagreement CDF after anchor registration. RTK
is an in-system reference, not surveyed truth.}
\end{figure}

\begin{figure}[htbp]
\centering

\caption{Anchor-registration residual beside paired tag disagreement. Dynamic
anchor fits are centimetric; timing remains the larger limitation.}
\end{figure}

\section{Fusion replay and causal ablation}

\subsection{Raw versus selected fused replay}
The table below uses the per-tag comparison population and the selected replay
for each protocol. It describes the complete fused algorithm, not acceleration
alone.

\begin{center}\scriptsize\resizebox{\textwidth}{!}{%
\begin{tabular}{lrrrrrrrrl}\toprule
\textbf{Protocol} & \textbf{pairs} & \textbf{raw RMSE cm} & \textbf{fused RMSE cm} &
\textbf{raw P95 cm} & \textbf{fused P95 cm} & \textbf{raw max cm} &
\textbf{fused max cm} & \textbf{gap count delta} & \textbf{gate}\\
\midrule
FlexTDOA & 1044 & 17.262 & 16.883 & 28.062 & 28.263 & 78.42 & 65.12 & -190 & reject\\
Native DS-TWR & 1860 & 17.911 & 16.326 & 26.822 & 25.395 & 260.87 & 103.49 & -57 & nominal pass\\
Passive DS-TWR & 1067 & 14.953 & 15.029 & 29.440 & 29.818 & 67.78 & 67.41 & -355 & reject\\
\bottomrule\end{tabular}}
\end{center}

Flex reduces RMSE and maximum but increases P95 by 2.0 mm. Passive slightly
worsens both RMSE and P95. Native appears to pass a raw-versus-fused gate, but
that result is not causal evidence for the accelerometer.

\subsection{Controlled acceleration ablation}

\begin{center}\scriptsize\resizebox{\textwidth}{!}{%
\begin{tabular}{llrrrrr}\toprule
\textbf{Protocol} & \textbf{configuration} & \textbf{accel used / valid} &
\textbf{RMSE cm} & \textbf{P95 cm} & \textbf{max cm} & \textbf{generic replay pass}\\
\midrule
Native DS-TWR & raw UWB & -- & 17.910850 & 26.821895 & 260.873390 & --\\
Native DS-TWR & acceleration disabled & 4 / 108563 & 16.323327 & 25.395069 & 105.326516 & yes\\
Native DS-TWR & current gates & 20449 / 108563 & 16.326430 & 25.395069 & 103.493998 & yes\\
Native DS-TWR & relaxed gates & 97763 / 108563 & 16.310498 & 25.649909 & 94.720490 & yes\\
\midrule
Passive DS-TWR & raw UWB & -- & 14.952546 & 29.439575 & 67.783143 & --\\
Passive DS-TWR & acceleration disabled & 0 / 78893 & 14.867235 & 29.388807 & 66.904426 & yes\\
Passive DS-TWR & current gates & 0 / 78893 & 14.867235 & 29.388807 & 66.904426 & yes\\
Passive DS-TWR & relaxed gates & 26903 / 78893 & 14.867235 & 29.388807 & 66.904426 & yes\\
\bottomrule\end{tabular}}
\end{center}

\begin{figure}[htbp]
\centering

\caption{Dynamic RMSE under controlled replay ablation. The large raw-to-
disabled change belongs to the common smoother; current acceleration is
indistinguishable from disabled.}
\end{figure}

\begin{figure}[htbp]
\centering

\caption{Dynamic P95 under the same ablation. Relaxing Native acceleration
gates slightly worsens P95.}
\end{figure}

For Native, current minus disabled is +0.003103 cm RMSE and exactly 0.000 cm
P95 to the shown precision. Relaxed acceleration changes RMSE by only
-0.012829 cm while worsening P95 by 0.254840 cm. Passive is numerically
identical even after 26903 samples are allowed to propagate. The current
vector-acceleration path therefore fails the causal acceptance criterion.

\subsection{Why acceleration was often unavailable}

\begin{center}\small
\begin{tabular}{lrl}\toprule
\textbf{Protocol} & \textbf{propagated / valid} & \textbf{dominant exclusive gates}\\
\midrule
Native DS-TWR & 20449 / 108563 = 18.84\% & yaw stale 69.30\%; yaw absent 9.28\%\\
FlexTDOA & 0 / 98805 & yaw absent 39.20\%; yaw stale 34.87\%; bias missing 25.93\%\\
Passive DS-TWR & 0 / 78893 & yaw stale 56.92\%; yaw absent 25.53\%; bias missing 17.55\%\\
\bottomrule\end{tabular}
\end{center}

\begin{figure}[htbp]
\centering

\caption{Current-gate acceleration propagation coverage. Zero does not mean
that IMU transport failed; it means vector acceleration was blocked.}
\end{figure}

Flex has an additional replay epoch defect: an IMU timer backstep is translated
into an artificial $2^{32}$ ms span and triggers a reset. Its zero-propagation
figure cannot be attributed only to the normal gates. The current orientation
mapping also assumes body +X follows travel, which is false for arbitrary
handheld rotation and for the simulated throw.

\section{Root-cause findings beyond the filter}

\subsection{Missing radio measurement timestamp}
The current position wire format contains a 32-bit \texttt{uptime\_ms} assigned
when telemetry is submitted, not the radio measurement time. Dashboard and
replay therefore fall back to receive time. The required correction is a
versioned position stream carrying a 64-bit
\texttt{measurement\_monotonic\_us}, derived from the midpoint of the radio RX
host timestamps and preserved through the dashboard archive.

\subsection{Scheduling risks on the UWB core}
The UWB task runs on core 1 at priority 20 and installs the global GPIO ISR
service. BNO085 starts later on core 0, but its 500 Hz handler can consequently
execute on core 1 and perform a GPTimer read plus a critical section. Telemetry
also runs on core 1; its dequeue path scans up to 1024 PSRAM ring entries under
a critical section. Task priority cannot preempt code while interrupts are
masked. Both paths can increase missed radio deadlines and should be A/B tested
after restoring an O(1) FIFO or separate priority queues.

\subsection{What the IMU can safely do now}
Until a physical body-to-UWB mount calibration and a stable yaw source exist,
the safe uses are stationary detection, bias observation, ZUPT, motion-state
classification and adaptive process noise. Vector acceleration should remain
in a shadow predictor and must not replace raw UWB positions.

\section{Protocol assessment}

\begin{center}\small\resizebox{\textwidth}{!}{%
\begin{tabular}{p{0.18\textwidth}p{0.25\textwidth}p{0.25\textwidth}p{0.25\textwidth}}\toprule
\textbf{Criterion} & \textbf{FlexTDOA} & \textbf{Native DS-TWR} & \textbf{Passive DS-TWR}\\
\midrule
Tag radio role & receive-only; scalable & active exchange with each anchor & receive-only\\
Dynamic independent rate & 12.90 Hz & best: 20.86 Hz & 13.33 Hz after overlap removal\\
Dynamic worst gap & 2.55 s & best: 1.02 s & 2.68 s\\
Static local RMS & 2.13 cm & 2.02 cm & best: 1.78 cm\\
Current fused replay & rejected: P95 worsens 2 mm & generic pass, but not an IMU gain & rejected on per-tag RMSE/P95\\
Operational role & primary scalable mode after timestamp fix & coherent diagnostic baseline & useful passive mode; continuity still matters\\
\bottomrule\end{tabular}}
\end{center}

No protocol rewrite is justified by these data. The largest immediate gains are
expected from correct measurement timing, reduced UWB-core interference and
radio-loss diagnostics, not from more aggressive inertial integration.

\section{Limitations}
\begin{itemize}
\item The three dynamic routes are separate walks, not one synchronized path.
\item RTK is an in-system comparison reference and uses software association.
\item GNSS and UWB antenna lever arms are not surveyed.
\item The original static blocks fail the common-reference consistency gate;
      only local precision is comparable across them.
\item One stationary point does not cover GDOP, polygon edges, NLOS or tag
      orientation.
\item The Passive dynamic container lacks \texttt{capture\_end}; its data are
      included but its completeness status is not promoted.
\item The causal ablation is available for Native and Passive. Flex requires a
      replay after the timer-epoch defect is corrected.
\end{itemize}

\section{Recommended next validation sequence}
\begin{enumerate}
\item Add and validate the 64-bit radio measurement timestamp end-to-end.
\item Replace telemetry's O(1024) critical-section scan with O(1) queues and
      A/B test IMU off, acquisition-only and full streaming.
\item Keep yaw-free IMU assistance limited to stationary detection, ZUPT and
      adaptive process noise.
\item Calibrate the physical IMU-to-UWB rotation before using vector
      acceleration; do not infer body +X from arbitrary walking direction.
\item Repeat one marked dynamic route for all protocols and collect at most
      30 s static at the same point without restarting the RTK reference.
\item Accept fusion only when current beats acceleration-disabled on held-out
      RMSE and P95, with no larger maximum or dead-zone count.
\item After timing is trustworthy, investigate channel-9 antenna delay and
      per-link tag--anchor biases to approach the absolute $\pm$2 cm target.
\end{enumerate}

\section{Final conclusion}

The campaign is a useful negative result. High-rate IMU transport works and
stationary raw UWB remains centimetric, but the accelerometer has not improved
dynamic positioning. The visually calmer fused trace is primarily a smoother.
Calling the 17.91 to 16.33 cm Native change an accelerometer improvement would
be incorrect: the acceleration-disabled replay already reaches 16.323 cm.

Raw UWB remains the production and audit reference. Fusion stays optional and
experimental until measurement timing, orientation calibration and causal
held-out tests demonstrate a real improvement.

\section{Reproduction and audit artifacts}

The report directory contains:
\begin{itemize}
\item \texttt{analysis\_summary.json}, \texttt{capture\_metrics.csv},
      \texttt{replay\_metrics.csv}, \texttt{rtk\_pairs.csv} and alignment CSVs;
\item \texttt{ablation\_metrics.csv} and the script that generates the
      additional ablation figures;
\item eleven SVG/PDF figures, this TeX source and the compiled PDF;
\item source paths to the immutable JSONL captures. Raw archives were not
      duplicated into this directory.
\end{itemize}

The six matrix captures are in
\texttt{reports/imu\_fusion\_final\_validation\_20260811} and
\texttt{reports/imu\_fusion\_static\_20260811}. The current Passive regression
control is
\texttt{passive\_ds\_static\_raw\_regression\_01.passive\_ds.jsonl}.

\begin{verbatim}
python tools/uwb_dynamic_static_report.py ... --include-incomplete
python reports/imu_fusion_ablation_20260811/generate_additional_figures.py
pdflatex -interaction=nonstopmode report.tex
\end{verbatim}

No raw capture is modified during report generation.

\end{document}

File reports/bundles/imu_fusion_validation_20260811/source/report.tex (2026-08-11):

\documentclass[10pt,a4paper]{article}
\usepackage{lmodern}
\usepackage[margin=19mm]{geometry}
\usepackage{booktabs}
\usepackage{graphicx}
\usepackage[table]{xcolor}
\usepackage[hidelinks]{hyperref}
\usepackage{parskip}
\usepackage{array}
\graphicspath{{figures/}}
\definecolor{warning}{HTML}{FFF3CD}
\definecolor{info}{HTML}{E0F2FE}
\hypersetup{pdftitle={Dynamic and static comparison of three UWB protocols},pdfauthor={UWB ESP-IDF technical report}}
\begin{document}
\begin{titlepage}
\centering
\vspace*{18mm}
{\Huge\bfseries Dynamic and static UWB comparison\par}
\vspace{4mm}
{\Large FlexTDOA, Native DS-TWR and Passive DS-TWR\par}
\vspace{14mm}
{\large Field campaign of August 6, 2026\par}
\vspace{12mm}
\begin{tabular}{rl}
Platform: & 5 ESP32-S3 + DW3000 modules, Raspberry Pi collector\\
Topology: & M1 tag; M2, M3, M4 and M5 anchors\\
Radio: & UWB channel 9; configured 40 MHz SPI\\
Firmware branch: & \texttt{imu-500hz-fusion}\\
Evidence: & six complete immutable JSONL captures plus replay summaries\\
\end{tabular}
\vfill
\colorbox{info}{\parbox{0.88\textwidth}{\vspace{2mm}
\textbf{Main result.} All three protocols produced usable unfiltered dynamic
trajectories. FlexTDOA delivered the highest independent dynamic rate and the
best static local precision. Native DS-TWR had the shortest worst-case dynamic
gap. Passive DS-TWR remained usable, but its overlapping publications must be
reduced to independent frames for a fair rate comparison.\vspace{2mm}}}
\vfill
{\large Reproducible technical report\par}
\end{titlepage}
\pagenumbering{roman}
\tableofcontents
\clearpage
\pagenumbering{arabic}

\section{Executive summary}
\colorbox{warning}{\parbox{0.96\textwidth}{\textbf{Evidence boundary.}
Stream rates, uptime gaps, sample counts, fusion acceptance and reset counts are
direct diagnostics. Absolute UWB--RTK disagreement is only indicative: RTK was
not an independent survey, clocks are associated in software, antenna lever
arms are unknown, and the UWB frame is registered through RTK anchor geometry.}}

Passive DS overlapping raw windows remain visible in the telemetry rate, while
all comparative precision and trajectory metrics use independent frames.
Interleaved records marked \texttt{imu\_fused=true} are excluded from raw UWB
metrics. Outliers are retained.

The dynamic independent rates were \textbf{27.62 positions/s} for FlexTDOA, \textbf{22.38 positions/s} for Native DS-TWR, and \textbf{23.84 positions/s} for Passive DS-TWR. Passive DS emitted 71.33 dashboard events/s, but those include overlapping windows.

The static raw local RMS values were \textbf{2.13 cm} (FlexTDOA), \textbf{2.02 cm} (Native DS-TWR) and \textbf{1.78 cm} (Passive DS-TWR). These are precision around each capture median, not absolute accuracy.

The stationary tag RTK centers differed by 1.583 m between blocks, invalidating
an absolute cross-protocol static ranking. IMU transport was healthy at roughly
119--127 telemetry samples/s, but all six replays reported zero yaw-alignment
updates. This campaign therefore does not demonstrate acceleration-derived
position improvement.

\section{Scope and questions}
The campaign asks how many independent positions each protocol delivers, where
stream gaps occur, how stable the unfiltered stationary position is, and whether
the first IMU-assisted replay improves the result without hiding raw UWB.

The July 26 report used known static geometry and could make a direct accuracy
statement. Here the anchors and tag are tied to mobile RTK-derived geometry and
software time association, so the evidence boundary is deliberately stricter.

\section{System and protocol background}
\subsection{FlexTDOA}
The tag is UWB receive-only. Anchor transmissions form directed time-difference
observations and the tag solves from a recent coherent observation set. Radio
airtime is largely independent of the number of passive tags.

\subsection{Native DS-TWR}
The active tag exchanges poll, response and final messages with every anchor,
obtains four absolute ranges and solves a coherent frame. Airtime grows with
active tag count, but frame semantics are direct.

\subsection{Passive DS-TWR}
The tag listens to anchor-to-anchor DS-TWR exchanges. Rolling windows may
produce several publications from shared measurements, so dashboard events and
independent frames are intentionally reported separately.

\section{Test configuration and captured evidence}
The dynamic walks lasted 91--96 s and the stationary blocks approximately 180 s.
The selector uses the final walk and the RTK-fixed Raspberry static capture for
each protocol.
\begin{center}\scriptsize\resizebox{\textwidth}{!}{%
\begin{tabular}{lrrrrrrrr}\toprule
\textbf{Protocol} & \textbf{Mode} & \textbf{Capture ID} & \textbf{duration s} & \textbf{events} & \textbf{independent} & \textbf{indep Hz} & \textbf{coverage pct} & \textbf{complete} \\
\midrule
FlexTDOA & dynamic & flextdoa\_walk\_imu\_clean & 150.2 & 4149 & 4149 & 27.62 & 99.9 & yes \\
Native DS-TWR & dynamic & native\_ds\_walk\_imu\_clean\_take2 & 150.1 & 3359 & 3359 & 22.38 & 99.9 & yes \\
Passive DS-TWR & dynamic & passive\_ds\_walk\_imu\_clean & 150.0 & 10702 & 3576 & 23.84 & 99.9 & yes \\
FlexTDOA & static & flextdoa\_static\_final & 30.3 & 929 & 929 & 30.67 & 99.4 & yes \\
Native DS-TWR & static & native\_ds\_static\_final & 30.5 & 686 & 686 & 22.47 & 99.4 & yes \\
Passive DS-TWR & static & passive\_ds\_static\_final & 31.1 & 2295 & 772 & 24.80 & 99.1 & yes \\
\bottomrule\end{tabular}}\end{center}
Every selected block has a terminal \texttt{capture\_end}. All raw data are
archived losslessly and identified by SHA-256.

\section{Methodology}
\subsection{Population and continuity}
No error-based trimming or temporal smoothing is applied. Rates use full
capture wall time. Gaps are positive differences between unique ESP32 uptime
values; P50/P95/P99, maximum and counts above 100 ms are retained together.

\subsection{Static precision}
Radial displacement is computed around each block's component-wise position
median. CEP50, RMS, P95, P99, maximum, 2DRMS and first-to-last-decile drift use
all independent samples. They describe repeatability, not offset from truth.

\subsection{RTK audit}
Only quality-4 fixes enter the audit. WGS84 is converted through ECEF to a common
ENU frame. A proper 2-D rotation and translation is fitted from at least three
anchor centers; scale is fixed. Tag matches must be within 100 ms. Anchor-fit
residual and association timing accompany every tag error.

\section{Dynamic results}
\subsection{Raw trajectories}
The walks are separate physical trials, not synchronized repeats. The panels
therefore show continuity and gross geometry rather than point-by-point route
agreement.

\begin{figure}[htbp]
\centering

\caption{Raw independent dynamic trajectories in each local UWB frame. Green markers are anchors. Different panels represent different walks.}
\end{figure}
\subsection{Update rate and gaps}
\begin{center}\scriptsize\resizebox{\textwidth}{!}{%
\begin{tabular}{lrrrrrrrr}\toprule
\textbf{Protocol} & \textbf{duration s} & \textbf{events} & \textbf{independent} & \textbf{event Hz} & \textbf{indep Hz} & \textbf{gap P95 ms} & \textbf{gap max ms} & \textbf{step P95 m/s} \\
\midrule
FlexTDOA & 150.2 & 4149 & 4149 & 27.62 & 27.62 & 70 & 2030 & 5.08 \\
Native DS-TWR & 150.1 & 3359 & 3359 & 22.38 & 22.38 & 60 & 410 & 5.20 \\
Passive DS-TWR & 150.0 & 10702 & 3576 & 71.33 & 23.84 & 30 & 610 & 4.60 \\
\bottomrule\end{tabular}}\end{center}
\begin{figure}[htbp]
\centering

\caption{Independent position rate in the selected dynamic and static blocks. Passive DS all-event publications are not substituted for independent frames.}
\end{figure}
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

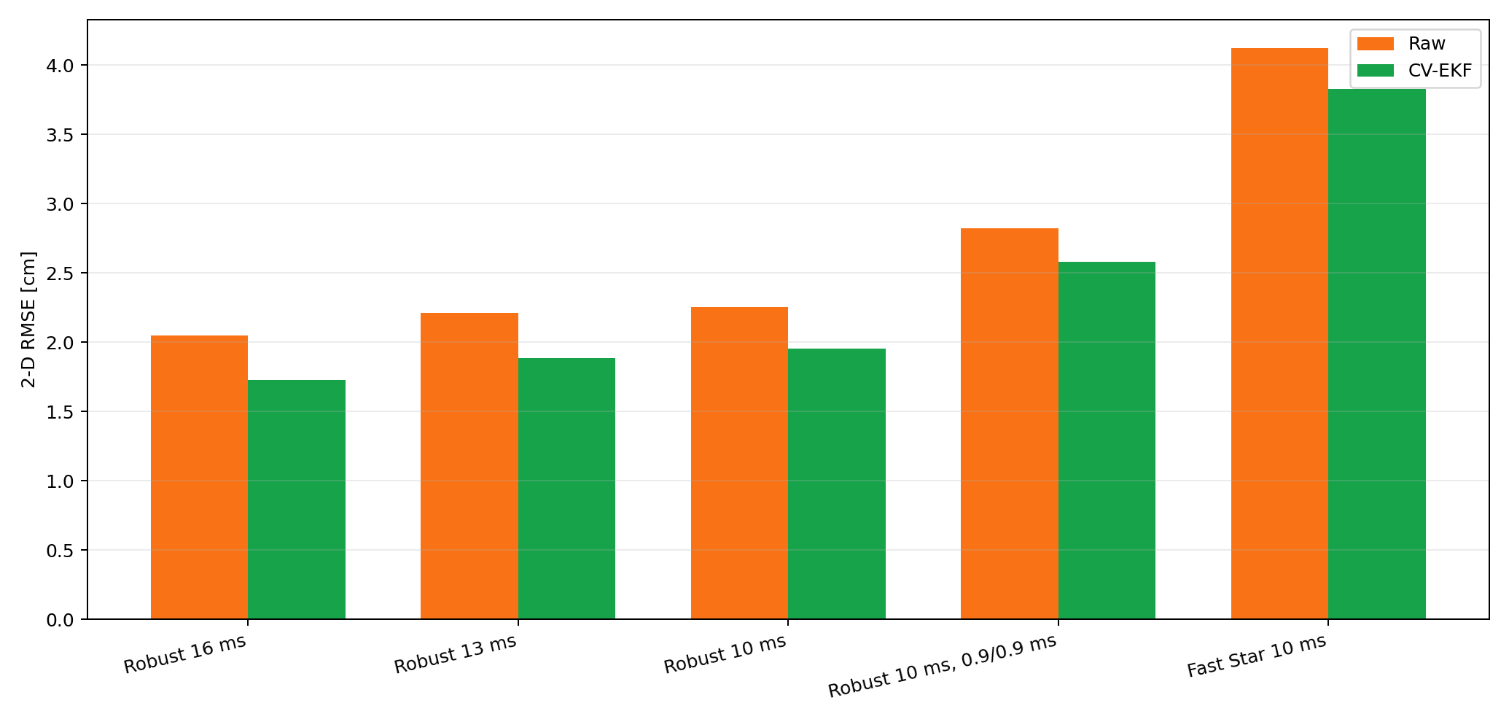
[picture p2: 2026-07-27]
reports/bundles/passive_ds_speed_limit_20260727/figures/raw_vs_filtered_rmse.png

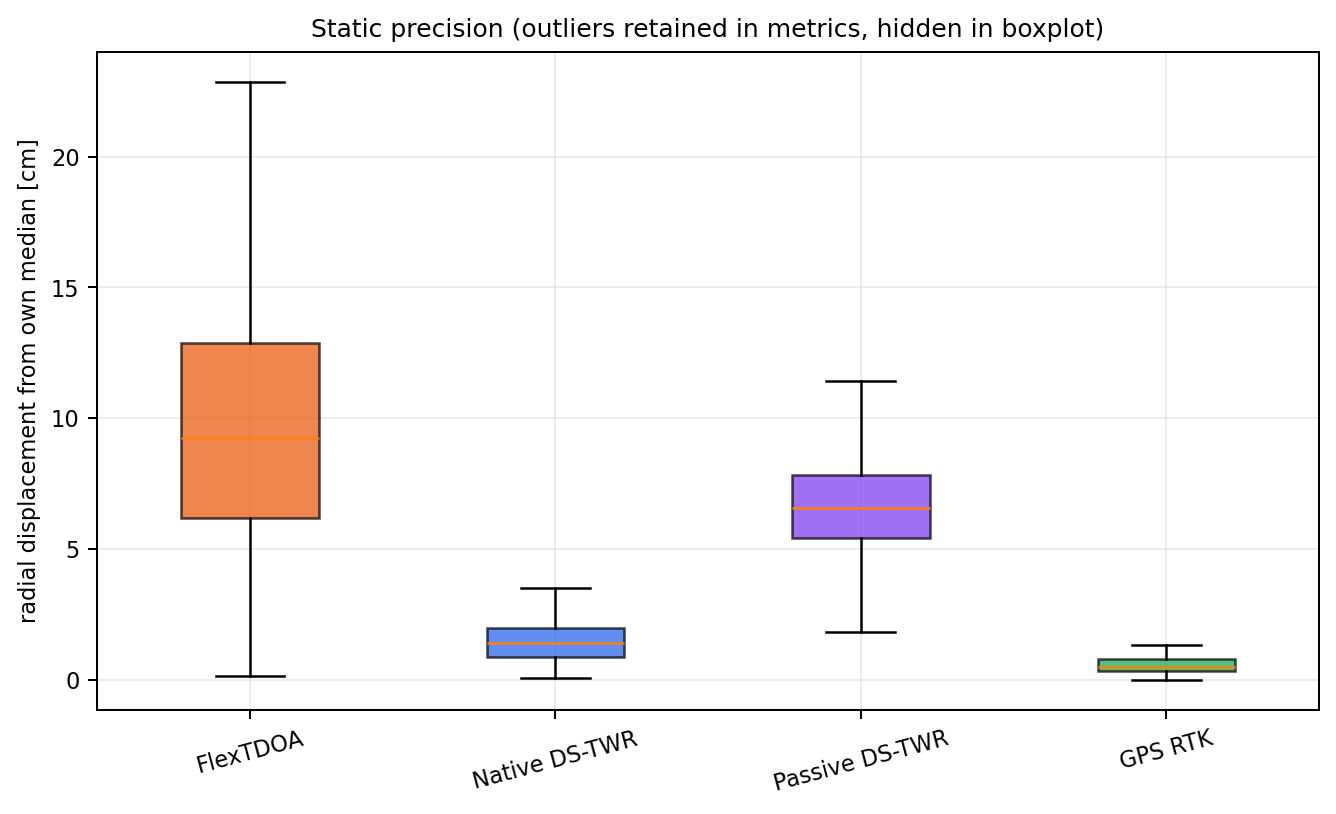
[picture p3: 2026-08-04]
reports/bundles/uwb_gps_rtk_comparison_20260803/figures/04_precision_boxplot.png

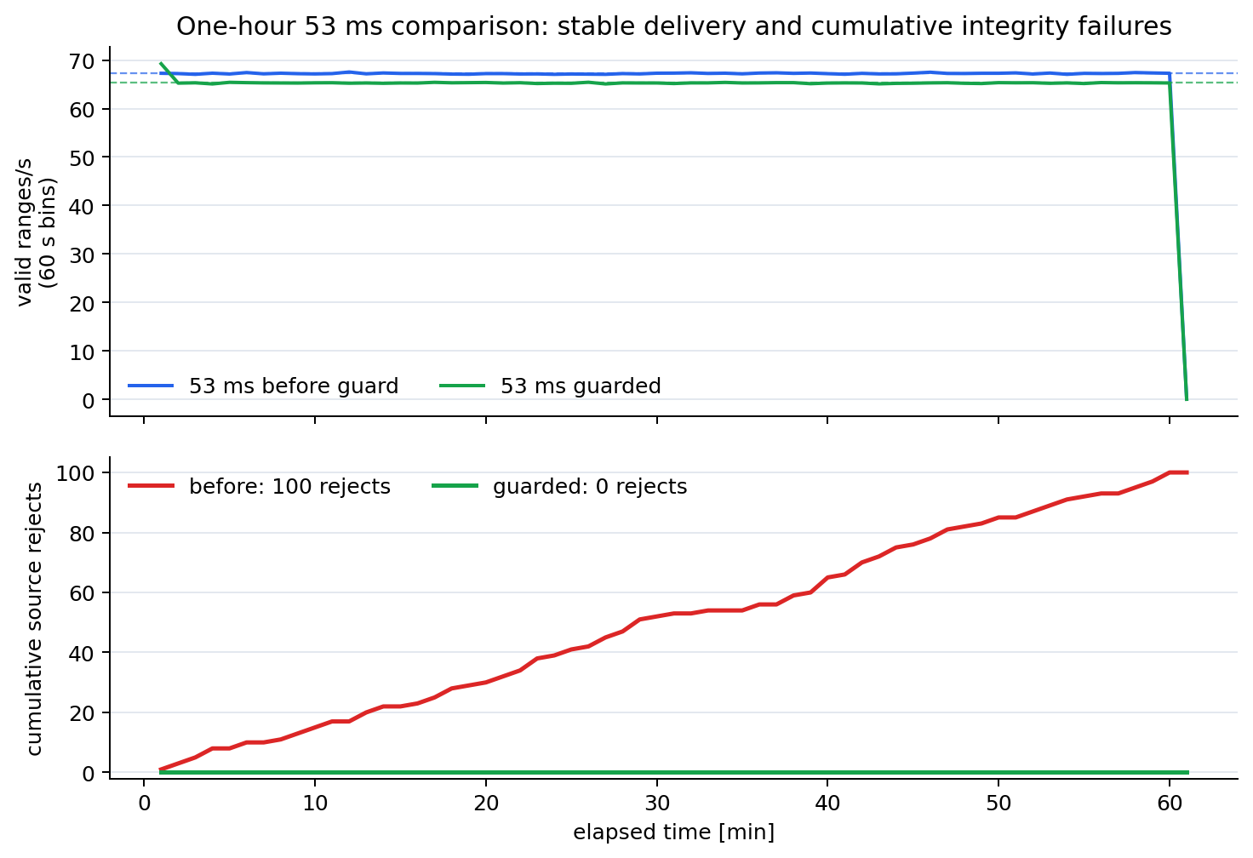
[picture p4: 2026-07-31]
reports/bundles/native_ds_round_boundary_20260731/figures/04_before_after_timeline.png

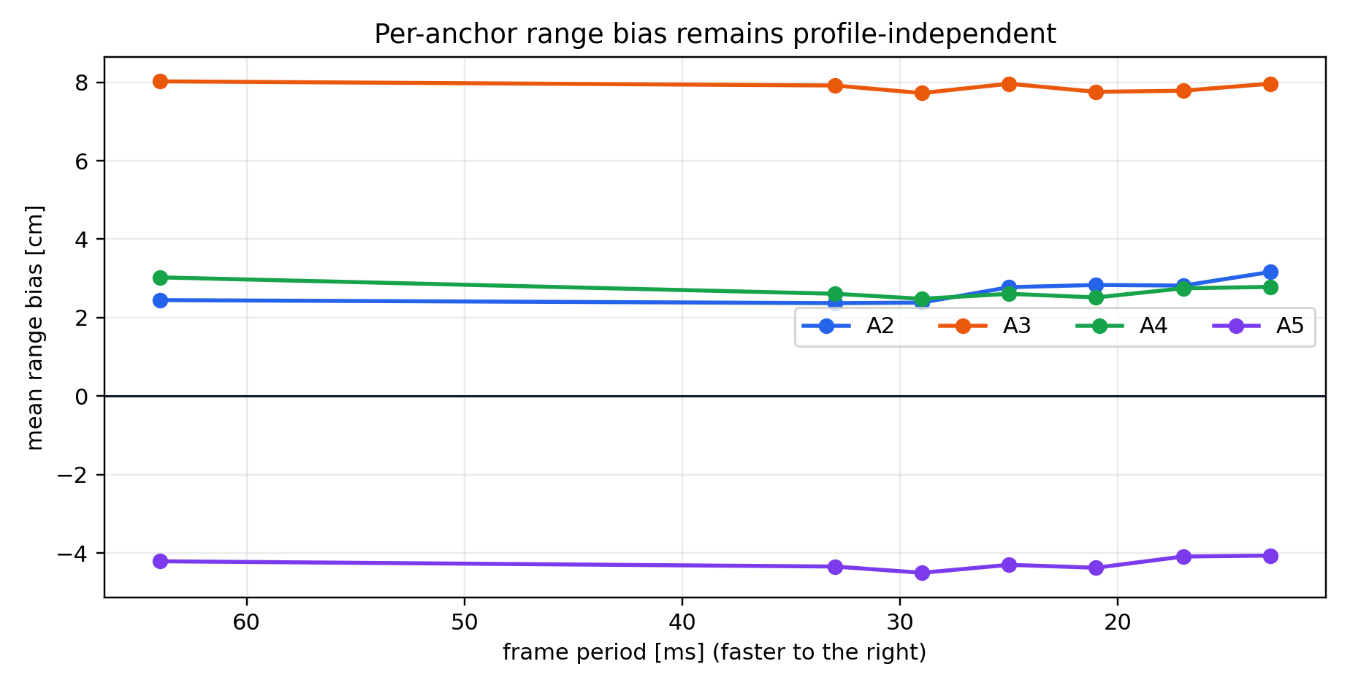
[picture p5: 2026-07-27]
reports/bundles/ds_twr_speed_limit_20260726/figures/05_anchor_bias.png

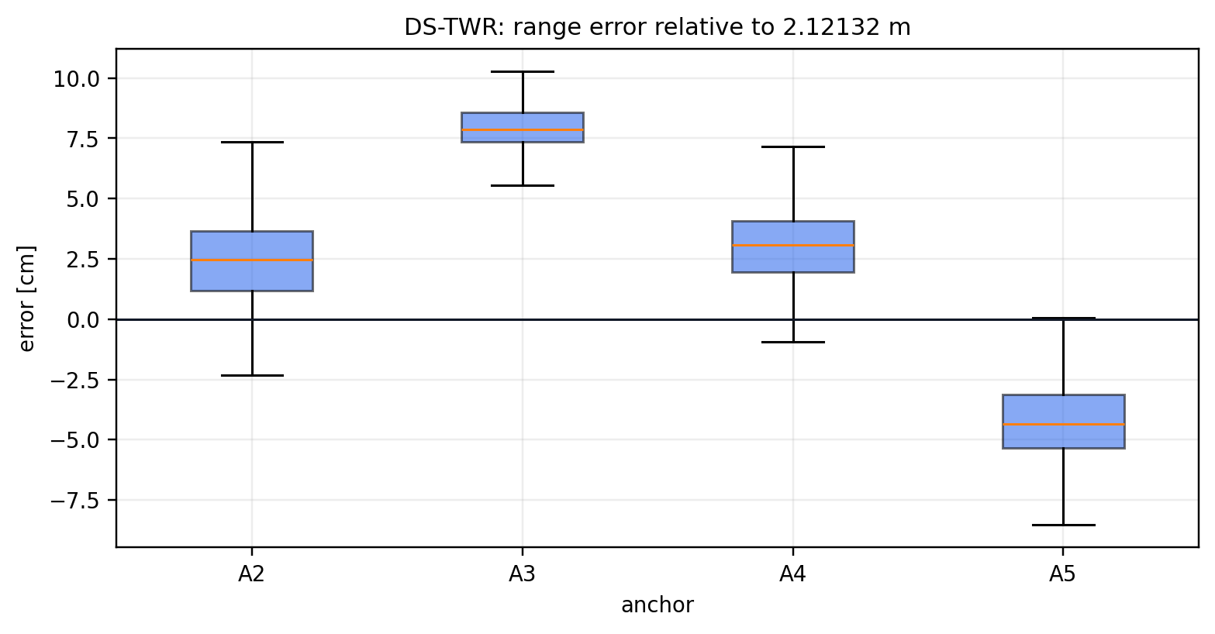
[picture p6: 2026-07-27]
reports/bundles/uwb_protocol_comparison_20260726/figures/02_ds_range_error.png

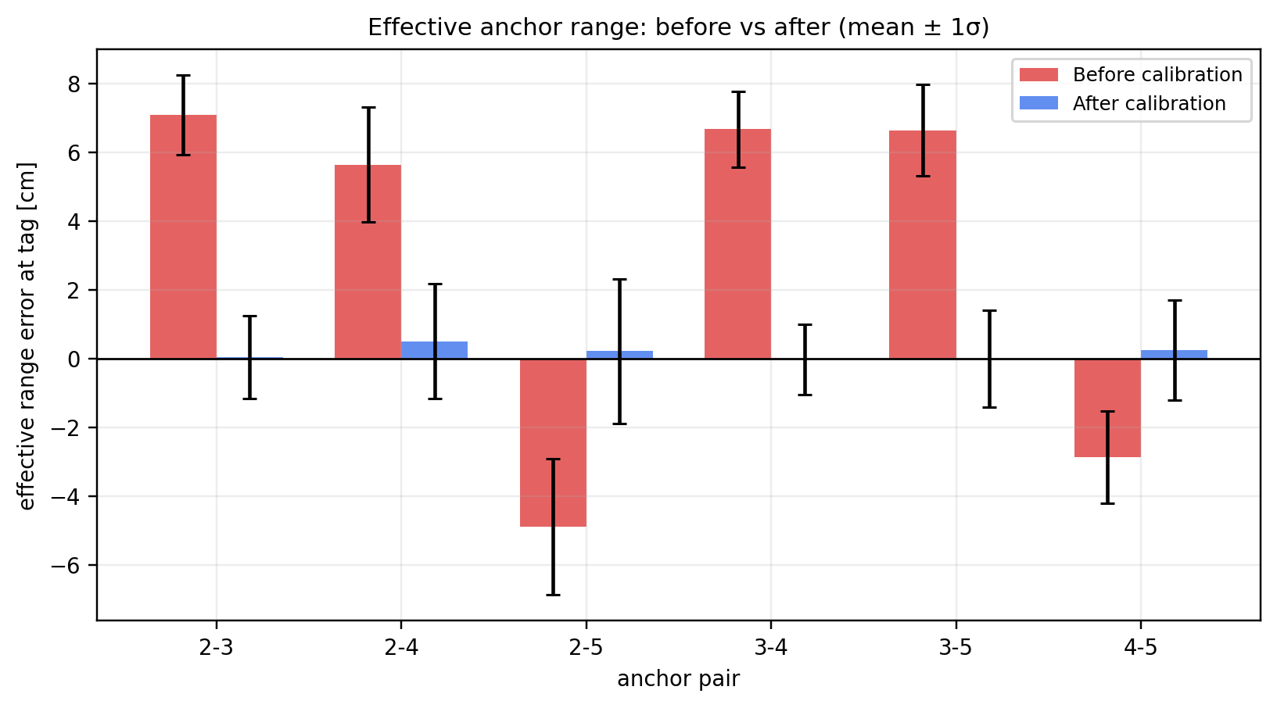
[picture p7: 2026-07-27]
reports/bundles/passive_ds_known_geometry_20260727/figures/anchor_pair_range_bias.png

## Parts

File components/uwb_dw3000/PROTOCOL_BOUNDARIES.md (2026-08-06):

# UWB protocol boundaries

The firmware exposes three independent positioning protocols over one DW3000
radio driver.  The split is deliberately based on **state ownership**, because
stale cross-frame state was the source of protocol-switch regressions.

## Shared radio layer

`uwb_dw3000.c` owns only hardware-facing resources that cannot exist three
times on one transceiver: SPI/register access, IRQ/RX buffering, timestamps,
delayed TX primitives, timers and the runtime-mode router.  Its FlexTDOA and
Passive DS-TWR schedule adapters may call their own runtime facade, but may not
call a solver implementation directly.

`uwb_anchor_range_cache.c` implements generic cache mechanics.  It contains no
global cache.  A cache instance is always supplied by one protocol runtime.

`uwb_mobile_geometry` owns the protocol-neutral GNSS wire sample and rigid
RTK-to-UWB projection used by FlexTDOA and Native DS-TWR. It has no radio,
solver, task or global runtime state. Passive DS-TWR retains its equivalent
protocol-private implementation so its validated packet and solver boundary
does not change.

## FlexTDOA

- `uwb_flex_tdoa_runtime.c`: Flex-only cache and solver lifecycle.
- `flextdoa_solver_service`: Flex observation/geometry solver task.
- The radio adapter submits only Flex observations through the runtime facade.

## Native DS-TWR

- `uwb_native_ds_twr.c`: complete POLL/RESP/FINAL state machine.
- `uwb_native_ds_runtime.c`: Native position solver and telemetry bridge.
- `uwb_native_ds_position_solver.c`: Native geometry and position math.

Native DS-TWR receives only generic radio callbacks from `uwb_dw3000.c`; it has
no dependency on either receive-only protocol.

## Passive DS-TWR

- `uwb_passive_ds_protocol.c`: PDS3 packet codec, rotating star plan, timing
  helpers and full anchor DS-TWR equation.
- `uwb_passive_ds_observation.c`: three-packet passive DS range-difference
  equation using POLL/RESPONSE/FINAL and delayed responder exchange timing.
- `uwb_passive_ds_runtime.c`: Passive-only anchor diagnostic cache, counters
  and raw solver lifecycle.
- `passive_ds_solver_service`: raw AlgMin solver bootstrapped from surveyed RTK
  ENU geometry and evaluated with packet-time anchor GNSS coordinates. It
  supports either one coherent radio star or a three-star spatial window;
  neither mode performs temporal filtering or prediction.

The driver cannot obtain a mutable pointer to Passive runtime state.  It uses
explicit submit, record and snapshot operations instead.

## Switching invariant

Entering a protocol resets only that protocol's runtime.  FlexTDOA never reads
or resets the Passive cache; Passive DS-TWR never falls back to Flex ranges;
Native DS-TWR constructs a fresh stack runtime for every entry.  Shared radio
hardware is stopped/reconfigured by the router, independently of solver state.

The architectural guard is a dependency of the UWB component and therefore
runs automatically during every firmware build. It can also be run directly:

```sh
python3 tools/check_uwb_protocol_boundaries.py
idf.py build
```

The guard fails if the common driver calls a protocol solver directly, if one
runtime references another, if private state accessors reappear, or if an
isolated source file drops out of the ESP-IDF build.

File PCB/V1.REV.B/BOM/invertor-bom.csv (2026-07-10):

# | Comment | Designator | Footprint | JLCPCB Part #(optional)
1 | Battery_Cell | BT1 | Battery:BatteryHolder_Seiko_MS621F
2 | BAT | BT2 | Connector_JST:JST_PH_B2B-PH-K_1x02_P2.00mm_Vertical | C131337
3 | 47pF | C28 | Capacitor_SMD:C_0603_1608Metric | C23345
4 | 10.nF | C30 | Capacitor_SMD:C_1812_4532Metric | C3287694
5 | 1uF | C1,C2,C5,C13,C14,C22,C25,C37,C60,C61,C81,C83,C84,C85,C86,C87 | Capacitor_SMD:C_0603_1608Metric | C15849
6 | 22pF | C10,C11 | Capacitor_SMD:C_0603_1608Metric | C1653
7 | 10uF | C19,C26,C29,C31,C32,C33,C39,C41,C43,C44,C45,C47,C48,C49,C57,C67,C68,C70,C71,C72,C73,C74,C75,C76,C77,C79,C80 | Capacitor_SMD:C_0603_1608Metric | C19702
8 | 100nF | C3,C4,C7,C8,C9,C15,C16,C17,C18,C23,C27,C34,C35,C36,C38,C46,C51,C53,C59,C63,C64,C65,C66,C69,C78,C82 | Capacitor_SMD:C_0603_1608Metric | C14663
9 | 22uF | C50,C52,C54,C58 | Capacitor_SMD:C_1206_3216Metric | C12891
10 | 47nF | C55,C56 | Capacitor_SMD:C_0603_1608Metric | C1622
11 | 10nF | C6,C12,C20,C21,C24,C62 | Capacitor_SMD:C_0603_1608Metric | C57112
12 | SMAJ20CA | D14 | Diode_SMD:D_SMA | C134970
13 | 3v9 | D20 | Diode_SMD:D_SMA
14 | 10v | D27 | Diode_SMD:D_SOD-123F | C2922775
15 | SP4020 | D1,D2,D3,D4,D5,D6,D12,D15,D19 | Diode_SMD:D_SOD-323 | C126842
16 | SMAJ5.0CA | D21,D23 | Diode_SMD:D_SMA | C83324
17 | PMEG10020 | D25,D26,D28 | Diode_SMD:D_SOD-123F | C22452
18 | LED_GREEN | D7,D8,D10,D11,D16,D17,D18,D22 | LED_SMD:LED_0603_1608Metric | C22371297
19 | LED_RED | D9,D24 | LED_SMD:LED_0603_1608Metric | C965799
20 | DWM3000 | DWM1 | RF_Module:DWM1000 | C5299931
21 | 1A | F2 | Fuse:Fuse_1206_3216Metric | C2838907
22 | 2A | F1,F3 | Fuse:Fuse_1206_3216Metric | C18211642
23 | FerriteBead | FB1,FB2,FB3,FB4,FB5 | Inductor_SMD:L_0805_2012Metric | C3716677
24 | B39162B3520U410 | FL1 | B39162B3520U410:B39162B3520U410 | C2650959
25 | TPS630701RNMT | IC1 | TPS630702RNMT:TPS630702RNMT | C181473
26 | BQ25792RQMR | IC2 | BQ25792RQMR:BQ25792RQMR | C2862876
27 | MAX77958EWV | IC3 | BGA30C50P6X5_307X262X69
28 | MPM3612GLQ-P | IC4 | MPM3612GLQ33P
29 | FT232 | J1 | Connector_PinSocket_2.54mm:PinSocket_1x06_P2.54mm_Vertical | C8690
30 | GPS antenna | J2 | Connector_Coaxial:SMA_Samtec_SMA-J-P-H-ST-EM1_EdgeMount | C5199907
31 | USB_C_Receptacle_USB2.0_14P | J3 | Connector_USB:USB_C_Receptacle_GCT_USB4105-xx-A_16P_TopMnt_Horizontal | C5184243
32 | 27nH | L1 | Inductor_SMD:L_0603_1608Metric | C98072
33 | 1.5uH | L2 | Inductor_SMD:L_Taiyo-Yuden_NR-60xx | C3221450
34 | 1uH | L3 | Inductor_SMD:L_Taiyo-Yuden_NR-60xx | C1331878
35 | DMG2307L | Q1 | Package_TO_SOT_SMD:SOT-23 | C102620
36 | BSS138 | Q3,Q6,Q7,Q8 | Package_TO_SOT_SMD:SOT-23 | C5224261
37 | 390 | R62 | Resistor_SMD:R_0603_1608Metric | C23151
38 | 365k | R76 | Resistor_SMD:R_0603_1608Metric | C23031
39 | 50k | R79 | Resistor_SMD:R_0603_1608Metric | C304067
40 | 470k | R82 | Resistor_SMD:R_0603_1608Metric | C23178
41 | 150k | R83 | Resistor_SMD:R_0603_1608Metric | C22807
42 | 133k | R88 | Resistor_SMD:R_0603_1608Metric | C22870
43 | 51k | R90 | Resistor_SMD:R_0603_1608Metric | C18672
44 | 10k | R1,R2,R5,R26,R27,R30,R31,R32,R34,R35,R36,R37,R38,R39,R40,R41,R42,R49,R52,R53,R54,R55,R59,R60,R63,R73,R86,R89,R96,TH1 | Connector_JST:JST_PH_B2B-PH-K_1x02_P2.00mm_Vertical,Resistor_SMD:R_0603_1608Metric | C25804
45 | 0 | R22,R23,R67,R69,R95,R97 | Resistor_SMD:R_0603_1608Metric | C21189
46 | 100 | R3,R4,R6,R7,R8,R9,R10,R11,R12,R13,R14,R15,R16,R17,R18,R19,R20,R21,R24,R25,R28,R29,R64,R65,R91 | Resistor_SMD:R_0603_1608Metric | C22775
47 | 680 | R33,R43,R44,R45,R46 | Resistor_SMD:R_0603_1608Metric | C23228
48 | 100k | R47,R50,R51,R66,R71,R74,R80,R84 | Resistor_SMD:R_0603_1608Metric | C25803
49 | 330 | R48,R85 | Resistor_SMD:R_0603_1608Metric | C23138
50 | 1k | R56,R57,R58,R61,R68,R75,R81,R87,R93 | Resistor_SMD:R_0603_1608Metric | C21190
51 | 5.1k | R70,R72,R77,R78 | Resistor_SMD:R_0603_1608Metric | C23186
52 | 30.1k | R92,R94 | Resistor_SMD:R_0603_1608Metric | C23000
53 | ESP32 BOOT | SW1 | Button_Switch_SMD:SW_Push_1P1T_NO_CK_KMR2 | C99271
54 | ESP32 RESET | SW2 | Button_Switch_SMD:SW_Push_1P1T_NO_CK_KMR2 | C99271
55 | GPS RESET | SW3 | Button_Switch_SMD:SW_Push_1P1T_NO_CK_KMR2 | C99271
56 | on/off | SW4 | Button_Switch_SMD:SW_SPDT_PCM12 | C18197923
57 | DWM RESET | SW5 | Button_Switch_SMD:SW_Push_1P1T_NO_CK_KMR2 | C99271
58 | 3v3 | TP3 | TestPoint:TestPoint_Pad_D2.0mm
59 | GND | TP4 | TestPoint:TestPoint_Pad_D2.0mm
60 | ESP32-S3-WROOM-1 | U1 | RF_Module:ESP32-S3-WROOM-1 | C2913202
61 | BNO085 | U2 | Package_LGA:LGA-28_5.2x3.8mm_P0.5mm | C5189642
62 | LDS3985M33R | U3 | Package_TO_SOT_SMD:SOT-23-5 | C2970345
63 | PX1125R | U4 | PX1125R:PX1105R | C9900164713
64 | TPD2S017 | U6 | Package_TO_SOT_SMD:SOT-23-6 | C880115
65 | 32.768KHz | Y1 | Crystal:Crystal_SMD_2012-2Pin_2.0x1.2mm | C276423

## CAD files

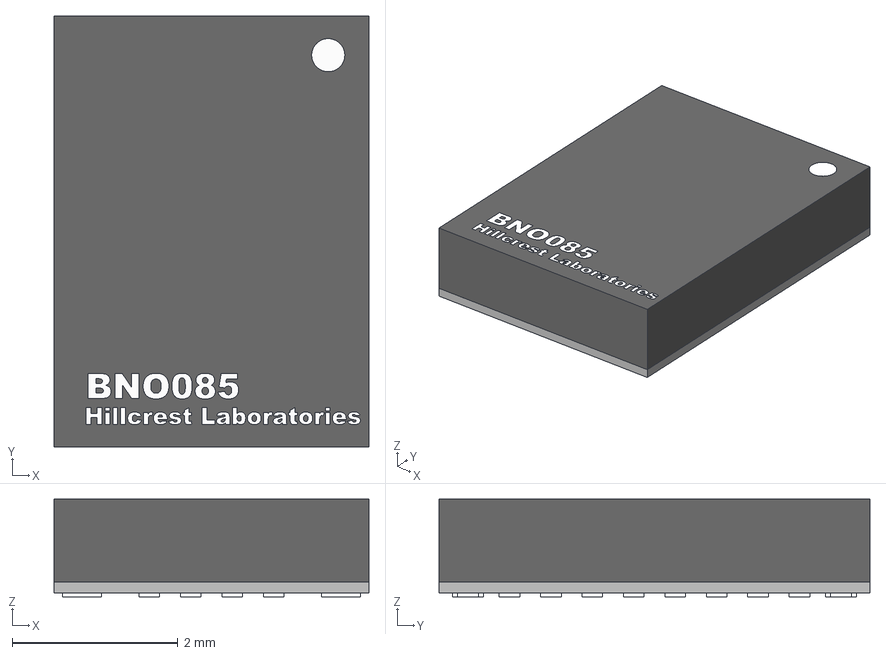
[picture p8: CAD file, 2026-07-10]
PCB/V1.REV.B/Kicad project/Librarys/BNO085/Hillcrest_Laboratories,_Inc._-_BNO085.step
3.80 x 5.20 x 1.18 mm
pads
txt

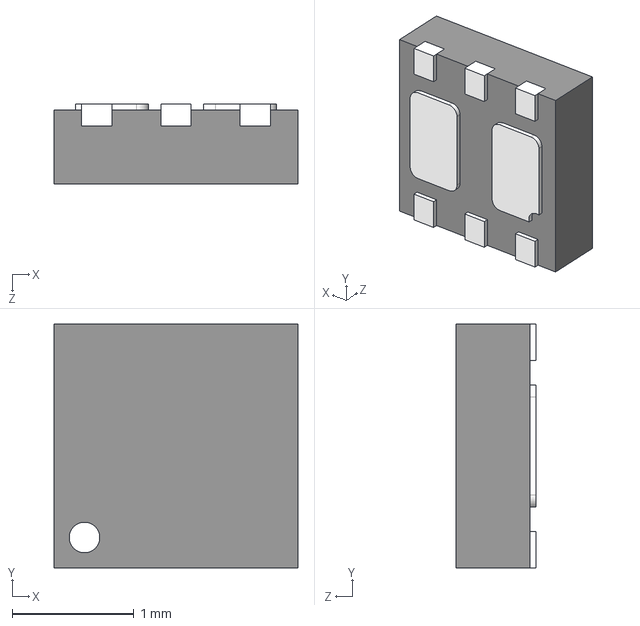
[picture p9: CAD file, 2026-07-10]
PCB/V1.REV.B/Kicad project/Librarys/DMP1046UFDB-7/DMP1046UFDB-7.stp
2.00 x 2.00 x 0.655 mm

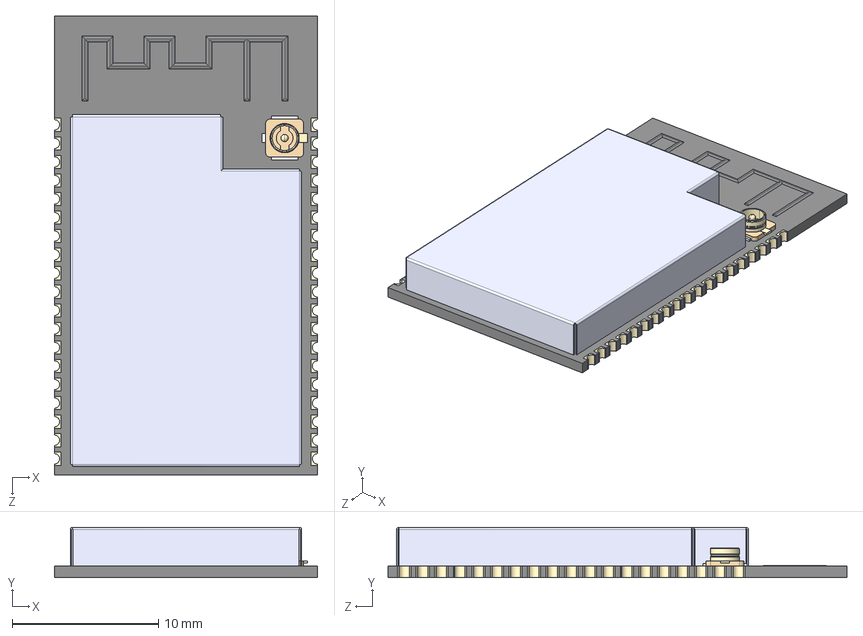
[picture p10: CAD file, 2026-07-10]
PCB/V1.REV.B/Kicad project/Librarys/ESP32-WROVER-E-N4R8/ESP32-WROVER-E-N4R8.step
18.0 x 3.45 x 31.4 mm
ESP32-WROVER-E-N4R8 board
UFL connector

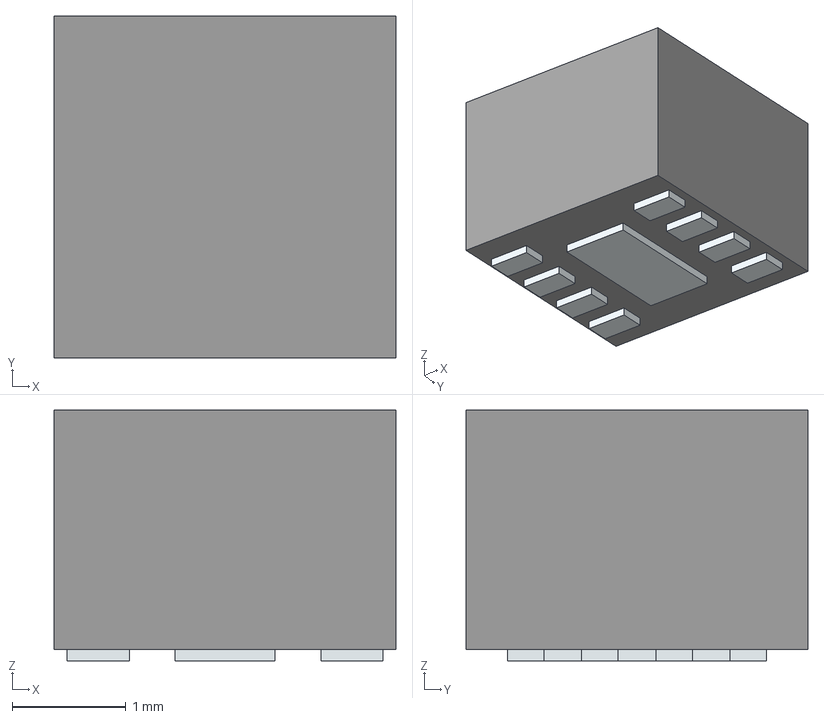
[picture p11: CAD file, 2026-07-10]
PCB/V1.REV.B/Kicad project/Librarys/MPM3612GLQ-33-P/MPM3612GLQ-33-P.stp
3.00 x 3.00 x 2.20 mm
Pins

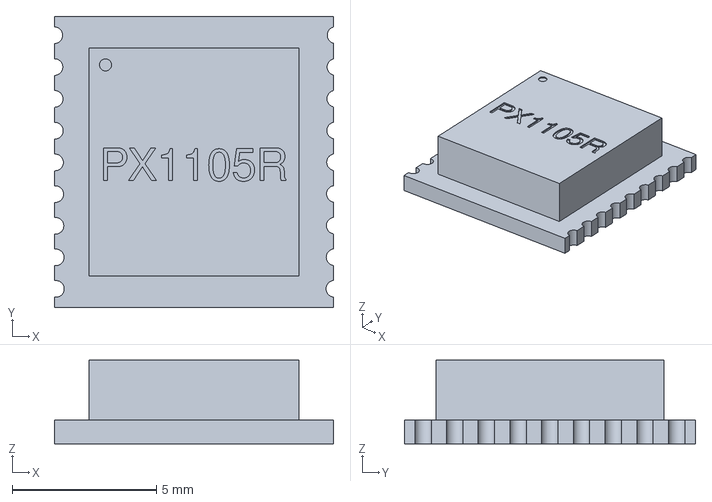
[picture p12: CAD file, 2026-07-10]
PCB/V1.REV.B/Kicad project/Librarys/PX1125R/PX1105R_v2.step
9.70 x 10.1 x 2.90 mm

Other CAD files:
mechanical/uwb-gps-enclosure/reference_models/antena_gps/YN-91A_refined_v04_assembly.step
mechanical/uwb-gps-enclosure/exports/07_capac_palarie_PRINT.stl
mechanical/uwb-gps-enclosure/previews/REF_garda_mufa_SMA_D15.stl
mechanical/uwb-gps-enclosure/reference_models/modul_radio/UWB.step
mechanical/uwb-gps-enclosure/exports/06_suport_antena_gps.step
mechanical/uwb-gps-enclosure/previews/REF_placa_UWB.stl
mechanical/uwb-gps-enclosure/exports/03_sasiu_pcb_acumulator_PRINT.stl
mechanical/uwb-gps-enclosure/previews/REF_acumulator.stl
mechanical/uwb-gps-enclosure/exports/02_corp_inferior.step
mechanical/uwb-gps-enclosure/previews/REF_guler_sectionat_FDM.stl
mechanical/uwb-gps-enclosure/exports/01_baza_tinta_PRINT.stl
mechanical/uwb-gps-enclosure/previews/REF_bosaje_capac.stl
mechanical/uwb-gps-enclosure/exports/08_baza_trepied.step
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

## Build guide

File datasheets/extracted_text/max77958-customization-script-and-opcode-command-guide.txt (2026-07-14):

MAX77958
Customization Script and OPCode Command
Guide
Rev 5; 7/2024

Abstract
The MAX77958 Customization Script and OPCode Command Guide explains how system
designers can use the MAX77958 and describes the control registers that can be configured by
OPCode commands.

Analog Devices, Inc.                                                           Page 1 of 47

Table of Contents
Standard Firmware ....................................................................................................................... 5
Customization Script ..................................................................................................................... 6
   Customization Commands ........................................................................................................ 7
   Event List................................................................................................................................... 9
   Customization Script Download Flowchart .............................................................................. 16
   Customization Update Flowchart for MTP ............................................................................... 17
   OPCode 0x60 - Action MTP Update Flowchart ....................................................................... 18
OPCode Commands ................................................................................................................... 19
   Simplified Block Diagram of the OPCode Command Process ................................................ 19
   OPCode Command Format ..................................................................................................... 19
OPCode Example ....................................................................................................................... 22
OPCode Register Information ..................................................................................................... 23
   0x01: BC CTRL1 Config Read ................................................................................................ 23
   0x02: BC CTRL1 Config Write ................................................................................................ 23
   0x03: BC CTRL2 Config Read ................................................................................................ 23
   0x04: BC CTRL2 Config Write ................................................................................................ 24
   0x05: Control1 Read ............................................................................................................... 24
   0x06: Control1 Write ................................................................................................................ 25
   0x0B: CC Control1 Read ......................................................................................................... 25
   0x0C: CC Control1 Write ......................................................................................................... 26
   0x11: CC Control4 Read ......................................................................................................... 26
   0x12: CC Control4 Write ......................................................................................................... 27
   0x23: GPIO Control Read ....................................................................................................... 27
   0x24: GPIO Control Write ........................................................................................................ 28
   0x27: GPIO0 GPIO1 ADC Read ............................................................................................. 28
   0x2F: Get Sink Cap ................................................................................................................. 29
   0x30: Current Src Cap ............................................................................................................. 30
   0x31: Get Source Cap ............................................................................................................. 30
   0x32: Src Cap Request ........................................................................................................... 31
   0x33: Set Src Cap ................................................................................................................... 31

Analog Devices, Inc.                                                                                                          Page 2 of 47

   0x34: Send Get Request ......................................................................................................... 32
   0x35: Read the Response for Get Request ............................................................................ 33
   0x36: Send Get Response ...................................................................................................... 33
   0x37: Send Swap Request ...................................................................................................... 34
   0x38: Send Swap Response ................................................................................................... 35
   0x3A: APDO SrcCap Request ................................................................................................. 35
   0x3C: Set PPS ........................................................................................................................ 37
   0x3E: SNK PDO Request ........................................................................................................ 38
   0x3F: SNK PDO Set ................................................................................................................ 39
   0x4A: Get PD Message ........................................................................................................... 40
   0x55: Customer Configuration Read ....................................................................................... 40
   0x56: Customer Configuration Write ....................................................................................... 43
   0x64: Set GPIO7 and GPIO8 as Interrupt ............................................................................... 44

   0x85: Master I2C Control Read ............................................................................................... 44

   0x86: Master I2C Control Write ............................................................................................... 45
Firmware Update ........................................................................................................................ 46
   Firmware Update through AP .................................................................................................. 46
   Firmware Update Flowchart .................................................................................................... 46

Analog Devices, Inc.                                                                                                     Page 3 of 47

Revision History
REVISION     REVISION                                                  PAGES
                                           DESCRIPTION
NUMBER        DATE                                                    CHANGED

    0          6/2020   Initial release                                   —

                        Add OPCode.
                                                                         P.31
    1          3/2021      • 0x34: Send Get Request
                                                                         P.43
                           • 0x64: Set GPIO7 and GPIO8 As Interrupt

                        Add OPCode.                                      P.22
    2         12/2022
                           • 0x03/0x04: BC CTRL2 Read/Write              P.23

                        Add Customization Commands
                           • i2c_write8_masked
                                                                         P.8
                           • i2c_read8
                                                                         P.11
                           • DET_SDP/ DET_CDP/ DET_DCP
    3          4/2023                                                    P.12
                           • IRQ_EXT7_INITIALIZE
                                                                         P.13
                           • SNK_RDY / SRC_RDY
                                                                         P.17
                        Add MTP Customization update flow chart

                        Modify OPCode 0x85’s format                      P.43
    4          2/2024
                        Add Action MTP update flow chart                 P.18

                        Fixed typo for 0x04 OPCode                       P.24
    5          7/2024
                        Removed overlapped OPCode Info (0x56)            P.43

Analog Devices, Inc.                                                  Page 4 of 47

Standard Firmware
The standard firmware controls all USB Type-C and power delivery related functions. This part of
the firmware is expected to be familiar to for all system designers as it follows the USB Type-C
and PD 3.0 specification.
Another portion of the MTP is reserved for the customization scripts; system designers can
program this area to make the MAX77958 satisfy the system definition.
If the standard firmware is updated, the customization script will be automatically removed. When
updating the standard firmware and customization script, standard firmware needs to be updated
first.
The MAX77958 can be customized to operate with specific applications using customization
scripts and OPCode commands.
Customization scripts are recommended for autonomous systems without an application
processor and OPCode commands are recommended for systems with an application processor.

Detailed descriptions of each method are illustrated in the following sections.

Analog Devices, Inc.                                                                Page 5 of 47

Customization Script
The customization script is the core of the configurability of the MAX77958 when used in the
autonomous configuration. It allows the user to configure either a GPIO state or perform an I2C
action when an event is detected on the USB Type-C interface. The customization script is written
in the graphical user interface (GUI). The software translates the customization script to
hexadecimal format and writes it to the IC configuration area. The configuration by GUI must be
stored in the MTP area of the IC to start operating as per the customization commands.

Figure 1 shows the simple implementation of the customization script. Developers can define the
functions and the sequences for each Event ID listed on the Event Item List using the MAX77958
GUI. The GUI provides users not only the interface to create the customized code but also the
functionality to detect syntax errors in the script usage.

            User Programming

 Customization Script                              Convert to bin file (Used to download to EV kit.via GUI)

                                                    Convert to hex file (used to download to target via AP)

Figure 1. User Programming of Customization Script

Analog Devices, Inc.                                                                        Page 6 of 47

Customization Commands
Table 1 lists the syntax operation of customization commands recognized by the GUI.

Table 1. Commands for Peripheral Device
     TYPE                  COMMAND                                 DESCRIPTION
 Comment         ;                              Any character after “;” is ignored
 Directives      .event [ID] or .event [name]   The directive is to indicate the start point of action.
                                                See the Event Item List regarding the
                                                number/name of Event.

                                                ID: Event ID, name: Name of Event List
                 .end                           The directive is to indicate the end point of action.
                                                One Event should be started ".event_[ ]" and
                                                ended ".end".
                 .dev_map [name] [id]           Mapping device name to device id. available to use
                                                name or id in the script.

                                                name: the name mapped to the id.
                                                id: I2C slave address declared in Custom Config
                                                (0x56 OPCode)
                 .label [name]                  The directive is to indicate the destination of
                                                goto_if_equal(….), goto_if_greater, goto_if_less
                                                command and goto(...) command.

Analog Devices, Inc.                                                                     Page 7 of 47

Table 2 lists the commands recognized by the GUI for customizing the behavior of the IC.

Table 2. Commands for Operation
     TYPE                  COMMAND                                       DESCRIPTION
 I2C             i2c_write8(dev_id,      address,      Function to write 8-bit hex data
 Command         data)
                 i2c_write8_masked(dev_id,             Function to write 8-bit hex data with mask
                 address, data, mask)
                 i2c_read8(dev_id,       address,      Function to read 8-bit hex data
                 mask)
 GPIO            gpio_write(gpio no, state)            Function to write values to a specific GPIO
 Command
 Register        reg_write(register_name, data,        Function to write values to a specific internal
 Command         mask)                                 register
                 reg_read(register_name, mask)         Function to read values from a specific internal
                                                       register
 Common          delay_ms(time)                        Time delay during (time) ms.
                                                       Time = 1~5 (min: 1, max: 5)
                                                       The delay may cause a timeout issue with PD
                                                       communication, so use this API with care.
 Flow  Control   goto(label_name)                      Jump statement used to go to to a specific label,
 Command                                               cannot be used to jump to another event.
                 goto_if_equal_r(var_read,   data_b,   Jump statement used to go to a specific label if the
                 label_name)                           read value var_read and data_b are equal, cannot
                                                       be used to jump to another event.
                 goto_if_greater_r(var_read, data_b,   Jump statement used to go to a specific label if the
                 label_name)                           read value var_read is greater than or equal to
                                                       data_b cannot be used to jump to another event.
                 goto_if_less_r(var_read,    data_b,   Jump statement used to go to a specific label if the
                 label_name)                           read value var_read is less than or equal to data_b,
                                                       cannot be used to jump to another event.

Analog Devices, Inc.                                                                         Page 8 of 47

Event List
The events related to changes on the physical pins on the USB Type-C connector, MAX77958
pins, or registers as well as requirements according to PD messages are summarized in Table 3.

Table 3. Event List
                                                                                     SAMPLE
 ID          NAME          TRIGGERED BY               TYPICAL USE               CUSTOMIZATION
                                                                                   COMMANDS
                                                                               .dev_map chg 0
                                                1. Hard Reset: When
                                                                               .event
                         Hard_reset PD          MAX77958 is under the
                                                                               REQ_TURN_ON_V
                         message in SOURCE      SOURCE Mode and is
                                                                               BUS
      REQ_TURN_ON        Mode or PR_Swap        required to turn on VBUS
  0                                                                               i2c_write8(chg,
      _VBUS              PD message when        2. PR_Swap: MAX77958 is
                                                                               0x16, 0x8A); I2C
                         VBUS is lower than     requested to become the
                                                                               Mode         Enable,
                         vSafe0V                new SOURCE and is
                                                                               TURN ON VBUS
                                                required to turn on VBUS
                                                                               .end
                         Hard_reset PD          1. Hard Reset: When            .dev_map chg 0
                         message in SOURCE      MAX77958 is under the          .event
                         Mode or PR_Swap        SOURCE Mode and is             REQ_TURN_OFF_
                         PD message when        required to turn off VBUS      VBUS
      REQ_TURN
  1                      VBUS is higher than    2. PR_Swap or USB port            i2c_write8(chg,
      _OFF_VBUS
                         vSafe5V, USB port is   disconnect or enter contract   0x16, 0x82); I2C
                         disconnected, or       as SINK: MAX77958 is the       Mode         Enable,
                         enters contract as     old SOURCE and is required     TURN OFF VBUS
                         SINK                   to turn off VBUS               .end
                                                                               .dev_map chg 0
                                                                               .event
                                                                               DET_ATTACHED_
                         Entering the                                          SNK
      DET_ATTACHED       Attached.SNK state,    SINK Mode: System can pull        i2c_write8(chg,
  4
      _SNK               Rp is detected on      current from VBUS              0x16, 0x85) ); I2C
                         one of the CCx                                        Mode         Enable,
                                                                               Charger on, DCDC
                                                                               on
                                                                               .end
                                                                               .dev_map chg 0
                                                                               .event
                                                                               DET_ATTACHED_
                         Entering the
                                                SOURCE Mode: External          SRC
      DET_ATTACHED       Attached.SRC state,
  5                                             device requests power from        i2c_write8(chg,
      _SRC               Rd is detected on
                                                VBUS                           0x16, 0x8A); I2C
                         one of the CCx
                                                                               Mode Enable, OTG
                                                                               on
                                                                               .end
                                                                               .event
                         Entering the           DRP.Mode (UnAttached           DET_UNATTACHE
      DET_UNATTACH
  6                      unattached DRP         state) MAX77958 is waiting     D_DRP
      ED_DRP
                         mode, CCx is open      for an attached port.             gpio_write(4, 1)
                                                                               .end
                                                                               .event
                                                                               DET_AUDIO_ACC
                         Detected Audio
                                                Audio signal path enable:      ESSORY
      DET_AUDIO          Accessory, Ra is
  7                                             DN to DN1, DP to DP2
      _ACCESSORY         detected on both CC
                                                switches                       reg_write(BC_CTR
                         lines
                                                                               L1_CTRL2,
                                                                               0x0900, 0x3F00)

Analog Devices, Inc.                                                                  Page 9 of 47

                                                                          .end
                                                                          .event
                                                                          DET_DEBUG_SRC
                       Detected Debug
      DET_DEBUG        Accessory, Rd is       Debug path enable: DN to
  8                                                                       reg_write(BC_CTR
      _SRC             detected on both CC    DN1, DP to DP2 switches
                                                                          L1_CTRL2,
                       lines
                                                                          0x0900, 0x3F00)
                                                                          .end
                                                                          .event
                                                                          DET_DEBUG_SNK
                       Detected Debug
      DET_DEBUG        Accessory, Rp is       Debug path enable: DN to
  9                                                                       reg_write(BC_CTR
      _SNK             detected on both CC    DN1, DP to DP2 switches
                                                                          L1_CTRL2,
                       lines
                                                                          0x0900, 0x3F00)
                                                                          .end
                                                                          .event
      DET_CC1          Detected Rp or Rd on   Notify CC1 is active to     DET_CC1_ACTIVE
 11
      _ACTIVE          CC1                    external MUX                   gpio_write(1, 1)
                                                                          .end
                                                                          .event
      DET_CC2          Detected Rp or Rd on   Notify CC2 is active to     DET_CC2_ACTIVE
 12                                                                          gpio_write(1, 0)
      _ACTIVE          CC2                    external MUX
                                                                          .end
                                                                          .dev_map chg 0
                                                                          .event
                                                                          DET_SINKCCI_0P
                       MAX77958 is under
                                                                          5
      DET_SINKCCI      SINK mode, detected    Set charger input current
 16
      _0P5             56kΩ Rp (500mA         limit to 500mA
                                                                          i2c_write8_masked
                       source)
                                                                          (chg, 0x1E, 0x0B,
                                                                          0x0B)
                                                                          .end
                                                                          .dev_map chg 0
                                                                          .event
                                                                          DET_SINKCCI_1P
                       MAX77958 is under
                                                                          5
      DET_SINKCCI      SINK mode, detected    Set charger input current
 17
      _1P5             22kΩ Rp (1.5A          limit to 1.5A
                                                                          i2c_write8_masked
                       source)
                                                                          (chg, 0x1E, 0x1F,
                                                                          0x1F)
                                                                          .end
                                                                          .dev_map chg 0
                                                                          .event
                                                                          DET_SINKCCI_3P
                       MAX77958 is under                                  0
      DET_SINKCCI      SINK mode, detected    Set charger input current
 18
      _3P0             10kΩ Rp (3.0A          limit to 3.0A               i2c_write8_masked
                       source)                                            (chg, 0x1E, 0x3D,
                                                                          0x3D);
                                                                          CHGIN_ILIM 3A
                                                                          .end

Analog Devices, Inc.                                                           Page 10 of 47

                                                                              .dev_map chg 0
                                                                              .event DET_SDP
                                                                                 i2c_read8(chg,
                                                                              0x1E, 0xff)
                                                                              goto_if_less_r(var_
                       Detected SDP          Notify SDP device is
                                                                              read, 0xA, if_0)
 19   DET_SDP          (Standard             connected on the Type-C
                                                                                 goto(if_end)
                       Downstream Port)      connector
                                                                              .label if_0
                                                                                 i2c_write8(chg,
                                                                              0x1E, 0xA)
                                                                              .label if_end
                                                                              .end
                                                                              .dev_map chg 0
                                                                              .event DET_CDP
                                                                                 i2c_read8(chg,
                                                                              0x1E, 0xff)
                                                                              goto_if_less_r(var_
                       Detected CDP          Notify CDP device is
                                                                              read, 0xB, if_0)
 20   DET_CDP          (Charging             connected on the Type-C
                                                                                 goto(if_end)
                       Downstream Port)      connector
                                                                              .label if_0
                                                                                 i2c_write8(chg,
                                                                              0x1E, 0xB)
                                                                              .label if_end
                                                                              .end
                                                                              .dev_map chg 0
                                                                              .event DET_DCP
                                                                                 i2c_read8(chg,
                                                                              0x1E, 0xff)
                                                                              goto_if_less_r(var_
                       Detected DCP          Notify DCP charger is
                                                                              read, 0x4D, if_0)
 21   DET_DCP          (Dedicated Charging   connected on the Type-C
                                                                                 goto(if_end)
                       Port)                 connector
                                                                              .label if_0
                                                                                 i2c_write8(chg,
                                                                              0x1E, 0x4D)
                                                                              .label if_end
                                                                              .end
                                                                              .event
                       Detected VBUS is                                       DET_VSAFE5V
 24   DET_VSAFE5V                            Indication VBUS is present          gpio_write(3, 1)
                       higher than vSafe5V
                                                                              .end

                                             Indication VBUS is not present   .event
                       Detected VBUS is      and Enable External              DET_VSAFE0V
 25   DET_VSAFE0V                                                                gpio_write(3, 0)
                       lower than vSafe0V    discharge circuit on the VBUS
                                             Path                             .end

                                                                              .event
                                             Notify moisture is present on    DET_MOISTURE
 37   DET_MOISTURE     Detected Moisture
                                             the Type-C connector                gpio_write(8, 1)
                                                                              .end
                                                                              .event DET_DRY
                                             Notify no moisture is present       gpio_write(8, 0)
 38   DET_DRY          Detected Dry
                                             on the Type-C connector          .end

Analog Devices, Inc.                                                               Page 11 of 47

                                                                                  .dev_map chg 0
                                                                                  .event
                                                 Required charger input           REC_PD_HARDR
                        In sink mode,            current limit to minimum         ESET_SNK
      REC_PD_HARDR
 40                     received hard-reset      value the sink shall not draw       i2c_write8(chg,
      ESET_SNK
                        PD Message               more than iSafe0mA when          0x1E, 0x00);
                                                 VBUS is driven to vSafe0V        100mA
                                                                                   end
                                                                                  .dev_map chg 0
                                                                                  .event
                        In sink mode, hard-      Required charger current         DONE_PD_HARD
      DONE_PD_HARD      reset sequence           limit to acquired value, the     RESET_SNK
 41
      RESET_SNK         completed                sink can draw current               i2c_write8(chg,
                                                 expected                         0x1E, 0x3D);
                                                                                  CHGIN_ILIM 3A
                                                                                  .end
                                                                                  .event
                                                                                  IRQ_EXT7_INITIAL
      IRQ_EXT7_INITIA   GPIO 8 is initialized    Set the GPIO 8’s                 IZE
 49
      LIZE              before being used        configuration                       gpio_write(8, 0)
                                                                                  .end
                                                                                  .dev_map chg 0
                                                                                  .event DONE_POR
                                                                                     i2c_write8(chg,
                                                 Configure external device
 50   DONE_POR          MAX77958 Power on        register to be initial setting   0x16, 0x80); I2C
                        sequence completed                                        Mode Enable,
                                                                                  Charger=OTG=DC
                                                                                  DC off
                                                                                  .end
                                                                                  .dev_map chg 0
                                                 Indication for GPIO#
 51                     Detected GPIO# of                                         .event
      DET_GPIO#                                  changes from high to low
 ~5                     MAX77958 going                                            DET_GPIO8_LOW
      _LOW
 9                      from high to low                                          gpio_write(7, 1)
                                                                                  .end
                                                                                  .dev_map chg 0
                        MAX77958 Power on                                         .event
                        sequence completed,                                       USBPD_IDLE
                        PD                                                           i2c_write8(chg,
                                                 Set the external device to
 60   USBPD_IDLE        communication chan
                                                 the initial state                0x16, 0x80); I2C
                        ges to the idle state,                                    Mode Enable,
                        waiting for PD                                            Charger=OTG=DC
                        message.                                                  DC off
                                                                                  .end
                                                                                  .event SNK_RDY
                        PD sink is at a stable                                       gpio_write(3, 0)
                        power with no on-                                         .end
                                                 Notify MAX77958 is ready to
 64   SNK_RDY           going negotiation,
                                                 work as Sink
                        ready to respond to
                        requests from Source

Analog Devices, Inc.                                                                   Page 12 of 47

                       PD source is at a                                         .event SRC_RDY
                       stable power with no                                         gpio_write(3, 1)
                                               Notify MAX77958 is ready to       .end
 65   SRC_RDY          on-going negotiation,
                                               work as Source
                       ready to respond to
                       requests from Sink
                       When MAX77958 is                                          .event
                                               Set external charger OTG
 66                    configured source                                         SNK_REQ_POS0
                                               voltage and current limit
 ~7   SNK_REQ_POS#     mode, MAX77958                                               i2c_write8(chg,
                                               based on the system
 1                     advertises the PDO                                        0x1F, 0x8F)
                                               definition.
                       options.                                                  .end
                                                                                 .event
                                                                                 REQ_SWITCH_CO
                                                                                 NTROL_SDP_CDP
      REQ_SWITCH_C
                       Detected SDP or
 73   ONTROL                                   Set USB Switch to close           reg_write(BC_CTR
                       CDP
      _SDP_CDP                                                                   L1_CTRL2,
                                                                                 0x0900, 0x3F00)

                                                                                 .end
                                                                                 .event
                                                                                 REQ_SWITCH_CO
                                                                                 NTROL_DCP
      REQ_SWITCH
 74                    Detected DCP            Set USB Switch to open
      _CONTROL_DCP                                                               reg_write(BC_CTR
                                                                                 L1_CTRL2,
                                                                                 0x0020, 0x0020)
                                                                                 .end
                                                                                 .event
                                                                                 REQ_SWITCH_CO
                                                                                 NTROL_DCDTO
      REQ_SWITCH       Detected Data
 75   _CONTROL_DCD     Contact Detection       Set USB Switch to close           reg_write(BC_CTR
      TO               Timeout                                                   L1_CTRL2,
                                                                                 0x0900, 0x3F00)

                                                                                 .end
                                                                                 .event
                                                                                 DET_SINKPDI_0P
                       When SrcCap
      DET_SINKPDI                              Set input current limit to the    0_TO_0P5
 83                    Current is detected
      _0P0_TO_0P5                              minimum value                        i2c_write8(chg,
                       0<SrcCur<0.5A
                                                                                 0x1E, 0x02)
                                                                                 .end
                                                                                 .event
                                                                                 DET_SINKPDI_0P
                       When SrcCap
      DET_SINKPDI                                                                5_TO_1P0
 84                    Current is detected     Set input current limit to 0.5A
      _0P5_TO_1P0                                                                   i2c_write8(chg,
                       0.5A<=SrcCur<1A
                                                                                 0x1E, 0x0B)
                                                                                 .end
                                                                                 .event
                                                                                 DET_SINKPDI_1P
                       When SrcCap
      DET_SINKPDI                                                                0_TO_1P5
 85                    Current is detected     Set input current limit to 1.0A
      _1P0_TO_1P5                                                                   i2c_write8(chg,
                       1A<=SrcCur<1.5A
                                                                                 0x1E, 0x15)
                                                                                 .end

Analog Devices, Inc.                                                                  Page 13 of 47

                                                                               .event
                                                                               DET_SINKPDI_1P
                       When SrcCap
      DET_SINKPDI                                                              5_TO_2P0
 86                    Current is detected   Set input current limit to 1.5A
      _1P5_TO_2P0                                                                 i2c_write8(chg,
                       1.5A<=SrcCur<2A
                                                                               0x1E, 0x1F)
                                                                               .end
                                                                               .event
                                                                               DET_SINKPDI_2P
                       When SrcCap
      DET_SINKPDI                                                              0_TO_2P5
 87                    Current is detected   Set input current limit to 2.0A
      _2P0_TO_2P5                                                                 i2c_write8(chg,
                       2A<=SrcCur<2.5A
                                                                               0x1E, 0x29)
                                                                               .end
                                                                               .event
                                                                               DET_SINKPDI_2P
                       When SrcCap
      DET_SINKPDI                                                              5_TO_3P0
 88                    Current is detected   Set input current limit to 2.5A
      _2P5_TO_3P0                                                                 i2c_write8(chg,
                       2.5A<=SrcCur<3A
                                                                               0x1E, 0x33)
                                                                               .end
                                                                               .event
                                                                               DET_SINKPDI_3P
                       When SrcCap
      DET_SINKPDI                                                              0_TO_3P5
 89                    Current is detected   Set input current limit to 3.0A
      _3P0_TO_3P5                                                                 i2c_write8(chg,
                       3A<=SrcCur<3.5A
                                                                               0x1E, 0x3D)
                                                                               .end
                                                                               .event
                                                                               DET_SINKPDI_3P
                       When SrcCap
      DET_SINKPDI                                                              5_TO_4P0
 90                    Current is detected   Set input current limit to 3.5A
      _3P5_TO_4P0                                                                 i2c_write8(chg,
                       3.5A<=SrcCur<4A
                                                                               0x1E, 0x47)
                                                                               .end
                                                                               .event
                                             For the input current limit       DET_SINKPDI_UP
                       When SrcCap
      DET_SINKPDI                            higher than 4A, set it            PER_4P0
 91                    Current is detected
      _UPPER_4P0                             according to the customer            i2c_write8(chg,
                       SrcCur>=4A
                                             definition                        0x1E, 0x51)
                                                                               .end

Analog Devices, Inc.                                                                Page 14 of 47

Customization Script GUI Interface

Figure 2. Description of Customization Script Generation GUI

Analog Devices, Inc.                                           Page 15 of 47

Customization Script Download Flowchart
The following flowchart describes the process of using the GUI to edit or create a customization
script and convert the script to programmable data in the IC.

Figure 3. Downloading Customization Script

Analog Devices, Inc.                                                             Page 16 of 47

Customization Update Flowchart for MTP
The following flowchart describes the process of updating .cus script in MTP.

Figure 4. Updating Customization Script

Analog Devices, Inc.                                                            Page 17 of 47

OPCode 0x60 - Action MTP Update Flowchart
The following flowchart describes the process of updating action in MTP block.

Figure 5. Updating Action in MTP Block

Analog Devices, Inc.                                                             Page 18 of 47

OPCode Commands
All configuration and control commands to the MAX77958 are sent and received as a packet using
an OPCode to identify the packet. The MAX77958 contains a 32-byte buffers for reading and
writing OPCode commands.

Simplified Block Diagram of the OPCode Command Process

Figure 6. OPCode Command Process
      1) The host AP sends the OPCode Command.
      2) The MAX77958 FW processes the received command.
      3) When the process of the command by the firmware is finished, a USB Type-C Interrupt
         occurs.
      4) MAX77958 sends INT to notify the host AP that the processing of the command was
         completed.

OPCode Command Format
Messages sent to the MAX77958
The 0x21 register requires an OPCode command. 0x22 to 0x41 registers contain optional
messages written by the user, which should be between 0 and 32 bytes in length. These registers
are not cleared automatically, the values remain until they are overwritten with new messages by
the application processor. The 0x41 register should contain a last message that is recognizable
by the MAX77958.
     Example 1: OPCode command that does not have a message register
            Write 0x21 register: OPCode command
            Write 0x41 register: by default, 0 is recognized by the MAX77958
     Example 2: OPCode command that has one message register
            Write 0x21 register: OPCode command
            Write 0x22 register: optional message
            Write 0x41 register: by default, 0 is recognized by the MAX77958

Analog Devices, Inc.                                                             Page 19 of 47

    Example 3: OPCode command with two message registers
            Write 0x21 register: OPCode command
            Write 0x22 register: first message
            Write 0x23 register: second message
            Write 0x41 register: by default, 0 is recognized by the MAX77958

Messages received from MAX77958
The 0x51 register contains the OPCode command identifying the message type. 0x52 to 0x71
registers contain messages returned by the MAX77958. These registers are not cleared
automatically, values remain until overwritten with new messages by the MAX77958. After
APCmdRes Interrupt occurs, the message returned by the MAX77958 can be read in a flexible
from 0 to 32 bytes.
     Example 1: OPCode command that has a returned message register
            Read 0x51 register: OPCode command returned by MAX77958
            Read 0x52 register: message returned by MAX77958
     Example 2: OPCode command that has two returned message registers
            Read 0x51 register: OPCode command returned by MAX77958
            Read 0x52 register: first message returned by MAX77958
            Read 0x53 register: second message returned by MAX77958

                                        USB-
 ADDR                       DEFAULT               AP
              NAME                        C             B7   B6   B5   B4   B3   B2   B1   B0
 [HEX]                       [HEX]               TYPE
                                        TYPE
 0x20       Reserved          0x00       RO      RW                     0x00
 0x21    AP_DATAOUT0          0x00       RO      RW               AP Request OPCode
 0x22    AP_DATAOUT1          0x00       RO      RW     B7   B6    B5 B4 B3 B2        B1   B0
 0x23    AP_DATAOUT2          0x00       RO      RW     B7   B6    B5 B4 B3 B2        B1   B0
 0x24    AP_DATAOUT3          0x00       RO      RW     B7   B6    B5 B4 B3 B2        B1   B0
 0x25    AP_DATAOUT4          0x00       RO      RW     B7   B6    B5 B4 B3 B2        B1   B0
 0x26    AP_DATAOUT5          0x00       RO      RW     B7   B6    B5 B4 B3 B2        B1   B0
 0x27    AP_DATAOUT6          0x00       RO      RW     B7   B6    B5 B4 B3 B2        B1   B0
 0x28    AP_DATAOUT7          0x00       RO      RW     B7   B6    B5 B4 B3 B2        B1   B0
 0x29    AP_DATAOUT8          0x00       RO      RW     B7   B6    B5 B4 B3 B2        B1   B0
 0x2A    AP_DATAOUT9          0x00       RO      RW     B7   B6    B5 B4 B3 B2        B1   B0
 0x2B    AP_DATAOUT10         0x00       RO      RW     B7   B6    B5 B4 B3 B2        B1   B0
 0x2C    AP_DATAOUT11         0x00       RO      RW     B7   B6    B5 B4 B3 B2        B1   B0
 0x2D    AP_DATAOUT12         0x00       RO      RW     B7   B6    B5 B4 B3 B2        B1   B0
 0x2E    AP_DATAOUT13         0x00       RO      RW     B7   B6    B5 B4 B3 B2        B1   B0
 0x2F    AP_DATAOUT14         0x00       RO      RW     B7   B6    B5 B4 B3 B2        B1   B0
 0x30    AP_DATAOUT15         0x00       RO      RW     B7   B6    B5 B4 B3 B2        B1   B0
 0x31    AP_DATAOUT16         0x00       RO      RW     B7   B6    B5 B4 B3 B2        B1   B0
 0x32    AP_DATAOUT17         0x00       RO      RW     B7   B6    B5 B4 B3 B2        B1   B0
 0x33    AP_DATAOUT18         0x00       RO      RW     B7   B6    B5 B4 B3 B2        B1   B0
 0x34    AP_DATAOUT19         0x00       RO      RW     B7   B6    B5 B4 B3 B2        B1   B0
 0x35    AP_DATAOUT20         0x00       RO      RW     B7   B6    B5 B4 B3 B2        B1   B0
 0x36    AP_DATAOUT21         0x00       RO      RW     B7   B6    B5 B4 B3 B2        B1   B0
 0x37    AP_DATAOUT22         0x00       RO      RW     B7   B6    B5 B4 B3 B2        B1   B0
 0x38    AP_DATAOUT23         0x00       RO      RW     B7   B6    B5 B4 B3 B2        B1   B0

Analog Devices, Inc.                                                             Page 20 of 47

 0x39    AP_DATAOUT24   0x00   RO   RW   B7   B6   B5   B4   B3   B2   B1   B0
 0x3A    AP_DATAOUT25   0x00   RO   RW   B7   B6   B5   B4   B3   B2   B1   B0
 0x3B    AP_DATAOUT26   0x00   RO   RW   B7   B6   B5   B4   B3   B2   B1   B0
 0x3C    AP_DATAOUT27   0x00   RO   RW   B7   B6   B5   B4   B3   B2   B1   B0
 0x3D    AP_DATAOUT28   0x00   RO   RW   B7   B6   B5   B4   B3   B2   B1   B0
 0x3E    AP_DATAOUT29   0x00   RO   RW   B7   B6   B5   B4   B3   B2   B1   B0
 0x3F    AP_DATAOUT30   0x00   RO   RW   B7   B6   B5   B4   B3   B2   B1   B0
 0x40    AP_DATAOUT31   0x00   RO   RW   B7   B6   B5   B4   B3   B2   B1   B0
 0x41    AP_DATAOUT32   0x00   RO   RW   B7   B6   B5   B4   B3   B2   B1   B0
 0x42-
             Not used   0x00   RO   RO                   0x00
 0x50
 0x51     AP_DATAIN0    0x00   RW   RO        MAX77958 Response OPCode
 0x52     AP_DATAIN1    0x00   RW   RO   B7   B6 B5 B4 B3 B2 B1             B0
 0x53     AP_DATAIN2    0x00   RW   RO   B7   B6 B5 B4 B3 B2 B1             B0
 0x54     AP_DATAIN3    0x00   RW   RO   B7   B6 B5 B4 B3 B2 B1             B0
 0x55     AP_DATAIN4    0x00   RW   RO   B7   B6 B5 B4 B3 B2 B1             B0
 0x56     AP_DATAIN5    0x00   RW   RO   B7   B6 B5 B4 B3 B2 B1             B0
 0x57     AP_DATAIN6    0x00   RW   RO   B7   B6 B5 B4 B3 B2 B1             B0
 0x58     AP_DATAIN7    0x00   RW   RO   B7   B6 B5 B4 B3 B2 B1             B0
 0x59     AP_DATAIN8    0x00   RW   RO   B7   B6 B5 B4 B3 B2 B1             B0
 0x5A     AP_DATAIN9    0x00   RW   RO   B7   B6 B5 B4 B3 B2 B1             B0
 0x5B     AP_DATAIN10   0x00   RW   RO   B7   B6 B5 B4 B3 B2 B1             B0
 0x5C     AP_DATAIN11   0x00   RW   RO   B7   B6 B5 B4 B3 B2 B1             B0
 0x5D     AP_DATAIN12   0x00   RW   RO   B7   B6 B5 B4 B3 B2 B1             B0
 0x5E     AP_DATAIN13   0x00   RW   RO   B7   B6 B5 B4 B3 B2 B1             B0
 0x5F     AP_DATAIN14   0x00   RW   RO   B7   B6 B5 B4 B3 B2 B1             B0
 0x60     AP_DATAIN15   0x00   RW   RO   B7   B6 B5 B4 B3 B2 B1             B0
 0x61     AP_DATAIN16   0x00   RW   RO   B7   B6 B5 B4 B3 B2 B1             B0
 0x62     AP_DATAIN17   0x00   RW   RO   B7   B6 B5 B4 B3 B2 B1             B0
 0x63     AP_DATAIN18   0x00   RW   RO   B7   B6 B5 B4 B3 B2 B1             B0
 0x64     AP_DATAIN19   0x00   RW   RO   B7   B6 B5 B4 B3 B2 B1             B0
 0x65     AP_DATAIN20   0x00   RW   RO   B7   B6 B5 B4 B3 B2 B1             B0
 0x66     AP_DATAIN21   0x00   RW   RO   B7   B6 B5 B4 B3 B2 B1             B0
 0x67     AP_DATAIN22   0x00   RW   RO   B7   B6 B5 B4 B3 B2 B1             B0
 0x68     AP_DATAIN23   0x00   RW   RO   B7   B6 B5 B4 B3 B2 B1             B0
 0x69     AP_DATAIN24   0x00   RW   RO   B7   B6 B5 B4 B3 B2 B1             B0
 0x6A     AP_DATAIN25   0x00   RW   RO   B7   B6 B5 B4 B3 B2 B1             B0
 0x6B     AP_DATAIN26   0x00   RW   RO   B7   B6 B5 B4 B3 B2 B1             B0
 0x6C     AP_DATAIN27   0x00   RW   RO   B7   B6 B5 B4 B3 B2 B1             B0
 0x6D     AP_DATAIN28   0x00   RW   RO   B7   B6 B5 B4 B3 B2 B1             B0
 0x6E     AP_DATAIN29   0x00   RW   RO   B7   B6 B5 B4 B3 B2 B1             B0
 0x6F     AP_DATAIN30   0x00   RW   RO   B7   B6 B5 B4 B3 B2 B1             B0
 0x70     AP_DATAIN31   0x00   RW   RO   B7   B6 B5 B4 B3 B2 B1             B0
 0x71     AP_DATAIN32   0x00   RW   RO   B7   B6 B5 B4 B3 B2 B1             B0

Analog Devices, Inc.                                              Page 21 of 47

OPCode Example
This is an example of using OPCode in AP and how to write OPCode.
   •   A DRP shall transition to either Unattached.SNK or Unattached.SRC.
   •   Request Sink Mode setting from AP to MAX77958 via Customer Configuration
       OPCode(0x56)
       // I2C address, Register Address, OPCode Command
       I2C_WRITE(0x4A, 0x21, 0x56)
       // I2C address, Register Address, Sink mode only
       I2C_WRITE(0x4A, 0x22, 0x50)
       // I2C address, Register Address, USB VID 0x0B6A
       I2C_WRITE(0x4A, 0x23, 0x6A)
       I2C_WRITE(0x4A, 0x24, 0x0B)
       // I2C address, Register Address, USB PID 0x6860
       I2C_WRITE(0x4A, 0x25, 0x60)
       I2C_WRITE(0x4A, 0x26, 0x68)
       // I2C address, Register Address, SRC PDO voltage 5000mV
       I2C_WRITE(0x4A, 0x27, 0x00)
       I2C_WRITE(0x4A, 0x28, 0x64)
       // I2C address, Register Address, SRC PDO Max Current 1500mV
       I2C_WRITE(0x4A, 0x29, 0x00)
       I2C_WRITE(0x4A, 0x2A, 0x96)
       // I2C address, Register Address, End of command
       // End of command shall be written to be recognized by MAX77958
       I2C_WRITE(0x4A, 0x41, 0x00)
   •   MAX77958’s firmware sets the Sink Mode only
   •   TYPE-C FSM of MAX77958 shall set Unattached.SNK
   •   When APCmdRes Interrupt occurs, AP can check the setting result from 0x52 to 0x71
       register.
       // Slave address, Register Address, Respond Data
       I2C_READ(0x4A, 0x51, 0x56)

Analog Devices, Inc.                                                        Page 22 of 47

OPCode Register Information
This is read/write register information of OPCode.

0x01: BC CTRL1 Config Read
          BITFIELD             BC_CTRL1                  RESET                             0X81
 ADDR
             b7        b6       b5      b4                 b3            b2               b1             b0
 0x21                                                    0x01

 0x51                                                    0x01

 0x52      DCDCpl      RSVD    RSVD        RSVD          NikonDet        RSVD          CHGDetMan      CHGDetEn

                               RES
     BITFIELD          BIT                        DESCRIPTION                                DECODE
                                ET
                                                                                  0 = 2000ms
        DCDCpl          7       1      Data Contact Detection Wait Time
                                                                                  1 = 900ms
        RSVD           6:4      0      Reserved
                                                                                  0 = Not enabled
  Nikon Detection       3       0      Nikon Charger Detection
                                                                                  1 = Enabled
        RSVD            2       0      Reserved
                                                                                  0 = Not enabled
                                       Force Manual Run of Charger
    CHGDetMan           1       0                                                 1 = Request manual run of
                                       Detection, Bit Auto Resets to 0
                                                                                  charger detection
                                                                                  0 = Not enabled
                                                                                  1 = Enabled, charger
     CHGDetEn           0       1      Enable Charger Detection                   detection runs every time
                                                                                  VBUS > VVBDET and DetAbrt =
                                                                                  0

0x02: BC CTRL1 Config Write
          BITFIELD              BC_CTRL1                     RESET                           0X81
 ADDR
               b7        b6           b5           b4           b3               b2           b1          b0
 0x21                                                    0x02
 0x22      DCDCpl       RSVD        RSVD          RSVD        NikonDet          RSVD      CHGDetMan     CHGDetEn

 0x51                                                    0x02

0x03: BC CTRL2 Config Read
          BITFIELD             BC_CTRL2                   RESET                            0X00
 ADDR
             b7         b6       b5           b4            b3           b2               b1             b0
 0x21                                                    0x03

Analog Devices, Inc.                                                                                Page 23 of 47

 0x51                                                   0x03

 0x52        RSVD       RSVD      DNMonEn    DPDNMan             DPDrv                       DNDrv

     BITFIELD           BIT       RESET             DESCRIPTION                            DECODE
         RSVD           7:6         0        Reserved
                                                                                  0 = Disabled. DNVDATREF
                                             Enable monitor of D- line with       will be set to 0
     DNMonEn             5          0
                                             VDATREF comparator
                                                                                  1 = Enabled
                                                                                  0 = Resources on DP and
                                                                                  DN are controlled by charger
                                                                                  detection (ChgDetEn bit)
     DPDNMan             4          0        DP and DN Manual Control
                                                                                  1 = Drive voltages on DP
                                                                                  and DN according to DPDrv
                                                                                  and DNDrv values
                                                                                  0 = Ground (20K resistor to
                                                                                  GND)
         DPDrv          3:2         0        Force voltage on DP                  1 = 0.6V
                                                                                  2 = 3.0V
                                                                                  3 = Open
                                                                                  0 = Ground (20K resistor to
                                                                                  GND)
        DNDrv           1:0         1        Force voltage on DN                  1 = 0.6V
                                                                                  2 = 3.0V
                                                                                  3 = Open

0x04: BC CTRL2 Config Write
           BITFIELD               BC_CTRL2                   RESET                         0X00
 ADDR
                b7       b6             b5         b4            b3              b2         b1            b0
 0x21                                                   0x04
 0x22        RSVD       RSVD       DNMonEn      DPDNMan                  DPDrv                    DNDrv

 0x51                                                   0x04

0x05: Control1 Read
            BITFIELD                 CONTROL1                         RESET                  0X00
 ADDR
               b7            b6         b5                 b4           b3            b2      b1          b0
  0x21                                                    0x05

  0x51                                                    0x05

  0x52           RSVD    RSVD                      COMP2Sw                                 COMN1Sw

      BITFIELD            BIT       RESET            DESCRIPTION                           DECODE

Analog Devices, Inc.                                                                              Page 24 of 47

         RSVD               7:6            0      Reserved
                                                                              000 = Open
                                                  Control of COMP2            001 = COMP2 connected to
     COMP2Sw                5:3            0
                                                  Switches                    DN2(USB)
                                                                              010 to 111 = Open
                                                                              000 = Open
                                                  Control of COMN1            001 = COMN1 connected to
     COMN1Sw                2:0            0
                                                  Switches                    DN1(USB)
                                                                              010 to 111 = Open

0x06: Control1 Write
          BITFIELD                 CONTROL1                    RESET                   0X00
 ADDR
                b7       b6             b5            b4           b3        b2            b1          b0
 0x21                                                      0x06
 0x22       RSVD        RSVD                       COMP2Sw                            COMN1Sw

 0x51                                                      0x06

0x0B: CC Control1 Read
          BITFIELD                CC_CONTROL1                     RESET                    0X81
 ADDR
             b7         b6           b5       b4                    b3         b2           b1         b0
  0x21                                                     0x0B

 0x51                                                      0x0B
                       CCTry
 0x52      CCVcnEn                  RSVD        CCDbgSrcEn    CCDbgSnkEn    CCAudEn    CCSrcEn      CCSnkEn
                       SnkEn

     BITFIELD          BIT        RESET              DESCRIPTION                      DECODE

                                                                            0 = Force VCONN off (both
                                                                            external boost converter and
                                                                            VCONN switch)
     CCVcnEn            7           1          Force State of VCONN

                                                                            1 = Automatic operation based
                                                                            on State Machine

                                               Allow Transition to TrySnk   0 = Try SINK is disabled
    CCTrySnkEn          6           0
                                               States                       1 = Try SINK is enabled
         RSVD           5           0          Reserved
                                               Enable Detection of Type-C   0 = Disabled
   CCDbgSrcEn           4           0
                                               Debug Source Adapter         1 = Enabled
                                               Enable Detection of Type-C   0 = Disabled
   CCDbgSnkEn           3           0
                                               Debug Sink Adapter           1 = Enabled
     CCAudEn            2           0                                       0 = Disabled

Analog Devices, Inc.                                                                            Page 25 of 47

                                                 Enable Detection of Type-C
                                                                               1 = Enabled
                                                 Audio Adapter
                                                 Enable Detection of Type-C    0 = Disabled
     CCSrcEn             1          0
                                                 Source Adapter                1 = Enabled
                                                 Enable Detection of Type-C    0 = Disabled
     CCSnkEn             0          1
                                                 Sink Adapter                  1 = Enabled

0x0C: CC Control1 Write
         BITFIELD                 CC_CONTROL1                       RESET                    0X81
 ADDR
            b7               b6             b5          b4           b3          b2           b1         b0
 0x21                                                        0x0C
 0x22     CCVcnEn      CCTrySnkEn       RSVD         CCDbgSrcEn   CCDbgSnkEn   CCAudEn    CCSrcEn      CCSnkEn

 0x51                                                        0x0C

0x11: CC Control4 Read
         BITFIELD                 CC_CONTROL4                       RESET                     0X00
 ADDR
            b7           b6          b5       b4                      b3          b2           b1         b0
 0x21                                                        0x11

 0x51                                                        0x11

 0x52    CCVcnOcpEn     RSVD            RSVD            RSVD         RSVD       RSVD            CCDrpPhase

     BITFIELD           BIT         RESET               DESCRIPTION                       DECODE

                                                                               0 = VCONN
                                                                               OCP does have impact on
                                                                               VCONN SW and BOOST

    CCVcnOcpEn            7             0          VCONN OCP enable

                                                                               1 = VCONN OCP turn-off VCONN
                                                                               SW and BOOST after 12ms

        RSVD             6:1            0          Reserved
                                                                               00 = 35%
                                                   Percent of time device      01 = 40%
                                                   is acting                   10 = 45%
    CCDrpPhase           1:0            0          as Unattached.SRC
                                                   when CCSNKSRC=1
                                                   and CCSRCSNK=1              11 = 50%

Analog Devices, Inc.                                                                               Page 26 of 47

0x12: CC Control4 Write
          BITFIELD                CC_CONTROL4                       RESET                             0X00
 ADDR
             b7            b6            b5            b4            b3              b2               b1            b0
 0x21                                                         0x12
 0x22     CCVcnOcpEn       RSVD          RSVD          RSVD          RSVD       RSVD                    CCDrpPhase

 0x51                                                         0x12

0x23: GPIO Control Read
                                                                            RES
              NAME                            GPIO_READ
  ADDR                                                                       ET
                  b7              b6            b5             b4            b3             b2             b1       b0
  0x21                                                        0x23

  0x51                                                        0x23
                              GPIO3           GPIO2                         GPIO1          GPIO1        GPIO0      GPIO0
  0x52      GPIO3 Output                                 GPIO2 Direction
                             Direction        Output                        Output        Direction     Output    Direction

                              GPIO7           GPIO6                         GPIO5          GPIO5        GPIO4      GPIO4
  0x53      GPIO7 Output                                 GPIO6 Direction
                             Direction        Output                        Output        Direction     Output    Direction

                                                                                                        GPIO8      GPIO8
  0x54         RSVD             RSVD          RSVD            RSVD          RSVD           RSVD
                                                                                                        Output    Direction

         BITFIELD                 BIT      RESET        DESCRIPTION                            DECODE
                                                                            0 = Low
        GPIO3_OUT                 7             0      GPIO3 Output
                                                                            1 = High
                                                       GPIO3                0 = Input
    GPIO3_Direction               6             0
                                                       Direction            1 = Output
                                                                            0 = Low
        GPIO2_OUT                 5             0      GPIO2 Output
                                                                            1 = High
                                                       GPIO2                0 = Input
    GPIO2_Direction               4             0
                                                       Direction            1 = Output
                                                                            0 = Low
        GPIO1_OUT                 3             0      GPIO1 Output
                                                                            1 = High
                                                       GPIO1                0 = Input
    GPIO1_Direction               2             0
                                                       Direction            1 = Output
                                                                            0 = Low
        GPIO0_OUT                 1             0      GPIO0 Output
                                                                            1 = High
                                                       GPIO0                0 = Input
    GPIO0_Direction               0             0
                                                       Direction            1 = Output
                                                                            0 = Low
        GPIO7_OUT                 7             0      GPIO7 Output
                                                                            1 = High
    GPIO7_Direction               6             0                           0 = Input

Analog Devices, Inc.                                                                                         Page 27 of 47

                                                   GPIO7
                                                                          1 = Output
                                                   Direction
                                                                          0 = Low
      GPIO6_OUT                  5           0     GPIO6 Output
                                                                          1 = High
                                                   GPIO6                  0 = Input
    GPIO6_Direction              4           0
                                                   Direction              1 = Output
                                                                          0 = Low
      GPIO5_OUT                  3           0     GPIO5 Output
                                                                          1 = High
                                                   GPIO5                  0 = Input
    GPIO5_Direction              2           0
                                                   Direction              1 = Output
                                                                          0 = Low
      GPIO4_OUT                  1           0     GPIO4 Output
                                                                          1 = High
                                                   GPIO4                  0 = Input
    GPIO4_Direction              0           0
                                                   Direction              1 = Output
                                                                          0 = Low
      GPIO8_OUT                  1           0     GPIO8 Output
                                                                          1 = High
                                                   GPIO8                  0 = Input
    GPIO8_Direction              0           0
                                                   Direction              1 = Output

0x24: GPIO Control Write
                    NAME                       GPIO_WRITE                  RESET
  ADDR
                      b7                b6         b5           b4        b3           b2         b1        b0
  0x21                                                     0x24
                                       GPIO3      GPIO2      GPIO2       GPIO1        GPIO1      GPIO0     GPIO0
  0x22            GPIO3 Output
                                      Direction   Output    Direction    Output      Direction   Output   Direction

                                       GPIO7      GPIO6      GPIO6       GPIO5        GPIO5      GPIO4     GPIO4
  0x23            GPIO7 Output
                                      Direction   Output    Direction    Output      Direction   Output   Direction

                                                                                                 GPIO8     GPIO8
  0x24               RSVD              RSVD       RSVD       RSVD         RSVD        RSVD
                                                                                                 Output   Direction

  0x51                                                     0x24

0x27: GPIO0 GPIO1 ADC Read
           NAME                      SBU_READ                           RESET                    0X00
 ADDR
             b7            b6             b5               b4            b3           b2         b1         b0
  0x21                                                     0x27

  0x51                                                     0x27
  0x52                                                     SBU1
  0x53                                                     SBU2

Analog Devices, Inc.                                                                               Page 28 of 47

     BITFIELD          BIT     RESET     DESCRIPTION                        DECODE
                                        Indicates value
         SBU1          7:0          0   on VBUS Input of     The value of SBU1 ADC range
                                        SBU1

                                        Indicates value
         SBU2          7:0          0   on VBUS Input of     The value of SBU2 ADC range
                                        SBU2

0x2F: Get Sink Cap
The Get_Sink_Cap (get sink capabilities) message can be sent by a port to request the sink
capabilities and dual-role power capability of its port partner. The port responds by returning a
Sink_Capabilities message.
           BITFIELD             GET_SRC_CAP                    RESET
 ADDR
              b7        b6           b5              b4          b3        b2          b1      b0
  0x21                                             0x2F

  0x51                                             0x2F

  0x52                   NumOfPDO                  PwrRole     DataRole   RSVD     RSVD       RSVD

  0x53                                          PDO1[7:0]
  0x54                                          PDO1[15:8]
  0x55                                         PDO1[23:16]
  0x56                                         PDO1[31:24]
   •••                                         •••••••••••••
                                                PDOx[7:0]
                                                PDOx[15:8]
                                               PDOx[23:16]
                                               PDOx[31:24]

      BITFIELD          BIT    RESET           DESCRIPTION                        DECODE
                                        Number of Power Data
     NumOfPDO           7:5
                                        Objects
                                        Power Role of Current             0 = Sink
      PwrRole            4
                                        Source                            1 = Source
                                                                          0 = UFP
      DataRole           3              Data Role of Current Source
                                                                          1 = DFP
         RSVD           2:0             Reserved

Analog Devices, Inc.                                                                    Page 29 of 47

0x30: Current Src Cap
The PDO is requested by sink and accepted by source among source capabilities.
           BITFIELD     CUR_SEL_SRC_CAP         RESET
 ADDR
              b7        b6     b5     b4          b3            b2       b1             b0
  0x21                                          0x30

  0x51                                           0x30
  0x52       RSVD      RSVD          SEL_PDO_POS                          NumOfPDO
  0x53                                        PDO1[7:0]
  0x54                                        PDO1[15:8]
  0x55                                       PDO1[23:16]
  0x56                                       PDO1[31:24]
   •••                                       •••••••••••••
                                              PDOx[7:0]
                                              PDOx[15:8]
                                             PDOx[23:16]
                                             PDOx[31:24]

     BITFIELD          BIT     RESET     DESCRIPTION                      DECODE
         RSVD          7:6              Reserved
                                                             0b : Unselected – Should send
                                                             request message using OPCODE
                                        Selected             0x32, SrcCap Request
   SEL_PDO_POS         5:3
                                        Position of POD
                                                             1b – 7b : Selected PDO number

                                        Number of
     NumOfPDO          2:0              Power Data
                                        Objects

0x31: Get Source Cap
The Get_Source_Cap (get source capabilities) message can be sent by a port to request the
source capabilities and dual-role power capability of its port partner. The port responds by
returning a Source_Capabilities message. The port responds by returning a Source_Capabilities
Message Addr.
           BITFIELD            GET_SRC_CAP                   RESET
 ADDR
              b7       b6          b5            b4            b3       b2      b1           b0
  0x21                                           0x31

  0x51                                           0x31

  0x52                 NumOfPDO                PwrRole       DataRole   RSVD   RSVD          RSVD

Analog Devices, Inc.                                                                 Page 30 of 47

  0x53                                           PDO1[7:0]
  0x54                                           PDO1[15:8]
  0x55                                          PDO1[23:16]
  0x56                                          PDO1[31:24]
   •••                                          •••••••••••••
                                                 PDOx[7:0]
                                                 PDOx[15:8]
                                                PDOx[23:16]
                                                PDOx[31:24]

      BITFIELD           BIT    RESET           DESCRIPTION                      DECODE

                                          Number of Power Data
     NumOfPDO            7:5
                                          Objects

                                          Power Role of Current          0 = Sink
         PwrRole          4
                                          Source                         1 = Source
                                                                         0 = UFP
       DataRole           3               Data Role of Current Source
                                                                         1 = DFP
         RSVD            2:0              Reserved

0x32: Src Cap Request
Send the request message as the response of Source_Capablities message to port partner.
            BITFIELD             SRC_CAP_REQ                    RESET
  ADDR
               b7        b6           b5              b4          b3      b2          b1      b0
  0x21                                               0x32
  0x22        RSVD      RSVD          RSVD            RSVD        RSVD         Req_PDO_Pos

  0x51                                               0x32

      BITFIELD           BIT     RESET           DESCRIPTION                     DECODE
         RSVD            7:3               Reserved
   Req_PDO_Pos           2:0               Request Position of POD

0x33: Set Src Cap
Set the current device’s source capabilities.
            BITFIELD             SET_SRC_CAP                    RESET
  ADDR
               b7        b6           b5              b4          b3      b2          b1      b0
  0x21                                               0x33
  0x22        RSVD      RSVD          RSVD            RSVD        RSVD           NumOfPDO
  0x23                                           PDO1[7:0]

Analog Devices, Inc.                                                                   Page 31 of 47

  0x24                                         PDO1[15:8]
  0x25                                        PDO1[23:16]
  0x26                                        PDO1[31:24]
   •••                                        •••••••••••••
                                               PDOx[7:0]
                                               PDOx[15:8]
                                              PDOx[23:16]
                                              PDOx[31:24]

  0x51      0x33

     BITFIELD          BIT     RESET           DESCRIPTION                    DECODE
         RSVD          7:3                Reserved
                                          Number of Power Data
     NumOfPDO          2:0
                                          Objects

0x34: Send Get Request
Send the Get request Message and get the response by port partner.
            BITFIELD          SEND_GET_REQ                    RESET
 ADDR
               b7      b6          b5              b4           b3      b2       b1         b0
  0x21                                            0x34
  0x22        RSVD     RSVD        RSVD              RSVD     RSVD           Req_Msg_Type
  0x23                                           ExtDB0
  0x24                                           ExtDB1

  0x51                                            0x34

     BITFIELD          BIT    RESET            DESCRIPTION                    DECODE
         RSVD          7:3             Reserved
                                                                      000 –
                                                                      Get_Source_Cap_Extended
                                                                      001 – Get_Status
   Req_Msg_Type        2:0             Request Message Type           010 – Get_Battery_Cap
                                                                      011 – Get_Battery_Status
                                                                      100 –
                                                                      Get_Manufacturer_Info
                                       Extended    Data   Block
         ExtDB0        7:0             (GBCDB,     GBSDB,    or
                                       GMIDB) offset 0
                                       Extended    Data   Block
         ExtDB1        7:0
                                       (GMIDB) offset 1

Analog Devices, Inc.                                                               Page 32 of 47

0x35: Read the Response for Get Request
Read the response for the Get Request message by the port partner.
This OPCode should be used after PDMsg (0x35–0x39) interrupt happens.
          BITFIELD             READ_GET_REQ_RESP          RESET
 ADDR
             b7          b6            b5        b4         b3       b2        b1       b0
  0x21                                         0x35

  0x51                                              0x35
  0x52                 RespMsgType                                MsgDataLen
  0x53                       Data Object(s) or Extended Message Header[7:0]
  0x54                       Data Object(s) or Extended Message Header[15:8]
  0x55                                    Data Object(s) or Data
  0x56                                    Data Object(s) or Data
  0x57                                    Data Object(s) or Data
  0x58                                    Data Object(s) or Data
   •••                                          •••••••••••••
                                          Data Object(s) or Data
                                          Data Object(s) or Data
                                          Data Object(s) or Data
                                          Data Object(s) or Data

     BITFIELD            BIT      RESET       DESCRIPTION                   DECODE
                                                                   0x00 –
                                                                   Source_Cap_Extended
                                                                   0x01 – Status
   RespMsgType           7:5              Response Message Type    0x02 – Battery_Cap
                                                                   0x03 – Battery_Status
                                                                   0x04 – Manufacturer_Info
                                          Message Data Length
    MsgDataLen           4:0              Bytes except Message
                                          Header

0x36: Send Get Response
Send the response for Get Request message to port partner.
           BITFIELD              SEND_GET_RESP            RESET
 ADDR
              b7         b6           b5           b4       b3       b2        b1       b0
  0x21                                            0x36
  0x22                 RespMsgType                                MsgDataLen
  0x23                        Data Objcet(s) or Extended Message Header[7:0]
  0x24                       Data Object(s) or Extended Message Header[15:8]
  0x25                                     Data Object(s) or Data

Analog Devices, Inc.                                                            Page 33 of 47

  0x26                                   Data Object(s) or Data
  0x27                                   Data Object(s) or Data
  0x28                                   Data Object(s) or Data
  0x29                                       •••••••••••••
  0x2A                                   Data Object(s) or Data
                                         Data Object(s) or Data
                                         Data Object(s) or Data
                                         Data Object(s) or Data

  0x51                                           0x36

      BITFIELD          BIT   RESET           DESCRIPTION                     DECODE
                                                                    0x00 –
                                                                    Source_Cap_Extended
                                                                    0x01 – Status
    RespMsgType         7:5            Response Message Type        0x02 – Battery_Cap
                                                                    0x03 – Battery_Status
                                                                    0x04 – Manufacturer_Info

                                       Message Data Length Bytes
     MsgDataLen         4:0
                                       except Message Header

0x37: Send Swap Request
Send the Swap Request message to port partner.
           NAME                SWAP_REQ                   RESET
 ADDR
               b7      b6         b5              b4        b3        b2        b1            b0
  0x21                                           0x37
  0x22                                                                           Swap_Name

  0x51                                           0x37
  0x52                                           Result

     BITFIELD          BIT    RESET    DESCRIPTION                      DECODE
                                                          0x00 : N/A
                                                          0x01 : DR SWAP
   Swap_Name           1:0             Swap
                                                          0x02 : PR SWAP
                                                          0x03 : VCONN SWAP
                                                          0x00 : Wait
                                                          0x01 : Accepted from port partner
      Result           7:0             Result of Swap
                                                          0x02 : Rejected from port partner
                                                          0xFA : Not Support

Analog Devices, Inc.                                                               Page 34 of 47

                                                                  0xFC : No Connection
                                                                  0xFD : Already Running
                                                                  0xFE : Moisture detection is enabled
                                                                  0xFF : Fail to send request

0x38: Send Swap Response
Set the Swap Response for the Swap Request message.
            NAME              SWAP_REQ_RESPONSE                   RESET                 0x00
 ADDR
             b7         b6              b5              b4          b3           b2      b1          b0
  0x21                                                  0x38
  0x22                                  PR_SWP_Resp                 DR_SWP_Resp         VCONN_SWP_Resp

  0x51                                                  0x38

     BITFIELD           BIT      RESET       DESCRIPTION                         DECODE
                                                                  0x00 : Accept Sink Role, Reject Source
                                                                  Role
                                                                  0x01 : Accept Source Role, Reject Sink
                                             Response of PR       Role
  PR_SWP_Resp           5:4
                                             Swap                 0x02 : Accept Dual Role (Sink or
                                                                  Source)
                                                                  0x03 : Wait
                                                                  0x00 : Accept UFP Role, Reject DFP
                                                                  Role
                                             Response of DR       0x01 : Accept DFP Role, Reject UFP
  DR_SWP_Resp           3:2                                       Role
                                             Swap
                                                                  0x02 : Accept Dual Role (UFP or DFP)
                                                                  0x03 : Wait
                                                                  0x00 : Accept Turn Off VCONN, Reject
                                                                  Turn On VCONN
                                             Response of          0x01 : Accept Turn On VCONN, Reject
 VCONN_SWP_Resp         1:0                                       Turn Off VCONN
                                             VCONN Swap
                                                                  0x02 : Accept Turn Off/On VCONN
                                                                  0x03 : Wait

0x3A: APDO SrcCap Request
                   NAME             APDO_SRCCAP_REQUEST                         RESET
    ADDR
                       b7          b6              b5                b4          b3     b2      b1       b0
     0x21                                                  0x3A
     0x22                                          REQ_APDO_POS
     0x23                                      OUTPUT_VOLTAGE_LOW
     0x24                                      OUTPUT_VOLTAGE_HIGH

Analog Devices, Inc.                                                                         Page 35 of 47

     0x25              RSVD                  OPERATING_CURRENT

     0x51                                    0x3A
     0x52                                   Result
            BITFIELD          BIT   RESET   DESCRIPTION               DECODE
                                            Request
      REQ_APDO_POS            7:0                             PDO Position
                                            Position of PDO
                                                              0x0000 = Min Output
                                                              Voltage
                                                              0x0001 = 20mV (Low 0x01,
                                                              High 0x00)
                                                              0x0002 = 40mV (Low 0x02,
                                                              High 0x00)

                                                              0x0003 = 60mV

                                            Low bit of
  OUTPUT_VOLTAGE_LOW          7:0                             0x0004 = 80mV
                                            Output Voltage

                                                              0x0005 = 100mV
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

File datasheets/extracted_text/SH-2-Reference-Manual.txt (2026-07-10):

            SH-2 Reference Manual

      Document Number: 1000-3625
      Document Revision: 1.9
                  Date: June 2021

CEVA Technologies, Inc. 15245 Shady Grove Road, Suite 400 Rockville, MD 20850
                    © 2021, CEVA, Inc. All rights reserved

                                                  Table of Contents
LIST OF FIGURES ............................................................................................................... 4
1.0   INTRODUCTION ....................................................................................................... 7
   1.1        Intended Audience ................................................................................................................. 7
   1.2        Scope ..................................................................................................................................... 7
   1.3        Revision History ..................................................................................................................... 7

2.0        SENSOR USAGE ..................................................................................................... 8
3.0        HOST INTERFACES............................................................................................... 11
   3.1     UART Interface.....................................................................................................................11
      3.1.1 H-format Output Packet....................................................................................................11
      3.1.2 UART Inputs .....................................................................................................................12

4.0        CONFIGURATION .................................................................................................. 14
   4.1     Flash Storage .......................................................................................................................14
   4.2     RAM Storage ........................................................................................................................14
   4.3     Records ................................................................................................................................14
      4.3.1 Static Calibration ..............................................................................................................14
      4.3.2 Dynamic Calibration .........................................................................................................14
      4.3.3 MotionEngine Power Management and Stability Classifier .............................................15
      4.3.4 Sensor Orientation ...........................................................................................................15
      4.3.5 AR/VR Stabilization ..........................................................................................................16
      4.3.6 Significant Motion Detector Configuration ........................................................................17
      4.3.7 Shake Detector Configuration ..........................................................................................17
      4.3.8 Serial Number ..................................................................................................................18
      4.3.9 Maximum Fusion Period ..................................................................................................18
      4.3.10     Environmental Sensor Calibration .............................................................................18
      4.3.11     Ambient Light Sensor (ALS) Calibration ....................................................................19
      4.3.12     Proximity Sensor Calibration ......................................................................................19
      4.3.13     Flip Detector Configuration ........................................................................................20
      4.3.14     Pickup Detector Configuration ...................................................................................21
      4.3.15     Stability Detector Configuration .................................................................................23
      4.3.16     Activity Tracker Configuration ....................................................................................23
      4.3.17     Sleep Detector Configuration .....................................................................................23
      4.3.18     Tilt Detector Configuration .........................................................................................24
      4.3.19     Pocket Detector Configuration ...................................................................................24
      4.3.20     Circle Detector Configuration .....................................................................................25
      4.3.21     User Record ...............................................................................................................26
      4.3.22     MotionEngine Time Source Selection ........................................................................26
      4.3.23     UART Output Format Selection .................................................................................26
      4.3.24     Gyro-Integrated Rotation Vector ................................................................................26
      4.3.25     Fusion Control Record ...............................................................................................28
      4.3.26     Simple Calibration Configuration ...............................................................................28
      4.3.27     Configuration Records Summary ...............................................................................28
      4.3.28     Version Information ....................................................................................................29

5.0        OPERATION ........................................................................................................... 30
   5.1     Sensor Metadata ..................................................................................................................30
      5.1.1 Sensor-Specific Metadata ................................................................................................33

                                              © 2021 CEVA, Inc. All rights reserved.                                                                     1

                                                                 SH-2 Reference Manual                                            1000-3625 v1.9

  5.2     Input Reports ........................................................................................................................33
  5.3     Output Reports .....................................................................................................................34
  5.4     Feature Reports ...................................................................................................................34
     5.4.1 Rate Control .....................................................................................................................34
     5.4.2 Threshold Control .............................................................................................................34
     5.4.3 Batch Operation ...............................................................................................................35
  5.5     Sensor Triggering .................................................................................................................35
  5.6     Interactive Calibration ..........................................................................................................36

6.0       REPORT DESCRIPTIONS ...................................................................................... 38
  6.1     Report ID Convention ...........................................................................................................38
  6.2     Summary ..............................................................................................................................38
  6.3     Configuration Reports ..........................................................................................................39
     6.3.1 Product ID Request (0xF9) ..............................................................................................39
     6.3.2 Product ID Response (0xF8) ............................................................................................39
     6.3.3 FRS Write Request (0xF7) ...............................................................................................40
     6.3.4 FRS Write Data Request (0xF6) ......................................................................................40
     6.3.5 FRS Write Response (0xF5) ............................................................................................41
     6.3.6 FRS Read Request (0xF4) ...............................................................................................42
     6.3.7 FRS Read Response (0xF3) ............................................................................................42
     6.3.8 Command Request (0xF2) ...............................................................................................43
     6.3.9 Command Response (0xF1) ............................................................................................43
  6.4     Commands ...........................................................................................................................44
     6.4.1 Report Errors (0x01).........................................................................................................45
     6.4.2 Counter Commands (0x02) ..............................................................................................46
     6.4.3 Tare (0x03) .......................................................................................................................47
     6.4.4 Initialization (0x04) ...........................................................................................................49
     6.4.5 Save DCD (0x06) .............................................................................................................51
     6.4.6 ME Calibration Commands (0x07) ...................................................................................52
     6.4.7 Configure Periodic DCD Save (0x09) ..............................................................................53
     6.4.8 Get Oscillator Type (0x0A) ...............................................................................................54
     6.4.9 Clear DCD and Reset (0x0B) ...........................................................................................55
     6.4.10     Simple Calibration Commands (0x0C) ......................................................................55
     6.4.11     Bootloader Commands (0x0D) ..................................................................................58
     6.4.12     Interactive Calibration (0x0E) .....................................................................................60
     6.4.13     Wheel Request (0x0F) ...............................................................................................61
  6.5     Sensor Reports ....................................................................................................................61
     6.5.1 Common Fields ................................................................................................................62
     6.5.2 Common Dynamic Feature Report ..................................................................................63
     6.5.3 Get Feature Request (0xFE) ............................................................................................63
     6.5.4 Set Feature Command (0xFD) .........................................................................................63
     6.5.5 Get Feature Response (0xFC) .........................................................................................64
     6.5.6 Force Sensor Flush (0xF0) ..............................................................................................65
     6.5.7 Flush Completed (0xEF) ..................................................................................................65
     6.5.8 Raw Accelerometer (0x14) ...............................................................................................65
     6.5.9 Accelerometer (0x01) .......................................................................................................66
     6.5.10     Linear Acceleration (0x04) .........................................................................................66
     6.5.11     Gravity (0x06).............................................................................................................67
     6.5.12     Raw Gyroscope (0x15) ..............................................................................................67
     6.5.13     Gyroscope Calibrated (0x02) .....................................................................................68
     6.5.14     Gyroscope Uncalibrated (0x07) .................................................................................68
     6.5.15     Raw Magnetometer (0x16) ........................................................................................69
     6.5.16     Magnetic Field Calibrated (0x03) ...............................................................................70
     6.5.17     Magnetic Field Uncalibrated (0x0F) ...........................................................................70
     6.5.18     Rotation Vector (0x05) ...............................................................................................71

                                            © 2021 CEVA, Inc. All rights reserved                                                               2

                                                                SH-2 Reference Manual                                            1000-3625 v1.9

      6.5.19          Game Rotation Vector (0x08) ....................................................................................71
      6.5.20          Geomagnetic Rotation Vector (0x09).........................................................................72
      6.5.21          Pressure (0x0A) .........................................................................................................73
      6.5.22          Ambient Light (0x0B) .................................................................................................73
      6.5.23          Humidity (0x0C) .........................................................................................................73
      6.5.24          Proximity (0x0D).........................................................................................................74
      6.5.25          Temperature (0x0E) ...................................................................................................74
      6.5.26          Reserved (0x17).........................................................................................................75
      6.5.27          Tap Detector (0x10) ...................................................................................................75
      6.5.28          Step Detector (0x18) ..................................................................................................75
      6.5.29          Step Counter (0x11) ...................................................................................................76
      6.5.30          Significant Motion (0x12) ...........................................................................................77
      6.5.31          Stability Classifier (0x13) ...........................................................................................77
      6.5.32          Shake Detector (0x19) ...............................................................................................78
      6.5.33          Flip Detector (0x1A) ...................................................................................................78
      6.5.34          Pickup Detector (0x1B) ..............................................................................................79
      6.5.35          Stability Detector (0x1C) ............................................................................................79
      6.5.36          Personal Activity Classifier (0x1E) .............................................................................80
      6.5.37          Sleep Detector (0x1F) ................................................................................................82
      6.5.38          Tilt Detector (0x20) ....................................................................................................82
      6.5.39          Pocket Detector (0x21) ..............................................................................................83
      6.5.40          Circle Detector (0x22) ................................................................................................83
      6.5.41          Heart Rate Monitor (0x23) .........................................................................................84
      6.5.42          ARVR-Stabilized Rotation Vector (0x28) ...................................................................84
      6.5.43          ARVR-Stabilized Game Rotation Vector (0x29) ........................................................85
      6.5.44          Gyro-Integrated Rotation Vector (0x2A) ....................................................................85
      6.5.45          Motion Request (0x2B) ..............................................................................................86
      6.5.46          Optical Flow (0x2C) ...................................................................................................87
      6.5.47          Dead Reckoning Pose (0x2D) ...................................................................................88

7.0       BATCHING ............................................................................................................. 91
  7.1     Batch queues .......................................................................................................................91
  7.2     Batch timestamps .................................................................................................................91
     7.2.1 Base Timestamp Reference (0xFB) .................................................................................91
     7.2.2 Timestamp Rebase (0xFA) ..............................................................................................92

8.0       REFERENCES ........................................................................................................ 93
9.0       NOTICES ................................................................................................................ 94

                                           © 2021 CEVA, Inc. All rights reserved                                                               3

                                                         SH-2 Reference Manual                                  1000-3625 v1.9

                                                List of Figures
Figure 1: Document History .............................................................................................. 7
Figure 2: Sensor Usage ..................................................................................................... 9
Figure 3: H-format Output Packet Definition ................................................................... 11
Figure 4: MotionEngine Power Management and Stability Classifier Record ............. 15
Figure 5: Sensor Orientation Record .............................................................................. 15
Figure 6: AR/VR Stabilization Record ............................................................................. 16
Figure 7: Significant Motion Detector Configuration Record........................................ 17
Figure 8: Shake Detector Configuration Record ............................................................ 17
Figure 9: Serial Number Record...................................................................................... 18
Figure 10: Maximum Fusion Period Record ................................................................... 18
Figure 11: Environmental Sensor Calibration Record ................................................... 18
Figure 12: ALS Calibration Record ................................................................................. 19
Figure 13: Proximity Sensor Calibration Record ........................................................... 19
Figure 14: Flip Detector Configuration Record .............................................................. 20
Figure 15: Pickup Detector Configuration Record......................................................... 21
Figure 16: Stability Detector Configuration Record ...................................................... 23
Figure 17: Sleep Detector Configuration Record ........................................................... 23
Figure 18: Tilt Detector Configuration Record ............................................................... 24
Figure 19: Pocket Detector Configuration Record......................................................... 24
Figure 20: Circle Detector Configuration Record .......................................................... 25
Figure 21: User Record .................................................................................................... 26
Figure 22: Time Source Record ...................................................................................... 26
Figure 23: UART Output Format Selection Record ......................................................... 26
Figure 24: Gyro-Integrated Rotation Vector Configuration Record ............................... 27
Figure 25: Fusion Control Record .................................................................................. 28
Figure 26: Configuration Records .................................................................................. 29
Figure 27: Metadata Records .......................................................................................... 31
Figure 28: Metadata Record Format – Revision 3 .......................................................... 31
Figure 29: Metadata Record Format – Revision 4 .......................................................... 32
Figure 30: Personal Activity Classifier Sensor-Specific Metadata. .............................. 33
Figure 31: Sensor Trigger Modes ................................................................................... 36
Figure 32: Report ID List ................................................................................................. 39
Figure 33: Product ID Request ........................................................................................ 39
Figure 34: Product ID Response ..................................................................................... 40
Figure 35: FRS Write Request ......................................................................................... 40
Figure 36: FRS Write Data Request ................................................................................ 41
Figure 37: FRS Write Response ...................................................................................... 41
Figure 38: FRS Read Request ......................................................................................... 42
Figure 39: FRS Read Response ...................................................................................... 42
Figure 40: Command Request ........................................................................................ 43
Figure 41: Command Response...................................................................................... 44
Figure 42: Command Identifiers...................................................................................... 45
Figure 43: Report Errors Command................................................................................ 45
Figure 44: Report Errors Response ................................................................................ 46
Figure 45: Get Counts Command ................................................................................... 46
Figure 46: Get Counts Response .................................................................................... 47
Figure 47: Clear Counts Command ................................................................................ 47
Figure 48: Tare Now Command....................................................................................... 48

                                       © 2021 CEVA, Inc. All rights reserved                                                4

                                                         SH-2 Reference Manual                                  1000-3625 v1.9

Figure 49: Persist Tare Command .................................................................................. 49
Figure 50: Set Reorientation Command ......................................................................... 49
Figure 51: Initialize Command......................................................................................... 50
Figure 52: Initialize Command Subsystems ................................................................... 50
Figure 53: Initialize Response ......................................................................................... 50
Figure 54: Save DCD Command...................................................................................... 51
Figure 55: Save DCD Response ...................................................................................... 51
Figure 56: Configure ME Calibration Command ............................................................ 52
Figure 57: Get ME Calibration Command ....................................................................... 52
Figure 58: Configure ME Calibration Response............................................................. 53
Figure 59: Configure Periodic Save DCD Command ..................................................... 54
Figure 60: Get Oscillator Type Command ....................................................................... 54
Figure 61: Get Oscillator Type Response ...................................................................... 55
Figure 62: Clear DCD and Reset Command .................................................................... 55
Figure 63: Start Calibration Request ............................................................................... 56
Figure 64: Start Calibration Response ........................................................................... 56
Figure 65: Finish Calibration Request ............................................................................. 57
Figure 66: Finish Calibration Response ......................................................................... 58
Figure 67: Bootloader Operating Mode Request ........................................................... 58
Figure 68: Bootloader Status Request ........................................................................... 59
Figure 69: Bootloader Status Response ........................................................................ 59
Figure 70: Bootloader Status Flags ................................................................................. 59
Figure 71: Bootloader Error Codes.................................................................................. 60
Figure 72: Interactive Calibration Request ..................................................................... 60
Figure 73: Motion Intent .................................................................................................. 61
Figure 74: Wheel Request Command .............................................................................. 61
Figure 75: Common Report Fields .................................................................................. 63
Figure 76: Common Feature Report ............................................................................... 63
Figure 77: Get Feature Request (0xFE) .......................................................................... 63
Figure 78: Set Feature Command (0xFD) ....................................................................... 64
Figure 79: Get Feature Response (0xFC) ....................................................................... 64
Figure 80: Force Sensor Flush (0xF0) ............................................................................ 65
Figure 81: Flush Completed (0xEF) ................................................................................ 65
Figure 82: Raw Accelerometer Input Report .................................................................. 65
Figure 83: Accelerometer Input Report .......................................................................... 66
Figure 84: Linear Acceleration Input Report .................................................................. 66
Figure 85: Gravity Input Report....................................................................................... 67
Figure 86: Raw Gyroscope Input Report ........................................................................ 68
Figure 87: Gyroscope Calibrated Input Report .............................................................. 68
Figure 88: Gyroscope Uncalibrated Input Report .......................................................... 69
Figure 89: Raw Magnetometer Input Report .................................................................. 69
Figure 90: Magnetic Field Calibrated Input Report ........................................................ 70
Figure 91: Magnetic Field Uncalibrated Input Report .................................................... 71
Figure 92: Rotation Vector Input Report ........................................................................ 71
Figure 93: Game Rotation Vector Input Report.............................................................. 72
Figure 94: Geomagnetic Rotation Vector Input Report ................................................. 72
Figure 95: Pressure Sensor Input Report ....................................................................... 73
Figure 96: Ambient Light Sensor Input Report .............................................................. 73
Figure 97: Humidity Sensor Input Report ....................................................................... 74
Figure 98: Proximity Sensor Input Report ...................................................................... 74
Figure 99: Temperature Sensor Input Report ................................................................ 74

                                       © 2021 CEVA, Inc. All rights reserved                                                5

                                                      SH-2 Reference Manual                                1000-3625 v1.9

Figure 100: Tap Detector Input Report ........................................................................... 75
Figure 101: Step Detector Input Report .......................................................................... 76
Figure 102: Step Counter Input Report........................................................................... 76
Figure 103: Significant Motion Input Report .................................................................. 77
Figure 104: Stability Classifier Input Report .................................................................. 77
Figure 105: Shake Detector Input Report ....................................................................... 78
Figure 106: Flip Detector Input Report ........................................................................... 79
Figure 107: Pickup Detector Input Report ...................................................................... 79
Figure 108: Stability Detector Input Report .................................................................... 80
Figure 109: Personal Activity Classifier Feature Report. .............................................. 80
Figure 110: Personal Activity Classifier Report ............................................................. 81
Figure 111: Activity Classification States ...................................................................... 82
Figure 112: Sleep Detector Input Report ........................................................................ 82
Figure 113: Tilt Detector Input Report ............................................................................ 82
Figure 114: Pocket Detector Input Report ...................................................................... 83
Figure 115: Circle Detector Input Report ........................................................................ 83
Figure 116: Heart Rate Monitor Input Report ................................................................. 84
Figure 117: ARVR-Stabilized Rotation Vector Input Report .......................................... 85
Figure 118: ARVR-Stabilized Game Rotation Vector Input Report ............................... 85
Figure 119: Gyro-Integrated Rotation Vector Input Report ........................................... 86
Figure 120: Motion Request Report ................................................................................ 86
Figure 121: Optical Flow Report ..................................................................................... 88
Figure 122: Dead Reckoning Pose Report ..................................................................... 90
Figure 123: Timestamp Dependencies ........................................................................... 91
Figure 124: Base Timestamp Reference Record ........................................................... 92
Figure 125: Timestamp Rebase Record ......................................................................... 92

                                     © 2021 CEVA, Inc. All rights reserved                                            6

                                              SH-2 Reference Manual                              1000-3625 v1.9

1.0       Introduction
The SH-2 is CEVA's Hillcrest Labs business unit’s turnkey sensor hub software solution. The
SH-2 connects to various motion and environmental sensors, collects data from them,
processes that data and provides the results to a host processor.

1.1      Intended Audience
This document is intended for application developers implementing products that use the SH-2.

1.2      Scope
This document describes the features of the SH-2, how they work, how to use them and the
application programming interface (API) for the SH-2. This document assumes the reader is
already familiar with Hillcrest’s MotionEngine.

1.3      Revision History
       Revision          Date                                        Description
 1.9              06/10/2021             Update References section
 1.8              04/21/2021             Add Optical Flow Report, Dead Reckoning Report, and Wheel
                                         Request Command
 1.7              04/13/2021             Add MI 4 to section 3.1.2.2.
 1.6              03/17/2021             Remove obsolete S and L format packets. Add new motion
                                         intent to Figure 73.
 1.5              09/23/2019             Remove incorrect statement from section 5.2 about being able
                                         to request input reports. Update company logos.
 1.4              5/20/2019              Mark FRS block read errors codes as deprecated. Update FRS
                                         write response status codes. Document UART reset command.
                                         Update ME Calibration command to support On Table Cal
                                         control. Clarify output of accelerometer sensor in section 6.5.9.
                                         Added Interactive calibration feature. Clarified minimum periods
                                         and on/off sensors in section 5.4.1. Correct default format for
                                         UART output in section 4.3.23. Add new Clear DCD command
                                         to RVC mode in section 3.1.4.4.
 1.3              12/12/2017             Added simple command usage. Added Bootloader command
                                         usage and product ID request. Removed support for block
                                         reads from FRS read requests. Added Simple Calibration
                                         Configuration records.
 1.2              05/19/2017             Clarified Tare command usage, added description of Tare
                                         application to AR/VR Stabilized Rotation Vectors and Gyro-
                                         Integrated Rotation Vector. Clarified FRS Read “BUSY” status
                                         behavior. Fix bad references. Added language clarifying
                                         interaction between Gyro-Integrated Rotation Vector and other
                                         fusion outputs. Clarified SHTP channels in 6.2.
 1.1              02/16/2017             Update the default value of AR/VR Stabilization FRS record.
                                         Remove unused reference.
 1.0              02/06/2017             Initial issue
                                     Figure 1: Document History

                               © 2021 CEVA, Inc. All rights reserved                                         7

                                           SH-2 Reference Manual                  1000-3625 v1.9

2.0     Sensor Usage
The SH-2 connects to and manages a variety of physical sensors. It processes the outputs of
the physical sensors to produce virtual sensors. Virtual sensors require data from one or more
physical sensors. Figure 2 indicates which physical sensors are required for which virtual
sensors. The number of physical sensors in use at any one time impacts the power consumed
by the device. Using more physical sensors means consuming more power.

                            © 2021 CEVA, Inc. All rights reserved                          8

                               SH-2 Reference Manual                                                                                               1000-3625 v1.9

                                                                           Physical Sensors

                                                            magnetometer
                                accelerometer

                                                                                        ambient light

                                                                                                                               temperature
                                                gyroscope

                                                                                                                   proximity
                                                                             pressure

                                                                                                        humidity
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

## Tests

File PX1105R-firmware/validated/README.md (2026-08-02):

# Validated PX1105R update artifacts

This directory contains the fixed artifacts used by
`tools/gnss_firmware_update.py`. They reproduce the successful A2 update from
2026-08-02; they are not tuning inputs.

## One-command update

The ESP32 firmware must include `components/gnss_firmware_updater`. Then run:

```bash
./tools/gnss_firmware_update.py 192.168.50.142
```

Only the exact ESP32 address changes. The tool performs all of the following:

1. verifies the loader, raw image and packed image against fixed SHA-256 values;
2. verifies every S-record checksum and decompresses the packed image locally;
3. uploads the loader and firmware image into ESP32 PSRAM;
4. starts the fixed PX1105R loader procedure;
5. waits for the GNSS service to report kernel `00030600`, ODM `00010721` and
   revision `0018010b`.

If that version is already installed, the tool exits successfully without
rewriting the receiver.

## Artifacts

- `PX1105R_GNSS_Viewer_2.1.147_loader.srec`
  - GNSS Viewer 2.1.147 resource 460
  - normalized from CRLF to LF for the repository
  - 67,064 source bytes, 1,428 records
  - the ESP32 emits each record as `text + LF + NUL`, totaling 68,492 wire bytes
  - SHA-256: `e236c1397b73a9cc28499513c3ac5e418ebf7ac389c374717a6210d48beef729`
- `PX1105R_01.07.33_viewer.lzma.b64`
  - base64 representation of the exact GNSS Viewer LZMA transfer
  - 471,243 decoded bytes, including the 13-byte LZMA-alone header
  - SHA-256: `44cb71aa9eb45a35fa97726a72ffe57835e7a7d2e33148cd5555260e1a6a4ce8`

The raw firmware remains in the parent directory and has SHA-256
`15e9384ed510f85045b76cff0e4756138e2dd2beeffcf11a1d5d0c0a2e044968`.

## Fixed embedded profile

- command/download UART: 115200 baud
- external loader command: `0x64/0x4f`
- Viewer baud index: 5
- loader buffer index: 0
- transfer block: 8 KiB
- BINSIZ8 terminator: NUL
- UART close/reopen sequence: enabled
- Phoenix tag offset: `0x100240`

The HTTP endpoints are deliberately internal plumbing. They no longer accept
headers that alter baud rates, block sizes, loader modes or timeouts.

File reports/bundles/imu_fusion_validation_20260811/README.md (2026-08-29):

# `imu_fusion_validation_20260811` bundle

Final report: [`../../imu_fusion_validation_20260811.pdf`](../../imu_fusion_validation_20260811.pdf)

- `source/`: report sources and notes;
- `analysis/`: generated metrics and manifests;
- `figures/`: retained PNG/SVG figures;
- `raw/`: retained captures and metadata.

RAW integrity is covered by [`../RAW_SHA256SUMS`](../RAW_SHA256SUMS).

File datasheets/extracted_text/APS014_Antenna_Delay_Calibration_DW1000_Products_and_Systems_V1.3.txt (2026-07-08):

APS014 APPLICATION NOTE
ANTENNA DELAY
CALIBRATION OF
DW1000-BASED PRODUCTS
AND SYSTEMS

Version 1.3
This document is subject to change without
notice

© 2024 Qorvo, US, Inc. – All Rights Reserved

APS014: DW1000 Antenna Delay Calibration
TABLE OF CONTENTS
LIST OF TABLES ............................................................................................................................ 2
LIST OF FIGURES........................................................................................................................... 2
1

INTRODUCTION ..................................................................................................................... 3
1.1
1.2

2

OVERVIEW ................................................................................................................................... 3
ABOUT THIS DOCUMENT................................................................................................................. 4

ANTENNA DELAY CALIBRATION ............................................................................................. 5
2.1 APPLICATION REQUIREMENTS ......................................................................................................... 5
2.1.1
Ranging Method and Antenna Delay Calibration ............................................................. 5
2.1.2
Accuracy ............................................................................................................................ 6
2.1.3
Temperature Variation ...................................................................................................... 6
2.2 REFERENCE DEVICE GENERATION ..................................................................................................... 6
2.2.1
TWR Antenna Delay Calibration Reference Device Generation ........................................ 6
2.2.2
TWR Antenna Delay Calibration Reference Device Generation Example........................ 10
2.3 ANTENNA DELAY CALIBRATION USING A KNOWN REFERENCE DEVICE .................................................. 11
2.3.1
Using Wired Channels in Antenna Delay Calibration Setups........................................... 11
2.3.2
Antenna Delay Calibration Using TWR with a Reference Device .................................... 11
2.3.3
Antenna Delay Calibration for an RTLS Environment ...................................................... 11

3

GLOSSARY ........................................................................................................................... 13

4

REFERENCES ........................................................................................................................ 14
4.1

LISTING ..................................................................................................................................... 14

5

DOCUMENT HISTORY .......................................................................................................... 14

6

MAJOR CHANGES ................................................................................................................ 14

7

FURTHER INFORMATION ..................................................................................................... 15

LIST OF TABLES
TABLE 1 : ANTENNA DELAYS REQUIRED BY RANGING REQUIREMENTS ................................................................. 5
TABLE 2 : DW1000-BASED EVK1000 ANTENNA DELAY CALIBRATION BASED ON STANDARD DEVIATION OF ANTENNA
DELAY VARIATION AND REQUIRED LOCATION ACCURACY .............................................................................. 6
TABLE 3: EXAMPLE ANTENNA DELAY CALIBRATION EDM POPULATION ............................................................... 10
TABLE 4: PERCENTAGE TRANSMIT AND RECEIVE ANTENNA DELAY IN TOTAL AGGREGATE DELAY................................ 12
TABLE 5: GLOSSARY OF TERMS..................................................................................................................... 13
TABLE 6: TABLE OF REFERENCES .................................................................................................................. 14
LIST OF FIGURES
FIGURE 1: ANTENNA DELAY DIAGRAM ............................................................................................................ 3
FIGURE 2: TWR REFERENCE DEVICE GENERATION SETUP .................................................................................... 7
FIGURE 3 : TWR ANTENNA DELAY CALIBRATION ALGORITHM - OVERALL FLOWCHART ............................................. 8
FIGURE 4: POPULATE THE SET OF CANDIDATE DELAY ESTIMATES - FLOWCHART ...................................................... 9
FIGURE 5: EVALUATE THE QUALITY OF THE CANDIDATES - FLOWCHART ............................................................... 10
© 2024 Qorvo, US, Inc. – All Rights Reserved

Page 2 of 15

APS014: DW1000 Antenna Delay Calibration

1 INTRODUCTION
1.1

Overview

DecaWave’s DW1000, a multi-channel transceiver based on Ultra Wideband (UWB) radio
communications, allows very accurate time-stamping of messages as they leave from and
arrive at the transceiver.
The delays which are measured in these timestamps include the propagation delay through
the DW1000 devices from the points at which the transmitter timestamps are applied to the
points at which the receiver timestamps are captured. These delays are referred to as the
transmit/receive antenna delays.
These antenna delays are internal to the chip and not included in the Time of Flight (ToF)
but are included in the propagation delay from transmission timestamp to receive message
timestamp, see Figure 1. Refer to [2] for more information on timestamps.
When measuring the Time of Flight (ToF) from a transmitter to a receiver the delay
measured includes the antenna delays (see Figure 1):
𝑡𝑀𝑒𝑎𝑠𝑢𝑟𝑒𝑑 = 𝑡𝐴𝐷𝑇𝑋 + 𝑇𝑜𝐹 + 𝑡𝐴𝐷𝑅𝑋
where:
ToF
tMeasured
tADTX
tADRX

=
=
=
=

Time of Flight
The measured time from the transmit timestamp to the receive timestamp
Transmit antenna delay
Receive antenna delay

To find the Time of Flight, we need to know the transmit and receive antenna delays.

Antenna

External
RF

tADTX

DW1000based product
or system 2

tADRX

RF Switch

DW1000based product
or system 1

Antenna
External
RF

tADTX

tADRX

Transmit
timestamp
applied

Analog
TX

Analog
RX

Digital TX

Digital RX

Receive
timestamp
captured

RF Switch
DW1000

Transmit
timestamp
applied

Analog
TX

Analog
RX

Digital TX

Digital RX

Host Interface

Receive
timestamp
captured

DW1000
Host Interface

Figure 1: Antenna Delay Diagram
© 2024 Qorvo, US, Inc. – All Rights Reserved

Page 3 of 15

APS014: DW1000 Antenna Delay Calibration
The internal propagation delays in DW1000 devices vary slightly from chip to chip. There
can also be variations due to components between DW1000 and the antenna. Since we are
measuring RF signals moving at the speed of light these variations can make differences to
ranging measurements in the tens of centimeters. Antenna delay calibration is used to
remove these variations.

1.2

About this document

This document is intended to be read together with [4] which gives a guide to production
testing and calibration for DW1000-based products to understand how to integrate antenna
delay calibration into the production test environment.
The document is divided into three main sections:
•
•
•

A description of antenna delay and application requirements.
How to generate a reference device for antenna delay calibration.
How to carry out antenna delay calibration using reference devices on the production
line.

© 2024 Qorvo, US, Inc. – All Rights Reserved

Page 4 of 15

APS014: DW1000 Antenna Delay Calibration

2 ANTENNA DELAY CALIBRATION
Depending on the accuracy needed in an application, antenna delay calibration may or may
not be required. Table 1 shows the accuracy that can be expected with and without
calibration.
Antenna delay calibration should be carried out using the exact use case(s) that will be used
in the final application. For example; PRF, channels, and power-up modes. You should refer
to [3] for a detailed treatment of the sources of error in TWR.

2.1

Application Requirements

Two-Way Ranging (TWR) is the calibration method described in this document for all
applications including TDoA applications.
2.1.1

Ranging Method and Antenna Delay Calibration

Depending on whether TWR, Time difference of Arrival (TDoA) and on whether wireless or
wired synchronization is required in the final application, the system will need different
antenna delay information.
For a TWR system, the aggregate antenna delay (the sum of the transmitter and receiver
antenna delay) is required in the calculations. Where antenna delay calibration is required,
both anchors and tags should be calibrated.
In a TDoA system using wired synchronization, the receiver (anchor) antenna delay only is
required.
In a TDoA system using wireless synchronization, the individual transmitter and receiver
delays is required.
Table 1 summarises the system ranging requirements and the associated types of antenna
delays needed.
Table 1: Antenna Delays Required by Ranging Requirements
Application Type

Antenna Delays Needed

TWR

Aggregate (sum of) transmitter and receiver antenna
delays. Both anchors and tags require calibration if
calibration is being carried out.

TDoA / Wired Synchronization

Receiver antenna delay, calibrate anchors only, if
calibration is being carried out.

TDoA / Wireless
Synchronization

Both transmitter and receiver antenna delays are
needed in systems that are required to perform wireless
synchronization. Calibrate anchors only, if calibration is
being carried out.

DecaWave calibrates antenna delay using a method described below using TWR.
For that reason, devices which are intended to be calibrated for antenna delay using this
method must be capable of acting as a transmitter and as a receiver. If the device to be
calibrated includes an LNA, for example, a transmit path must be included in order to carry
© 2024 Qorvo, US, Inc. – All Rights Reserved

Page 5 of 15

APS014: DW1000 Antenna Delay Calibration
out TWR for antenna delay calibration.
2.1.2

Accuracy

Whether antenna delay calibration is needed for a product depends on the location accuracy
required in the application and on the antenna delay variation observed between parts.
Ranging data for 2000 DW1000-based DecaWave EVB1000’s was analysed to find the
standard deviation of the antenna delay variation before and after the EVB1000’s had been
calibrated.
The 3-sigma variation (99.7% of samples) of the antenna delay was found to be 30 cm
before calibration and 4.5 cm after calibration.
So, applications requiring accuracy of 30 cm or less do not require any per-board antenna
delay calibration. For such applications, a default value must be worked out during product
characterization using a statistically significant sample. If the EVB1000’s were calibrated for
antenna delay, the best accuracy achievable would be 4.5 cm. See Table 2.
Table 2: DW1000-based EVK1000 antenna delay calibration based on standard deviation of
antenna delay variation and required location accuracy
TWR Accuracy
Required

2.1.3

Example Antenna Delay Calibration Recommended

30 cm

No per-board antenna delay calibration needed

4.5 cm

Calibration using known reference device(s)

Temperature Variation

The antenna delay will vary with temperature. It is recommended that the temperature at
which calibration was carried out is recorded. This will allow the application to adjust
measurements if required.
Range has been shown to vary by 2.15 mm / °C (or 7.17 ps / °C) per device for DW1000
devices.

2.2

Reference Device Generation

To carry out antenna delay calibration on a production line as described in section 2.3, a
known reference device is required. Before the production calibration can be carried out it is
necessary to have a reference device.
2.2.1

TWR Antenna Delay Calibration Reference Device Generation

This calibration method gives accurate measurements of aggregate transmitter and receiver
antenna delay.
This method is performed by carrying out TWR using at least three devices. A Euclidean
Distance Matrix (EDM) is constructed using ranges obtained using TWR, having set the
antenna delay to zero. The device temperature should be noted.
A Euclidean Distance Matrix is an n x n matrix representing the spacing of a set of n points
in Euclidean space (3-D space in this case). To construct an EDM suitable for this antenna
delay calibration with devices numbered 1 to n, the average ranges for each pair
© 2024 Qorvo, US, Inc. – All Rights Reserved

Page 6 of 15

APS014: DW1000 Antenna Delay Calibration
permutation are entered in the matrix:
𝑑11 𝑑12 … 𝑑1𝑛
𝑑
𝑑22 … 𝑑2𝑛 ]
𝐸𝐷𝑀 = [ 21
…

…

…

…

𝑑31 𝑑32 … 𝑑𝑛𝑛
where:
𝑑𝑋𝑌 = 𝑑𝑖𝑠𝑡𝑎𝑛𝑐𝑒 𝑓𝑟𝑜𝑚 𝑑𝑒𝑣𝑖𝑐𝑒 𝑋 𝑡𝑜 𝑑𝑒𝑣𝑖𝑐𝑒 𝑌
The entries along the diagonal are always zero; the distance from device 1 to device 1 is
zero. The other entries are filled with the ranges measured by TWR between each pair of
devices used.
The actual distances must be known; measure the actual distances between devices.
The distances between devices should be the same, or close to the same so that treatment
of the range bias (see [3] for a full description of range bias) in the calculations is simplified.
See [4] for a description of how to use a known wired channel instead of an over the air
channel.
The devices can be arranged as shown in Figure 2 or the paired measurements can be
done in turn using two devices at a time. Keeping the distances between the devices the
same is recommended.

Host running
DecaRanging

DW1000-based
device
1

Equidistant free space/
known wired channels

DW1000-based
device
2

Host running
DecaRanging

Antenna for free space
OR test port for known
wired channel

Host running
DecaRanging

DW1000-based
device
3

Figure 2: TWR reference device generation setup

The antenna delays can be determined by minimizing the norm of the difference between
the two EDM’s:
𝑚𝑖𝑛∀𝜏 ||(𝐸𝐷𝑀𝐴𝑐𝑡𝑢𝑎𝑙 − 𝐸𝐷𝑀𝑀𝑒𝑎𝑠𝑢𝑟𝑒𝑑 )||
where 𝐸𝐷𝑀𝐴𝑐𝑡𝑢𝑎𝑙 is given by the known distances between the devices in the calibration
array as measured using a laser range finder or other calibrated measuring device and
𝐸𝐷𝑀𝑀𝑒𝑎𝑠𝑢𝑟𝑒𝑑 is given by the ranges measured using the DW1000-based devices performing
TWR.
© 2024 Qorvo, US, Inc. – All Rights Reserved

Page 7 of 15

APS014: DW1000 Antenna Delay Calibration
0
𝐸𝐷𝑀 = [𝑑21

𝑑31

𝑑12 𝑑13
0
𝑑23 ]
𝑑32 0

Figure 3, Figure 4 and Figure 5 below show an example flowchart of an algorithm to carry
out the reference device calibration.
This will require
nChips*(nChips-1)
measurements.
Ideally each measurement
should be an average of
several range estimates, we
use 200 range estimates for
each measurement.

Start

Use TWR to measure
the EDMMeasured with all
antenna delays set to
zero.

All EDMActual ranges
should be the same.

Convert measured
EDMMeasured and
EDMActual to times
(ToFmeasured and
ToFactual)

For example, 100 iterations

Required
number of
iterations
For example, 1000
candidates

no
Populate the
set of
candidate
delay
estimates

yes
Evaluate the
quality of the
candidates

Return Best
Candidate

Figure 3: TWR Antenna delay calibration algorithm - overall flowchart

© 2024 Qorvo, US, Inc. – All Rights Reserved

Page 8 of 15

APS014: DW1000 Antenna Delay Calibration

Populating the set of
candidate delay estimates

Set initial delays
(~513ns) and
perturbation limits
(~0.2ns)

no

First iteration
yes

Select the best
25% of the set and
include them in
the new set.

Perform 3
times

Generate a set of
random delays
uniformly
distributed round
initial delay ±6ns.

Randomly perturb
the initial 25%
within the
perturbation limits
and add them to
the set.

Every 20 iterations
halve the
perturbation limits

Return the
candidate Set

Figure 4: Populate the set of candidate delay estimates - flowchart

© 2024 Qorvo, US, Inc. – All Rights Reserved

Page 9 of 15

APS014: DW1000 Antenna Delay Calibration

Candidate
Evaluation

Foreach
candidate

Compute the time of flight matrix given the
candidate delays
tofcandidate=[2Delchip1+2Delchip2+4tofmeasured]/4

Compute the norm of the difference
between the tofactual matrix and the
tofcandidate matrix

Sort the
candidates.
Lowest error first.

Return sorted list
of candidates

Figure 5: Evaluate the quality of the candidates - flowchart

2.2.2

TWR Antenna Delay Calibration Reference Device Generation Example

Three DW1000 evaluation boards, EVB1000’s, were used in pair permutations to generate
the Euclidean Distance Matrix (EDM).
The distance between the two ranging points was measured as: 7.914 m.
DecaWave’s DecaRanging TWR application was used to capture the ranging
measurements, setting the antenna delay of the two EVB1000’s to 0.000. The following
measurements were taken using 1000 TWR range measurements in each case:
Table 3: Example antenna delay calibration EDM population
d12

d13

d21

d23

d31

d32

Average Range Measured
(inc. Range Bias)

162.23

162.3218

162.2407

162.3136

162.2842

162.3269

Range Bias @ 162 m, PRF
= 16 MHz, Channel = 2

+0.13

+0.13

+0.13

+0.13

+0.13

+0.13

Average Measured Range
(excl. Range Bias correction)

162.0913

162.1813

162.1020

162.1749

162.1455

162.1882

© 2024 Qorvo, US, Inc. – All Rights Reserved

Page 10 of 15

APS014: DW1000 Antenna Delay Calibration
d12

d13

d21

d23

d31

d32

Range Bias @ 7.914 m, PRF
= 16 MHz, Channel = 2

-0.07

-0.07

-0.07

-0.07

-0.07

-0.07

Average Measured Range
(incl. Range Bias correction)

162.1613

162.2531

162.172

162.2449

162.2155

162.2582

Note that a detailed description of range bias is given in [3]. The range bias values in Table
3 are as applied in the DecaRanging application.
The expression to be minimized is then given by:
0
7.914 7.914
0
162.1613 162.2531
𝐸𝐷𝑀𝐴𝑐𝑡𝑢𝑎𝑙 − 𝐸𝐷𝑀𝐷𝑒𝑐𝑎𝑟𝑎𝑛𝑔𝑖𝑛𝑔 = [7.914
0
7.914] − [162.1720
0
162.2449]
7.914 7.914
0
162.2155 162.2582
0
Applying an algorithm as described above, the following values are found as the best fit for
the aggregate antenna delays of the three devices:
Aggregate antenna delay, device 1 = 514.4747 ns
Aggregate antenna delay, device 2 = 514.5911 ns
Aggregate antenna delay, device 3 = 515.0413 ns

2.3

Antenna Delay Calibration Using a Known Reference Device

2.3.1

Using Wired Channels in Antenna Delay Calibration Setups

Please refer to [4] for details of free space measurements and test setup calibration
procedures.
2.3.2

Antenna Delay Calibration Using TWR with a Reference Device

For TWR systems, if the antenna delay of the reference device and the delay of the test
setup are known then the antenna delay of the device under test (DUT) can be calculated.
2.3.2.1 Antenna Delay Calibration Using TWR with a Reference Device Procedure
The following procedure may be used to carry out antenna delay calibration:
1. Set the antenna delay in the DUT to some initial value, e.g. 515 ns, and set the
antenna delay in the reference device to its known value.
2. Carry out say 1000 TWR measurements of the range between the reference device
and the DUT across the known channel.
3. Average the measurements taken.
4. Find the difference between the known range and the measured range and adjust the
antenna delay of the DUT to give the correct range.
2.3.3

Antenna Delay Calibration for an RTLS Environment

For RTLS systems generally, the receiver antenna delay should be known for most accurate
ranging in a system using wired synchronization and both the transmitter and receiver
antenna delays should be known in a system using wireless synchronization.
Currently, DecaWave recommends using a TWR antenna delay calibration to determine the
aggregate antenna delay and then to apportion the aggregate delay to the transmitter and
receiver in the percentages given in Table 4 below.
© 2024 Qorvo, US, Inc. – All Rights Reserved

Page 11 of 15

APS014: DW1000 Antenna Delay Calibration

Table 4: Percentage transmit and receive antenna delay in total aggregate delay
Antenna Delay

Percentage of Total

Transmit

44%

Receive

56%

© 2024 Qorvo, US, Inc. – All Rights Reserved

Page 12 of 15

APS014: DW1000 Antenna Delay Calibration

3 GLOSSARY
Table 5: Glossary of terms
Abbreviation

Full Title

Explanation

EDM

Euclidean
Distance Matrix

A Euclidean Distance Matrix is an n x n matrix representing the
spacing of a set of n points in Euclidean space.

EVB1000

Evaluation
Board

DW1000 evaluation board and antenna.

EVK1000

Evaluation Kit

DW1000 evaluation kit including two PCB boards and antennas.

LNA

Low Noise
Amplifier

Circuit normally found at the front-end of a radio receiver
designed to amplify very low level signals while keeping any
added noise to as low a level as possible

RF

Radio
Frequency

Generally used to refer to signals in the range of 3 kHz to 300
GHz. In the context of a radio receiver, the term is generally used
to refer to circuits in a receiver before down-conversion takes
place and in a transmitter after up-conversion takes place.

RTLS

Real Time
Location System

System intended to provide information on the location of various
items in real-time.

TCXO

Temperature
Controlled
Crystal
Oscillator

A crystal oscillator whose output frequency is very accurately
maintained at its specified value over its specified temperature
range of operation.

ToF

Time of Flight

Time taken for an object or a wave to travel through a medium.

TWR

Two Way
Ranging

Method of measuring the physical distance between two radio
units by exchanging messages between the units and noting the
times of transmission and reception. Refer to DecaWave’s
website for further information.

TDoA

Time Difference
of Arrival

Method of deriving information on the location of a transmitter.
The time of arrival of a transmission at two physically different
locations whose clocks are synchronized is noted and the
difference in the arrival times provides information on the location
of the transmitter. A number of such TDoA measurements at
different locations can be used to uniquely determine the position
of the transmitter. Refer to DecaWave’s website for further
information.

UWB

Ultra Wideband

A radio scheme employing channel bandwidths of, or in excess
of, 500 MHz.

© 2024 Qorvo, US, Inc. – All Rights Reserved

Page 13 of 15

APS014: DW1000 Antenna Delay Calibration

4 REFERENCES
4.1

Listing

Reference is made to the following documents in the course of this application note: Table 6: Table of references

Ref

Author

Version

Title

[1]

DecaWave

Current

DW1000 Data Sheet

[2]

DecaWave

Current

DW1000 User Manual

[3]

DecaWave

Current

APS011 Sources of error in TWR

[4]

DecaWave

Current

APS012 Production Tests for DW1000-based Products

[5]

DecaWave

Current

APS013 Two-way ranging implementation with the
DW1000

5

DOCUMENT HISTORY
Table 7: Document History

Revision

Date

1.00

Description
Initial release.

1.01

Scheduled update
st

1.2

31 July 2018

Scheduled update

1.3

14th May 2024

Scheduled update

6 MAJOR CHANGES
Revision 1.00
Page
All

Change Description
Initial release

Revision 1.01
Page
All

Change Description
Scheduled update

Revision 1.2
Page
Front page
All

Change Description
Change in version number from 1.01 to 1.2
Update of company logo

Revision 1.3
Page
All

Change Description
Modification to footer.

© 2024 Qorvo, US, Inc. – All Rights Reserved

Page 14 of 15

APS014: DW1000 Antenna Delay Calibration

7 FURTHER INFORMATION
Decawave develops semiconductors solutions, software, modules, reference designs - that
enable real-time, ultra-accurate, ultra-reliable local area micro-location services.
Decawave’s technology enables an entirely new class of easy to implement, highly secure,
intelligent location functionality and services for IoT and smart consumer products and
applications.
For further information on this or any other Decawave product, please refer to our website
www.decawave.com.

© 2024 Qorvo, US, Inc. – All Rights Reserved

Page 15 of 15

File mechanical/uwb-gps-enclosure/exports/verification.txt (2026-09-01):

pcb_vs_body_intersection_mm3: 0.0
pcb_vs_chassis_intersection_mm3: 0.0
pcb_vs_collar_intersection_mm3: 0.0
pcb_vs_hat_intersection_mm3: 0.0
battery_vs_chassis_intersection_mm3: 0.0
battery_vs_pcb_intersection_mm3: 0.0
battery_vs_sma_mating_guard_intersection_mm3: 0.0
battery_vs_body_intersection_mm3: 0.0
battery_vs_collar_intersection_mm3: 0.0
gps_vs_collar_intersection_mm3: 0.0
gps_vs_tray_intersection_mm3: 0.0
gps_tray_vs_collar_intersection_mm3: 0.0
gps_tray_axial_insertion_max_intersection_mm3: 0.0
gps_vs_hat_intersection_mm3: 0.0
body_vs_chassis_intersection_mm3: 0.0
body_vs_collar_intersection_mm3: 0.0
collar_vs_hat_intersection_mm3: 0.0
chassis_vs_battery_retainer_intersection_mm3: 0.0
battery_vs_retainer_intersection_mm3: 0.0
base_vs_body_intersection_mm3: 0.0
tripod_base_vs_body_intersection_mm3: 0.0
usb_vs_body_intersection_mm3: 0.0
switch_vs_body_intersection_mm3: 0.0
usb_vs_chassis_intersection_mm3: 0.0
usb_vs_pcb_intersection_mm3: 0.0
usb_vs_battery_intersection_mm3: 0.0
switch_vs_chassis_intersection_mm3: 0.0
switch_vs_pcb_intersection_mm3: 0.0
switch_vs_battery_intersection_mm3: 0.0
sma_mating_guard_vs_chassis_intersection_mm3: 0.0
sma_mating_guard_vs_body_intersection_mm3: 0.0
board_bottom_z_mm: 44.0
pcb_edge_to_inner_floor_mm: 40.0
board_assembly_bottom_z_mm: 35.305
board_top_z_mm: 124.701
gps_flower_bottom_z_mm: 174.701
board_to_gps_flower_mm: 50.0
gps_flipped_180deg_about_x: True
uwb_antenna_axis_x_mm: 0.0
uwb_antenna_axis_y_mm: 0.0
uwb_antenna_model_x_mm: 75.1488
uwb_antenna_model_y_mm: -63.2375
uwb_antenna_height_mm: 119.851
dwm_above_sma_extreme_mm: 89.396
battery_bottom_z_mm: 6.5
battery_top_z_mm: 79.5
battery_to_uwb_antenna_center_mm: 40.351
sma_relief_width_mm: 18.0
sma_relief_height_mm: 50.0
sma_mating_guard_diameter_mm: 15.0
battery_front_y_mm: 14.745
target_base_diameter_mm: 122.0
target_base_uniform_thickness_mm: 5.0
target_window_diameter_mm: 38.0
target_crossbar_width_mm: 1.0
target_window_is_through_cut: True
tripod_base_diameter_mm: 122.0
tripod_base_uniform_thickness_mm: 8.0
tripod_base_outer_chamfer_top_mm: 1.0
tripod_base_outer_chamfer_bottom_mm: 1.0
tripod_thread_standard: 3/8"-16 UNC
tripod_thread_is_modeled_helical: True
tripod_thread_tpi: 16
tripod_thread_pitch_mm: 1.5875
tripod_thread_angle_deg: 60.0
tripod_thread_nominal_major_diameter_mm: 9.525
tripod_thread_modeled_major_diameter_mm: 9.78
tripod_thread_nominal_major_diametral_clearance_mm: 0.255
tripod_thread_minor_diameter_mm: 8.08
tripod_thread_radial_depth_mm: 0.85
tripod_thread_start_z_mm: 1.35
tripod_thread_end_z_mm: 7.15
tripod_thread_usable_length_mm: 5.8
tripod_thread_turn_count: 3.654
tripod_insert_outer_diameter_mm: 9.525
tripod_insert_total_height_mm: 7.0
tripod_insert_flange_diameter_mm: 9.5
tripod_insert_flange_height_mm: 1.2
tripod_insert_flange_pocket_diameter_mm: 9.8
tripod_insert_flange_diametral_clearance_mm: 0.3
tripod_insert_flange_pocket_depth_mm: 1.35
tripod_insert_flange_depth_clearance_mm: 0.15
tripod_insert_magnet_face_recess_mm: 1.0
tripod_base_insert_fully_between_faces: True
magnet_pair_count: 4
magnet_radius_mm: 44.0
magnet_angle_offset_deg: 45.0
magnet_outer_edge_margin_mm: 11.875
magnet_radius_increase_factor: 2.316
service_bay_recess_depth_mm: 12.0
service_bay_outer_projection_center_mm: 3.0
service_bay_outer_projection_at_edge_mm: 7.502
switch_tip_inside_outer_rim_mm: 3.0
m3_insert_measured_body_diameter_mm: 3.0
m3_insert_measured_knurl_diameter_mm: 4.0
m3_insert_measured_length_mm: 5.0
m3_insert_pocket_diameter_mm: 3.7
m3_insert_knurl_diametral_interference_mm: 0.3
m3_insert_pocket_depth_mm: 5.8
m3_insert_pocket_overdepth_mm: 0.8
m3_insert_lead_diameter_mm: 4.1
m3_insert_lead_depth_mm: 0.8
m3_insert_boss_min_radial_wall_at_lead_mm: 2.45
m3_clearance_hole_diameter_mm: 3.4
m3_heat_set_insert_total_count: 9
m3_heat_set_insert_vertical_count: 3
m3_heat_set_insert_radial_count: 6
chassis_mount_count: 3
chassis_mount_centres_mm: [[-44.0, 10.0], [25.0, 10.0], [-10.0, 50.0]]
chassis_mount_flange_width_mm: 20.0
chassis_mount_flange_depth_mm: 14.0
chassis_mount_flange_thickness_mm: 4.0
chassis_mount_flange_to_battery_gap_mm: 0.495
chassis_mount_gusset_height_mm: 18.0
chassis_mount_gusset_depth_mm: 10.0
chassis_mount_left_inboard_overlap_mm: 3.75
chassis_mount_right_inboard_overlap_mm: 2.75
chassis_mount_screw_head_to_gusset_clearance_mm: 0.75
chassis_side_reinforcement_rear_y_mm: 24.0
chassis_rear_mount_rib_count: 2
chassis_rear_mount_rib_top_z_mm: 28.65
collar_internal_overhang_transition_angle_deg: 45.0
collar_shoulder_bridge_width_mm: 0.6
collar_tray_ledge_support_radial_width_mm: 3.7
collar_functional_diameters_unchanged: True
gps_tray_cap_boss_passage_notch_count: 3
gps_tray_cap_boss_passage_clearance_mm: 0.8
gps_tray_reinforced_passage_count: 3
gps_tray_reinforcement_lobe_diameter_mm: 28.0
gps_tray_reinforcement_center_radii_mm: [57.356592, 58.801408, 57.589096]
gps_tray_axial_insertion_sample_step_mm: 0.5
gps_tray_axial_insertion_verified: True
gps_mount_hole_count: 4
gps_mount_radius_mm: 42.5
gps_mount_hole_model_diameter_mm: 2.6
gps_support_screw_relief_diameter_mm: 2.8
m25_insert_measured_body_diameter_mm: 3.0
m25_insert_measured_knurl_diameter_mm: 3.5
m25_insert_measured_length_mm: 5.0
m25_insert_pocket_diameter_mm: 3.2
m25_insert_knurl_diametral_interference_mm: 0.3
m25_insert_pocket_depth_mm: 5.3
m25_insert_pocket_overdepth_mm: 0.3
m25_insert_lead_diameter_mm: 3.6
m25_insert_lead_depth_mm: 0.6
m25_insert_standoff_min_radial_wall_at_lead_mm: 1.7
m25_insert_pocket_extension_into_tray_mm: 0.23
m25_heat_set_insert_total_count: 4
gps_mount_center_error_max_mm: 0.0
gps_mount_standoff_height_mm: 5.07
gps_mount_standoff_to_flower_gap_mm: 0.1
gps_mount_m3_compatible_without_drilling: False
gps_mount_recommended_screw: M2.5
gps_top_z_mm: 187.601
hat_inside_roof_z_mm: 191.5

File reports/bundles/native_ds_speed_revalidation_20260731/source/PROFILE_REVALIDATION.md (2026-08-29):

# Native DS-TWR profile revalidation — 2026-07-31

## Outcome

The fastest profile accepted on the unchanged static setup is **60 ms**:

- 14 ms per anchor slot
- 4 ms frame gap
- 8 ms RX timeout
- 2 ms RESP delay
- 2 ms FINAL delay
- 100 ms anchor RX slice
- 500 UUS automatic RX delay

It completed a 180 s validation with 11,158 raw tag-to-anchor ranges and
**zero negative or >10 cm raw outliers**. The 59 ms candidate produced an
impossible -5.301 m range during the equivalent validation, so 60 ms is the
observed boundary rather than a rounded convenience value.

The 64 ms profile remains a validated reserve. The 410 ms profile remains the
slow precision control.

## Fair comparison against the fresh control

All three accepted captures used the same firmware, radio channel, antenna
delays, cached measured anchor geometry, tag reference and unchanged physical
setup. Every result below comes from an unfiltered offline reconstruction.
Precision is measured around each capture's own mean.

| Profile | Capture | Raw ranges | Delivery | Coherent frames/s | Rolling updates/s | Coherent RMS | Coherent CEP95 | Raw anomalies |
|---|---:|---:|---:|---:|---:|---:|---:|---:|
| 410 ms control | 180 s | 1,647 | 94.11% | 1.72 | 9.16 | 1.36 cm | 2.30 cm | 0 |
| 64 ms reserve | 180 s | 10,468 | 94.03% | 10.92 | 58.14 | 1.38 cm | 2.41 cm | 0 |
| **60 ms limit** | **180 s** | **11,158** | **93.97%** | **11.63** | **61.96** | **1.38 cm** | **2.39 cm** | **0** |

Relative to 410 ms, the 60 ms profile provides:

- 6.75 times as many coherent independent frames per second;
- 6.77 times as many rolling display updates per second;
- +1.56% coherent precision RMS;
- +3.94% coherent CEP95;
- -0.14 percentage points of sequence delivery.

This is a substantial speed gain with no material static precision loss in
this capture.

## Boundary search

The central position distribution can remain deceptively tight when a timing
profile occasionally emits a physically impossible raw range. Therefore a
profile was rejected if any raw distance was negative or differed by more than
10 cm from that anchor's capture median. Solver rejection was not counted as a
successful radio result.

| Profile | Capture | Coherent frames/s | RMS | CEP95 | Negative ranges | >10 cm raw spikes | Minimum raw range | Verdict |
|---|---:|---:|---:|---:|---:|---:|---:|---|
| 60 ms | 180 s | 11.63 | 1.38 cm | 2.39 cm | 0 | 0 | 2.152 m | accepted |
| 59 ms | 180 s | 11.82 | 1.31 cm | 2.20 cm | 1 | 1 | -5.301 m | rejected |
| 58 ms | 180 s | 12.00 | 1.35 cm | 2.30 cm | 2 | 2 | -5.875 m | rejected |
| 57 ms | 60 s | 12.21 | 1.38 cm | 2.42 cm | 1 | 1 | -23.455 m | rejected |
| 49 ms | 60 s | 17.61 | 1.30 cm | 2.25 cm | 1 | 1 | -17.889 m | rejected |
| 33 ms | 180 s | 20.42 | 1.33 cm | 2.33 cm | 7 | 9 | -20.511 m | rejected |
| 29 ms | 180 s | 23.37 | 1.43 cm | 2.46 cm | 13 | 19 | -22.831 m | rejected |
| 25 ms | 60 s | 27.09 | 1.43 cm | 2.47 cm | 2 | 2 | -3.646 m | rejected |
| 21 ms | 60 s | 33.34 | 1.43 cm | 2.53 cm | 4 | 4 | -39.181 m | rejected |
| 17 ms | 60 s | 39.77 | 1.34 cm | 2.35 cm | 13 | 15 | -40.249 m | rejected |
| 13 ms | 60 s | 44.99 | 1.38 cm | 2.36 cm | 20 | 22 | -53.505 m | rejected |

The short 58 ms and 29 ms screens initially contained no anomaly. Both failed
their longer validation, demonstrating why a short visual test is not enough.

## Interpretation

The 59/60 ms transition points to recovery time between frames, not a gradual
precision-noise tradeoff. The 60 ms profile uses a 14 ms slot and a 4 ms frame
gap. Reducing the gap to 3 ms preserved the central RMS but allowed a rare
invalid timestamp/range path on A2.

This is an observed operational boundary for this firmware and five-module
setup, not a universal DW3000 limit. Dynamic tests, longer endurance runs and
other RF geometries are still required. Until then:

- use 60 ms for the best validated speed;
- use 64 ms when extra scheduling reserve matters;
- use 410 ms only as the precision/control reference;
- treat every profile below 60 ms as an experimental stress test.

## Reproducibility

Each profile directory retains:

- full initial/final module status metadata;
- unfiltered coherent and rolling position reconstructions;
- per-anchor range metrics;
- `summary.json`;
- `raw_quality.json`, including negative and >10 cm anomaly counts.

Under the aggressive retention policy, only the decisive 58/59/60 ms
validation event streams remain. Other event streams and all Native DS-TWR
raw log streams were removed after their derived artifacts were verified.
The per-capture `SHA256SUMS` files remain historical manifests and can name
RAW files that are no longer present.

The fresh control is documented in `README.md`. Exact profile results are in
the corresponding `profile_*` and `candidate_*` directories.

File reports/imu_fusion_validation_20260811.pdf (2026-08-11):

# Dynamic and static UWB comparison

## FlexTDOA, Native DS-TWR and Passive DS-TWR

Field campaign of August 6, 2026

Platform: | 5 ESP32-S3 + DW3000 modules, Raspberry Pi collector
Topology: | M1 tag; M2, M3, M4 and M5 anchors
Radio: | UWB channel 9; configured 40 MHz SPI
Firmware branch: | imu-500hz-fusion
Evidence: | six complete immutable JSONL captures plus replay summaries

Main result. All three protocols produced usable unfiltered dynamic trajectories. FlexTDOA delivered the highest independent dynamic rate and the best static local precision. Native DS-TWR had the shortest worst-case dynamic gap. Passive DS-TWR remained usable, but its overlapping publications must be reduced to independent frames for a fair rate comparison.

Reproducible technical report

## Contents

1 Executive summary | 1
2 Scope and questions | 1
3 System and protocol background | 1
4 Test configuration and captured evidence | 1
5 Methodology | 2
6 Dynamic results | 2
7 Static results | 4
8 IMU capture and fusion assessment | 4
9 UWB–RTK association audit | 6
10 Protocol interpretation and selection | 7
11 Limitations | 7
12 Recommended next tests | 8
13 Preliminary findings | 8
14 Reproduction and audit files | 8

i

## 1 Executive summary

Evidence boundary. Stream rates, uptime gaps, sample counts, fusion acceptance and reset counts are direct diagnostics. Absolute UWB–RTK disagreement is only indicative: RTK was not an independent survey, clocks are associated in software, antenna lever arms are unknown, and the UWB frame is registered through RTK anchor geometry.

Passive DS overlapping raw windows remain visible in the telemetry rate, while all comparative precision and trajectory metrics use independent frames. Interleaved records marked imu fused=true are excluded from raw UWB metrics. Outliers are retained.

The dynamic independent rates were 27.62 positions/s for FlexTDOA, 22.38 positions/s for Native DS-TWR, and 23.84 positions/s for Passive DS-TWR. Passive DS emitted 71.33 dashboard events/s, but those include overlapping windows.

The static raw local RMS values were 2.13 cm (FlexTDOA), 2.02 cm (Native DS-TWR) and 1.78 cm (Passive DS-TWR). These are precision around each capture median, not absolute accuracy.

The stationary tag RTK centers differed by 1.583 m between blocks, invalidating an absolute cross-protocol static ranking. IMU transport was healthy at roughly 119–127 telemetry samples/s, but all six replays reported zero yaw-alignment updates. This campaign therefore does not demonstrate acceleration-derived position improve-ment.
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

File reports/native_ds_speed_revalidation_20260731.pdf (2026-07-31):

# Native DS-TWR speed-limit revalidation

### Fresh throughput, precision, and raw-range integrity study

Test date: July 31, 2026, EEST
Platform: 5 ESP32-S3 + DW3000 modules, Raspberry Pi 5 Branch: experiment/passive-ds-twr-pipeline Dashboard source: 8244a3432f68
Active firmware identity: 54a586c-dirty Configuration: M1 tag; M2, M3, M4, M5 anchors Radio: UWB channel 5
Environment: unchanged static indoor setup
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

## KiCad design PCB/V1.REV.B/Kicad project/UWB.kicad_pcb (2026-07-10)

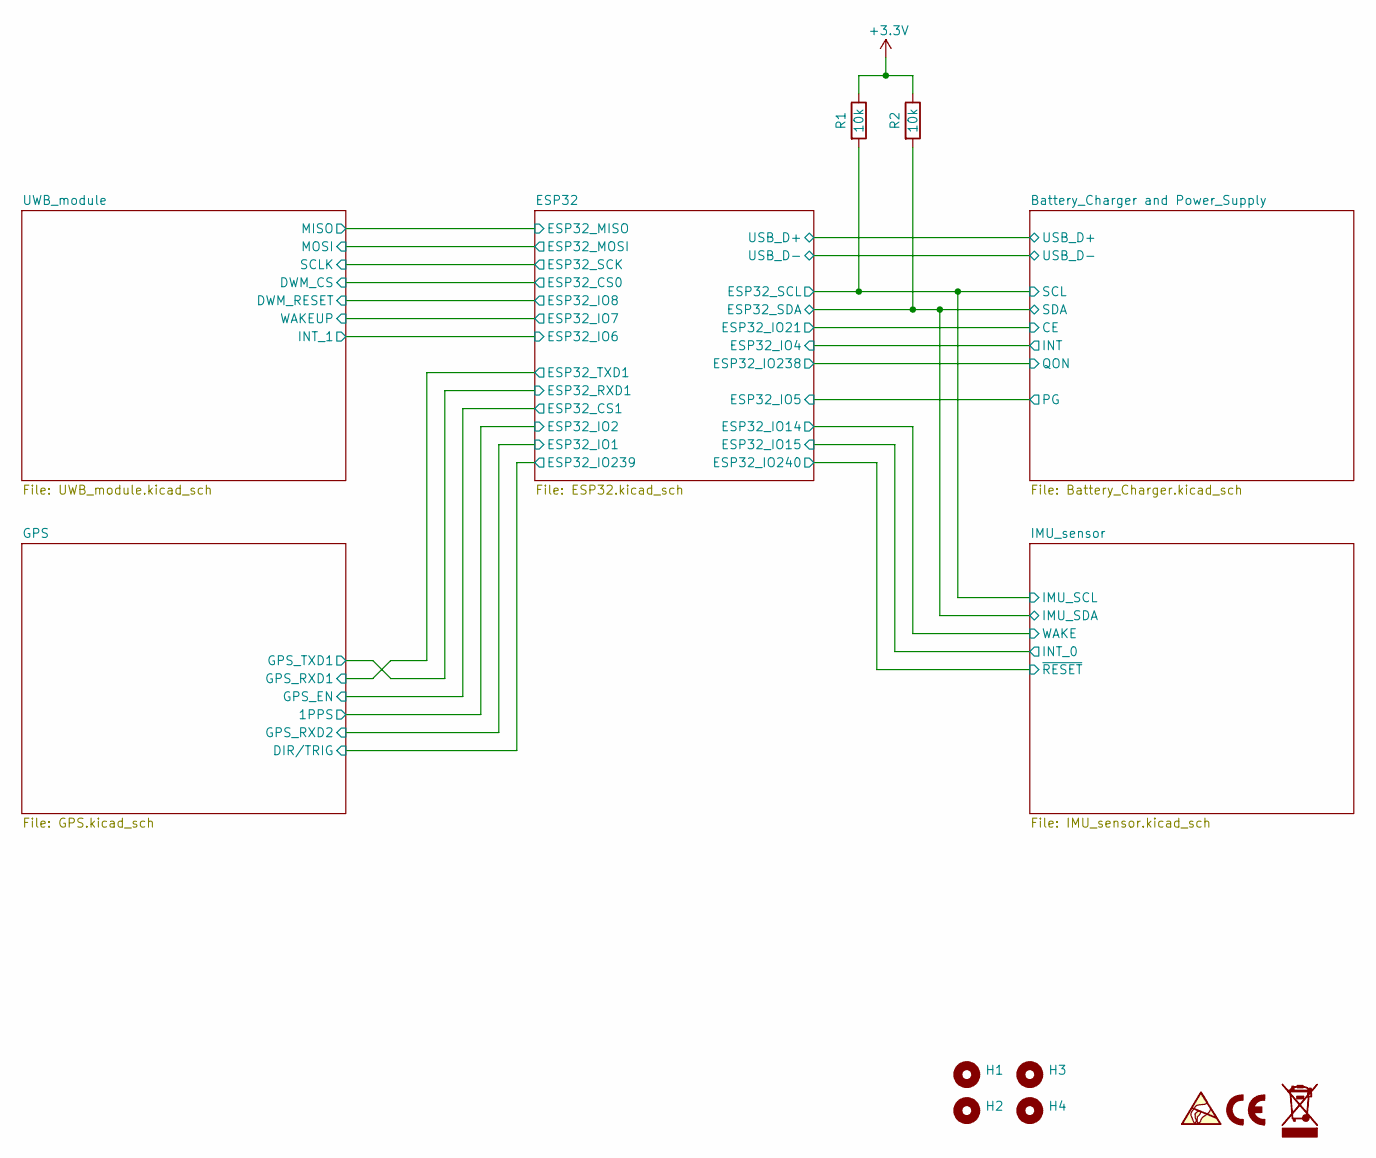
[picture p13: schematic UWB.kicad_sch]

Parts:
G1: LOGO; CE-Logo_8.5x6mm_SilkScreen
G2: LOGO; WEEE-Logo_4.2x6mm_SilkScreen
H1, H2, H3, H4: MountingHole; MountingHole_3.2mm_M3
R1, R2: 10k; R_0603_1608Metric; Mfr. part number CR0603-FX-1002ELF; JLCPCB Part C25804
SYM1: SYM_ESD_Small; ESD-Logo_6.6x6mm_SilkScreen

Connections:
+3.3V: R1.1, R2.1; also elsewhere on the board
/Battery_Charger and Power_Supply/SCL: R1.2; also elsewhere on the board
/Battery_Charger and Power_Supply/SDA: R2.2; also elsewhere on the board

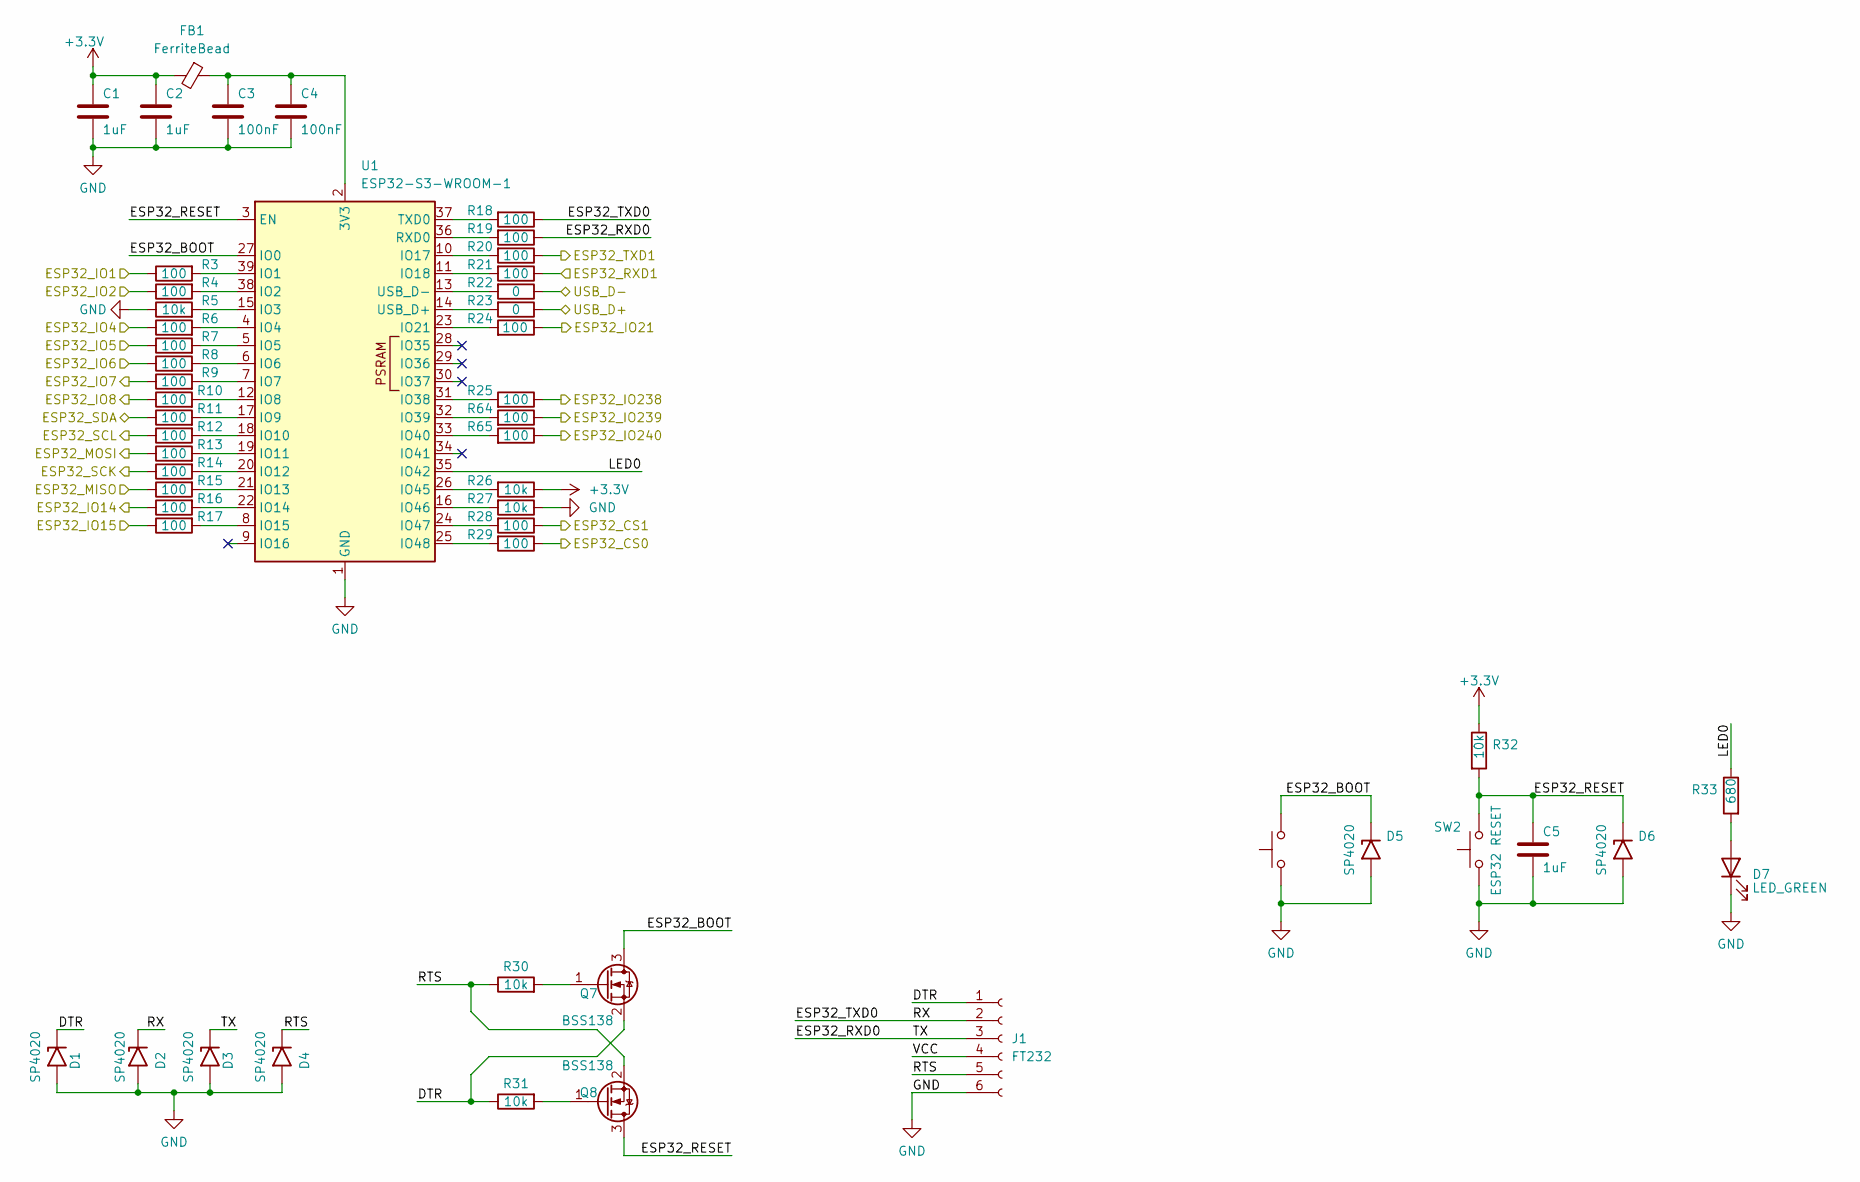
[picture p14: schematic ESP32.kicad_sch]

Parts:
C1, C2, C5: 1uF; C_0603_1608Metric; Mfr. part number 885012206052; JLCPCB Part C15849
C3, C4: 100nF; C_0603_1608Metric; Mfr. part number 06035C104KAZ4A; JLCPCB Part C14663
D1, D2, D3, D4, D5, D6: SP4020; D_SOD-323; Mfr. part number SP4020-01FTG-C; JLCPCB Part C126842
D7: LED_GREEN; LED_0603_1608Metric; Mfr. part number 150060VS75000; JLCPCB Part C22371297
FB1: FerriteBead; L_0805_2012Metric; Mfr. part number BLM21SP601SN1D; JLCPCB Part C3716677
J1: FT232; PinSocket_1x06_P2.54mm_Vertical; Mfr. part number 215297-6; JLCPCB Part C8690
Q7, Q8: BSS138; SOT-23; Mfr. part number BSS138; JLCPCB Part C5224261
R3, R4, R6, R7, R8, R9, R10, R11, R12, R13, R14, R15, R16, R17, R18, R19, R20, R21, R24, R25, R28, R29, R64, R65: 100; R_0603_1608Metric; Mfr. part number RE0603FRE07330RL; JLCPCB Part C22775
R5, R26, R27, R30, R31, R32: 10k; R_0603_1608Metric; Mfr. part number CR0603-FX-1002ELF; JLCPCB Part C25804
R22, R23: 0; R_0603_1608Metric; Mfr. part number RC0603FR-130RL; JLCPCB Part C21189
R33: 680; R_0603_1608Metric; Mfr. part number CRGCQ0603F680R; JLCPCB Part C23228
SW1: ESP32 BOOT; SW_Push_1P1T_NO_CK_KMR2; Mfr. part number PTS815SJM250SMTR LFS; JLCPCB Part C99271
SW2: ESP32 RESET; SW_Push_1P1T_NO_CK_KMR2; Mfr. part number PTS815SJM250SMTR LFS; JLCPCB Part C99271
U1: ESP32-S3-WROOM-1; Mfr. part number ESP32-S3-WROOM-1-N16R8; JLCPCB Part C2913202

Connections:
+3.3V: C1.1, C2.1, FB1.2, R26.1, R32.1; also elsewhere on the board
/Battery_Charger and Power_Supply/INT: R6.1; also elsewhere on the board
/Battery_Charger and Power_Supply/PG: R7.1; also elsewhere on the board
/Battery_Charger and Power_Supply/QON: R25.1; also elsewhere on the board
/Battery_Charger and Power_Supply/SCL: R12.1; also elsewhere on the board
/Battery_Charger and Power_Supply/SDA: R11.1; also elsewhere on the board
/Battery_Charger and Power_Supply/USB_D+: R23.1; also elsewhere on the board
/Battery_Charger and Power_Supply/USB_D-: R22.1; also elsewhere on the board
/ESP32/DTR: D1.1 (A1), J1.1, Q7.2 (S), R31.1
/ESP32/ESP32_BOOT: D5.1 (A1), Q7.3 (D), SW1.2, U1.27 (IO0)
/ESP32/ESP32_CS0: R29.1; also elsewhere on the board
/ESP32/ESP32_CS1: R28.1; also elsewhere on the board
/ESP32/ESP32_IO1: R3.1; also elsewhere on the board
/ESP32/ESP32_IO2: R4.1; also elsewhere on the board
/ESP32/ESP32_IO8: R10.1; also elsewhere on the board
/ESP32/ESP32_IO14: R16.1; also elsewhere on the board
/ESP32/ESP32_IO15: R17.1; also elsewhere on the board
/ESP32/ESP32_IO21: R24.1
/ESP32/ESP32_MISO: R15.1; also elsewhere on the board
/ESP32/ESP32_MOSI: R13.1; also elsewhere on the board
/ESP32/ESP32_RESET: C5.1, D6.1 (A1), Q8.3 (D), R32.2, SW2.2, U1.3 (EN)
/ESP32/ESP32_RXD0: D3.1 (A1), J1.3, R19.1
/ESP32/ESP32_RXD1: R21.1; also elsewhere on the board
/ESP32/ESP32_SCK: R14.1; also elsewhere on the board
/ESP32/ESP32_TXD0: D2.1 (A1), J1.2, R18.1
/ESP32/ESP32_TXD1: R20.1; also elsewhere on the board
/ESP32/LED0: R33.1, U1.35 (IO42)
/ESP32/RTS: D4.1 (A1), J1.5, Q8.2 (S), R30.1
/ESP32/VCC: J1.4
/GPS/DIR/TRIG: R64.1; also elsewhere on the board
/IMU_sensor/~RESET: R65.1; also elsewhere on the board
/UWB_module/IRQ/GPIO8: R8.1; also elsewhere on the board
/UWB_module/WAKEUP: R9.1; also elsewhere on the board
GND: C1.2, C2.2, C3.2, C4.2, C5.2, D1.2 (A2), D2.2 (A2), D3.2 (A2), D4.2 (A2), D5.2 (A2), D6.2 (A2), D7.1 (K), J1.6, R5.1, R27.1, SW1.1, SW2.1, U1.1 (GND), U1.40 (GND), U1.41 (GND); also elsewhere on the board
unnamed: D7.2 (A), R33.2
unnamed: Q7.1 (G), R30.2
unnamed: Q8.1 (G), R31.2
unnamed: C3.1, C4.1, FB1.1, U1.2 (3V3)
unnamed: R3.2, U1.39 (IO1)
unnamed: R4.2, U1.38 (IO2)
unnamed: R5.2, U1.15 (IO3)
unnamed: R6.2, U1.4 (IO4)
unnamed: R7.2, U1.5 (IO5)
unnamed: R8.2, U1.6 (IO6)
unnamed: R9.2, U1.7 (IO7)
unnamed: R10.2, U1.12 (IO8)
unnamed: R11.2, U1.17 (IO9)
unnamed: R12.2, U1.18 (IO10)
unnamed: R13.2, U1.19 (IO11)
unnamed: R14.2, U1.20 (IO12)
unnamed: R15.2, U1.21 (IO13)
unnamed: R16.2, U1.22 (IO14)
unnamed: R17.2, U1.8 (IO15)
unnamed: R20.2, U1.10 (IO17)
unnamed: R21.2, U1.11 (IO18)
unnamed: R24.2, U1.23 (IO21)
unnamed: R25.2, U1.31 (IO38)
unnamed: R64.2, U1.32 (IO39)
unnamed: R65.2, U1.33 (IO40)
unnamed: R26.2, U1.26 (IO45)
unnamed: R27.2, U1.16 (IO46)
unnamed: R28.2, U1.24 (IO47)
unnamed: R29.2, U1.25 (IO48)
unnamed: R19.2, U1.36 (RXD0)
unnamed: R18.2, U1.37 (TXD0)
unnamed: R23.2, U1.14 (USB_D+)
unnamed: R22.2, U1.13 (USB_D-)

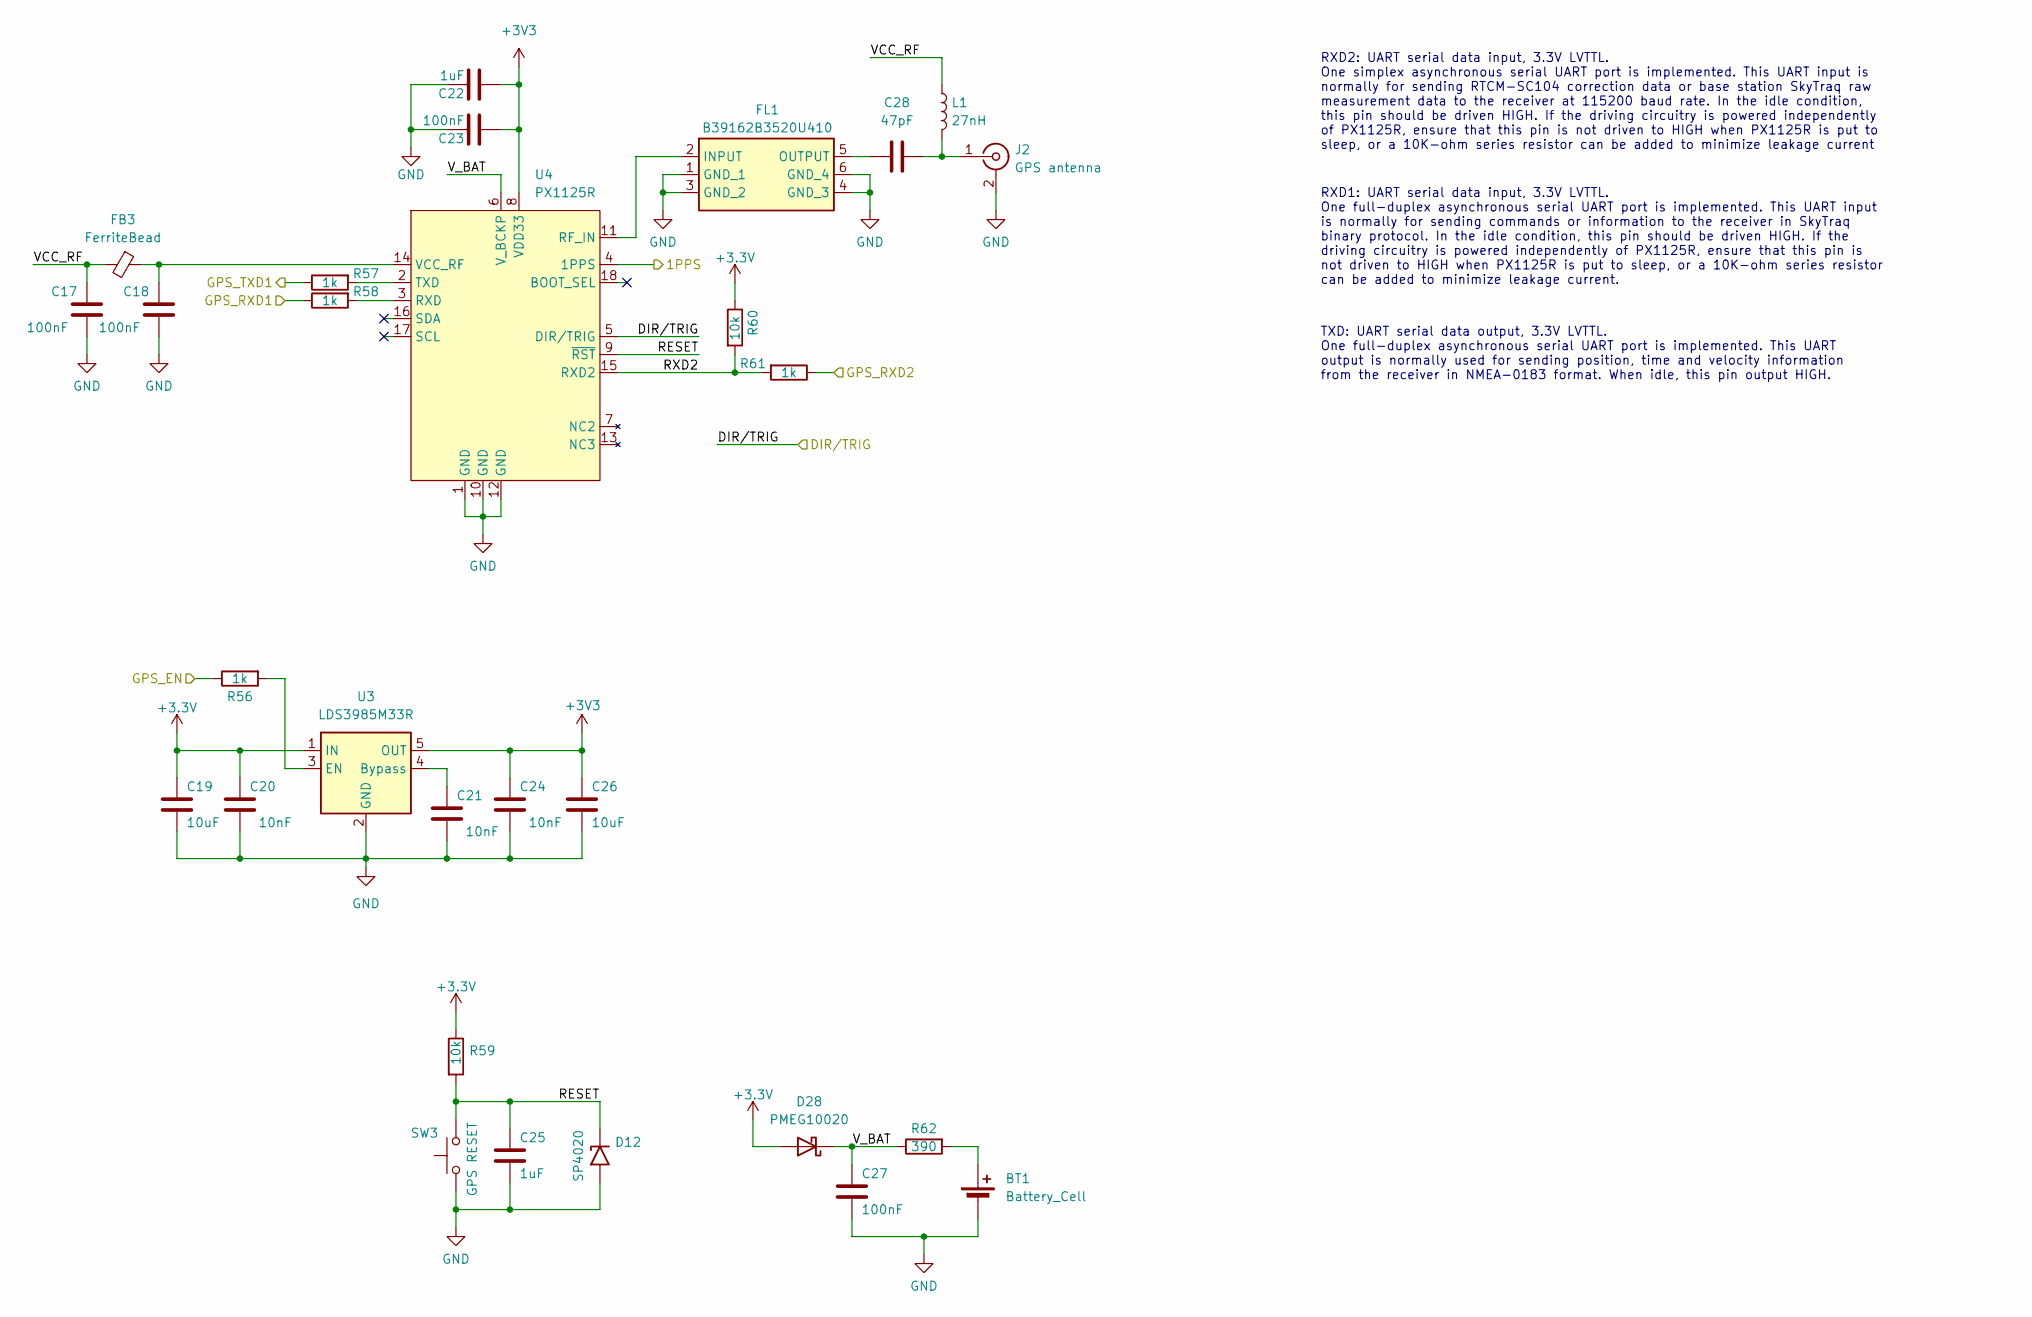
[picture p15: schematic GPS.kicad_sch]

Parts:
BT1: Battery_Cell; BatteryHolder_Seiko_MS621F; Mfr. part number MS621FE-FL11E
C17, C18, C23, C27: 100nF; C_0603_1608Metric; Mfr. part number 06035C104KAZ4A; JLCPCB Part C14663
C19, C26: 10uF; C_0603_1608Metric; Mfr. part number GRM188Z71A106KA73D; JLCPCB Part C19702
C20, C21, C24: 10nF; C_0603_1608Metric; Mfr. part number SH18B103K160CT; JLCPCB Part C57112
C22, C25: 1uF; C_0603_1608Metric; Mfr. part number 885012206052; JLCPCB Part C15849
C28: 47pF; C_0603_1608Metric; Mfr. part number 06033C470KAT2A; JLCPCB Part C23345
D12: SP4020; D_SOD-323; Mfr. part number SP4020-01FTG-C; JLCPCB Part C126842
D28: PMEG10020; D_SOD-123F; Mfr. part number PMEG10020ELR-QX; JLCPCB Part C8597
FB3: FerriteBead; L_0805_2012Metric; Mfr. part number BLM21SP601SN1D; JLCPCB Part C3716677
FL1: B39162B3520U410; Mfr. part number B39162B3520U410; JLCPCB Part C2650959
J2: GPS antenna; SMA_Samtec_SMA-J-P-H-ST-EM1_EdgeMount; Mfr. part number SMA-J-P-H-ST-EM1; JLCPCB Part C5199907
L1: 27nH; L_0603_1608Metric; Mfr. part number LQW18AN27NJ00D; JLCPCB Part C98072
R56, R57, R58, R61: 1k; R_0603_1608Metric; Mfr. part number AC0603DR-071KL; JLCPCB Part C21190
R59, R60: 10k; R_0603_1608Metric; Mfr. part number CR0603-FX-1002ELF; JLCPCB Part C25804
R62: 390; R_0603_1608Metric; Mfr. part number RC0603FR-07390RP; JLCPCB Part C23151
SW3: GPS RESET; SW_Push_1P1T_NO_CK_KMR2; Mfr. part number PTS815SJM250SMTR LFS; JLCPCB Part C99271
U3: LDS3985M33R; SOT-23-5; Mfr. part number LDS3985M30R; JLCPCB Part C2970345
U4: PX1125R; PX1105R; Mfr. part number PX1105R; JLCPCB Part C9900164713

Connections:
+3.3V: C19.1, C20.1, D28.2 (A), R59.1, R60.1, U3.1 (IN); also elsewhere on the board
+3V3: C22.2, C23.2, C24.1, C26.1, U3.5 (OUT), U4.8 (VDD33)
/ESP32/ESP32_CS1: R56.1; also elsewhere on the board
/ESP32/ESP32_IO1: R61.1; also elsewhere on the board
/ESP32/ESP32_IO2: U4.4 (1PPS); also elsewhere on the board
/ESP32/ESP32_RXD1: R57.1; also elsewhere on the board
/ESP32/ESP32_TXD1: R58.1; also elsewhere on the board
/GPS/DIR/TRIG: U4.5 (DIR/TRIG); also elsewhere on the board
/GPS/RESET: C25.1, D12.1 (A1), R59.2, SW3.2, U4.9 (~RST)
/GPS/RXD2: R60.2, R61.2, U4.15 (RXD2)
/GPS/VCC_RF: C17.1, FB3.2, L1.1
/GPS/V_BAT: C27.1, D28.1 (K), R62.1, U4.6 (V_BCKP)
GND: BT1.2 (-), C17.2, C18.2, C19.2, C20.2, C21.2, C22.1, C23.1, C24.2, C25.2, C26.2, C27.2, D12.2 (A2), FL1.1 (GND_1), FL1.3 (GND_2), FL1.4 (GND_3), FL1.6 (GND_4), J2.2 (Ext), SW3.1, U3.2 (GND), U4.1 (GND), U4.10 (GND), U4.12 (GND); also elsewhere on the board
unnamed: BT1.1 (+), R62.2
unnamed: FL1.2 (INPUT), U4.11 (RF_IN)
unnamed: C28.1, FL1.5 (OUTPUT)
unnamed: C28.2, J2.1 (In), L1.2
unnamed: C21.1, U3.4 (Bypass)
unnamed: R56.2, U3.3 (EN)
unnamed: R58.2, U4.3 (RXD)
unnamed: R57.2, U4.2 (TXD)
unnamed: C18.1, FB3.1, U4.14 (VCC_RF)

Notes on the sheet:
RXD1: UART serial data input, 3.3V LVTTL. One full-duplex asynchronous serial UART port is implemented. This UART input is normally for sending commands or information to the receiver in SkyTraq binary protocol. In the idle condition, this pin should be driven HIGH. If the driving circuitry is powe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
TXD: UART serial data output, 3.3V LVTTL. One full-duplex asynchronous serial UART port is implemented. This UART output is normally used for sending position, time and velocity information from the receiver in NMEA-0183 format. When idle, this pin output HIGH.
RXD2: UART serial data input, 3.3V LVTTL. One simplex asynchronous serial UART port is implemented. This UART input is normally for sending RTCM-SC104 correction data or base station SkyTraq raw measurement data to the receiver at 115200 baud rate. In the idle condition, this pin should be driven H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

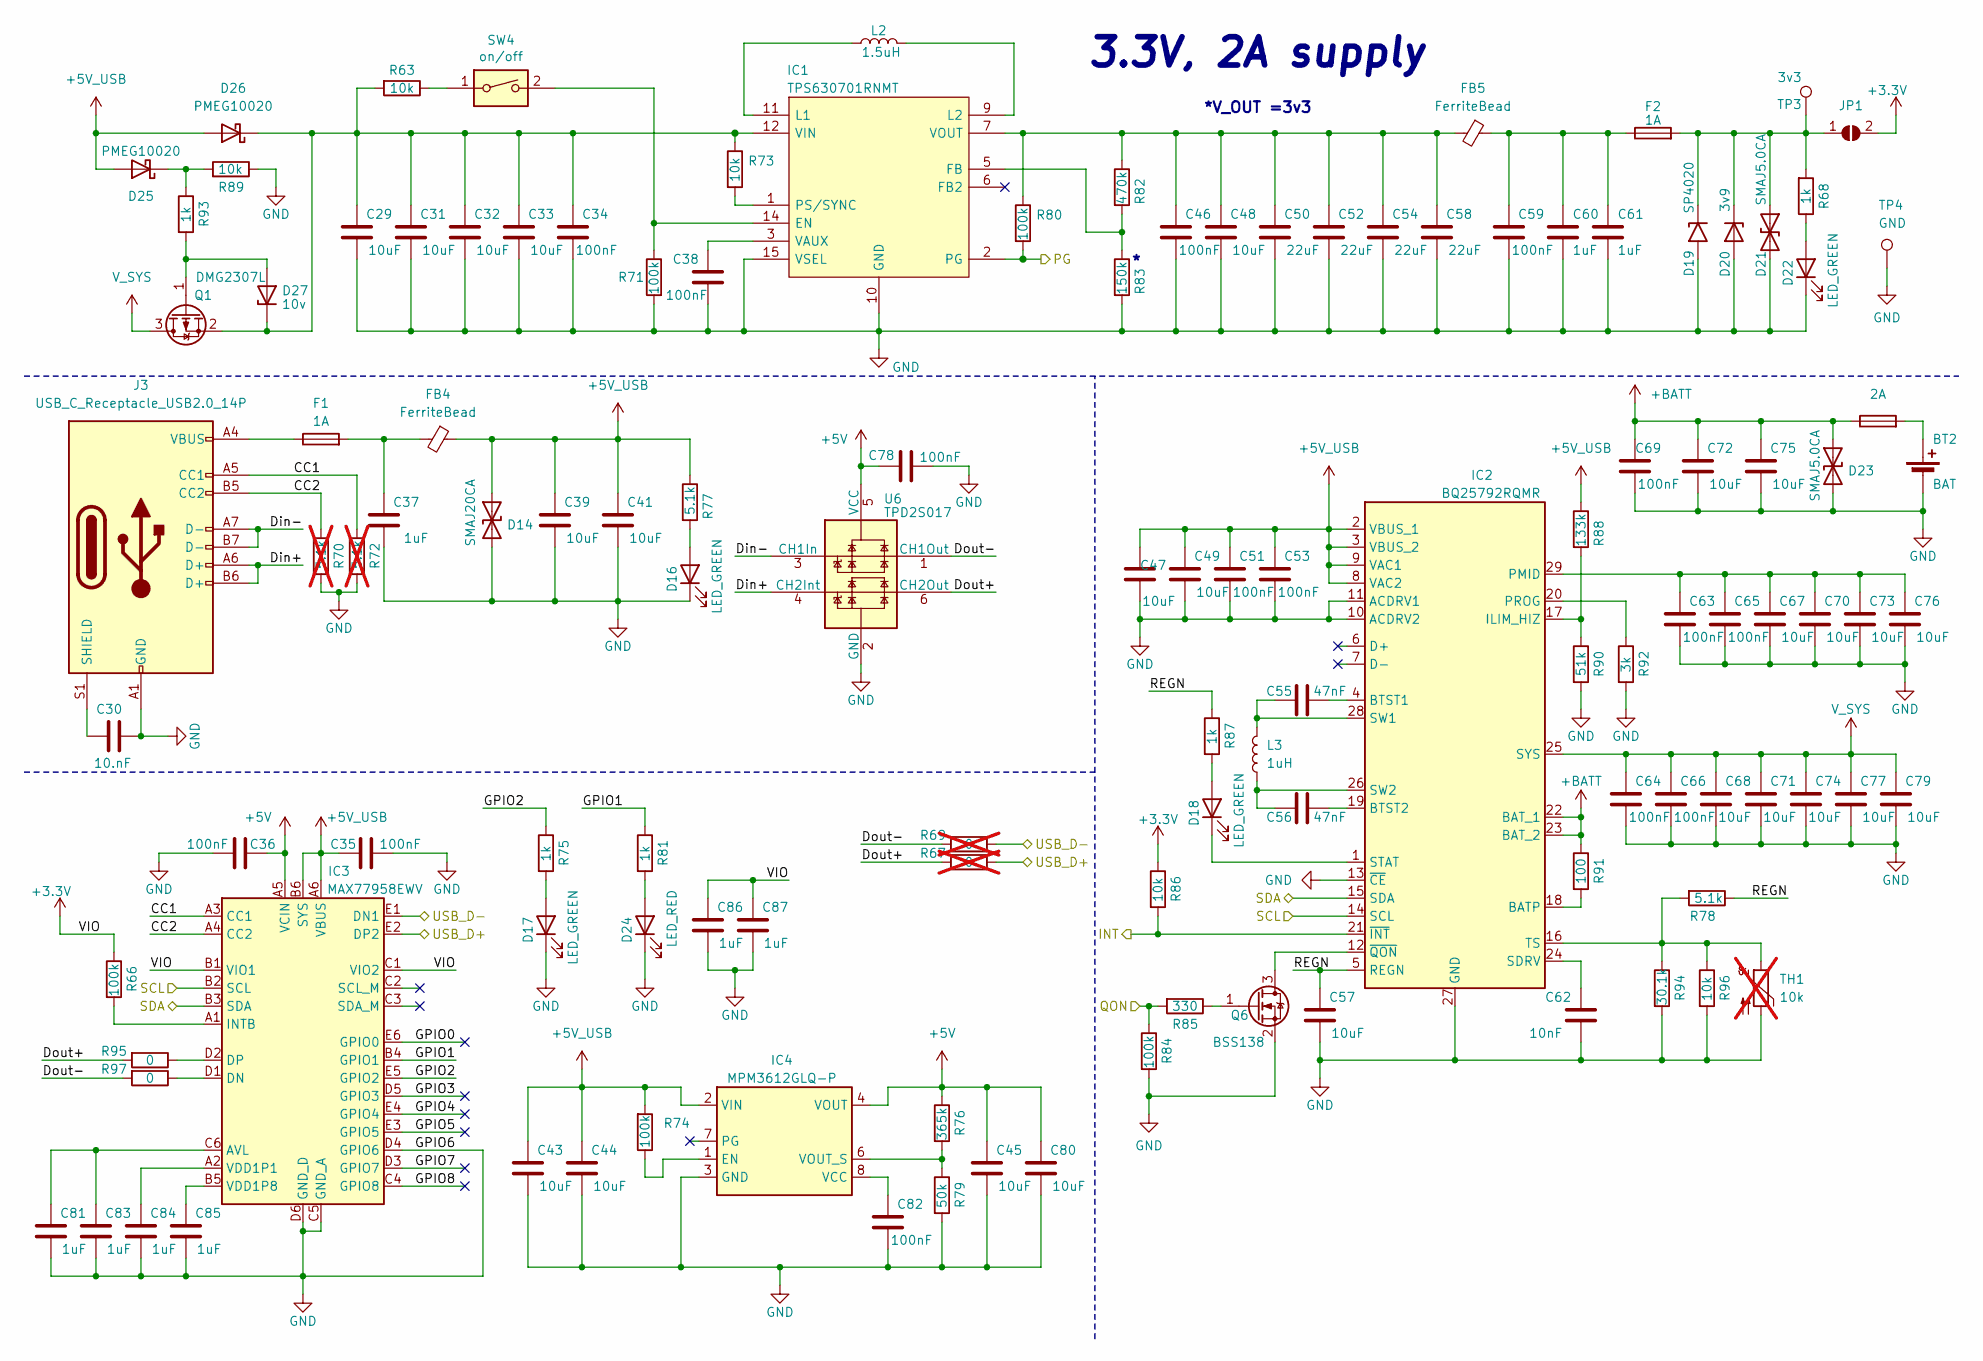
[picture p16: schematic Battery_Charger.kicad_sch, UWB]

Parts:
BT2: BAT; JST_PH_B2B-PH-K_1x02_P2.00mm_Vertical; Mfr. part number L475085; JLCPCB Part C131337
C29, C31, C32, C33, C39, C41, C43, C44, C45, C47, C48, C49, C57, C67, C68, C70, C71, C72, C73, C74, C75, C76, C77, C79, C80: 10uF; C_0603_1608Metric; Mfr. part number GRM188Z71A106KA73D; JLCPCB Part C19702
C30: 10.nF; C_1812_4532Metric; Mfr. part number CAS18C471JAGFC; JLCPCB Part C3287694
C34, C35, C36, C38, C46, C51, C53, C59, C63, C64, C65, C66, C69, C78, C82: 100nF; C_0603_1608Metric; Mfr. part number 06035C104KAZ4A; JLCPCB Part C14663
C37, C60, C61, C81, C83, C84, C85, C86, C87: 1uF; C_0603_1608Metric; Mfr. part number 885012206052; JLCPCB Part C15849
C50, C52, C54, C58: 22uF; C_1206_3216Metric; Mfr. part number CL31B226KPHNNNE; JLCPCB Part C12891
C55, C56: 47nF; C_0603_1608Metric; Mfr. part number 885012205054; JLCPCB Part C1622
C62: 10nF; C_0603_1608Metric; Mfr. part number SH18B103K160CT; JLCPCB Part C57112
D14: SMAJ20CA; D_SMA; Mfr. part number SMAJ20CA; JLCPCB Part C134970
D16, D17, D18, D22: LED_GREEN; LED_0603_1608Metric; Mfr. part number 150060VS75000; JLCPCB Part C22371297
D19: SP4020; D_SOD-323; Mfr. part number SP4020-01FTG-C; JLCPCB Part C126842
D20: 3v9; D_SMA; Mfr. part number BZG05C3V9-M3-08
D21, D23: SMAJ5.0CA; D_SMA; Mfr. part number SMAJ5.0CA; JLCPCB Part C83324
D24: LED_RED; LED_0603_1608Metric; Mfr. part number 150060RS75000; JLCPCB Part C965799
D25, D26: PMEG10020; D_SOD-123F; Mfr. part number PMEG10020ELR-QX; JLCPCB Part C8597
D27: 10v; D_SOD-123F; Mfr. part number 78-MMSZ4697-HE3_A-08; JLCPCB Part C2922775
F1, F2: 1A; Fuse_1206_3216Metric; Mfr. part number C1T 1; JLCPCB Part C2838907
F3: 2A; Fuse_1206_3216Metric; Mfr. part number C1T 2; JLCPCB Part C18211642
FB4, FB5: FerriteBead; L_0805_2012Metric; Mfr. part number BLM21SP601SN1D; JLCPCB Part C3716677
IC1: TPS630701RNMT; TPS630702RNMT; Mfr. part number TPS630702RNMR; JLCPCB Part C181473
IC2: BQ25792RQMR; Mfr. part number BQ25792RQMR; JLCPCB Part C2862876
IC3: MAX77958EWV; BGA30C50P6X5_307X262X69; Manufacturer_Part_Number MAX77958EWV
IC4: MPM3612GLQ-P; MPM3612GLQ33P; Mfr. part number MPM3612GLQ-P
J3: USB_C_Receptacle_USB2.0_14P; USB_C_Receptacle_GCT_USB4105-xx-A_16P_TopMnt_Horizontal; Mfr. part number USB4105-GF-A-120; JLCPCB Part C5184243
JP1: SolderJumper_2_Open; SolderJumper-2_P1.3mm_Open_RoundedPad1.0x1.5mm
L2: 1.5uH; L_Taiyo-Yuden_NR-60xx; Mfr. part number NRM6045T1R5NMRRV; JLCPCB Part C3221450
L3: 1uH; L_Taiyo-Yuden_NR-60xx; Mfr. part number NRS6045T1R0NMGKV; JLCPCB Part C1331878
Q1: DMG2307L; SOT-23; Mfr. part number DMG2307L-7; JLCPCB Part C102620
Q6: BSS138; SOT-23; Mfr. part number BSS138; JLCPCB Part C5224261
R63, R73, R86, R89, R96: 10k; R_0603_1608Metric; Mfr. part number CR0603-FX-1002ELF; JLCPCB Part C25804
R66, R71, R74, R80, R84: 100k; R_0603_1608Metric; Mfr. part number RC0603FR-10100KL; JLCPCB Part C25803
R67, R69: 0; R_0603_1608Metric; Mfr. part number RC0603FR-130RL; JLCPCB Part C21189; not fitted
R68, R75, R81, R87, R93: 1k; R_0603_1608Metric; Mfr. part number AC0603DR-071KL; JLCPCB Part C21190
R70, R72: 5.1k; R_0603_1608Metric; Mfr. part number AC0603FR-135K1L; JLCPCB Part C23186; not fitted
R76: 365k; R_0603_1608Metric; Mfr. part number RC0603FR-07365KL; JLCPCB Part C23031
R77, R78: 5.1k; R_0603_1608Metric; Mfr. part number AC0603FR-135K1L; JLCPCB Part C23186
R79: 50k; R_0603_1608Metric; Mfr. part number AC0603FR-0751KL; JLCPCB Part C861451
R82: 470k; R_0603_1608Metric; Mfr. part number AC0603FR-07470KL; JLCPCB Part C23178
R83: 150k; R_0603_1608Metric; Mfr. part number RC0603FR-13150KL; JLCPCB Part C22807
R85: 330; R_0603_1608Metric; Mfr. part number RE0603FRE07330RL; JLCPCB Part C23138
R88: 133k; R_0603_1608Metric; Mfr. part number RC0603FR-07133KL; JLCPCB Part C22870
R90: 51k; R_0603_1608Metric; Mfr. part number AC0603FR-0751KL; JLCPCB Part C18672
R91: 100; R_0603_1608Metric; Mfr. part number RE0603FRE07330RL; JLCPCB Part C22775
R92: 3k; R_0603_1608Metric; Mfr. part number 603-RC0603JR-073KL
R94: 30.1k; R_0603_1608Metric; Mfr. part number RC0603FR-0730K1L; JLCPCB Part C23000
R95, R97: 0; R_0603_1608Metric; Mfr. part number RC0603FR-130RL; JLCPCB Part C21189
SW4: on/off; SW_SPDT_PCM12; Mfr. part number PCM12SMTBR; JLCPCB Part C18197923
TH1: 10k; JST_PH_B2B-PH-K_1x02_P2.00mm_Vertical; Mfr. Part No. B2B-PH-K-S (LF)(SN); JLCPCB Part C25804; not fitted
TP3: 3v3; TestPoint_Pad_D2.0mm
TP4: GND; TestPoint_Pad_D2.0mm
U6: TPD2S017; SOT-23-6; Mfr. part number TPD2S017DBVR; JLCPCB Part C880115

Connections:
+3.3V: C86.1, C87.1, IC3.B1 (VIO1), IC3.C1 (VIO2), JP1.2 (B), R66.1, R86.1; also elsewhere on the board
+5V: C36.1, C45.1, C78.1, C80.1, IC3.A5 (VCIN), IC4.4 (VOUT), IC4.5 (VOUT_2), R76.1, U6.5 (VCC)
+5V_USB: C35.1, C39.1, C41.1, C43.1, C44.1, C47.1, C49.1, C51.1, C53.1, D14.1 (A1), D25.2 (A), D26.2 (A), FB4.1, IC2.2 (VBUS_1), IC2.3 (VBUS_2), IC2.8 (VAC2), IC2.9 (VAC1), IC2.31 (VAC1_2), IC3.A6 (VBUS), IC3.B6 (SYS), IC4.2 (VIN), R74.2, R77.1, R88.1
+BATT: C69.1, C72.1, C75.1, D23.1 (A1), F3.1, IC2.22 (BAT_1), IC2.23 (BAT_2), R91.1
/Battery_Charger and Power_Supply/CC1: IC3.A3 (CC1), J3.A5 (CC1), R72.1
/Battery_Charger and Power_Supply/CC2: IC3.A4 (CC2), J3.B5 (CC2), R70.1
/Battery_Charger and Power_Supply/Din+: J3.A6 (D+), J3.B6 (D+), U6.4 (CH2Int)
/Battery_Charger and Power_Supply/Din-: J3.A7 (D-), J3.B7 (D-), U6.3 (CH1In)
/Battery_Charger and Power_Supply/Dout+: R67.2, R95.2, U6.6 (CH2Out)
/Battery_Charger and Power_Supply/Dout-: R69.2, R97.2, U6.1 (CH1Out)
/Battery_Charger and Power_Supply/GPIO0: IC3.E6 (GPIO0)
/Battery_Charger and Power_Supply/GPIO1: IC3.B4 (GPIO1), R81.1
/Battery_Charger and Power_Supply/GPIO2: IC3.E5 (GPIO2), R75.1
/Battery_Charger and Power_Supply/GPIO3: IC3.D5 (GPIO3)
/Battery_Charger and Power_Supply/GPIO4: IC3.E4 (GPIO4)
/Battery_Charger and Power_Supply/GPIO5: IC3.E3 (GPIO5)
/Battery_Charger and Power_Supply/GPIO7: IC3.D3 (GPIO7)
/Battery_Charger and Power_Supply/GPIO8: IC3.C4 (GPIO8)
/Battery_Charger and Power_Supply/INT: IC2.21 (~INT), R86.2; also elsewhere on the board
/Battery_Charger and Power_Supply/PG: IC1.2 (PG), R80.2; also elsewhere on the board
/Battery_Charger and Power_Supply/QON: R84.1, R85.2; also elsewhere on the board
/Battery_Charger and Power_Supply/REGN: C57.1, IC2.5 (REGN), R78.1, R87.1
/Battery_Charger and Power_Supply/SCL: IC2.14 (SCL), IC3.B2 (SCL); also elsewhere on the board
/Battery_Charger and Power_Supply/SDA: IC2.15 (SDA), IC3.B3 (SDA); also elsewhere on the board
/Battery_Charger and Power_Supply/USB_D+: IC3.E2 (DP2), R67.1; also elsewhere on the board
/Battery_Charger and Power_Supply/USB_D-: IC3.E1 (DN1), R69.1; also elsewhere on the board
GND: BT2.2 (-), C29.2, C30.2, C31.2, C32.2, C33.2, C34.2, C35.2, C36.2, C37.2, C38.2, C39.2, C41.2, C43.2, C44.2, C45.2, C46.2, C47.2, C48.2, C49.2, C50.2, C51.2, C52.2, C53.2, C54.2, C57.2, C58.2, C59.2, C60.2, C61.2, C62.2, C63.2, C64.2, C65.2, C66.2, C67.2, C68.2, C69.2, C70.2, C71.2, C72.2, C73.2, C74.2, C75.2, C76.2, C77.2, C78.2, C79.2, C80.2, C81.2, C82.2, C83.2, C84.2, C85.2, C86.2, C87.2, D14.2 (A2), D16.1 (K), D17.1 (K), D19.2 (A2), D20.2 (A), D21.2 (A2), D22.1 (K), D23.2 (A2), D24.1 (K), IC1.4 (GND), IC1.10 (GND), IC1.15 (VSEL), IC2.10 (ACDRV2), IC2.11 (ACDRV1), IC2.13 (~CE), IC2.27 (GND), IC3.C5 (GND_A), IC3.D4 (GPIO6), IC3.D6 (GND_D), IC4.3 (GND), IC4.9 (GND_2), J3.A1 (GND), J3.A12 (GND), J3.B1 (GND), J3.B12 (GND), Q6.2 (S), R70.2, R71.2, R72.2, R79.2, R83.2, R84.2, R89.1, R90.2, R92.2, R94.2, R96.2, TH1.2, TP4.1, U6.2 (GND); also elsewhere on the board
unnamed: BT2.1 (+), F3.2
unnamed: C37.1, F1.2, FB4.2
unnamed: C59.1, C60.1, C61.1, F2.1, FB5.1
unnamed: D16.2 (A), R77.2
unnamed: D17.2 (A), R75.2
unnamed: D18.2 (A), R87.2
unnamed: D18.1 (K), IC2.1 (STAT), IC2.30 (STAT_2)
unnamed: D19.1 (A1), D20.1 (K), D21.1 (A1), F2.2, JP1.1 (A), R68.2, TP3.1
unnamed: D22.2 (A), R68.1
unnamed: D24.2 (A), R81.2
unnamed: D25.1 (K), R89.2, R93.1
unnamed: C29.1, C31.1, C32.1, C33.1, C34.1, D26.1 (K), D27.1 (K), IC1.12 (VIN), IC1.13 (VIN_2), IC1.A12 (VIN_3), Q1.2 (S), R63.2, R73.1
unnamed: D27.2 (A), Q1.1 (G), R93.2
unnamed: F1.1, J3.A4 (VBUS), J3.A9 (VBUS), J3.B4 (VBUS), J3.B9 (VBUS)
unnamed: IC1.14 (EN), R71.1, SW4.2
unnamed: IC1.5 (FB), R82.2, R83.1
unnamed: IC1.11 (L1), L2.2
unnamed: IC1.9 (L2), L2.1
unnamed: IC1.1 (PS/SYNC), R73.2
unnamed: C38.1, IC1.3 (VAUX)
unnamed: C46.1, C48.1, C50.1, C52.1, C54.1, C58.1, FB5.2, IC1.7 (VOUT), IC1.8 (VOUT_2), IC1.A7 (VOUT_3), R80.1, R82.1
unnamed: IC2.18 (BATP), R91.2
unnamed: C55.2, IC2.4 (BTST1)
unnamed: C56.2, IC2.19 (BTST2)
unnamed: IC2.17 (ILIM_HIZ), R88.2, R90.1
unnamed: C63.1, C65.1, C67.1, C70.1, C73.1, C76.1, IC2.29 (PMID)
unnamed: IC2.20 (PROG), R92.1
unnamed: C62.1, IC2.24 (SDRV), IC2.33 (SDRV_2)
unnamed: C55.1, IC2.28 (SW1), L3.2
unnamed: C56.1, IC2.26 (SW2), L3.1
unnamed: IC2.16 (TS), IC2.32 (TS_2), R78.2, R94.1, R96.1, TH1.1
unnamed: IC2.12 (~QON), Q6.3 (D)
unnamed: C81.1, C83.1, IC3.C6 (AVL)
unnamed: IC3.D1 (DN), R97.1
unnamed: IC3.D2 (DP), R95.1
unnamed: IC3.A1 (INTB), R66.2
unnamed: C84.1, IC3.A2 (VDD1P1)
unnamed: C85.1, IC3.B5 (VDD1P8)
unnamed: IC4.1 (EN), R74.1
unnamed: C82.1, IC4.8 (VCC)
unnamed: IC4.6 (VOUT_S), R76.2, R79.1
unnamed: C30.1, J3.S1 (SHIELD)
unnamed: Q6.1 (G), R85.1
unnamed: R63.1, SW4.1
V_SYS: C64.1, C66.1, C68.1, C71.1, C74.1, C77.1, C79.1, IC2.25 (SYS), Q1.3 (D)

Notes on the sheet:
3.3V, 2A supply
*V_OUT =3v3

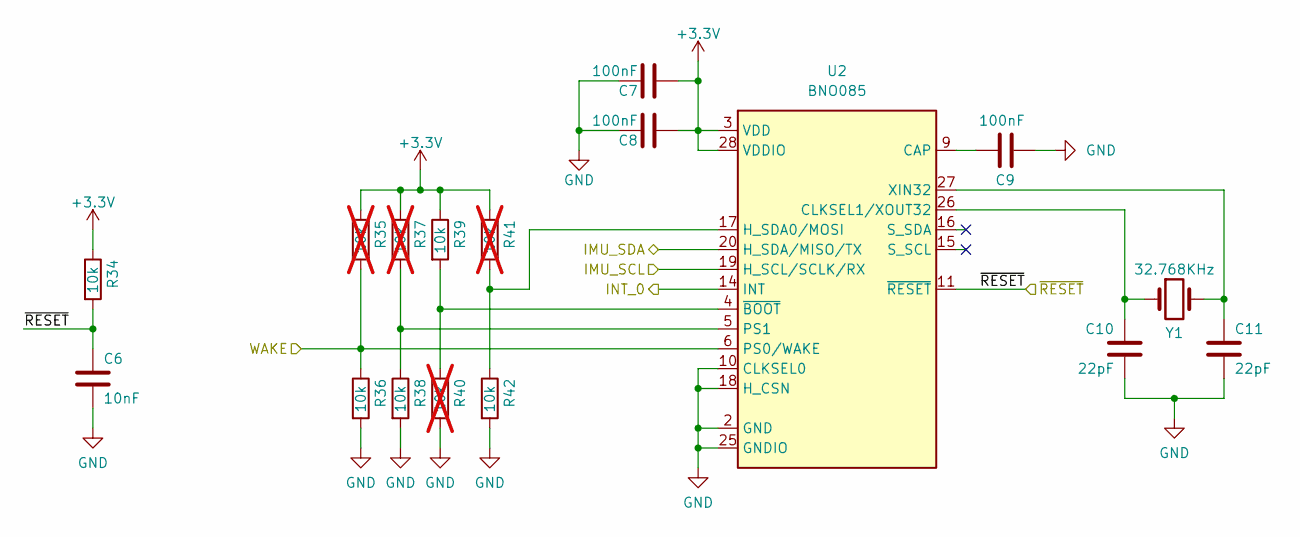
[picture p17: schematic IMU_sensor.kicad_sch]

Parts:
C6: 10nF; C_0603_1608Metric; Mfr. part number SH18B103K160CT; JLCPCB Part C57112
C7, C8, C9: 100nF; C_0603_1608Metric; Mfr. part number 06035C104KAZ4A; JLCPCB Part C14663
C10, C11: 22pF; C_0603_1608Metric; Mfr. part number 06033C220KAT2A; JLCPCB Part C1653
R34, R36, R38, R39, R42: 10k; R_0603_1608Metric; Mfr. part number CR0603-FX-1002ELF; JLCPCB Part C25804
R35, R37, R40, R41: 10k; R_0603_1608Metric; Mfr. part number CR0603-FX-1002ELF; JLCPCB Part C25804; not fitted
U2: BNO085; LGA-28_5.2x3.8mm_P0.5mm; Mfr. part number BNO085; JLCPCB Part C5189642
Y1: 32.768KHz; Crystal_SMD_2012-2Pin_2.0x1.2mm; Mfr. part number ABS06-32.768KHZ-T; JLCPCB Part C276423

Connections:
+3.3V: C7.2, C8.2, R34.1, R35.1, R37.1, R39.1, R41.1, U2.3 (VDD), U2.28 (VDDIO); also elsewhere on the board
/Battery_Charger and Power_Supply/SCL: U2.19 (H_SCL/SCLK/RX); also elsewhere on the board
/Battery_Charger and Power_Supply/SDA: U2.20 (H_SDA/MISO/TX); also elsewhere on the board
/ESP32/ESP32_IO14: R35.2, R36.1, U2.6 (PS0/WAKE); also elsewhere on the board
/ESP32/ESP32_IO15: U2.14 (INT); also elsewhere on the board
/IMU_sensor/~RESET: C6.1, R34.2, U2.11 (~RESET); also elsewhere on the board
GND: C6.2, C7.1, C8.1, C9.2, C10.2, C11.2, R36.2, R38.2, R40.2, R42.2, U2.2 (GND), U2.10 (CLKSEL0), U2.18 (H_CSN), U2.25 (GNDIO); also elsewhere on the board
unnamed: C9.1, U2.9 (CAP)
unnamed: C10.1, U2.26 (CLKSEL1/XOUT32), Y1.1
unnamed: R41.2, R42.1, U2.17 (H_SDA0/MOSI)
unnamed: R37.2, R38.1, U2.5 (PS1)
unnamed: C11.1, U2.27 (XIN32), Y1.2
unnamed: R39.2, R40.1, U2.4 (~BOOT)

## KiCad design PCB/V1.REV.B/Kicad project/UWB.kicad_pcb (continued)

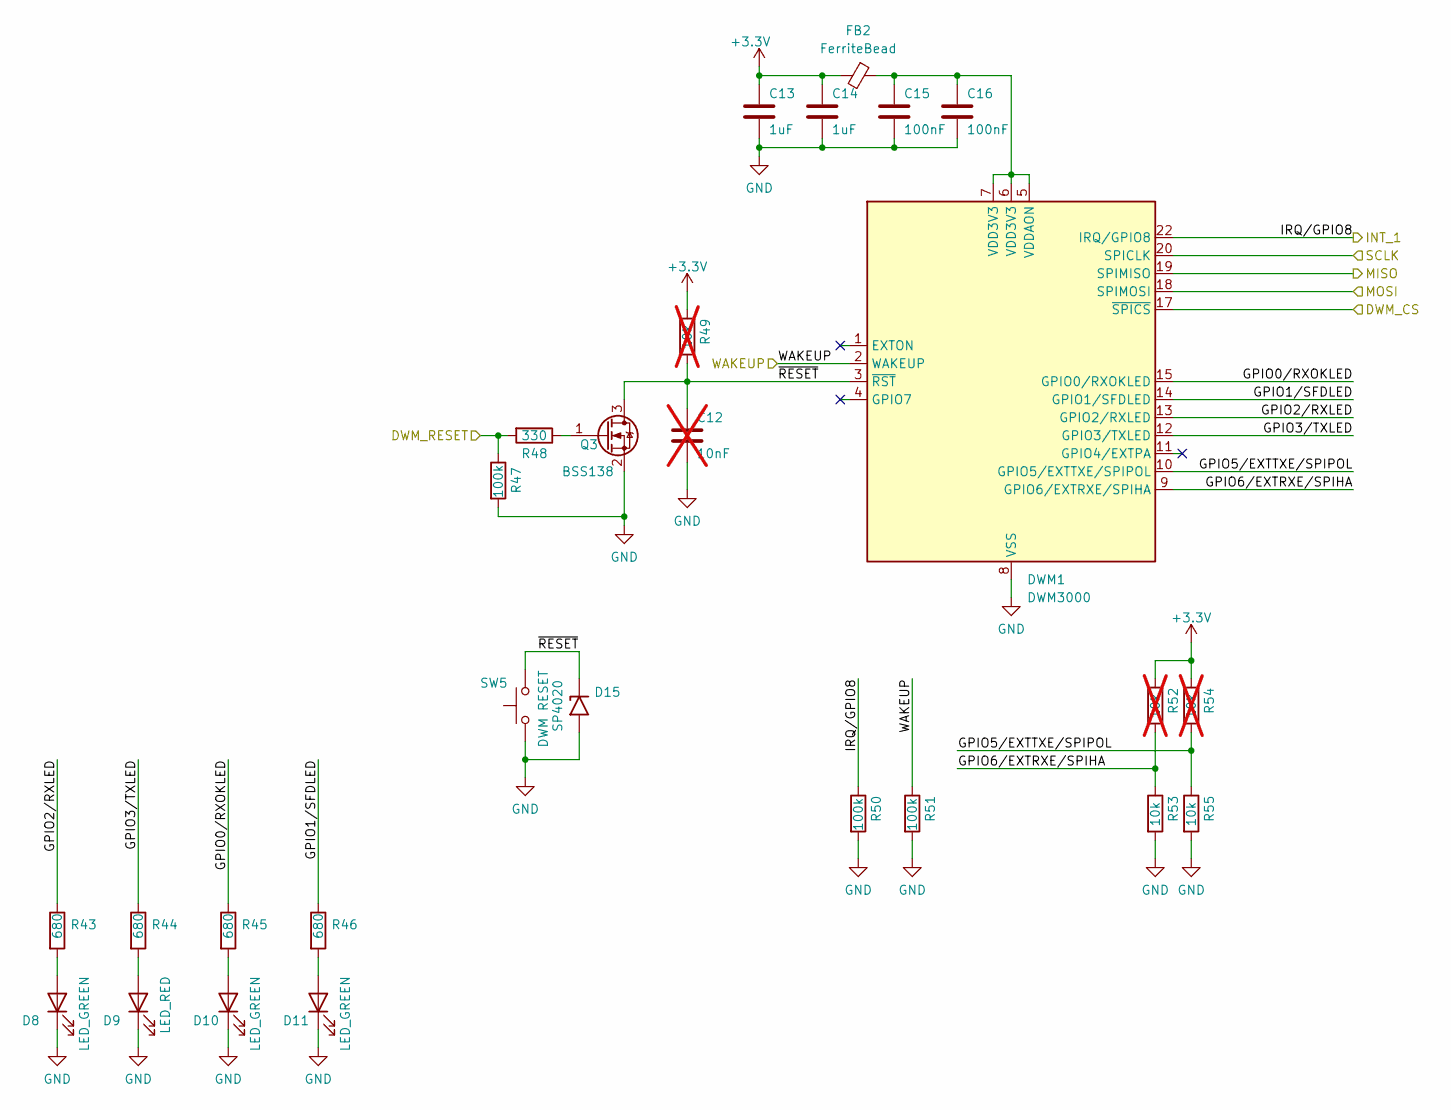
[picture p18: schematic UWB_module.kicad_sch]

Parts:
C12: 10nF; C_0603_1608Metric; Mfr. part number SH18B103K160CT; JLCPCB Part C57112; not fitted
C13, C14: 1uF; C_0603_1608Metric; Mfr. part number 885012206052; JLCPCB Part C15849
C15, C16: 100nF; C_0603_1608Metric; Mfr. part number 06035C104KAZ4A; JLCPCB Part C14663
D8, D10, D11: LED_GREEN; LED_0603_1608Metric; Mfr. part number 150060VS75000; JLCPCB Part C22371297
D9: LED_RED; LED_0603_1608Metric; Mfr. part number 150060RS75000; JLCPCB Part C965799
D15: SP4020; D_SOD-323; Mfr. part number SP4020-01FTG-C; JLCPCB Part C126842
DWM1: DWM3000; DWM1000; Mfr. part number DWM3000TR13; JLCPCB Part C5299931
FB2: FerriteBead; L_0805_2012Metric; Mfr. part number BLM21SP601SN1D; JLCPCB Part C3716677
Q3: BSS138; SOT-23; Mfr. part number BSS138; JLCPCB Part C5224261
R43, R44, R45, R46: 680; R_0603_1608Metric; Mfr. part number CRGCQ0603F680R; JLCPCB Part C23228
R47, R50, R51: 100k; R_0603_1608Metric; Mfr. part number RC0603FR-10100KL; JLCPCB Part C25803
R48: 330; R_0603_1608Metric; Mfr. part number RE0603FRE07330RL; JLCPCB Part C23138
R49, R52, R54: 10k; R_0603_1608Metric; Mfr. part number CR0603-FX-1002ELF; JLCPCB Part C25804; not fitted
R53, R55: 10k; R_0603_1608Metric; Mfr. part number CR0603-FX-1002ELF; JLCPCB Part C25804
SW5: DWM RESET; SW_Push_1P1T_NO_CK_KMR2; Mfr. part number PTS815SJM250SMTR LFS; JLCPCB Part C99271

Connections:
+3.3V: C13.1, C14.1, FB2.2, R49.1, R52.1, R54.1; also elsewhere on the board
/ESP32/ESP32_CS0: DWM1.17 (~SPICS); also elsewhere on the board
/ESP32/ESP32_IO8: R47.1, R48.2; also elsewhere on the board
/ESP32/ESP32_MISO: DWM1.19 (SPIMISO); also elsewhere on the board
/ESP32/ESP32_MOSI: DWM1.18 (SPIMOSI); also elsewhere on the board
/ESP32/ESP32_SCK: DWM1.20 (SPICLK); also elsewhere on the board
/UWB_module/GPIO0/RXOKLED: DWM1.15 (GPIO0/RXOKLED), R45.1
/UWB_module/GPIO1/SFDLED: DWM1.14 (GPIO1/SFDLED), R46.1
/UWB_module/GPIO2/RXLED: DWM1.13 (GPIO2/RXLED), R43.1
/UWB_module/GPIO3/TXLED: DWM1.12 (GPIO3/TXLED), R44.1
/UWB_module/GPIO5/EXTTXE/SPIPOL: DWM1.10 (GPIO5/EXTTXE/SPIPOL), R54.2, R55.1
/UWB_module/GPIO6/EXTRXE/SPIHA: DWM1.9 (GPIO6/EXTRXE/SPIHA), R52.2, R53.1
/UWB_module/IRQ/GPIO8: DWM1.22 (IRQ/GPIO8), R50.1; also elsewhere on the board
/UWB_module/WAKEUP: DWM1.2 (WAKEUP), R51.1; also elsewhere on the board
/UWB_module/~RESET: C12.1, D15.1 (A1), DWM1.3 (~RST), Q3.3 (D), R49.2, SW5.2
GND: C12.2, C13.2, C14.2, C15.2, C16.2, D8.1 (K), D9.1 (K), D10.1 (K), D11.1 (K), D15.2 (A2), DWM1.8 (VSS), DWM1.16 (VSS), DWM1.21 (VSS), DWM1.23 (VSS), DWM1.24 (VSS), Q3.2 (S), R47.2, R50.2, R51.2, R53.2, R55.2, SW5.1; also elsewhere on the board
unnamed: D8.2 (A), R43.2
unnamed: D9.2 (A), R44.2
unnamed: D10.2 (A), R45.2
unnamed: D11.2 (A), R46.2
unnamed: C15.1, C16.1, DWM1.5 (VDDAON), DWM1.6 (VDD3V3), DWM1.7 (VDD3V3), FB2.1
unnamed: Q3.1 (G), R48.1

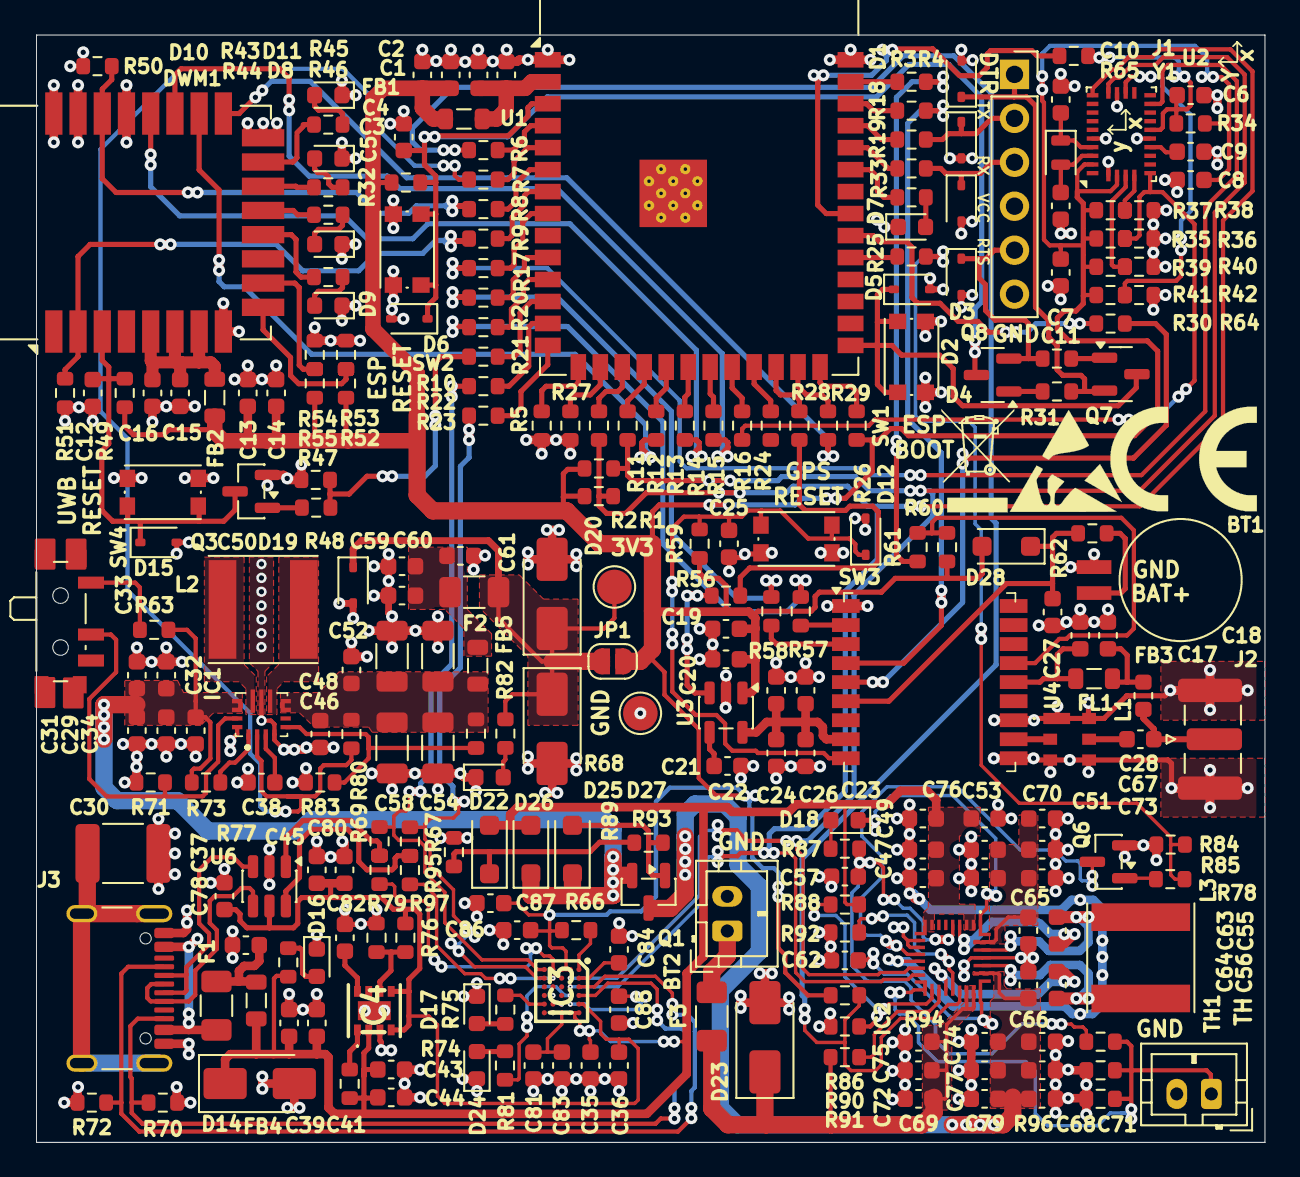
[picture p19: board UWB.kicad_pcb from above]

Board: 4 copper layers, 71.0 x 64.0 mm, 254 parts (0 on the bottom side), 155 nets.

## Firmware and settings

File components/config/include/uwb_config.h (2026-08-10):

#ifndef UWB_CONFIG_H
#define UWB_CONFIG_H

/*
 * UWB module behavior, IDs, and ranging defaults live here. Board wiring
 * remains in board_config.h; the selected firmware runtime stays in
 * app_config.h.
 */

#define APP_UWB_ROLE_UNSET 0
#define APP_UWB_ROLE_ANCHOR 1
#define APP_UWB_ROLE_TAG 2
#define APP_UWB_ROLE_DISTANCE_TEST_NODE 3

#ifndef APP_UWB_ROLE
#define APP_UWB_ROLE APP_UWB_ROLE_UNSET
#endif

/* 0 = derive from persistent app identity module ID, then Wi-Fi MAC fallback. */
#ifndef APP_UWB_SOURCE_ID
#define APP_UWB_SOURCE_ID 0
#endif

#ifndef APP_UWB_TAG_ID
#define APP_UWB_TAG_ID 1
#endif

#ifndef APP_UWB_ANCHOR_COUNT
#define APP_UWB_ANCHOR_COUNT 4
#endif

#ifndef APP_UWB_ANCHOR_0_ID
#define APP_UWB_ANCHOR_0_ID 2
#endif

#ifndef APP_UWB_ANCHOR_1_ID
#define APP_UWB_ANCHOR_1_ID 3
#endif

#ifndef APP_UWB_ANCHOR_2_ID
#define APP_UWB_ANCHOR_2_ID 4
#endif

#ifndef APP_UWB_ANCHOR_3_ID
#define APP_UWB_ANCHOR_3_ID 5
#endif

/* Validated ESP32-S3 FlexTDOA CI-CR radio-slot timing. */
#ifndef APP_UWB_FLEX_TDOA_GUARD_US
#define APP_UWB_FLEX_TDOA_GUARD_US 250
#endif

#ifndef APP_UWB_FLEX_TDOA_REQUEST_SUBSLOT_US
#define APP_UWB_FLEX_TDOA_REQUEST_SUBSLOT_US 2000
#endif

#ifndef APP_UWB_FLEX_TDOA_REQUEST_PROCESS_US
#define APP_UWB_FLEX_TDOA_REQUEST_PROCESS_US 250
#endif

#ifndef APP_UWB_FLEX_TDOA_RESPONSE_SUBSLOT_US
#define APP_UWB_FLEX_TDOA_RESPONSE_SUBSLOT_US 850
#endif

#ifndef APP_UWB_FLEX_TDOA_RESPONSE_PROCESS_US
#define APP_UWB_FLEX_TDOA_RESPONSE_PROCESS_US 1000
#endif

#ifndef APP_UWB_ANCHOR_SURVEY_COORDINATOR_ID
#define APP_UWB_ANCHOR_SURVEY_COORDINATOR_ID APP_UWB_TAG_ID
#endif

#ifndef APP_UWB_ANCHOR_SURVEY_RX_SLICE_MS
#define APP_UWB_ANCHOR_SURVEY_RX_SLICE_MS 100
#endif

#ifndef APP_UWB_ANCHOR_SURVEY_COMMAND_DELAY_MS
#define APP_UWB_ANCHOR_SURVEY_COMMAND_DELAY_MS 80
#endif

#ifndef APP_UWB_ANCHOR_SURVEY_SLOT_MS
#define APP_UWB_ANCHOR_SURVEY_SLOT_MS 1000
#endif

#ifndef APP_UWB_ANCHOR_SURVEY_ROUND_GAP_MS
#define APP_UWB_ANCHOR_SURVEY_ROUND_GAP_MS 1500
#endif

#ifndef APP_UWB_ANCHOR_SURVEY_PASSIVE_TAG_LOG_EVERY
#define APP_UWB_ANCHOR_SURVEY_PASSIVE_TAG_LOG_EVERY 20
#endif

#ifndef APP_UWB_RANGING_SLOT_MS
#define APP_UWB_RANGING_SLOT_MS 10
#endif

#ifndef APP_UWB_RANGING_ROUND_GAP_MS
#define APP_UWB_RANGING_ROUND_GAP_MS 4
#endif

#ifndef APP_UWB_RANGING_RX_SLICE_MS
#define APP_UWB_RANGING_RX_SLICE_MS 100
#endif

/* Native four-message DS-TWR timing used only by UWB ranging mode. */
#ifndef APP_UWB_RANGING_RX_TIMEOUT_MS
#define APP_UWB_RANGING_RX_TIMEOUT_MS 5
#endif

#ifndef APP_UWB_RANGING_RESP_DELAY_MS
#define APP_UWB_RANGING_RESP_DELAY_MS 2
#endif

#ifndef APP_UWB_RANGING_FINAL_DELAY_MS
#define APP_UWB_RANGING_FINAL_DELAY_MS 2
#endif

#ifndef APP_UWB_RANGING_AUTO_RX_DELAY_UUS
#define APP_UWB_RANGING_AUTO_RX_DELAY_UUS 500
#endif

/* Native DS-TWR rejects physically impossible results before telemetry. */
#ifndef APP_UWB_RANGING_MAX_DISTANCE_M
#define APP_UWB_RANGING_MAX_DISTANCE_M 100.0
#endif

/*
 * Passive DS-TWR keeps the three POLL/RESP/FINAL packets but schedules
 * anchor-to-anchor exchanges. Any module outside the anchor set only listens
 * and derives TDOA observations without consuming radio airtime.
 */
#ifndef APP_UWB_PASSIVE_DS_SCHEDULE
#define APP_UWB_PASSIVE_DS_SCHEDULE 2
#endif

#ifndef APP_UWB_PASSIVE_DS_SLOT_MS
#define APP_UWB_PASSIVE_DS_SLOT_MS 9
#endif

#ifndef APP_UWB_PASSIVE_DS_ROUND_GAP_MS
#define APP_UWB_PASSIVE_DS_ROUND_GAP_MS 1
#endif

#ifndef APP_UWB_PASSIVE_DS_RX_SLICE_MS
#define APP_UWB_PASSIVE_DS_RX_SLICE_MS 100
#endif

#ifndef APP_UWB_PASSIVE_DS_RX_TIMEOUT_MS
#define APP_UWB_PASSIVE_DS_RX_TIMEOUT_MS 5
#endif

#ifndef APP_UWB_PASSIVE_DS_RESP_DELAY_US
#define APP_UWB_PASSIVE_DS_RESP_DELAY_US 1750
#endif

#ifndef APP_UWB_PASSIVE_DS_FINAL_DELAY_US
#define APP_UWB_PASSIVE_DS_FINAL_DELAY_US 1750
#endif

#ifndef APP_UWB_PASSIVE_DS_MULTI_RESPONSE_SPACING_US
#define APP_UWB_PASSIVE_DS_MULTI_RESPONSE_SPACING_US 750
#endif

/* Keep every complete POLL..FINAL interval below the 20 ms observation
 * validity bound, including practical oscillator and scheduling margin. */
#ifndef APP_UWB_PASSIVE_DS_MAX_EXCHANGE_US
#define APP_UWB_PASSIVE_DS_MAX_EXCHANGE_US 19000
#endif

/* Retained for runtime-config ABI compatibility; v2 uses ROUND_GAP_MS. */
#ifndef APP_UWB_PASSIVE_DS_DYNAMIC_GUARD_US
#define APP_UWB_PASSIVE_DS_DYNAMIC_GUARD_US 250
#endif

#ifndef APP_UWB_PASSIVE_DS_AUTO_RX_DELAY_UUS
#define APP_UWB_PASSIVE_DS_AUTO_RX_DELAY_UUS 500
#endif

/* Retained for runtime-config ABI compatibility; v2 always uses raw solves. */
#ifndef APP_UWB_PASSIVE_DS_PIPELINE_MODE
#define APP_UWB_PASSIVE_DS_PIPELINE_MODE 0
#endif

#ifndef APP_UWB_PASSIVE_DS_SOLVE_MODE
#define APP_UWB_PASSIVE_DS_SOLVE_MODE 2
#endif

#ifndef APP_UWB_PASSIVE_DS_ROLLING_MAX_HZ
#define APP_UWB_PASSIVE_DS_ROLLING_MAX_HZ 100
#endif

#ifndef APP_UWB_ANTENNA_DELAY_DEFAULT
#define APP_UWB_ANTENNA_DELAY_DEFAULT 0x3FCA
#endif

#define APP_UWB_CALIBRATION_METHOD_TWO_MODULE 1
#define APP_UWB_CALIBRATION_METHOD_THREE_MODULE 2
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

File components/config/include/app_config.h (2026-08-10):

#ifndef APP_CONFIG_H
#define APP_CONFIG_H

/*
 * Non-secret application defaults live here and are versioned with the
 * firmware. Credentials and tokens stay in secrets.h.
 */

#define APP_RUNTIME_MODE_UWB_BEACON_SMOKE 0
#define APP_RUNTIME_MODE_UWB_DISTANCE_TEST 1
#define APP_RUNTIME_MODE_UWB_ANTENNA_DELAY_CALIBRATION 2
#define APP_RUNTIME_MODE_UWB_RANGING 3
#define APP_RUNTIME_MODE_UWB_ANCHOR_SURVEY 4
#define APP_RUNTIME_MODE_UWB_FLEX_TDOA 5
#define APP_RUNTIME_MODE_UWB_PASSIVE_DS_TWR 6

#ifndef APP_RUNTIME_MODE
#define APP_RUNTIME_MODE APP_RUNTIME_MODE_UWB_RANGING
#endif

#ifndef APP_WIFI_SSID
#define APP_WIFI_SSID ""
#endif

#ifndef APP_UWB_ENABLED
#define APP_UWB_ENABLED 1
#endif

#ifndef APP_IDENTITY_HOSTNAME_PREFIX
#define APP_IDENTITY_HOSTNAME_PREFIX "uwb-module-"
#endif

/*
 * 0 = read module ID from NVS. Set to 1 only for a provisioning boot that
 * should write APP_IDENTITY_PROVISION_MODULE_ID to NVS. Keep this at 0 in the
 * common firmware after the provisioning flash.
 */
#ifndef APP_IDENTITY_PROVISION_ENABLED
#define APP_IDENTITY_PROVISION_ENABLED 0
#endif

#ifndef APP_IDENTITY_PROVISION_MODULE_ID
#define APP_IDENTITY_PROVISION_MODULE_ID 0
#endif

#ifndef APP_IDENTITY_PROVISION_UWB_ROLE_ENABLED
#define APP_IDENTITY_PROVISION_UWB_ROLE_ENABLED 0
#endif

#ifndef APP_IDENTITY_PROVISION_UWB_ROLE
#define APP_IDENTITY_PROVISION_UWB_ROLE 0
#endif

/* Optional fallback if NVS is empty and no legacy HOSTNAME suffix is present. */
#ifndef APP_IDENTITY_DEFAULT_MODULE_ID
#define APP_IDENTITY_DEFAULT_MODULE_ID 0
#endif

#ifndef APP_WIFI_USE_WPA3
#define APP_WIFI_USE_WPA3 0
#endif

#ifndef APP_WIFI_ALLOW_WPA_COMPAT
#define APP_WIFI_ALLOW_WPA_COMPAT 1
#endif

#ifndef APP_WIFI_PMF_CAPABLE
#define APP_WIFI_PMF_CAPABLE 1
#endif

#ifndef APP_WIFI_DISABLE_WPA3_COMPATIBLE_MODE
#define APP_WIFI_DISABLE_WPA3_COMPATIBLE_MODE 0
#endif

#ifndef APP_WIFI_FORCE_HT20
#define APP_WIFI_FORCE_HT20 1
#endif

#ifndef APP_WIFI_ENABLE_11B
#define APP_WIFI_ENABLE_11B 1
#endif

#ifndef APP_WIFI_SET_PROTOCOL
#define APP_WIFI_SET_PROTOCOL 0
#endif

#ifndef APP_WIFI_SCAN_BEFORE_CONNECT
#define APP_WIFI_SCAN_BEFORE_CONNECT 1
#endif

#ifndef APP_WIFI_SCAN_ON_RECONNECT_EVERY
#define APP_WIFI_SCAN_ON_RECONNECT_EVERY 5
#endif

#ifndef APP_WIFI_SCAN_MAX_APS
#define APP_WIFI_SCAN_MAX_APS 16
#endif

#ifndef APP_WIFI_SCAN_CHANNEL
#define APP_WIFI_SCAN_CHANNEL 0
#endif

#ifndef APP_WIFI_SCAN_ACTIVE_MIN_MS
#define APP_WIFI_SCAN_ACTIVE_MIN_MS 100
#endif

#ifndef APP_WIFI_SCAN_ACTIVE_MAX_MS
#define APP_WIFI_SCAN_ACTIVE_MAX_MS 300
#endif

#ifndef APP_WIFI_LOCK_BSSID
#define APP_WIFI_LOCK_BSSID 0
#endif

#ifndef APP_WIFI_BSSID
#define APP_WIFI_BSSID ""
#endif

#ifndef APP_WIFI_LOCK_CHANNEL
#define APP_WIFI_LOCK_CHANNEL 0
#endif

#ifndef APP_WIFI_RECONNECT_FOREVER
#define APP_WIFI_RECONNECT_FOREVER 1
#endif

#ifndef APP_WIFI_MAX_RETRIES
#define APP_WIFI_MAX_RETRIES 10
#endif

#ifndef APP_WIFI_RECONNECT_BASE_DELAY_MS
#define APP_WIFI_RECONNECT_BASE_DELAY_MS 500
#endif

#ifndef APP_WIFI_RECONNECT_MAX_DELAY_MS
#define APP_WIFI_RECONNECT_MAX_DELAY_MS 5000
#endif

#ifndef APP_WIFI_CONNECT_TIMEOUT_MS
#define APP_WIFI_CONNECT_TIMEOUT_MS 30000
#endif

#ifndef APP_WIFI_FAILURE_RETRY_COUNT
#define APP_WIFI_FAILURE_RETRY_COUNT 3
#endif

#ifndef APP_WIRELESS_LOG_ENABLED
#define APP_WIRELESS_LOG_ENABLED 1
#endif

#ifndef APP_WIRELESS_LOG_TARGET
#define APP_WIRELESS_LOG_TARGET "192.168.50.1"
#endif

#ifndef APP_WIRELESS_LOG_PORT
#define APP_WIRELESS_LOG_PORT 6055
#endif

#ifndef APP_WIRELESS_TELEMETRY_ENABLED
#define APP_WIRELESS_TELEMETRY_ENABLED APP_WIRELESS_LOG_ENABLED
#endif

#ifndef APP_WIRELESS_TELEMETRY_TARGET
#define APP_WIRELESS_TELEMETRY_TARGET APP_WIRELESS_LOG_TARGET
#endif

#ifndef APP_WIRELESS_TELEMETRY_PORT
#define APP_WIRELESS_TELEMETRY_PORT APP_WIRELESS_LOG_PORT
#endif

#ifndef APP_BNO085_ACCEL_TEST_ENABLED
#define APP_BNO085_ACCEL_TEST_ENABLED 0
#endif

#ifndef APP_BNO085_ACCEL_ENABLED_DEFAULT
#define APP_BNO085_ACCEL_ENABLED_DEFAULT APP_BNO085_ACCEL_TEST_ENABLED
#endif

#ifndef APP_GPS_ENABLED_DEFAULT
#define APP_GPS_ENABLED_DEFAULT 0
#endif

#ifndef APP_BQ25792_MONITOR_ENABLED_DEFAULT
#define APP_BQ25792_MONITOR_ENABLED_DEFAULT 1
#endif

#ifndef APP_BQ25792_I2C_ADDRESS
#define APP_BQ25792_I2C_ADDRESS 0x6B
#endif

#ifndef APP_BQ25792_I2C_CLOCK_HZ
#define APP_BQ25792_I2C_CLOCK_HZ 1000000
#endif

#ifndef APP_BQ25792_I2C_TRANSACTION_TIMEOUT_MS
#define APP_BQ25792_I2C_TRANSACTION_TIMEOUT_MS 10
#endif

#ifndef APP_BQ25792_I2C_PROBE_TIMEOUT_MS
#define APP_BQ25792_I2C_PROBE_TIMEOUT_MS 200
#endif

#ifndef APP_BQ25792_I2C_READ_RETRIES
#define APP_BQ25792_I2C_READ_RETRIES 2
#endif

#ifndef APP_BQ25792_I2C_WRITE_RETRIES
#define APP_BQ25792_I2C_WRITE_RETRIES 2
#endif

#ifndef APP_BQ25792_I2C_MEASURE_SCL_ENABLED
#define APP_BQ25792_I2C_MEASURE_SCL_ENABLED 0
#endif

#ifndef APP_BQ25792_READ_INTERVAL_MS
#define APP_BQ25792_READ_INTERVAL_MS 1000
#endif

#ifndef APP_BQ25792_REGISTER_READ_CHUNK_BYTES
#define APP_BQ25792_REGISTER_READ_CHUNK_BYTES 16
#endif
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

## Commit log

2026-07-07 Initial ESP-IDF UWB firmware
    [partitions.csv]
2026-07-08 Add UWB distance runtime and board provisioning
2026-07-08 Fix Linux OTA workflow
    [app_config.h]
2026-07-08 Persist UWB antenna delay per module
2026-07-08 Enable antenna delay calibration runtime
2026-07-10 Add hardware design files
    [B39162B2651P810.stp, B39162B3520U410.stp, BQ25792RQMR.stp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]
2026-07-10 Add optional BNO085 accelerometer test
2026-07-11 feat: add BQ25792 charger monitor
2026-07-11 fix: mark BQ25792 QON command active high
    [board_config.h, charger_service.c]
2026-07-11 fix: treat board power-good as active high
    [board_config.h]
2026-07-11 feat: add live BQ25792 charger controls
2026-07-11 feat: show battery SOC and compact dashboard toasts
2026-07-11 feat: persist charger policy and live-toggle BNO085
2026-07-11 docs: explain charger dashboard controls
2026-07-11 feat: add charger enable control
2026-07-11 feat: decode charger power path status
2026-07-11 feat: expose charger safety timers
2026-07-11 fix: protect charger dashboard applies
2026-07-11 fix: split charger dashboard controls
2026-07-11 Expose charger ILIM clamp control
2026-07-11 Prioritize BNO085 I2C access
2026-07-11 Use compact accelerometer telemetry
2026-07-11 Stream accelerometer telemetry as binary frames
2026-07-11 Automate antenna delay calibration from dashboard
2026-07-11 Run dashboard calibration as background job
2026-07-11 Label calibration job progress states
2026-07-11 Include calibration participants in auto setup
2026-07-11 Reset excluded UWB modules during calibration
2026-07-11 Remove adjust modules from calibration UI
2026-07-11 Guard calibration writes with reference edge check
2026-07-11 Make UWB calibration deterministic
2026-07-11 Use median samples for UWB calibration
2026-07-11 Show calibration corrections when no writes occur
2026-07-12 Split UWB calibration implementation
2026-07-12 Make UWB calibration timing deterministic
2026-07-12 Synchronize UWB calibration slots
2026-07-12 Track UWB calibration sync misses
2026-07-12 Avoid false calibration sync misses
2026-07-12 Honor full calibration sync wait deadline
2026-07-12 Add calibration sync prepare guard
2026-07-12 Increase calibration auto timeout default
2026-07-12 Migrate calibration timeout setting
2026-07-12 Cap calibration samples per direction
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2026-07-15 Fix resource monitor memory pressure
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2026-07-18 Accelerate DW3000 SPI and distributed Flex timing
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2026-07-26 Add native DS-TWR mode and field comparison
    [block_metrics.csv, ds_positions.csv, flex_embedded_positions.csv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]
2026-07-27 Add DS-TWR speed study and live profiling
    [block_metrics.csv, flex_embedded_positions.csv, measurement_metrics.csv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]
2026-07-27 Fix passive DS-TWR runtime activation
    [uwb_config.h]
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2026-07-27 Validate Passive DS-TWR calibration
    [anchor_range_metrics.csv, observation_metrics.csv, position_metrics.csv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]
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2026-07-27 Compare Passive DS-TWR calibration before and after
    [effective_anchor_range_metrics.csv]
2026-07-27 Harden passive DS-TWR runtime and document live comparison
    [directed_path_metrics.csv, position_metrics.csv]
2026-07-27 Document Passive DS-TWR speed limit
    [metrics.csv]
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2026-07-31 Restore native DS-TWR precision reference
    [positions.csv, range_metrics.csv]
2026-07-31 Revalidate native DS-TWR speed limit
    [positions.csv, profile_comparison.csv, range_metrics.csv]
2026-07-31 Rebuild passive DS-TDoA and unify timing UI
    [ds_tdoa_3ms_dynamic_geometry_calibrated_30s_directed_paths.csv, ds_tdoa_3ms_dynamic_geometry_calibrated_30s_surveyed_rolling.csv, ds_tdoa_3ms_dynamic_geometry_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]
2026-08-01 Validate passive ESP32 solver stability
2026-08-02 Stabilize field UWB protocols and dashboard
    [uwb_config.h]
2026-08-02 Add GNSS moving-base transport and stabilize dashboard protocols
    [gps_moving_base.c, gps_service.c]
2026-08-03 Stabilize Passive DS-TWR and multi-rover RTK
    [gps_moving_base.c]
2026-08-04 Move UWB position solvers onto ESP32
    [anchor_pair_metrics.csv, common_solver_positions.csv, position_metrics.csv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]
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2026-08-04 Apply calibrated FlexTDOA anchor corrections
2026-08-05 Optimize Native DS-TWR timing and diagnostics
    Select the field-validated 44 ms profile, support verified timing hot switches, expose per-stage and per-anchor loss counters, clear persisted DW3000 RX timeouts, and align RTK ground truth to the ac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
2026-08-05 Protect Native DS-TWR frame integrity
    Add an application CRC for every Native DS packet, reject CIA-incomplete RX timestamps, expose both diagnostics, and cover payload corruption in the host codec test.
2026-08-05 Normalize PX1105R position rate to 8 Hz
    Apply the SRAM-only SkyTraq update-rate command to every receiver role at startup so retained backup-SRAM settings cannot leave modules at mixed 1 Hz and 8 Hz rates.
2026-08-05 Rewrite and stabilize Passive DS-TWR
    [uwb_config.h]
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2026-08-05 Stabilize raw Passive DS-TWR accuracy and throughput
    Implement the PDS2 three-packet observation model and raw three-star solver, rearm passive-tag RX before metadata work, and add coherent residual gating. Update protocol tests, documentation, runtime defaults, and dashboard RTK validity diagnostics.
    [uwb_config.h]
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2026-08-10 Add IMU fusion and archive UWB field campaign
    [alignment_snapshots.csv, capture_metrics.csv, raw_data_manifest.csv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]
2026-08-10 Set ESP32-S3 brownout threshold to 2.84 V
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2026-08-11 Finalize IMU fusion and Native DS-TWR validation
    [alignment_snapshots.csv, capture_metrics.csv, replay_metrics.csv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]
2026-08-11 Validate IMU fusion and archive field report
    [ablation_metrics.csv, alignment_snapshots.csv, capture_metrics.csv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]
2026-08-11 Archive raw IMU validation captures
    [raw_data_manifest.csv]
2026-08-11 Add raw localization calibration and deterministic builds
    [capture_metrics.csv, link_metrics.csv, position_rtk_pairs.csv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]
2026-08-12 Finalize UWB localization field comparison
    [alignment_snapshots.csv, capture_metrics.csv, raw_data_manifest.csv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]
2026-08-13 Correct final report data provenance
    [alignment_snapshots.csv, capture_metrics.csv, rtk_alignment_metrics.csv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]
2026-08-13 Add audited August 13 UWB comparison report
    [alignment_snapshots.csv, capture_metrics.csv, raw_data_manifest.csv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]
2026-08-29 chore: clean and reorganize report artifacts
    [raw_data_manifest.csv]
2026-08-29 chore: consolidate report bundles
    [ablation_metrics.csv, alignment_snapshots.csv, anchor_pair_metrics.csv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]
2026-09-01 feat: add 3d-printed enclosure
    [01_baza_tinta.step, 01_baza_tinta.stl, 01_baza_tinta_PRINT.stl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]

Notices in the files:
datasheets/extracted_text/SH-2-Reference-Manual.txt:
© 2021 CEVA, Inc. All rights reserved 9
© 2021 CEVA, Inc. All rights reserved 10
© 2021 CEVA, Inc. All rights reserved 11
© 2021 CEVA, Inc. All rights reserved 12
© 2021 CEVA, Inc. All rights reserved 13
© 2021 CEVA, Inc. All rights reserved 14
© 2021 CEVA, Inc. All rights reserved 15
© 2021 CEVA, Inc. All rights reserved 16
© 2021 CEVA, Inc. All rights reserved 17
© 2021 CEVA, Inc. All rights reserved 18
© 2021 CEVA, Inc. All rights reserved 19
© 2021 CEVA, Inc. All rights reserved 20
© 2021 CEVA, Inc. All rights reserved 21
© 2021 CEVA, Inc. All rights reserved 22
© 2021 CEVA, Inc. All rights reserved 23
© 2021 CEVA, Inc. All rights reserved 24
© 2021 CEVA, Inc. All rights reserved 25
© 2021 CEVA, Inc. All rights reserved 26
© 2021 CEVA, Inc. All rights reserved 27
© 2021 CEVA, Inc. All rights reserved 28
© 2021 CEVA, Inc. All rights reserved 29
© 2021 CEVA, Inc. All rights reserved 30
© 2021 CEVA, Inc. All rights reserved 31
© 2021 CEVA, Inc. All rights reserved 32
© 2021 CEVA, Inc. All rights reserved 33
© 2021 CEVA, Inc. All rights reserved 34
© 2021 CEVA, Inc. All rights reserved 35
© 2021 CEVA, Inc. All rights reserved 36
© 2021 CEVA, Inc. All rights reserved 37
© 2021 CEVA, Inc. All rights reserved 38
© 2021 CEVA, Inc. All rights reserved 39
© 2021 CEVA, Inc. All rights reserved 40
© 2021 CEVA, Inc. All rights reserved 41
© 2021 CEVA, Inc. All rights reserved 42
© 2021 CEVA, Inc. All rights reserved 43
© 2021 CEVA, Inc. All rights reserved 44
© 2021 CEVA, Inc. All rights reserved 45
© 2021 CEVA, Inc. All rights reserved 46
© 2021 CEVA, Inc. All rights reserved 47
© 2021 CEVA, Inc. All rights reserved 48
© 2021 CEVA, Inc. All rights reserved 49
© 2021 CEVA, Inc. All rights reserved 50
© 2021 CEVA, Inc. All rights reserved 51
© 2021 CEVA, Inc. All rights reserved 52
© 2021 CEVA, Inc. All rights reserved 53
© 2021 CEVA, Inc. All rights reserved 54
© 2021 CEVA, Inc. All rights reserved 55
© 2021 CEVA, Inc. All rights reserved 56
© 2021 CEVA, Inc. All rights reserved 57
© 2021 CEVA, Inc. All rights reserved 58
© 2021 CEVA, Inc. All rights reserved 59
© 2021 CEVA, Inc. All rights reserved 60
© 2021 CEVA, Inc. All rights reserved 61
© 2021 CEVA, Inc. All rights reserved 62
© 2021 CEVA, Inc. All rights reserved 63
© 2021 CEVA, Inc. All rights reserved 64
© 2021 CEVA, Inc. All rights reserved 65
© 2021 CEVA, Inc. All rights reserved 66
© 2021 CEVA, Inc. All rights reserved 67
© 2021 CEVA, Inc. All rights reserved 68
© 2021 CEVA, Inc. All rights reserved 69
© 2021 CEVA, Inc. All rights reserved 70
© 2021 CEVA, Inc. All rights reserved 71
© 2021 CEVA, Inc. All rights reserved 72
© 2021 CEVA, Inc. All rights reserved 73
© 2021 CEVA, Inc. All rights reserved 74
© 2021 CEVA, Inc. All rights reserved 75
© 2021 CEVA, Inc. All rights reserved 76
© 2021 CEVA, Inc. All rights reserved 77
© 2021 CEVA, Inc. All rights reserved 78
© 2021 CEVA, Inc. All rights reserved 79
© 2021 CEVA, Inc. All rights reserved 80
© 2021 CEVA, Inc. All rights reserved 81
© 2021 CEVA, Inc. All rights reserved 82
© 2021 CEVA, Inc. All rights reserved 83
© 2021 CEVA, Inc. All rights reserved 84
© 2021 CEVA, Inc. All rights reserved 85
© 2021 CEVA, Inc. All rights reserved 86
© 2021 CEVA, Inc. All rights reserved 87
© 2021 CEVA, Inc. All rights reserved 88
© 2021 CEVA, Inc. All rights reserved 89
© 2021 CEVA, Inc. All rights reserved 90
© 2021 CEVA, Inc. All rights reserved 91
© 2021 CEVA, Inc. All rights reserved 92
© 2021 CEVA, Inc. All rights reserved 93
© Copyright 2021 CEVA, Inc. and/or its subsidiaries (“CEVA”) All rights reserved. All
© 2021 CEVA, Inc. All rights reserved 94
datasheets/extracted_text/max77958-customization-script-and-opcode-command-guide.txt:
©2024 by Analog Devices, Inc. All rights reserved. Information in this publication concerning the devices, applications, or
